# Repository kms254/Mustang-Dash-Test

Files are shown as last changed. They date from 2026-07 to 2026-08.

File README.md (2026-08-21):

# Mustang-Dash-Test

Firmware **and carrier hardware** for a **Riverdi EVE4 instrument cluster** —
a 7" centre panel with two 5" side panels, each on its **own dedicated SPI
peripheral**, driven by an **STM32H755**.

| Item | Value |
|---|---|
| Displays  | Centre: Riverdi **SM-RVT70HSBNWN00** — 7.0" **1024 × 600** IPS, **BT817** (EVE4), no touch. Sides: RVT50H. |
| MCU | **STM32H755ZIT6** on the in-repo carrier (**Board3**, ordered from JLCPCB 2026-08). Bench mules: NUCLEO-H755ZI-Q (same die) and NUCLEO-F767ZI (proven three-panel rig). |
| Library | [RudolphRiedel/FT800-FT813](https://github.com/RudolphRiedel/FT800-FT813) (EmbeddedVideoEngine) v5.0.10, branch `5.x`, vendored in [`libraries/`](libraries/) with multi-panel / per-panel-SPI-bus support |
| Profile | `EVE_RVT70H` (1024×600, BT817, `EVE_GEN 4`) |

## Repo layout

| Path | What it is |
|---|---|
| [`MustangDash/`](MustangDash/) | The firmware sketch plus pure, host-tested headers (sim, serial, odometer, button, telltales) |
| [`kicad/board3/`](kicad/board3/) | The carrier board — schematic, routed PCB, footprint libraries. DRC/ERC 0 at `--severity-all`; reviewed pre-order by seven independent lenses |
| [`fab/`](fab/) | The JLCPCB package: gerbers/BOM/CPL plus [`ORDER.md`](fab/ORDER.md), the order-form contract every figure of which re-derives from the tree |
| [`tools/`](tools/) | The KiCad pipeline: `kicad_lcsc.py` (sourcing), `kicad_fab.py` (fab package), `kicad_verify.py` (the DRC gate), silk/routing/verification tooling |
| [`docs/hardware/`](docs/hardware/) | [Bring-up card](docs/hardware/board3-bringup-card.md) (print before the boards arrive) and the [as-built H755 pin map](docs/hardware/board3-h755-pin-map.md) |
| [`docs/solutions/`](docs/solutions/) + [`CONCEPTS.md`](CONCEPTS.md) | Documented learnings (YAML frontmatter: `module`, `tags`, `problem_type`) and the shared domain vocabulary |

## Wiring

Shared ground, panel logic on **3.3 V**, backlight on an external **5.0 V**
supply (a dev board's USB rail cannot feed three backlights).

**Each panel has its own SPI peripheral** — on Board3: centre SPI1
(PA5/6/7, CS PD8, PD PD11), left SPI2 (PB13/14/15, CS PD9, PD PD12), right
SPI4 (PE2/5/6, CS PE3, PD PD13) — plus per-panel CS and PD/RST. Panel timings
live in [`MustangDash/dash_panels.h`](MustangDash/dash_panels.h); per-target
pins in the sketch's board blocks and the
[pin map](docs/hardware/board3-h755-pin-map.md). `INT` is not wired — the
firmware polls.

**SPI is mode 0, MSB-first, ≤ 11 MHz during every panel's `EVE_init()`**, then
each bus rises once to the run clock. **Board3 runs 25 MHz on all three
panels**, walked and soaked 2026-08-21; the F767 bench ran 13.5 (where 27 MHz
hard-wedges the firmware rather than degrading gracefully). Two numbers, two
clock trees, both correct — because clock numbers come from failure, not
derivation, and **do not transfer across copper**: re-walk on each new board,
per the bring-up card. And the constant is only a *request* — the peripheral
rounds it down to a reachable rung, so ask the firmware what it actually got
(`diag` on the serial console prints the attained rate per panel) rather than
trusting the source.

## What the firmware does

A 2000 ms animated boot splash (ASTC assets embedded in the MCU image and
staged to RAM_G with per-asset readback checks) crossfades into the dash, which
renders TRACK and STREET screens procedurally at ~60 fps with custom EVE bitmap
fonts.

Data flows simulator → `DashState` channels → renderers; CAN decoders will fill
the same channels later. The serial protocol (115200, USB-CDC on Board3;
`ok`/`err` acks) overrides any channel; the odometer persists across power
cycles. A short press on the gesture button (BTN1 on Board3, the USER button on
the mules) toggles TRACK/STREET; a ≥1 s hold resets the trip. Telltales drive
eight LEDs through two AW9523B expanders on I2C2; the boot banner self-checks
the panels, the expanders, and the QSPI NOR's JEDEC ID.

## Build

See [`BUILD.md`](BUILD.md) for the environments and the flash budget.

```bash
./scripts/compile.sh                    # PlatformIO, default env nucleo_f767
./scripts/compile.sh board3             # the carrier (25 MHz crystal clock tree)
./scripts/compile.sh board3_mule        # same firmware on the NUCLEO-H755ZI-Q
wsl -- bash -lc "./tests/run-tests.sh"  # host invariant tests, no board needed
```

**H755 targets, one-time first connect:** the factory chip boots both cores and
the CM4 has no image — run `STM32_Programmer_CLI -c port=SWD -ob BCM4=0` once.
The mule env is SMPS-aware (flashing plain `board3` onto the -Q Nucleo hangs at
the VOSRDY wait); details and the session matrix are on the
[bring-up card](docs/hardware/board3-bringup-card.md).

The host tests pin what must not silently change: the `EVE_RVT70H` profile, the
control pins, the backlight sweep, the splash timeline, the dash
math/sim/serial/odometer logic, the font format, the flash-pack layout, the
button gestures and the telltale calibration.

## Configuration (already applied in the vendored library)

- **Profile** — `EVE_config.h` defines `EVE_RVT70H` near the top of the file,
  so it applies without `-D` flags. Note it is **not** `EVE_RiTFT70`, which is
  the 800×480 BT81x panel — picking that one initialises fine and renders
  garbage. See [the profile-selection
  learning](docs/solutions/best-practices/riverdi-rvt70h-vs-ritft70-eve-display-profile-selection.md).
- **Multi-panel** — the STM32 target header carries `EVE_MULTI_PANEL` and a
  per-panel descriptor (`EVE_panel_t`) with an optional per-panel `SPIClass*`
  bus; the sketch selects the active panel at runtime.
- An Arduino `library.properties` was added so the `src/` layout is picked up
  (upstream ships only a PlatformIO `library.json`).

## Troubleshooting

| Symptom | Likely cause |
|---|---|
| Board looks completely dead | Hold **BOOT** + tap **RESET** → a DFU device on USB proves MCU, power and the USB path with zero tools. Then walk the [bring-up card](docs/hardware/board3-bringup-card.md); on this bench a "dead board" has historically been a cable or connector, not silicon. |
| `EVE_init() did NOT return E_OK` | EVE never came out of reset — check PD/RST, the 3.3 V logic supply, and CS. |
| Init OK but `REG_ID = 0x00`/`0xFF` (not `0x7C`) | SPI link — MISO/MOSI swapped, wrong CS, or the clock too fast. `0x00` and `0xFF` distinguish a floating line from a stuck one. |
| Init OK and `REG_ID = 0x7C` but the panel stays dark | Backlight power or `REG_PWM_DUTY`. The panel is alive but unlit — it renders fine with no 5 V on BLVDD, just invisibly. |
| Init OK, backlight lit, image garbled or wrong geometry | Wrong display profile in `EVE_config.h`. |

More hard-won detail — FFC orientation, identifying the backlight end by
continuity, why instruments that answer confidently deserve suspicion — is in
[`docs/solutions/`](docs/solutions/), organised by category with searchable
frontmatter.

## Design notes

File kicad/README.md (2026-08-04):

# kicad/

The project's board designs.

Today that is **Board3**. It arrived here as an import from EasyEDA Pro for the
tooling evaluation in
[docs/plans/2026-07-27-001-chore-kicad-evaluation-plan.md](../docs/plans/2026-07-27-001-chore-kicad-evaluation-plan.md),
but **that evaluation is settled**: as of 2026-07-31 Kevin has moved off EasyEDA
entirely, so this directory is the design, not a copy of one.

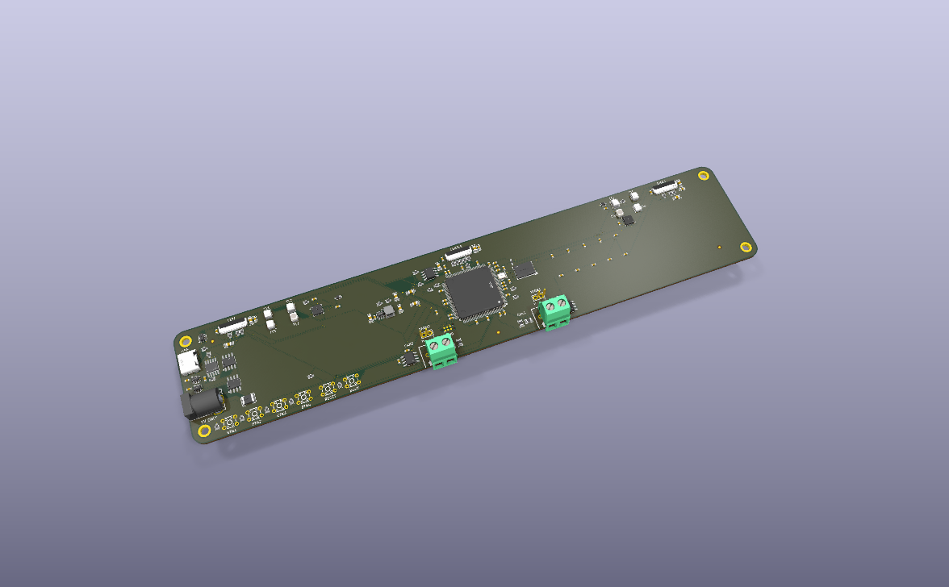
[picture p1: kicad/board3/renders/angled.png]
Board3, angled


| Top | Bottom |
| --- | --- |
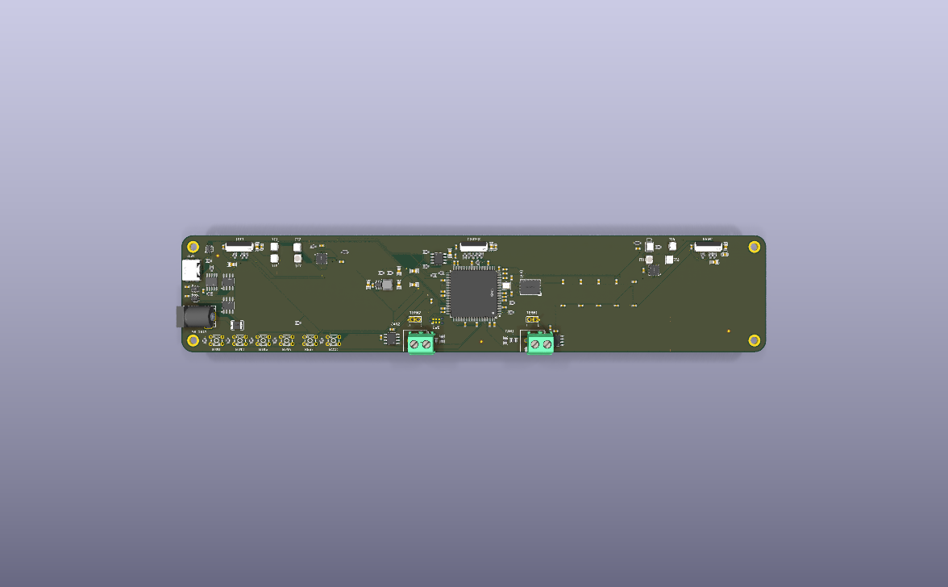
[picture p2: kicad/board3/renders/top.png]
Top
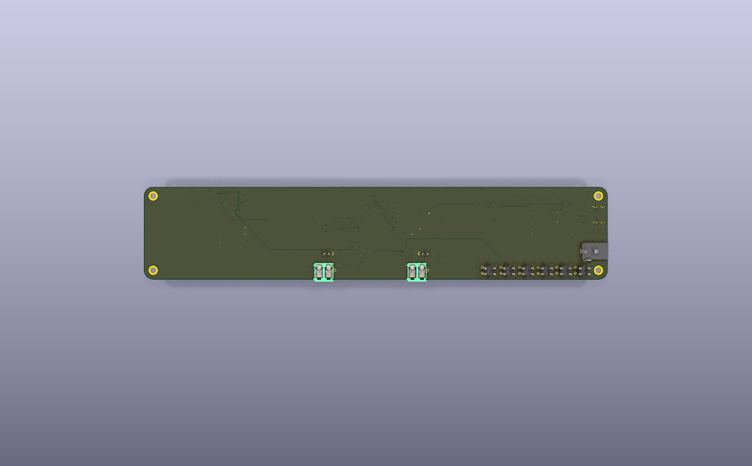
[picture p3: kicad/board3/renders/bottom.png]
Bottom
|  |  |

These are generated, not drawn — `.kicad_pcb` is the truth. See
[Renders](#renders) for how they stay current.

Three rules govern everything in this directory:

- **This is the source of truth.** ~~EasyEDA stays authoritative; conversion is
  one-way.~~ Superseded 2026-07-31 — EasyEDA is no longer maintained, so there is
  no upstream to defer to and nothing to reconcile against. Edit the schematic and
  board here directly. The `EasyEDA/` directory stays in the repo as history; do
  not mirror changes into it, and do not treat a KiCad-only change as partial.
  The one-way rule still describes the *import*: nothing here was ever converted
  back, and `docs/solutions/integration-issues/easyeda-pro-to-kicad-migration-silent-data-loss.md`
  records six silent losses that make a re-import a bad idea now that this copy
  carries all the routing.
- **The design files are tracked on purpose.** `.kicad_pcb` and `.kicad_sch` are
  S-expression text, and `git diff` is the evaluation's verification mechanism for
  agent-driven writes. Keeping the board out of the repo would forfeit that.
- **The first commit of a converted board is the baseline.** It must contain
  converter output and nothing else. Every later measurement diffs against it.

Toolchain resolution for anything operating on these files is
[tools/kicad_env.py](../tools/kicad_env.py) — do not hardcode `kicad-cli` paths.

**Never pick a board by globbing for the newest `.kicad_pcb`.** Routing and
cascade experiments leave variant boards (`…-c0.kicad_pcb`, `…-it.kicad_pcb`)
sitting beside the real one, and being scratch they are *always* newer — so
newest-wins reliably selects the wrong file. This bit twice on 2026-07-28:
`kicad_render.py` rendered a leftover temp board, and `kicad_live_view.py` spent
a session watching one that was then deleted underneath it. Filter to files git
tracks (`git ls-files -- '*.kicad_pcb'`) and take the newest of those; untracked
neighbours are working scratch, not the design.

## Renders

`board3/renders/*.png` are committed so the board is visible in a diff, a PR, or
a browser without installing KiCad. They are **build output, not source** — the
board is the truth and these are regenerated from it:

```sh
python tools/kicad_render.py            # refresh all three views
python tools/kicad_render.py --check    # exit 2 if older than the board
```

A tracked pre-commit hook keeps them honest. Install it once per clone:

```sh
git config core.hooksPath .githooks
```

The hook is convenience, not enforcement — it is opt-in per clone, so it is
silently absent on a fresh clone or under `--no-verify`. CI is what actually
holds the line: `.github/workflows/kicad-renders.yml` fails any PR that changes
the board without refreshing the renders, and `kicad-parts.yml` runs the part
audit on every PR.

The hook only fires when a `.kicad_pcb` is actually staged — each refresh is
~360 KB of binary that lands in history permanently, so regenerating on every
commit would bloat the repo to show a picture that did not change. If rendering
fails (no KiCad on this machine) it warns and lets the commit through: refusing
to commit firmware because a PCB picture could not be drawn is the wrong trade.

Renders are 1200×750 on purpose. Enough to read placement and routing at a
glance; open the board if you need detail.

## Watching the board change live

To see the board *while* an agent edits it, without pcbnew in the way:

```sh
python tools/kicad_live_view.py                     # newest board under kicad/
python tools/kicad_live_view.py path/to/x.kicad_pcb --port 8010
```

It serves a local page that renders the file with
[KiCanvas](https://kicanvas.org/) and reloads on every save, keeping your zoom.
Pan/zoom, layer toggles and net highlight all work.

**3D is on the second tab**, built by `kicad-cli` in the background — but only
while that tab is open, since a build costs real CPU and nobody would see it.
Two modes, because the cost difference is an order of magnitude:

| mode | what it is | board3 |
|---|---|---|
| **snapshot** (default) | `pcb render` PNG, six camera presets | **~3 s**, 0.1 MB |
| **model** | `export glb`, orbit in the browser | **~29 s**, 13.5 MB |
| **model + copper** | as above with tracks/zones/silk as geometry | **~47 s**, 31 MB |

So 3D follows an agent at roughly one frame per edit, not live — the header
always says how far behind it is (`3D showing rev 4, board at rev 7`) rather
than quietly showing you a stale board. Snapshot is the default because 3 s is
fast enough to actually watch work happen; switch to model when you want to
orbit something. There is no cheap middle: a components-free GLB builds in 1.2 s
but is a bare board, which is no use for checking a footprint.

Model mode opens **top-down on the top face** (model-viewer's own default is
nearly edge-on, which on a board this thin is a sliver). That framing is applied
once, so an orbit you set up afterwards survives every rebuild.

3D is built from the *same validated bytes* the 2D tab is showing, written to a
temp copy — so the two tabs can never disagree and a build can never catch a
half-written save. That relocation would normally drop every 3D model, since
footprints reference `${KIPRJMOD}/EASYEDA_MODELS/…` and KIPRJMOD follows the
file; the builder passes `-D KIPRJMOD=<board dir>` to put them back. Worth
knowing because the failure is silent — without it you get a bare green board
and no error.

**Why not just open pcbnew.** The editor takes a `.lck` on the board and holds
its own in-memory copy, so an agent's write and your session become two
authorities on one file — whoever saves last wins, silently. This viewer only
ever reads. That is also why it is a *viewer*: it is safe to leave open all day
precisely because it cannot write, so it does not replace the GUI for editing,
and KTD12 still holds (Update PCB from Schematic is Kevin, in the GUI, after a
restart).

Two things worth knowing:

- **A save is not atomic from the reader's side.** Every re-read is validated
  (starts with `(kicad_pcb`, parens balance outside strings) before it is
  published, so a file caught mid-write never reaches the screen — the viewer
  holds the last good revision and turns its status dot amber. Verified by
  truncating a board under a running viewer: revision held, bytes served
  unchanged.
- **KiCanvas predates KiCad 10 and skips tokens it does not know**, warning to
  the browser console. On board3 that is 344 warnings and zero errors, all of
  them non-geometry policy fields (`tenting`, `covering`, `plugging`, `capping`,
  `filling`, `duplicate_pad_numbers_are_jumpers`, dimension `units`). Copper,
  zones, footprints and silk all render. It is a preview, not an authority —
  DRC and the fab package remain the check that matters.

The bundle is cached to `tools/vendor/kicanvas.js` on first run (gitignored);
`--refresh-viewer` re-fetches it.

## Adding a part

**Every part placed on a board here must be an LCSC part, carrying supplier
metadata and a 3D model.** Not a convention — a build dependency. `kicad_fab.py`
builds the JLCPCB BOM by reading the schematic's supplier fields, so a part added
without them does not produce a warning, it produces a BOM that is quietly
missing a component.

Add parts with [tools/kicad_lcsc.py](../tools/kicad_lcsc.py), never by dragging a
generic symbol out of the stock KiCad libraries:

```sh
python tools/kicad_lcsc.py add C116592   # symbol + footprint + STEP/WRL + metadata
python tools/kicad_lcsc.py check         # audit; exits non-zero on any gap
python tools/kicad_lcsc.py models        # fetch any 3D model the board references but lacks
```

`add` drives the JLCImport plugin and then rewrites the imported symbol's fields
into Board3's vocabulary. That rewrite is the whole point: JLCImport writes the
LCSC code to a property named `LCSC`, and this project reads it from
`Supplier Part`. Import without remapping and the part looks sourced in the
schematic editor while being invisible to the BOM.

`LCSC Part Name` is **not** the part number despite its name — it holds
descriptive text. The C-number goes in `Supplier Part`.

Run `check` before generating fab output. It audits the **board**, not the
library — the board is what gets fabricated, and each placed footprint carries
its own copy of the model reference, so an instance placed before a library fix
can be wrong while the library looks perfect. It fails on any of:

- a placed part **not mapped to LCSC** (missing `Supplier Part`, or absent from
  the schematic entirely)
- a placed footprint with **no 3D model reference at all**
- a model reference whose **file is missing from disk**
- a schematic symbol with no LCSC code, placed or not

Footprints that legitimately have no body — fiducials, free pads, mounting
holes, test points — are exempt via the `BODILESS` table in the tool, and every
exemption is **printed on every run**. An exemption you cannot see is one you
cannot audit, and that table is the only path by which a real part could pass
unnoticed. Board3 currently exempts 8: three fiducials, four free pads (MP1-MP4) and H2, the Tag-Connect land pattern -- a cable presses pogo pins onto bare copper, so nothing is fitted and there is no part to source.

3D models live in `board3/EASYEDA_MODELS/` and **are tracked** (~53 MB, ~9.5 MB
in history). They are regenerable from the schematic's LCSC codes via
`kicad_lcsc.py models`, but they are committed anyway so a fresh clone renders
and exports 3D offline, and so the geometry stays pinned to this board revision
rather than to whatever EasyEDA serves later.

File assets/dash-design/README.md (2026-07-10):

# Handoff: EVE Triple Dash — Mustang Race/Street Digital Cluster

## Overview
A three-screen digital instrument cluster for a track-built 1999 Ford Mustang (Gen 4 Coyote Aluminator swap, T56 Magnum close-ratio, 3.73 rear, 26″ tires, WR Blue Mica).

Target hardware:
- **MCU**: Teensy (4.x assumed) driving **Riverdi EVE displays** (Bridgetek EVE graphics controllers — BT81x family)
- **Displays**: one 7″ center (800×480) + two 5″ side panels (800×480), mounted in a single CNC bezel with physical turn-signal LEDs at the outer bosses
- **Data**: Ford Gen 4 Coyote control pack CAN, 2× ECUMasters PMU16 (custom CAN), RaceCapture (GPS speed, lap timing, IMU)
- **Mode switching**: TRACK vs STREET view is selected by a **CAN input** into the Teensy (physical switch → PMU → CAN broadcast, or direct digital input — TBD)

### Build phases
1. **Phase 1**: Center 7″ display only (both TRACK and STREET modes, alarm takeover, telltale dots, odometer)
2. **Phase 2**: Add left 5″ (engine) and right 5″ (timing/road) displays

## About the Design Files
The files in this bundle are **design references created in HTML** — an interactive prototype showing the intended look and behavior. They are NOT production code. The task is to **recreate these designs as EVE display lists / widgets on the Teensy** (e.g. via the Bridgetek EVE library, GD2/GDX, or a custom display-list generator). The HTML file runs in any browser and includes a live simulator plus a Tweaks panel (mode, units, accent, alarm test, manual RPM/MPH override) — use it as the visual source of truth.

## Fidelity
**High-fidelity.** Colors, typography, spacing, gauge geometry, and thresholds are final and should be matched as closely as the EVE rendering pipeline allows. Fonts will need conversion to EVE bitmap/custom fonts (see Typography).

## Screen Resolutions & Canvas
Each panel renders at **800×480** (native EVE resolution). The HTML mock draws the 7″ at 620×400 CSS px and the 5″ at 420×320 — **scale all dimensions in this document by ×1.29 (7″) or ×1.90 (5″ width) to native**, or better, treat all layout as proportional percentages of the panel.

## Design Tokens

### Colors
| Token | Hex | Use |
|---|---|---|
| Screen background | radial `#0e141b → #05070a` (7″), linear `#0b0f14 → #06080b` (5″) | panel fill (a flat `#080b0f` is acceptable on EVE) |
| Hairline / divider | `#151b22`, `#11171e`, `#131a22` | grid lattices, separators |
| Label gray | `#5f6b76` | small caps labels |
| Faint label gray | `#454f59`, `#49545f` | footer labels, compressed tick labels |
| Secondary value | `#c3ccd4`, `#8b97a3` | last-lap, odometer |
| Primary value white | `#f4f7f9` / `#e8edf2` | all live numerals |
| **Accent (gold)** | `#e8a33c` | RPM bar/arc fill, gauge arcs, P3 position |
| Green (ok/throttle) | `#3ddf77` | throttle bar, PMU on, delta negative |
| Amber (warn) | `#f2b13e` | warning thresholds, low fuel |
| Red (alert) | `#ff3b3b` (fills) / `#ff5252` (text) | redline, alarms, brake bar |
| Best lap purple | `#b79aff` | BEST lap time |
| Tach red-zone track | `#5c1616` | static red-zone arc segment |

### Typography
- **Numerals**: *Saira Condensed* (weights 600–800), always tabular. Convert to EVE custom font at 3–4 sizes (small ~20px, mid ~34px, large ~64px, hero ~150px at native scale).
- **Labels**: *Chakra Petch* (500–600), small caps style with wide letter-spacing (0.16em–0.44em).
- Google Fonts sources; both are OFL-licensed and safe to convert/embed.

## Screens / Views

### CENTER 7″ — TRACK mode
- **Shift lights** (top, centered): 15 round LEDs, 18px dia (mock scale), 9px gap. Linear 0→8000 RPM (each LED = 533 RPM). Colors: LEDs 1–10 green `#3ddf77`, 11–13 amber `#f2b13e`, 14–15 red `#ff3b3b`. Above **7600 RPM all 15 flash red** at ~8 Hz. Off state: dark radial `#1a222b→#0d1218`. Hairline divider below.
- **GPS SPEED hero** (left ~2/3): label "GPS SPEED" (11px, letter-spacing .44em) → speed numeral (148px, weight 700) → "MPH" (14px, .34em).
- **RPM linear bar** under speed: label row "RPM" + live value (21px; white <7100, amber `#f2b13e` 7100–7600, red >7600). Bar: 8px tall pill, dark track `#0c1117`, fill = gold gradient (red >7600), **redline marker at 96%** (red 2px line, 50% opacity). Scale marks 0/2/4/6/8 beneath (9px; the "8" in muted red `#864b4b`).
- **Right column** (186px, hairline left border): LAP TIME (34px), DELTA value (24px, green negative / red positive) + **delta bar**: center-zero pill, fill extends left (ahead, green) or right (behind, red) up to ±50% for ±1.0s.
- Data: GPS speed & lap timing from RaceCapture; RPM from Coyote CAN.

### CENTER 7″ — STREET mode
- **Dual sweep gauges**, asymmetric: SPEED dial 340×305 (dominant), TACH dial 220×197. Both use the same gauge geometry (below).
- **Speedometer**: 0–200 MPH, **non-linear**: 0–140 occupies 82.35% of the 240° sweep (major ticks every 20 = 28.24° apart); 140–200 compressed (ticks every 20 = 14.12°). Tick labels 0–140 full size; 160/180/200 smaller + dimmer (`#49545f`). Gold arc fill from 0 to current speed; white needle (r=62 of 88 viewBox units); hub readout: speed (60px) + "MPH".
- **Tachometer**: 0–8000, linear, labels 0–8 (×1000); "8" in muted red. Static red-zone arc segment **7600→8000** (`#5c1616`). Arc fill gold, turns red >7600; hub: RPM value (38px, colored by state) + "RPM".
- **Warning telltale dots** (centered row under gauges, 26px gaps): FUEL (amber, <2.5 gal) · OIL (red, oil press <29 psi OR oil temp >248°F) · ECT (red, >217°F) · VOLTS (red, <12.0V). Dead-front: off = near-invisible dark dot `#161d25` + label `#39434d`; on = filled + glow + label colored. 9px dot + 9px label.
- **Odometer** (bottom center): "ODOMETER" (10px, .24em, `#454f59`) + value (20px, `#8b97a3`) + "MI".

### Gauge geometry (shared by all sweep gauges)
- SVG viewBox coordinates: center (120, 80), arc radius 88, stroke 9–10, round caps.
- Sweep: **240°**, from 210° (min, lower-left) clockwise to −30° (max, lower-right). Angle for fraction *f*: `a = 210° − f·240°`; point = `(120 + r·cos a, 80 − r·sin a)`.
- Ticks: r 80→88. Tick labels at r 66. Needle: from hub to r 62, white 3px, round cap, subtle glow. Hub: 7px radius disc `#0c1117` with `#39434d` ring.
- Value arc: same path as background arc, drawn with stroke-dash technique (arc length = 2π·88·(240/360) ≈ 368.6 units). On EVE, render as an arc/polyline sweep.
- Background arc track: `#141b23`.

### CENTER 7″ — ALARM TAKEOVER (both modes)
Full-screen overlay, **flashes** between bright red radial (`#d92020 → #700c0c`) and near-black red `#260606` at ~2.8 Hz. Content centered: "WARNING" (14px, .6em tracking, `#ffd9d9`) → alarm title (48px Chakra Petch 700) → live value (116px Saira 800) → limit line (15px, .28em, `#ffd9d9`).
| Alarm | Trigger | Limit text |
|---|---|---|
| OIL PRESSURE | < 29 psi (2.0 bar) | MINIMUM 29 PSI |
| OIL TEMP | > 248°F (120°C) | MAXIMUM 248°F |
| COOLANT TEMP | > 217°F (103°C) | MAXIMUM 217°F |
Priority: oil pressure > oil temp > coolant. Alarm should override BOTH modes and persist while condition holds.

### LEFT 5″ — ENGINE (Phase 2)
Header: "ENGINE" / "COYOTE CAN · 5″".
- **TRACK**: 4×2 hairline-divided grid (1px `#151b22` lattice on `#080b0f` cells). Top row (pit-now): OIL P (psi) · ECT (°F) · FUEL P (psi) · AFR L. Bottom row (trend): OIL T (°F) · IAT (°F) · VOLTS · AFR R. Cell: label (10px `#5f6b76`) top-left, value (31px Saira 600) + unit (10px) bottom. Warn/alert colors per thresholds below. Below grid: "PMU16 ×2 · OUTPUTS" strip — PUMP / FAN 1 / FAN 2 chips (green text+border when on with amps, gray "OFF", red FAULT state fills chip) + total amps at right.
- **STREET**: 2×2 mini sweep gauges (132×118): OIL P (0–100 psi) · ECT (100–260°F) · OIL T (100–300°F) · VOLTS (8–16V). Gold arc, red when out of range; hub value + label.

### RIGHT 5″ — TIMING / ROAD (Phase 2)
Header: "TIMING" (track) / "ROAD" (street), "RACECAPTURE · 5″".
- **TRACK**: LAP number (42px) + POS (gold "P3" 30px) row; LAST / BEST (purple) / PRED lap times row (20px, hairline-framed); THROTTLE (green) and BRAKE (red) percent bars (7px pills); bottom hairline grid: FUEL gal · LAPS remaining · AMB °F; odometer footer row.
- **STREET**: FUEL sweep gauge (190×170, 0–16 gal, "E"/"F" end labels, gold arc, amber <2.5 gal) with hub gal readout; bottom row: TRIP A · RANGE · AMB · TIME (17px values). No odometer here (it lives on center screen in street).

## Interactions & Behavior
- **Mode switch**: CAN input selects TRACK/STREET. All three screens switch together. Debounce and animate-free (instant swap is fine).
- **Shift-light flash**: >7600 RPM, all LEDs toggle red at ~8 Hz. RPM bar/arc/readout turn red at the same threshold; amber pre-warning at 7100.
- **Alarm takeover**: see above; flash ~2.8 Hz. Must preempt everything on the center screen.
- **Delta bar**: green fills left of center when ahead of best, red fills right when behind; ±1.0 s full scale.
- **Needles/arcs**: update at telemetry rate (aim ≥ 30 fps on EVE; the mock uses ~16 Hz ticks with light smoothing).
- **Odometer/trip**: integrate GPS or wheel speed; persist odometer in EEPROM/FRAM.

## Vehicle Constants (for scaling & derived values)
- Redline **8000 RPM**, shift light **7600 RPM**
- T56 Magnum close-ratio: 2.66 / 1.78 / 1.30 / 1.00 / 0.80 / 0.63; final drive **3.73**; tire dia **26″**
- MPH = (RPM × 26) / (ratio × 3.73 × 336) → gear tops @8000: 63 / 93 / 128 / 166 / 208 / 264
- Speedo scale 0–200 MPH (non-linear knee at 140)
- Fuel tank modeled at 16 gal usable (E/F gauge scale); range estimate = gal × 16 mi/gal (street), laps-remaining = usable ÷ per-lap burn (track)

## Warning thresholds (all panels)
| Channel | Amber | Red |
|---|---|---|
| Oil pressure | — | < 29 psi |
| ECT | > 210°F | > 217°F |
| Oil temp | > 235°F | > 248°F |
| Fuel pressure | — | < 43 psi |
| Volts | — | < 12.0 |
| IAT | > 131°F | — |
| AFR (per bank) | > 13.8 (lean under load) | — |
| Fuel level | < 2.5 gal | — |

## State Management (firmware sketch)
- `mode` (TRACK/STREET) ← CAN input
- Live channels: rpm, gpsSpeed, ect, oilT, oilP, fuelP, iat, batt, afrL, afrR, fuelLevel, throttle, brake, lap/lastLap/bestLap/predLap/position (RaceCapture), pmu output states+amps
- Derived: alarmActive(+which), shiftLightCount/flash, deltaSeconds, rangeMi, lapsRemaining, odometer/trip (persisted)
- Missing-data behavior: show `--` and never render a stale alarm.

## Assets
- No raster assets. All graphics are vector/procedural (arcs, pills, LEDs). Fonts: Saira Condensed + Chakra Petch (Google Fonts, OFL) — convert to EVE fonts.
- Physical bezel provides turn-signal LEDs (and future telltale LEDs: high beam, brake, CEL, charge, low fuel) — not rendered on screens.

## Files
- `Eve Race Dash.dc.html` — the interactive design reference (open in a browser; requires `support.js` alongside). Tweaks panel: mode, units, accent, alarm test, manual RPM/MPH.
- `support.js` — runtime for the HTML prototype (not part of the design).
- `renderings/01-track-mode.png`, `renderings/02-street-mode.png` — final renders, gold accent.

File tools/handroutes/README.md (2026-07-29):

# Hand-route log

Every copper edit applied to Board3 by `tools/kicad_handroute.py`, in the order
it went on. Each file carries a `$comment` explaining the intent and the
constraints that shaped it.

This is a **log, not a replay script**. Some steps were superseded by later ones,
and one whole unit was walked back — re-applying these in order against the
imported board will not reproduce the current board. Read them for the reasoning;
trust `git log` and the board itself for the state.

| Order | File | Unit | Status |
|---|---|---|---|
| 1 | `u6-flagged-nets.json` | U6 | Applied. The CAN and USB steps still stand; the crystal and QSPI steps were later reverted by step 6. |
| 2 | `u7-can1-term.json` | U6 follow-up | Applied. CAN1_TERM's +5V plane slot 9.70 → 1.51 mm. |
| 3 | `u7-thermal-fiducials.json` | U7 | Applied. U4's 5 thermal vias and the 3 fiducials still stand; U2's 9 were re-placed by step 7. |
| 4 | `u7-depad-r28.json` | U7 follow-up | Applied. R28.2's via moved out of its pad. |
| 5 | `u7-btn1-annular.json` | U7 follow-up | Applied. U1.93's via to 0.5/0.2 for a 0.15 mm ring. |
| 6 | `u7-walkback-crystal-qspi.json` | U7 follow-up | Applied. Reverts U6's crystal move and QSPI reroute to the imported geometry — see the plan's U6 amendment for why. |
| 7 | `u7-thermal-u2-replaced.json` | U7 follow-up | Applied. U2's 9 thermal vias re-placed against the restored routing. |

A step that was tried and reverted is not kept here — `u7-depad-qspi.json`
(moving the QSPI escape vias out of U2's pads by hand) produced 8 shorts and 1
clearance violation and was rolled back in favour of step 6. Its failure is
recorded in the plan, which is the right place for it.

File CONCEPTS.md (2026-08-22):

# Concepts

Shared domain vocabulary for this project — entities, named processes, and status concepts with project-specific meaning. Seeded with core domain vocabulary, then accretes as ce-compound and ce-compound-refresh process learnings; direct edits are fine. Glossary only, not a spec or catch-all.

## Display

### EVE
The Bridgetek "Embedded Video Engine" family of graphics controllers that drives the dash panel over SPI. Generations are numbered (EVE2 through EVE4) and differ in registers and features; the driver library gates its code on the selected generation, so the generation is part of the display's identity, not an implementation detail.

EVE renders each frame from a Display List rather than exposing a framebuffer — the microcontroller never pushes pixels, it describes the scene. Commands reach the chip through a bounded command FIFO, so oversized transfers are a correctness concern, not just a performance one.

### RiBUS
Riverdi's standard host connector for its intelligent displays: one small ZIF ribbon carrying the module's logic power, the SPI/QSPI link, the control signals, and the backlight supply. The module-power pair sits at one end and the backlight pair at the other, with the backlight ground internally tied to logic ground — which makes seating, orientation, and end-identification faults *power* faults, not just signal faults. The internal ground tie doubles as a safe continuity test for identifying the backlight end before applying backlight voltage.

### Display Profile
The compile-time selection that binds the driver library to one specific panel: resolution, sync timings, pixel clock, backlight behavior, and EVE generation all come from the chosen profile, and exactly one profile is enabled per build. Choosing a profile is a claim about the physical panel attached — a wrong profile still initializes and passes chip-identity checks but renders garbage, which is why profiles are verified against the panel's model number and controller rather than by name.

### Display List
The bounded sequence of drawing commands EVE executes to render a frame. The microcontroller builds a new list, then swaps it in atomically; the previous list keeps rendering until the swap, so partial updates are never visible. A list is size-limited, so complex scenes are composed by appending previously built fragments rather than growing a single list without bound.

### Bitmap Handle
One of the EVE chip's small set of per-frame bitmap state slots — each holds one bitmap's source, layout, size, and format, and drawing reads whatever the currently selected handle carries. Fonts claim handles for the whole frame once registered, so anything that configures "the current handle" must first select a scratch handle no font uses and restore the default afterwards — otherwise it silently retargets a font, and that font's glyphs render as garbage while every health signal stays clean.

### Font Instance
One typeface rendered at one pixel size into a fixed-cell glyph sheet, claiming its own Bitmap Handle and uploaded to RAM_G at boot. Each instance carries its own character set, and that set is stored as a contiguous run of character codes rather than a sparse map — so an instance's memory cost is set by the span between its lowest and highest character, not by how many characters it actually uses.

Every cell within an instance is sized to fit its largest glyph, so introducing one wide character enlarges every other cell as well, including ones already present. Both properties make "add one character" a change worth costing before making rather than after.

### RAM_G
EVE's fixed-size on-chip graphics memory — the home of any bitmap the chip decodes or the firmware uploads at runtime, and the fastest asset storage the renderer has. Its capacity is a hard budget that shapes asset decisions: storage formats, downscaling with render-time upscaling, and which assets are resident at once. Rendering straight from the panel's own flash once served as an escape valve for small assets, but its per-frame ceiling (see Flash Render Streaming) meant large assets needed RAM_G staging anyway, and the flash path has been retired.

How much of the budget is spent swings widely with encoding choices, because a decision made for image quality is paid for in graphics memory directly — the same layer can differ by two orders of magnitude between a block-compressed and an uncompressed form. Headroom is therefore a property of the current configuration and not of the design. Take the figure from the code that allocates it, never from a document; this entry itself once asserted the budget sat within a few tens of kilobytes of the ceiling, which was true of one configuration and badly wrong of the next. A stale budget figure reads as headroom that does not exist, which is the one error this concept exists to prevent.

*Historical caveat, no longer binding here:* the chip's on-chip PNG decoder borrows the top of RAM_G as scratch during image loads, so anything packed near the top had to leave it headroom. That shaped this project's original big-first packing order. Nothing in the firmware decodes a PNG any more, so the constraint is a property of the chip rather than a live rule.

### Asset Pack
The versioned bundle of static assets embedded in the firmware image and staged directly into RAM_G at boot. Its members are not one format: block-compressed where the asset carries detail and is drawn at native size, and uncompressed where it is smooth and magnified, because a block codec quantises a gradient per block and every boundary becomes a visible step once the asset is scaled up. The pack is verified per asset against the embedded source before the renderer may use it — a failed check skips that asset for the session. The pack formerly lived provisioned in the display module's onboard flash; that round trip was retired because the pack ships in firmware either way, staging rides the same proven command path as font loading, and boot no longer depends on the module's flash at all. Staging time is a function of the SPI Operating Point.

### Flash Render Streaming
Rendering a bitmap by having the display's graphics engine fetch it from the module's onboard flash every frame, rather than from RAM_G. It was the mechanism that let flash-resident assets cost no graphics memory, and it has a per-frame throughput ceiling: past a size threshold an asset arrives too slowly to complete the frame, and renders with correct content broken by dropped scanlines. The ceiling is why the firmware retired flash-resident rendering in favor of staging everything into RAM_G.

The ceiling is a property of the path, not a fault in a given display module, and reaching the flash controller's full-speed mode does not lift it. The distinguishing symptom is that content is *correct but torn* — genuinely corrupt data instead points at addressing, alignment, or block-ordering faults in the pack. Assets above the threshold must be staged into RAM_G at boot; below it, streaming is free.

### Splash Theme
A complete visual variant of the boot splash — background treatment, accent hardware, and year mark as a matched set. The concept is still worth naming even though only one variant ships: it is what makes "the splash" a set of coordinated assets rather than a picture, and it is the unit a runtime selector would choose between.

Selection is build-time, because the cluster has no input hardware to switch with. That is a constraint on the mechanism, not on the count: retiring the extra variants was a RAM_G and flash decision, and any future runtime selection costs no extra graphics memory — only one variant is ever resident — but requires every selectable variant to be present in program storage, which is precisely the space retiring them reclaimed.

### Dash Mode
The dash's active view: TRACK (shift lights, speed hero, lap timing) or STREET (sweep gauges, indicator dots, odometer). All screens switch together and instantly, with no state loss. The selection is an external input to the firmware — a serial command during bench development, a CAN message in the car — never something the dash decides for itself.

### Alarm Takeover
A full-screen flashing overlay that preempts the active Dash Mode on the center screen while any critical engine condition holds, showing only the highest-priority active alarm with its live value and limit. The side panels are deliberately not preempted — the Engine Screen keeps showing live vitals during the event. It clears itself when the condition clears; a missing data channel never triggers or sustains one.

### Telltale
One of the eight physical indicator lamps in the cluster's two bezel-mounted blocks, addressed by its silk position (TT1…TT8) rather than by what it means. Position is the identity: the colour fitted there and the meaning assigned to it are properties of the board and the legend, not of the firmware condition that may light it.

Most telltales carry body or powertrain signals the dash cannot compute — turn signals, headlights, high beam, parking brake, the malfunction lamp — and stay dark until a CAN producer supplies them. Only a minority are lit by the dash's own Warning Conditions. A telltale may also be forced on for inspection; a force can never suppress a live signal, because the layers compose by union rather than replacement. Distinct from the indicator dots the STREET screen draws, which are rendered graphics and share only the word.

### Warning Condition
A fault or threshold state the firmware computes from Data Channels — low oil pressure, overheat, lean mixture, shift point — independent of whether anything displays it. A Warning Condition is not a Telltale and does not imply one: most conditions render only on screen, and the correspondence between the two is an explicit table rather than a shared ordering. Several conditions deliberately have no lamp, because an Alarm Takeover already announces them more loudly than a lamp could.

### Engine Screen
The left 5" side panel: engine vitals sourced from engine-side CAN (oil pressure/temp, coolant, fuel pressure, AFR, IAT, volts). Renders a dense data grid in TRACK and mini sweep gauges in STREET, and stays live during an Alarm Takeover.

### Timing Screen
The right 5" side panel: TIMING in TRACK mode (lap number, position, last/best/predicted times, throttle and brake bars) and ROAD in STREET mode (fuel gauge, trip, range, ambient, clock). Sourced from RaceCapture-side data once CAN lands.

### CAN Dialect
One CAN source's complete frame vocabulary — its IDs, byte layouts, scaling, and rates — together with the decoder that translates it into dash channels. The car's bus carries three: the Ford control pack's (Ford-defined, not ours to change), the PMU16s' (ECUMaster-configured), and the RaceCapture's (ours to configure). Dialects are peers at the dash's producer seam: each decoder writes channels and validity bits, none knows the others exist, and the simulator is architecturally just another producer beside them. The Ford dialect is authored as a DBC file in the repo; its decoder is the first built.

A dialect claims channels exclusively — no channel is decoded by two dialects — and the claim is freshness-scoped. When a claimed message goes stale, bench builds release the channel back to the simulator; car builds instead latch the claim and Dead-Front the channel, so a dying bus in the car reads as absent data rather than plausible fiction. An operator's override outranks any dialect, and a dialect outranks the simulator.

### Golden Frames
Checked-in CAN test vectors generated from a dialect's DBC by the PC toolchain: known channel values encoded into the exact bytes the wire would carry. The host test decodes them with the real firmware decoder and asserts the values round home. Their job is transcription fidelity — the spec's tables are deliberately hand-copied into several independent transcriptions (the machine-readable spec file the toolchain encodes from, the golden generator's own restatement of the scaling constants, and the firmware decoder; a separate round-trip test carries its own frame packer as one more), so a slip must reproduce identically in every one before it can hide. The vectors' expected values are derived from the spec, never from the decoder under test, and consolidating the transcriptions into one shared source would destroy the property, not clean it up.

### Bench Impostor
A PC-side program that plays a real device's CAN Dialect onto the bench bus at the device's own broadcast rates, fed by the same simulation the dash runs internally — so the firmware under test receives spec-shaped traffic indistinguishable from the car while the car isn't connected. Its output is byte-matched against the dialect's Golden Frames in a dry-run mode before an operator runs it live — a workflow discipline rather than a code-enforced gate — which keeps the impostor and the firmware decoder two independent consumers of one spec rather than a self-consistent loop.

### Dead-Front
Showing a value as absent rather than substituting anything when its source is lost. A gauge reading `--` is trustworthy; a gauge holding a last-known or simulated value is a confident lie — so car builds dead-front channels whose CAN source has gone stale, while bench builds hand them back to the simulator, because on the bench the fiction is the point.

### DLC
The length field of a CAN frame, and a code rather than a byte count: classic frames legally carry codes above eight — all meaning eight data bytes on the wire — while CAN FD reuses those same codes for payloads up to sixty-four bytes. Drivers translate the code format-blind, so receiving software must size its buffers for what the driver actually writes, and only then apply the classic meaning; treating the protocol's logical maximum as the buffer contract is how a legal-but-nonconforming frame becomes stack corruption.

### Laps Left
How many more laps the remaining fuel will actually complete — a range estimate, not a count of laps driven. Deliberately excludes an unusable reserve at the bottom of the tank, because sustained cornering starves the pickup well before the tank is dry, so laps promised out of that last fuel are laps the car will not finish.

It therefore reaches zero while the fuel gauge still shows fuel, and that divergence is the concept working rather than a defect. It is also the one figure permitted to disagree with the simulator's own tank, which runs to empty because it models fuel quantity and not pickup behavior; the per-lap burn *rate* behind the estimate must still match what the car actually consumes. Being one word away from a live lap number on the same screen, it is easy to misread as a lap counter — its label has to carry the distinction.

### SPI Operating Point
The bus clock the dash runs at after every panel has initialized — distinct from the slower init clock the display controller's datasheet mandates during bring-up, which is why chip identity can read healthy while the operating point is still unproven. The raise happens once per bus — a system giving each panel its own independent bus raises each of them separately — and the value is owned by bench evidence from the actual wiring, not the chip's rated ceiling. When the physical link changes — bench loom to Carrier Board — the prior operating point becomes historical evidence, and a Clock Walk re-owns the value on the new wiring.

It is always the rate the hardware **attained**, never the rate the firmware
requested — two quantities wearing the same digits in the same units, separated
by the quantization a Clock Walk has to navigate and by a source clock the
application may never have configured, which can differ between instances of one
peripheral family. A request and an achievement therefore diverge silently and
indefinitely, and a configured constant never qualifies on its own. What owns
the value is the constant *and* the clock tree together: the same firmware on
different silicon attains a different rate with no line changed, so moving die
retires a prior operating point exactly as changing the wiring does.

An operating point is accepted only by a read-integrity soak — repeated register reads with zero anomalies — never by frame rate alone: bus corruption can garble rendering and sag the frame rate while every automatic fault counter stays at zero, because the fault detectors check what the chip reports, not whether the read itself was clean.

### Clock Walk
The stepwise process of raising the SPI Operating Point: one clock step at a time, each step accepted or rejected solely by the read-integrity soak before the next is attempted. The walk's diagnosis rules depend on the link: reads failing while writes stay clean points at round-trip latency — answered by delaying when the return data is sampled — whereas writes failing too means genuine signal degradation and a retreat. A step can also fail past degradation into a total wedge: reads corrupt enough that the command-wait loop never exits, the firmware freezes, and the failure presents as sudden silence rather than glitches — recovery is a debug-probe reflash, not a power cycle. Frame rate is never an acceptance signal at any step, and every accepted step also requires eyes on the panel.

Two properties of the walk are easy to get wrong. The reachable rates are **not
continuous** — dividers are typically powers of two, so the steps are octave
jumps rather than a dial, and a walk can end because the next rung would exceed
the peripheral's rated ceiling rather than because a step failed; enumerate the
attainable set before planning the walk, or the plan will contain rungs that do
not exist. And the readback must be **baselined before the clock moves**:
installed at the existing setting, alone, as its own change. That is what
establishes the rate actually in force, and a walk that introduces the
instrument and the new rate in one step has nothing to compare its first reading
against.

### Frame Drain
The per-frame wait for the display controller to finish executing a display list before its command buffer is reused — the renderer polls the chip's command-FIFO registers over SPI until the coprocessor signals completion. Because that poll is a read, it is the frame loop's most exposed point to a marginal link: a bounded drain that never sees completion times out rather than hanging forever, and a timed-out drain retires the panel (see Retired Panel). A drain timeout therefore indicts the read path — clock, wiring, or the shared ground reference — not the rendering itself.

### Retired Panel
A panel the firmware has marked dead at runtime and now skips, after its Frame Drain timed out — distinct from a panel that merely failed to initialize at boot. A retired panel shows no image and reports its liveness field as absent while the healthy panels keep rendering, so one panel's read-path failure never blocks the others. Retirement is a runtime verdict on the link, not the silicon: the same panel typically returns clean once the read path (grounding, wiring, clock) is sound.

### Carrier Board
The purpose-built PCB that replaces the bench wiring loom as the dash's physical platform: it hosts the microcontroller, gives each panel its own buffered, terminated point-to-point SPI leg with a dedicated RiBUS connector, gates each panel's read-return line by that panel's own chip select, and carries the power regulation for both logic rails. Its existence splits the project's electrical history in two — measurements and operating points established on the loom describe the loom, not the system.

### Mule
A stock development board carrying the same die as a custom board that does not yet exist (or has not yet been risked), used to prove the firmware on real silicon before first hardware contact with the Carrier Board.
*Avoid:* devkit stand-in, bench board (when the die-match is the point)

A mule proves die-level behavior — peripherals, protocols, supply-configuration quirks, option-byte procedures — on known-good hardware, so that first contact with the custom board tests only what the mule cannot reach: the board's own clock source, its copper, and its unique wiring. Findings transfer only where the die is the mechanism; anything owned by the board (an operating point, a supply topology, a connector) must be re-proven on the real hardware, and a mule result cited for a board-owned property is a category error.

### Data Channel
One live value the dash consumes (RPM, oil pressure, lap delta…), carried in a single shared structure with a per-channel validity flag. Producers fill channels — the built-in simulator, and a CAN Dialect's decoder for each channel it claims — and renderers only read them; the source is invisible to rendering. When producers contend, precedence is fixed: an operator's override beats CAN, and CAN beats the simulator. An invalid channel displays `--` and can never assert an alarm, which is what makes "no stale alarms" a structural guarantee rather than a convention.

## Board Design

### Airwire
One unrouted pad-to-pad connection on a PCB — the thin line a layout tool draws between two pads the netlist says belong together and that no copper yet joins. A single net produces as many airwires as it has connections still to make, so airwires and nets count entirely different things and are not interchangeable.

The distinction is load-bearing here because this project has already confused them once: a routing task recorded as "~274 unrouted nets" was in fact ~274 airwires across roughly a hundred nets, 93 of which already carried copper. Scoped against nets the work looked like most of the board; scoped correctly it was a nearly-complete board. Any statement about how much routing remains is ambiguous unless it names which unit it counts.

An airwire count also answers a narrower question than it appears to. It reports whether pads are *joined*, not whether any particular copper is what joins them — so on a net carrying a Copper Pour it cannot evaluate a change to that copper at all: the pour takes over and the count stays at zero. This cuts both ways and the second direction is easy to miss. Remove a dedicated connection and the pour absorbs it, so the count cannot say whether the removed copper was redundant or load-bearing. *Add* something — a via, a track — close enough to crowd a pad, and the pour reaches it through fewer spokes, which is a real change in resistance and current capacity that the count reports as nothing at all. Zero airwires is evidence about connectivity, never about whether copper was doing work.

### Copper Pour
A filled region of copper assigned to a net, poured around existing geometry rather than drawn as a path — the form the ground and supply nets take across most of a board's area. Distinct from a track, which joins two specific points, in that a pour joins everything it touches and reshapes itself on every refill.

Two consequences run through this project. A pour is *derived* geometry, so it is only true after a refill under the real Design Rules, and any measurement spanning an edit must refill first or it describes the previous board. And a pour silently substitutes: because it already touches every pad on its net, removing a dedicated connection to one of those pads does not disconnect it, it demotes it to a thermal-relief attachment — a real change in resistance and current capacity that connectivity checks report as no change at all.

A pour's inverse is a **rule area** (keepout): a region with the same outline semantics that bans something rather than filling it. Barring the pour from a region while still permitting tracks and vias is how a plane is held clear of a drilled hole without closing the area to routing.

Note that "keepout" is used in two senses here and only one of them is drawn. A rule area is a copper keepout the design tool enforces. A *mechanical* keepout — the space a cable, connector shell, or tool needs in order to mate — is a constraint on the physical product that no copper rule expresses, so nothing checks it unless someone draws a rule area specifically to stand in for it. The unqualified word usually means the copper one.

### Trunk Walk
The act of proving which copper actually carries a net's load current — establishing the series path from electrical source to sink so that narrow-but-parallel branches and sense spurs are excluded before any width rule is applied to them. A net's narrowest segment is an upper bound on ignorance, not a risk figure; the walk is what converts it into one.

Done by eye on a single visible run, or computed as a max-flow over the net's copper when it spans layers and branches — in which case the computation counts as an Instrument Finding source and earns the same treatment: calibrate it against a net whose answer is already known, both before believing its first reading and again after any edit it measured.

### Courtyard
The keep-clear region a footprint declares around itself, sized so that neighbouring parts can be placed and soldered without interference. It is an authored polygon belonging to the footprint, distinct from the pads (which are copper) and from the body outline (which is only the part's physical extent).

Two properties bite in practice. It is **frequently not rectangular**, so testing a point against its bounding box both over- and under-reports — anything asking "is this inside the keep-clear region" must test the polygon. And it is **authored, therefore omissible**: a footprint with no courtyard at all passes every courtyard check by having nothing to check, which is indistinguishable from passing on merit. A courtyard violation is also not automatically a defect; parts are sometimes deliberately placed tight, and the honest resolution is a scoped exception recording why rather than a suppressed check.

### Staged Rules
The practice of copying a board into scratch space beside a purpose-built set of sidecar files, and judging *that* copy, so the check runs against the project's real manufacturing constraints rather than whatever the design file happens to carry.

It exists because an imported board arrives with the importing tool's factory defaults rather than the fab's limits, and measuring against those produces hundreds of findings that are all false. The staging is therefore load-bearing rather than a convenience, and it has three failure modes worth knowing. **Stage too little** and the checker cannot resolve what it needs — a missing library table yields mass "not found" findings that also mask the real ones underneath, which is why a partial staging can only be trusted at the severity it was designed for. Because staging *overwrites* the copy's values for every rule it names, **the staged set outranks the design file**: a constraint tightened in the design and not mirrored into the staged set is silently relaxed for the duration of every check. And **a staged rules file that fails to parse loads as no rules at all**, with no error on any observable channel — the checker keeps reporting normally under different law, and the only announcement is the reappearance of findings the file's waivers existed to suppress. A rules file with no waivers gives no announcement, which is why any rules-file edit is proven both ways: one rule shown firing, and the previous verdict on a known case shown unchanged.

### Design Rules
The manufacturing constraints a board is drawn to — minimum clearance, track width, via diameter and drill, hole spacing — held as project metadata alongside the board rather than inside its geometry. Because they live outside the design objects, they travel separately: a tool can carry every footprint, net, and trace faithfully and still lose the rules entirely.

That separation is why rules are verified rather than assumed after any import or handoff. Measured against the wrong rules a correct board reports hundreds of violations, and a router reading those rules will produce copper the fab never agreed to — with nothing in either output indicating the constraints themselves are fiction. The tell is a violation set clustered just under a round number: real sloppiness scatters, a mismatched rule produces a band.

### Embedded Footprint Copy
Every placed footprint on a board is a full copy of its library definition, embedded in the board file at placement time — so the board and the library hold independent data for the same part, and only a field-level comparison keeps them honest.

Editing one copy never touches the other: a library-only fix changes nothing that gets fabricated, and an instance-only fix is silently reverted the next time the part is updated from the library, which is why footprint fixes here land in both. The copies are compared field-by-field in integer nanometres with pad-local overrides counted as data, so equal-looking values written at different decimal precision are genuinely different. When the copies disagree, the board copy is what gets fabricated, and reconciliation runs toward it.

### Coincident Connection
A connection made by two objects sharing an exact coordinate rather than by anything drawn between them — a net label placed directly on a pin, or a wire end landing on it. Most pins on this project's schematic are reached by a drawn wire, but a minority connect this way, and they cluster: whole sub-circuits exist in which no pin carries a wire at all.

It is genuinely connected and genuinely fragile, and the two facts are the same fact. Nothing records the *intent* to connect, so the relationship survives only while the coordinates stay equal: moving a symbol without moving everything that shares its pin coordinates silently disconnects it, and the schematic still looks right because the label is still there. Two consequences follow for any edit. Anything that relocates a part must carry its labels and wire ends by the same delta, as one operation. And placement off the connection grid, while not itself an error, removes the last thing that would make a later drag land back on the same point — so an off-grid coincident connection is a latent break rather than a cosmetic complaint.

### Embedded Symbol Copy
Every symbol placed on a schematic is a full copy of its library definition, embedded in the schematic file at placement time — the symbol-side counterpart of an Embedded Footprint Copy, and the reason a schematic keeps working long after its symbol library has stopped.

The consequence differs from the footprint case, and is worse. A footprint's two copies disagree; a symbol's embedded copy makes the library *unnecessary*. Drawing the sheet, exporting the netlist, building the BOM and checking the board all read the embedded copy, so the library on disk is consulted only while authoring — placing a new part, changing a symbol, updating fields from the library. Verification never touches it. A symbol library can therefore become entirely unloadable, taking every symbol in it down at once, while every downstream artefact stays correct and every check stays green; the failure surfaces only when someone next tries to author. Detecting it requires loading the libraries on purpose, because nothing that inspects the design will do it incidentally. The drift rule of the footprint copy still applies on top: an update-from-library rewrites instance fields from the library, so a divergence between the two is a silent revert waiting for its trigger.

### Warning Inbox
The project's treatment of design-check warnings as an inbox owed a decision: every warning is either fixed or given a scoped exemption carrying its recorded reason, and the inbox is held at zero so any standing warning is a signal rather than scenery.

The discipline exists because a warning that never clears gets waved through, and a per-item warning hides new defects behind an unchanging count — "pre-existing" is not a diagnosis. Exemption is reserved for geometry that is correct by intent; divergence between copies of the same data is drift and gets reconciled, not exempted.

Size defeats an inbox as surely as staleness does, and by a different route. Past some volume the report stops being read at all, and its total becomes a property attributed to the design — inherited noise, nothing to be done — rather than a queue anyone owns. A specific, correct, months-old finding survives indefinitely inside such a total, because nothing about it is hard except being seen. This is why the target is zero **wherever zero is reachable**: a count that only has to stop growing can never be read, while a report at zero makes the next single finding unmissable. Where a genuine inherited floor makes zero unreachable, a Ratcheted Gate is the honest instrument — but that floor is a claim about the artifact, and claims expire, so it is worth re-testing before it is renewed.

### Ratcheted Gate
A check that fails only on an *increase* measured against a recorded baseline, rather than on the presence of any finding at all — the form a gate takes when what it measures carries inherited noise that no correct change can clear. Its opposite is an absolute gate, which admits no baseline because a clean state is definable.

Choosing the wrong form fails in both directions, and neither failure is visible from the gate's own output. An absolute gate pointed at noisy output is unreachable, so it is either disabled or routinely overridden — the Warning Inbox problem arriving through the build instead of the tool. A ratcheted gate pointed at a condition with no legitimate baseline is worse, because it encodes the existing defect as the accepted floor and reports success while the defect stands. The question that settles the form is whether "zero" is a state this project could actually occupy; where it is, the gate is absolute. Where both forms are in use they stay separate steps rather than merging into one threshold, so each carries its own justification.

A ratchet is therefore a claim about the artifact, not a property of the check — and claims expire. An inherited floor is the usual justification, and floors get cleared; when that happens the ratchet keeps passing while asserting nothing, which is the failure this whole concept exists to name. Re-measure the floor before renewing a ratchet, and treat "we still need a baseline here" as a question with an answer rather than a settled fact.

Choosing the form is only half of it, because a gate of either form sees only what its severity filter admits. A check that runs, passes, and is structurally incapable of reporting the class it was meant to catch is more dangerous than an absent one, since a green result is read as evidence. So the filter belongs with the baseline as something the gate is audited on, rather than configuration that gets assumed once and inherited.

A third hazard applies only to the ratcheted form: its baseline is a number a checker produced, and a checker's count can be a Saturated Count. A ratchet whose floor sits at a reporting limit cannot detect any regression beneath that limit, and will report no new findings indefinitely.

### Instrument Finding
A defect reported by a measuring tool, before anyone has established whether the defect is in the artifact or in the tool. Naming the distinction is the point: the two are indistinguishable in the report, and the second kind is routinely acted on.

A finding is worth more scrutiny, not less, when the tool that produced it is well built — a tool that refuses to guess and reports disagreement rather than silently choosing carries authority its own correctness has to earn. Three signals put the finding itself in doubt before the artifact is touched: a grouping whose size matches an obvious confounder exactly, an intermediate value outside the range the quantity could physically take, and a comparison of derived measurements demanding exact equality. Where a finding is about to become a blocker, it is worth attacking the instrument first — validating a coordinate transform against an artifact that already holds the answer costs one comparison, and reverting a campaign costs a campaign.

The same doubt extends to what a tool *does*, not only what it reports. A tool that both detects a violation and corrects it will, if one threshold answers both questions, act on objects that were never in violation — and the excess is invisible in its own success metric, because most such metrics improve monotonically as the measured thing is destroyed. Judge a corrective tool by the population it changed measured against the requirement, never against its own threshold.

Direction matters more than it appears. A finding that is falsely *absent* is eventually surfaced by something downstream — a later gate, a fabricator, a test. A finding that is falsely *present* is instead confirmed by its own fix: the artifact is changed, the tool falls silent, and the loop closes with the artifact worse and the instrument still wrong. Nothing downstream objects, because the defect never existed. So "the tool found something, therefore something was there" is not sound, and an implausible magnitude — a finding larger than the object it is about — is worth more suspicion than a plausible one.

A third resolution exists besides "the artifact is wrong" and "the tool is wrong": an instrument whose model of the object is itself wrong — a stand-in 3D body, a proxy shape — is *uninformative* rather than mistaken, able neither to confirm nor to deny, and the finding then resolves at ground truth outside both (the part's datasheet against the footprint file), with a procedural close-out where no instrument can adjudicate. The verdict attaches to the finding, not the tool: one viewer produced a true finding on one part and an uninformative one on another in a single session, so neither trust nor distrust of the instrument transfers between findings. The converse also exists: a third party's instrument can hold answers no project-owned check has — a fabricator's CAM job is its engineer's answer sheet, so a delta between it and the design's own export is a finding in itself, resolved in either direction (their correction to adopt, or their change to challenge) rather than assumed to be error.

Beneath every case above sits one more, and it is the hardest to see: the
**absent** instrument — a number that was never measured at all, only intended,
and has been read as a measurement ever since. It produces no report, so the
scrutiny above has nothing to attach to; and unlike a falsely-absent finding,
nothing downstream ever surfaces it, because a soak, a bench log and a document
will all quote an intended value as faithfully as a measured one. The
countermeasure is not skepticism but construction: build the instrument that is
capable of disagreeing, and run it *before* changing the thing it measures.

One more sits alongside the uninformative instrument and is easy to file with
it wrongly. An instrument whose model of the object is a stand-in is
*uninformative* — it can neither confirm nor deny. An instrument that applies a
**lossy transform** to the real object is worse: it returns confident verdicts
the object itself reverses, because the transform removes exactly the
properties the judgement turns on. Viewing a rendered surface at reduced scale
is the clearest case — downsampling is a low-pass filter, so it destroys the
high-frequency structure that decides the answer and reports the remainder with
no signal that anything was dropped. Such a view is not weaker evidence about
the object; it is evidence about a different object. It also inverts the direction above: a lossy channel returns an APPROVAL rather than a silence, so nothing downstream is prompted to look, and the falsely-absent finding stops being the self-correcting one. The countermeasure is
to judge at native scale on the target rather than to look at the reduced view
more carefully.

### Saturated Count
A finding count that has reached the checker's own per-category reporting limit, so it states the limit rather than the quantity — a lower bound wearing the appearance of a measurement. Its sibling is the number that was never counted at all (see Instrument Finding): together they bracket the family of plausible figures nobody re-derived, and the test below does not catch the sibling — a value that is merely intended still moves obediently when its input moves.

It is indistinguishable from a real count from the outside: it has units, it sits in the field the tool calls a total, and it arrives most convincingly at the moment some genuine repair first made the check report anything at all. The limit applies per category rather than per report, so one category exceeding it establishes nothing about another sitting beside it in the same output — the inference that a tool "can report more than this, therefore this is real" is invalid. The test is to make the check materially stricter and re-run: a real count rises, a saturated one does not. Zero is the single reading a reporting limit cannot forge, which is why an absolute gate is immune to this and a Ratcheted Gate resting on such a floor asserts nothing. Where a count is load-bearing — sizing work, proving a before/after — derive it from the artifact rather than from the report, and name the unit, because a quantity measured off the data cannot be silently compared against one the report was willing to stop counting. A stationary count is not automatically saturated, either: a real count frozen across two different fixes indicts the fix's datum rather than the checker's ceiling — the classic shape being a clearance fix measured to a shape's bounding box while the checker measures to the manufactured outline, half a line-width inside it, so every attempt lands just outside the datum that matters and the count never moves. Both causes are told apart the same way: change what the checker measures and watch for movement.

## Track Simulation

### Circuit
The driving model TRACK mode runs behind the screen: the real racetrack lap, or a range-sweep bench fixture whose only job is walking every gauge through its full display range. Distinct from Dash Mode, which chooses *which* screen is shown — Circuit chooses what the simulator is doing behind it. Selecting a circuit abandons the lap in progress rather than resuming it, because a half-driven lap would commit a fabricated time to the lap book.

### Segment
One entry in the distance-keyed table that defines a lap: a length, a speed limit, whether that limit is a real corner constraint or merely a descriptive annotation, and how far the car's heading swings through it. Lap position is a distance along this table rather than a fraction of elapsed time, which is what makes lap time an output of the simulation instead of an input to it. A limit binds at its segment's entry boundary and across the Corner Arc beyond it; past the arc the car accelerates freely until it must brake for the next limit.

### Corner Arc
The stretch of a Segment over which the car is lateral-grip-limited: it holds roughly its corner speed to the apex, then releases progressively as the driver unwinds the wheel. Derived from the segment's *authored* limit and the car's lateral grip — never from the speed the driver actually carries.

That distinction is load-bearing rather than stylistic. A corner is a fixed length of road, so deriving its geometry from live speed makes a slower driver drive a physically shorter corner, which gives back most of the time the lower speed cost and silently cancels Driver Skill's effect on lap time.

An arc **ends by release, not by expiry**, and the difference is visible on the glass. Past the apex, lateral demand tapers toward zero: the speed the corner permits rises as the effective radius opens, and the grip freed up becomes available for acceleration, so by the arc's end the corner has become a straight and crossing that boundary is a non-event. An arc that simply stopped would hand the car its whole lateral budget between two simulation steps — which reads as a throttle slamming open, and in the real car is a spin. Where the apex falls within the arc is calibrated against lap time, because releasing earlier hands the car a share of every corner on the lap.

### Driver Skill
A single scalar standing in for how close to the car's limit the driver operates, scaling corner limits and widening lap-to-lap variation. Segments whose limit is an annotation rather than a real constraint are exempt from it, and it must never reach Corner Arc geometry.

It is calibrated last and held to a defensible range, because it is the only constant tuned directly against lap time and will otherwise absorb error from every upstream constant — at which point it stops meaning "driver" and starts meaning "whatever makes the number come out." A fit that lands outside the defensible range is evidence that an upstream constant is wrong, not a value to accept.

### Roll-on
The bounded rate at which the modelled driver opens the throttle, and the reason a Corner Arc exit is a squeeze rather than a stab: the pedal is a state that may only rise so fast, and it closes fully whenever the car is braking, so every exit builds from nothing.

The pedal is the *input* to the acceleration model, not a smoothing of its output — thrust is computed from the pedal, so the bar on the screen and the car's behavior cannot disagree. Modelling it the other way, as a filter on the displayed value, would show a gentle bar while the car still took its full acceleration instantly. It also costs real lap time, which is the honest consequence of a driver who squeezes: a model without it laps quicker than the car can.

A Corner Arc's release and the Roll-on are separate limits and both are needed. Making the release progressive removes the discontinuity but bounds nothing, because the freed grip can still arrive faster than any driver could use it.

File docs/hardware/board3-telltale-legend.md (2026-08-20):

# Board3 telltale legend

What each of the eight cluster lamps means, what colour it physically is,
and where its signal comes from. Decided 2026-08-19/20 at the bench, with
every colour **verified by eye** on the assembled board — each position
forced one at a time over the serial `tt` command, the night Board3 first
lit its LEDs. The design colours and the stuffed parts agree in all eight
positions.

This file is the authority. `MustangDash/dash_telltales.h` encodes the
firmware half of it in `DASH_LAMP_TT[]`, and
`tests/test_dash_telltales.c` pins that table.

## The cluster

The eight lamps sit as two 2×2 blocks, west (left) and east (right).
Colours fell into rows without anyone planning it, and the legend follows
that grain: **the top row is body signals, the bottom row is warnings.**

| | left cluster | | right cluster | |
|---|---|---|---|---|
| **top — body** | **TT1** green<br>Left blinker | **TT2** white<br>Headlights on | **TT3** blue<br>High beam | **TT4** green<br>Right blinker |
| **bottom — warn**  | **TT5** orange<br>Low fuel | **TT7** red<br>Parking brake / brake fault | **TT6** red<br>Oil pressure | **TT8** yellow<br>CEL / MIL |

The greens land at the outer edges of each cluster — the correct place
for blinkers — which is what first suggested reading the layout as rows
rather than as silk order.

## Full table

| Net | LED | LCSC | Colour | Cluster / position | Expander | DIM reg | Meaning | Source |
|-----|-----|---|---|---|---|---|---|---|
| TT1 | LED1 | C516142 | green | left, top-left | west U11 @ 0x5B | 0x2C | Left blinker | CAN |
| TT2 | LED3 | C516299 | white 6000–7000 K | left, top-right | west U11 @ 0x5B | 0x2D | Headlights on | CAN |
| TT3 | LED4 | C516143 | blue | right, top-left | east U12 @ 0x5A | 0x2D | High beam | CAN |
| TT4 | LED2 | C516142 | green | right, top-right | east U12 @ 0x5A | 0x2C | Right blinker | CAN |
| TT5 | LED5 | C5246349 | orange | left, bottom-left | west U11 @ 0x5B | 0x2E | **Low fuel** | firmware |
| TT6 | LED6 | C516141 | red | right, bottom-left | east U12 @ 0x5A | 0x2E | **Oil pressure** | firmware |
| TT7 | LED7 | C516141 | red | left, bottom-right | west U11 @ 0x5B | 0x2F | Parking brake / brake fault | CAN |
| TT8 | LED8 | C516140 | yellow | right, bottom-right | east U12 @ 0x5A | 0x2F | CEL / MIL | CAN |

Silk numbering is 1-based (TT1…TT8); firmware position bits are 0-based
(TT1 = bit 0). The serial `tt` command speaks silk numbers.

## Why these assignments

Colour follows the ISO 2575 / FMVSS grammar, which is not decoration —
it is what makes a cluster readable at a glance by anyone who has driven
another car:

- **Red = stop now, damage or danger.** Both reds are spent on genuine
  stop-driving faults: oil pressure (TT6) and the brake system (TT7).
  The brake warning is red by regulation (FMVSS 105) and in production
  serves double duty — parking brake engaged *and* brake fluid low /
  hydraulic failure. Those are both switch-to-ground signals and wire-OR
  onto one lamp.
- **Amber = caution, service soon.** Low fuel (TT5, orange) and CEL/MIL
  (TT8, yellow). The MIL is *required* to be amber or yellow by EPA/CARB,
  which is why it moved off a red position during this decision.
- **Green = a system is active and normal** — the blinkers.
- **Blue = high beam**, effectively universal.
- **White** has no standard meaning, which makes it the right home for
  headlights-on: an indicator, not a warning.

### Coolant temperature has no lamp, deliberately

An overheat raises the dash's **full-screen alarm takeover**, which
preempts both TRACK and STREET and is far louder than a 3.5 mm LED. The
lamp would have been redundant with a stronger mechanism. A parking
brake, by contrast, has no other way to reach the driver — so the red
went to the signal that had nowhere else to go, not the one that was
already covered.

The same reasoning demotes oil temperature, volts, fuel pressure, lean
AFR, and the shift indicator: all render on the screens today, and none
is an instant stop-driving event that the screens cannot convey.

### Everything but two lamps waits on CAN

Six of eight positions carry signals the firmware does not compute:

- **Five body signals** — both blinkers, headlights, high beam, parking
  brake — have no PCM source. They come from **RaceCapture** inputs
  (switch-to-ground → Lua → CAN frame). Doing the parking brake this way
  rather than as a discrete input is what keeps the dash a pure CAN
  consumer with **zero GPIO wiring**, and preserves the next revision's
  single spare connector pin.
  **Open item:** confirm the real RaceCapture unit has five spare inputs
  before committing the harness — this has not been checked against
  hardware.
- **CEL/MIL** comes from the Ford control pack PCM over the existing
  0x270-set bus, and belongs to a future dialect round.

So on the bench today only **TT5** and **TT6** can light from the
simulator. That is the legend working as intended, not a gap.

**The seam is built and waiting.** `DashState.tt_signals` is an 8-bit
mask of *physical positions* that `dash_telltale_mask()` joins directly —
no translation, since body signals are positions rather than warning
conditions, and the legend gives the two sets disjoint lamps. A dialect
decoder writes it and owns its own staleness, exactly as `can_owned`
channels work; the telltale layer never ages a bit out. No producer
exists yet, so an unwired bench simply shows those positions dark.

The simulator deliberately does **not** drive it. Faking body signals
would make the CAN path look proven when it is not — the same reason the
simulator writes `DashState` rather than emitting fake CAN frames. For
bench inspection, force the lamps with `tt <n> on` instead, which is
unmistakably an override.

## What this replaced

Until 2026-08-20 the firmware drove condition bit *l* onto TT(*l*+1), a
one-to-one placeholder written before the LEDs had hardware and therefore
never checkable. It was wrong in every row, and the bench proved it twice
in one evening: a forced oil-pressure alarm lit **TT1, the green left
blinker**, and a real low-fuel condition after a long simulator run lit
**TT6, a red**. Both now land where this table says.

## Bench tools

- `tt <1-8|all> on|off` — force any position; a force-ON overlay that is
  OR'd over the live mask, so it can never suppress a real warning, and
  `off` releases the force rather than blanking the lamp.
- `tt sweep` — replay the boot sweep (a column chase across the board's
  four physical LED columns, then a full-row hold that doubles as the
  bulb check).

Forcing one lamp at a time is how this legend was built; it is also the
fastest way to re-verify a board after assembly.

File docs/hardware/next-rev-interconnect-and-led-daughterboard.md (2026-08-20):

# Next-Rev Interconnect — Single External Connector + LED Daughterboard

Captured 2026-08-12 from a design discussion. Status: **direction set, nothing
committed to a schematic yet.** These are decisions-in-principle for the
revision after Board3 (the in-car packaging era), recorded so the reasoning
doesn't have to be re-derived. Part numbers below were verified in stock at
Mouser on 2026-08-12.

---

## 1. External interface: one AMPSEAL 16 8-way connector

The dash gets a **single automotive-grade external connection**: power in, two
CAN networks, nothing else. Chosen family: **TE AMPSEAL 16** (sealed, latched,
vibration-rated, PCB-mount header — the same family Haltech/Link/AEM ship on
real ECUs).

### Pin budget (8 positions)

| Pin | Signal | Notes |
|---|---|---|
| 1 | VIN (12 V) | ~1–2 A worst case (backlights via onboard buck); contacts rated 13 A |
| 2 | GND | |
| 3 | CAN1 H | keep each CAN pair on adjacent pins so the twisted pair lands naturally |
| 4 | CAN1 L | |
| 5 | CAN2 H | |
| 6 | CAN2 L | |
| 7 | IGN sense | switched-12V input so "key on" is a wire, not inferred from CAN traffic |
| 8 | spare | sealing plug until used |

(Pin assignment is illustrative — final numbering to be set against the header
drawing when the schematic is drawn. The load-bearing choices are: 8 positions,
CAN pairs adjacent, IGN sense wired, one true spare.)

### Parts (verified in stock 2026-08-12)

| Role | PN | Description | Price / stock |
|---|---|---|---|
| Board-side header | **TE 776280-1** | 8-pos right-angle PCB header **with panel gasket** | $9.71, 358 in stock (Mouser 571-776280-1) |
| Harness plug | **TE 776494-1** | 8-pos plug, 14–18 AWG, red / A-key | $4.84, 817 in stock |
| Socket contacts | **TE 776299-2** | HDSF size-16 socket, Ni, 16–18 AWG | $1.05 ea — buy ~20 (8 live + practice/re-pins) |

- 776279-1 is the same header **without** the gasket — do not substitute; the
  gasket is the enclosure seal (see §2).
- **OPEN ITEM — key match:** 776494-1 is A-key (red). The header's key letter is
  not in Mouser's description; confirm A-key from the customer drawing
  (ENG_CD_776279/776280) before ordering. Same-family-different-key is the
  classic AMPSEAL footgun.
- Harness: **18 AWG throughout** (inside both the contact range and the standard
  cavity-seal range; power is comfortable at 1–2 A). Twist the CAN pairs.
  Sealing plugs in unused cavities preserve the IP rating.
- Crimp tool: HDSF stamped-and-formed contacts; Waytek and WireCare stock
  economical AMPSEAL 16 crimpers — no need for TE's certified tool.

### Alternatives considered

- **Deutsch Autosport (AS)** — the named inspiration. Real motorsport quality,
  but ~$100–300 per side, its own crimp tooling, and it's panel-mount by
  nature: it mounts to the *enclosure* and needs an internal pigtail to the
  board (one more connection, though it fully decouples enclosure tolerance
  from the board). Still viable if the AS look becomes a goal in itself;
  architecture would be jam-nut AS on the wall + short internal pigtail.
- **Deutsch DTM** — equally legitimate; AMPSEAL 16 chosen for its PCB header
  with integrated panel gasket (one-piece solution, no pigtail).
- **3D-printing the board-side shell** — rejected. The $10 header is precision
  where it counts: molded seal surface (layer lines are leak paths and abrade
  the plug seal), latch ramp at specified retention force, and eight plated
  pins molded in at position with sealed pass-throughs. A printed shell still
  needs those pins placed to ±0.1 mm and retained — in practice glue joints,
  i.e. future intermittents, the exact failure class this bench keeps paying
  for. Also cabin temps clear PETG's glass transition. Buy the mated pair,
  print everything around it.

### Project-rule collision (flag now, not at fab time)

The TE parts are **not on LCSC**, so the header will be a hand-soldered part
outside the JLC assembly flow. Two consequences:

1. `kicad_fab.py` **silently drops** unsourced parts from the BOM — the header
   must be explicitly documented as manually-sourced, not discovered missing.
2. The board rule "every part carries a 3D model" still applies — TE publishes
   the STEP (download from te.com in a browser; the site 403s scripted
   fetches). Attach it to the footprint; it's also what drives the enclosure
   workflow below.

---

## 2. How the header mounts (it doesn't bolt to the enclosure)

The header is fixed to the **PCB** (soldered pins; flange seats on the board).
The enclosure wall closes over the shroud nose, and the flange gasket is
compressed between the flange face and the **inside surface of the wall**.
Compression comes entirely from the board mounting geometry.

```
        outside │ enclosure wall │ inside
                │                │
   plug mates  ┌┴────────┐       │
   here ──────▶│  shroud  ├──────┤ ◀── gasket squeezed between
               └┬────────┘flange │     flange and inner wall face
                │     pins ──┐   │
                └────────────┼───┘
      ═══════════════════════╧═══════ PCB
                  ▲
        standoff height sets gasket squeeze
```

Design chain (Onshape):

1. **Cutout**: rectangular opening per the drawing's recommended panel opening.
   It only clears the nose — loose is fine; the gasket seals the perimeter,
   not the cutout edge. Position accuracy comes from the board bosses.
2. **Standoff height is the load-bearing dimension**: board-mounting plane to
   inner wall face = flange seating height − gasket squeeze (~20–30% of free
   gasket thickness, from the drawing). Too tall → no seal; too short → wall
   pre-loads the solder joints.
3. **Board screws near the connector.** Mating push goes flange-into-wall
   (free); unmating pull is resisted only by solder + board screws. Keep a
   boss within ~15–20 mm of the header.
4. **Assembly order before closing the rectangle**: a closed cutout in a solid
   wall forces nose-first board insertion. Keep the cutout fully in the base
   half of a clamshell (or split it across the seam) so the board drops in and
   the lid never touches the connector.
5. **OPEN ITEM**: check the drawing for flange screw holes into the PCB. If the
   header is solder-only, point 3 matters more, and a printed internal brace
   cradling the header body is a legitimate zero-cost reinforcement.

Modeling workflow: TE STEP → KiCad footprint → `kicad-cli pcb export step` →
import board STEP into Onshape as one component → derive the cutout from the
connector geometry **in place** (never from datasheet numbers alone), so a
board revision that moves the connector moves the cutout with it. Model the
mating plug + boot + harness bend radius too — the classic enclosure mistake is
a connector that's perfect until you try to plug it in inside the dash cavity.

---

## 3. LED telltale daughterboard: AWs stay home, board goes passive

Context: telltale LEDs may move to a daughterboard so they sit exactly behind
the bezel windows. Within the gauge cluster (inches of cable).

**Decision: both AW9523Bs stay on the main board; the daughterboard is purely
passive** — LEDs and copper, nothing else.

The reasoning, because the obvious version of it is backwards: the instinct is
"keep signal wires short," but the LED lines are the *robust* ones — the
AW9523B in LED mode is a constant-current sink, so those lines are DC and
current-regulated; length, resistance, and cable capacitance are irrelevant.
The fragile bus is the **I2C**, which on this design shares its trunk with the
FRAM (U7, the odometer). Keeping the AWs on the main board keeps I2C off the
harness entirely. A glitched telltale write self-heals on the next refresh; a
glitched odometer transaction does not.

What this buys:

- Zero schematic churn on the AW section — POR-safe port mapping, RSTN
  network, address straps, and the host-tested `dash_calibration.h` ISEL table
  all carry over unchanged.
- No resistors on the daughterboard (the AW's current control replaces them).
- Trivially diagnosable failures: an LED that doesn't light is a continuity
  check, not an I2C forensics session.

### Daughterboard connector

- ~10–12 pins: **GND, +5V, TT1–TT8 in lamp-bit order** (so nobody consults a
  table with a meter in hand), plus a second GND (covers a marginal contact)
  and 1–2 spare sinks routed to unpopulated LED footprints (a ninth telltale
  later = solder one LED + firmware, not a new board). Each AW has 8 unused
  ports.
- **Gold contacts, not tin** — mA-level sinks are dry-circuit territory; tin +
  vibration = fretting corrosion = the telltale that flickers years later.
- Keyed/shrouded or obvious-orientation — a reversed connector puts +5V on a
  sink line (AW pins are 6 V-rated, so it likely survives, but don't find out).
- **Cable type**: board-to-board header + standoffs if the geometry allows
  (nothing to fatigue) > FFC (fine for one-time installation with name-brand
  cable; the bench FFC failures were insertion-cycle wear + cheap tin cable,
  not the medium) > discrete-wire latched crimp (JST GH/PA) if the cable
  crosses a gap that flexes during assembly or service. If FFC: back-flip ZIF,
  gold, contact-side orientation arrow on the silk.
- Anchor any cable near both ends so vibration flexes mid-span, not at the
  terminations.

### Optics (the daughterboard's real job)

- LED placement from the **bezel drawing**, not a tidy grid.
- Light-bleed walls or a gasket between adjacent telltale windows — the
  classic cluster defect, and it's mechanical, not electrical.
- Matte black soldermask.

### Escalation path (only if the board ever leaves the cluster)

Tens of cm through the car, or growing LED count → move the expanders to the
daughterboard and bridge I2C properly: PCA9517A buffer at the cable boundary
minimum, PCA9615 (differential I2C) if genuinely remote — the non-negotiable
part is isolating the FRAM's bus segment from cable capacitance and EMI.
Truly remote indicator panel → its own CAN node (RaceCapture already
establishes CAN as the vehicle bus). Both are overkill inside the cluster.

---

## 4. Programming: Tag-Connect only — USB is dropped (decided 2026-08-19)

**Decision, made the night Board3 hit first light: the next rev carries no USB
at all.** Programming, debug, and recovery are SWD via the TC2030 pads, full
stop. This was mooted 2026-08-12 and confirmed after a full bench session on
the real Tag-Connect flow (BCM4 option-byte write, two full flashes, live SWD
PC-sampling that diagnosed both boot hangs) proved it comfortable — Kevin has a
retaining clip, so even long sessions are hands-free.

What this deletes from the board (the whole USB input path): USBC1, the
USB-side ideal diode (LM74700 + AO4406A), the USBLC6 ESD part, the CH224 PD
sink and its dividers, and the VBUS sense chain. Note §1 already moves the
power input to 12 V VIN through the AMPSEAL, so the *barrel* 5 V input dies on
this rev too — the dual-5V-input ORing architecture collapses to one path:
VIN → buck. Two ideal-diode controllers and change, gone.

**Accepted losses, recorded once, eyes open:**

- **USB DFU field reflash.** On Board3, BOOT+RESET → DFU was the zero-tools
  "is the MCU/power/USB path alive" diagnostic AND the no-debugger reflash
  path. On this rev, both jobs need the ST-LINK + Tag-Connect. Consequence
  for placement: **the TC2030 pads must be reachable with the dash installed**
  (or pulling the cluster to reflash is the accepted cost — decide when the
  enclosure exists, but decide on purpose).
- **USB CDC serial console.** The `ok`/`err` protocol, `/dash` skill,
  `status`, `odo set`, forced alarms — tonight's whole bench session rode CDC.
  This needs a new home before the schematic freezes. Candidates, roughly in
  order of appeal: **RTT over the same SWD link** (bidirectional, zero extra
  pins, works through the Tag-Connect already attached; OpenOCD supports it),
  a 3-pin UART header (bench-only, near-zero cost), or a CAN console (car-
  native, but makes the bench depend on a CAN adapter). The BOOT/RESET
  buttons' *reflash* role goes away with DFU, but RESET stays useful.

  **GATE (decided 2026-08-19): the RTT console shim must be implemented and
  bench-proven — on Board3, where CDC still exists as the fallback — before
  any v2 schematic deletes USB.** Board3 is the risk-free proving ground:
  same die, same debugger, and if RTT disappoints, USB is still there. The
  in-car operating model this enables: car 12 V powers the board always;
  the tag (pads reachable with the dash installed) carries programming AND
  the console; the programmer never powers the board; a flash interrupted
  by power loss is a reflash, not a brick.
- The boot-banner-races-CDC-enumeration problem (500 ms wait, bit us at first
  light) becomes moot or changes shape with the console choice — RTT and UART
  don't enumerate.

Firmware consequence: the next-rev env drops `USBCON`/`USBD_USE_CDC`, and
`Serial` maps to whatever the console decision lands on.

---

## 5. Bench FFC restock (already ordered 2026-08-12)

For the RiBus panel connections (20-pin, 0.5 mm):

- **Molex Premo-Flex 15020-0219** — 0.5 mm, 20 ckt, gold (AU), 203 mm,
  Type A (same-side contacts — verified against the working cable), qty 5.
- The retired cables were **tin** — three strikes: dry-circuit oxide at SPI
  signal currents (the left panel's 0x68 failure signature), soft plating worn
  out by bench insertion cycles, and tin-on-gold mixed-metal mating into the
  panels' gold-flash ZIFs (accelerated fretting). **Toss them, don't bin
  them** — a backup that reintroduces the failure mode isn't a backup.
- Cables are consumables: a suspect one gets swapped and binned, not debugged.
  Mark the known-good set.

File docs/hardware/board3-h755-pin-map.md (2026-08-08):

# Board3 STM32H755ZIT6 Pin Map (U1 — definitive reference)

Part: STM32H755ZIT6, LQFP-144 (JLC C730212). Pin numbers verified against DS12923 Rev 3 Table 8/9 (STM32H745xI/G — identical pinout per the datasheet's compatibility statement), extracted 2026-07-25. The schematic (U2–U7) and the firmware's Board3 pin table both follow this document; any change lands here first.

**Status: AS-BUILT (2026-08-07).** Layout is frozen, the board is ordered, and every row below was re-verified against a fresh `kicad-cli sch export netlist` extract on 2026-08-07. The firmware's `board3` / `board3_mule` envs run these pins verbatim. The DRAFT clause is retired; changes now mean a board respin.

## Panel SPI buses (point-to-point, 33 Ω series at MCU, 10 kΩ CS pull-up + 100 kΩ MISO pull-down per bus)

| Net | Port | LQFP-144 pin | AF |
|---|---|---|---|
| Center SCLK (SPI1_SCK) | PA5 | 44 | AF5 |
| Center MISO (SPI1_MISO) | PA6 | 45 | AF5 |
| Center MOSI (SPI1_MOSI) | PA7 | 46 | AF5 |
| Center CS | PD8 | 76 | GPIO |
| Center PD-reset | PD11 | 81 | GPIO |
| Left SCLK (SPI2_SCK) | PB13 | 73 | AF5 |
| Left MISO (SPI2_MISO) | PB14 | 74 | AF5 |
| Left MOSI (SPI2_MOSI) | PB15 | 75 | AF5 |
| Left CS | PD9 | 77 | GPIO |
| Left PD-reset | PD12 | 82 | GPIO |
| Right SCLK (SPI4_SCK) | PE2 | 1 | AF5 |
| Right MISO (SPI4_MISO) | PE5 | 4 | AF5 |
| Right MOSI (SPI4_MOSI) | PE6 | 5 | AF5 |
| Right CS | PE3 | 2 | GPIO — **moved from PD10 at layout (U18, 2026-07-28)**: PD10 exits the west edge and crossed the entire package to reach FPC3; PE3 is free, full-speed, and sits inside the right-panel SPI escape group on the east edge. PD10 is now unassigned. |
| Right PD-reset | PD13 | 83 | GPIO |

Rules: no `_C` dual-pad pins on any SPI net (PC2_C pin 30 exists but is analog-only — unused); no pull-down on PB15 (a low PB15 blocks all non-USB ROM-bootloader interfaces, AN2606 §52).

## QUADSPI NOR (W25Q256JVEIQ, C97522 — as ordered; an earlier draft said W25Q512/C7389628)

| Net | Port | LQFP-144 pin | AF |
|---|---|---|---|
| CLK | PB2 | 51 | QUADSPI_CLK |
| NCS | PG6 | 86 | AF10 BK1_NCS |
| IO0 | PF8 | 22 | BK1_IO0 |
| IO1 | PF9 | 23 | BK1_IO1 |
| IO2 | PF7 | 21 | BK1_IO2 |
| IO3 | PF6 | 20 | AF9 BK1_IO3 |

IO3 on PF6 (verified bonded with the AF) keeps PD13 as the right panel's reset. The generic-carrier pin table ran verbatim until U18 (2026-07-28) moved Right CS to PE3 — one pin-constant edit, sanctioned by the DRAFT clause above and recorded in the firmware-edits list below. PF6–PF9 form a contiguous cluster (pins 20–23) for tight layout. ES0445 note for firmware: memory-mapped read of the region's last byte returns 0x00 and can stall AXI — pad `FSIZE`.

## Peripherals

| Net | Port | LQFP-144 pin | AF |
|---|---|---|---|
| FDCAN1 RX / TX (CAN A) | PB8 / PB9 | 136 / 137 | AF9 |
| FDCAN2 RX / TX (CAN B) | PB5 / PB6 | 132 / 133 | AF9 |
| I2C2 SCL / SDA (FRAM 0x50, AW9523B west 0x5B, AW9523B east 0x5A) | PB10 / PB11 | 66 / 67 | AF4 — trunk taps forward from the FRAM (U7) per the I2C revision plan (2026-07-28-001); ~200 mm with four device loads, well inside 400 pF at 400 kHz |
| USB OTG_FS DM / DP | PA11 / PA12 | 100 / 101 | AF10 |
| USB VBUS sense | PA9 | 98 | additional fn OTG_FS_VBUS — wired to VBUS via removable link (Nucleo SB21 analog) |
| SWDIO / SWCLK | PA13 / PA14 | 102 / 107 | AF0 |
| SWO (test point only; header stays 5-pin) | PB3 | 130 | AF0 |
| ~~Lamps (ULN2803 inputs)~~ **superseded 2026-07-29** | ~~PD0–PD7~~ **unassigned** | 112–117, 120, 121 | The telltales left the MCU in the I2C revision (plan 2026-07-28-001): two AW9523B expanders on I2C2 drive them. West IC **U11** at 0x5B (AD1=AD0=+5V — every port POR-safe), east IC **U12** at 0x5A (AD1=+5V, AD0=GND — LEDs on its POR-safe P1_4–P1_7). Both ICs run **VCC=+5V** (power-on "high" equals the anode rail, LEDs hard off; all pins rated 6 V abs max, I2C VIH fixed 1.4 V so the 3.3 V trunk is legal). RSTN strapped to +5V (internal 100 kΩ pull-DOWN). INT unused — `dash_button.h` polls; the AW9523B's anti-jitter stacks harmlessly. Firmware: ISEL ×2/4 range (~18.5 mA full-scale), DIM registers 0x2C–0x2F both ICs, 5 ms post-POR wait, ID reg 0x10 reads 0x23. PD0–PD7 are free for future use. **Re-verified 2026-08-08 against Awinic DS V2.4 (Mar 2024):** VIH fixed 1.4 V max (explicitly "accept 1.8V logic input"), address = 1011 0 AD1 AD0 → 0x5B/0x5A, Table 1 POR rows match both straps (west all-high/Hi-Z; east P1_4–P1_7 high — the LED bank), RSTN 100 kΩ pull-down + 10 µs filter, ID 10H = 23H. The datasheet's own Figure-2 note states the anode-rail rationale this design uses. |
| Buttons BTN1–BTN4 (active-LOW, internal pull-up, 1 kΩ series, pressed→GND) | PC6 / PC7 / PC8 / PC9 | 93 / 94 / 95 / 96 | GPIO — **BTN1 (PC6) is the mode/trip gesture button** in firmware; BTN2–4 wired, unassigned. An earlier draft said PC13; **PC13 is unconnected on Board3** and the firmware remap landed 2026-08-07 (`DASH_BOARD_BOARD3`). |
| HSE crystal 25 MHz (X1, C9006 = YXC X322525MOB4SI, **CL 12 pF**, ±10 ppm; C41/C42 18 pF discretes -> CL_eff = 9 pF + ~3 pF stray = 12 pF, correct — closes the 2026-08-07 EE review footnote) | PH0 / PH1 | 25 / 26 | OSC_IN / OSC_OUT — firmware clocks 25/M5×N160/P2 = **400 MHz** at VOS1, LDO supply; USB runs on HSI48+CRS so enumeration is crystal-independent |
| NRST (button + 100 nF) | NRST | 27 | — |
| BOOT0 (10 kΩ pull-down + button to 3V3) | BOOT0 | 135 | — |
| VCAP — 3 pins, 2.2 µF each, not tied together | VCAP | 68, 103, 140 | verify count visually in the PDF (text extraction shows three rows; expected for the dual-core part's domains) |

Power strapping (DS12923 §3.5.1): VDDSMPS ties to VDD (hard sequencing rule); VSSSMPS → GND; VLXSMPS/VFBSMPS floating (community-confirmed for H745/755 — re-verify at U2 against the current datasheet rev).

## Enumerated firmware edits (complete list)

1. ~~FRAM I2C: the sketch's `Wire.begin()` uses the variant default (collides with FDCAN1 on PB8/PB9) — add the Wire pin selection to PB11/PB10 (SDA/SCL) in the Board3 build glue.~~ **Closed 2026-07-29 (U21):** `dash_lamps_init()` sets `Wire.setSDA(PB11); Wire.setSCL(PB10)` before any `Wire.begin()`; the FRAM inherits the corrected pins.
2. Right CS is **PE3**, not PD10 (`DASH_CS_PINS[right]` in the sketch — applied 2026-07-28 with U18; see the panel-SPI table note).
3. **Applied 2026-07-29 (U21):** the carrier branch drives lamps through the two AW9523Bs (addresses/registers per the Lamps row above); `DASH_LAMP_PINS` no longer exists on the carrier. Teensy and F767 branches unchanged.
4. **Applied 2026-08-07:** gesture button PC13 → **PC6** (BTN1) under `DASH_BOARD_BOARD3` — PC13 is unconnected on Board3. `[env:board3]` created (nucleo_h743zi variant + 25 MHz `SystemClock_Config` override, LDO supply, USB CDC); `[env:board3_mule]` runs the same firmware on the bench NUCLEO-H755ZI-Q (SMPS clock block via `DASH_MULE_H755Q`). U2 JEDEC-ID probe (`0x9F` → expect `EF 40 19` for the W25Q256) prints in every boot banner. One-time first-connect on any H755: `BCM4=0` option byte. See `docs/hardware/board3-bringup-card.md`.

Plus whatever pin reassignments U8's layout earns (recorded here at freeze). The generic-carrier branch's tables apply verbatim *as drafted*; the final firmware pin table is written from this doc after layout. Board-glue items (clock/PWR LDO flag, build env, CM4 park, `DASH_SPI_RUN_HZ` walk values) are tracked in the plan's Dependencies.

## U1 part selections

| Role | Part | LCSC | Notes |
|---|---|---|---|
| 5 V → 3.3 V buck | TPS563201DDCR (TI, 3 A sync, SOT-23-6) | C116592 | 103k stock @ $0.07 (2026-07-25); replaces the K7803 THT module |
| HSE crystal | 25 MHz ±20 ppm, 3225 SMD, load caps per part CL | pick at U2 | DFU is crystal-free (AN2606 §52) — value serves the app PLL only (25→480 MHz: /5 ×192 /2) |
| CAN connectors | 5.08 mm 2-pin screw terminal per bus | pick at U6 | exact LCSC chosen from stock at capture time |

## H743 single-core fallback (stock hedge) — status: NOT yet cleared

The H743ZIT6 shares the LQFP-144 land pattern, but pins 14–17 differ (SMPS pins on the H755 vs other functions on the H743), so the strap nets (VDDSMPS→VDD etc.) may conflict with what the H743 puts on those physical pins. A pin-by-pin diff of positions 14–17 (and any other divergent rows) is required before the fallback can be relied on. Do this before the U10 order decision if JLC stock looks thin.

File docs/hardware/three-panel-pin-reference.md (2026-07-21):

# Claude Code Handoff — Mustang Dash, Three-Panel Pin Reference

Project: github.com/kms254/Mustang-Dash-Test
Purpose: complete, verified hardware truth for the three-panel bring-up so firmware
can be reviewed/extended against real pin assignments, not assumptions.

---

## Hardware summary

- Host: Teensy 4.1, bare (not the Copperhill triple-CAN board), bench-prototyped
  on breadboards, headers soldered to MTCELL FPC-20P 0.5mm breakouts.
- Displays: 3x Riverdi EVE4, BT817Q controller, RiBus 20-pin 0.5mm ZIF, no-touch:
  - Center: SM-RVT70HSBNWN00, 1024x600, 1000 nit
  - Left: SM-RVT50HQBNWN00, 800x480, 1000 nit
  - Right: SM-RVT50HQBNWN00, 800x480, 1000 nit
- SPI bus is SHARED (single SCK/MOSI/MISO) across all three panels. Each panel has
  its own dedicated CS and PD (power-down/reset) pin. This is the critical
  constraint: only one panel's CS may be asserted (low) at a time, or bus
  contention results. Verify the firmware's EVE instance-management explicitly
  guards against overlapping CS assertion across the three display contexts.
- Bench power: Teensy runs off USB (5V/3.3V via its own regulator) for logic;
  panel backlights run off a bench buck independently calibrated to 5.00V.
  Common ground ties Teensy, buck, and all three panel breakouts together.
- Library target: RudolphRiedel/FT800-FT813 (or current fork/successor), same
  family as the Skygauge/FT8XX Teensy-4.1-tuned fork referenced during bring-up.
- Panel 1 (center 7") is bench-verified working: HELLO MUSTANG rendered, SPI
  confirmed alive, REG_PWM_DUTY software backlight dimming confirmed via a
  pulsing loop. Panels 2 and 3 are being wired now using the same method.

---
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

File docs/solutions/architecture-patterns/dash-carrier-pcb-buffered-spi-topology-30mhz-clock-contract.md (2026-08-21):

---
title: "Buffered shared-SPI topology and 30 MHz clock-walk contract for the dash carrier PCB"
date: 2026-07-19
problem_type: architecture_pattern
category: architecture-patterns
module: spi-bus
component: tooling
severity: high
applies_when:
  - "raising DASH_SPI_RUN_HZ (the SPI Operating Point) on the dash carrier PCB via the U9 read-integrity soak"
  - "reads fail before writes at a higher SPI clock — try the Teensy LPSPI delayed sample point before blaming signal integrity"
  - "revising the carrier PCB SPI signal path: source termination, LVC buffer/combiner, per-panel series resistors, FFC runs"
  - "probing the bus during a soak — TP1=SCLK_C, TP2=MOSI_C, TP3=MISO_NODE, TP4=CS_C, TP5=GND"
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

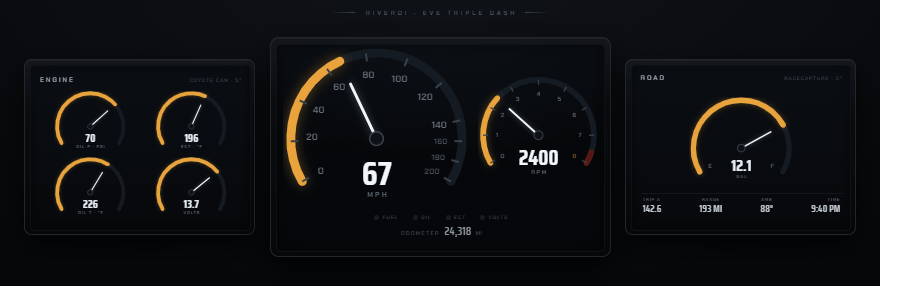
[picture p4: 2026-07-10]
assets/dash-design/renderings/02-street-mode.png

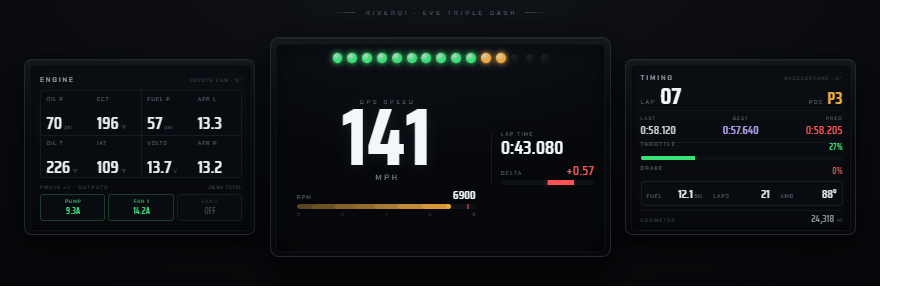
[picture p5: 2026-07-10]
assets/dash-design/renderings/01-track-mode.png

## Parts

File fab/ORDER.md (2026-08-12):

# Board3 — order form answers

The JLCPCB quote form asks for things the gerbers do not state. Getting them
wrong causes a hold, a re-quote, or a board that arrives with parts missing.
This file sits beside the upload files because that is where you will be
standing when the form asks.

**Every value below was measured from the board on 2026-08-03, not copied from a
plan.** Where a fact is not in the board file at all, that is called out — those
are the ones nothing will catch for you.

## Fabrication

| Field | Answer | Why it is not obvious |
|---|---|---|
| **INPUT VOLTAGE** | **5 V ONLY at the barrel jack** | There is NO regulator between DC1 and the 5 V rail: DC1 -> F1 (PTC) -> Q2 (reverse-polarity FET) -> `/+5V`. U3 is the 5 V->3.3 V buck, downstream. A 12 V supply puts 12 V straight onto U8/U9, U11/U12 (6 V abs max), all eight LEDs and pins 17/18 of all three panel connectors. The board is silked `5V ONLY`. |
| Board size | **250 × 50 mm** | The routed outline is exactly 250.000 × 50.000; 250.254 × 50.254 is the bounding box **including the 0.254 mm Edge.Cuts line width** — harmless at quote, wrong if anyone computes panel utilisation from it. Not 230 × 50 — that figure circulated in session notes and review prompts and is wrong (U39). |
| Layers | **4** | |
| Thickness | **1.6 mm** | |
| Copper weight | **1 oz (35 µm) OUTER, 0.5 oz (17.5 µm) INNER** | Read this off the board, do not assume it is uniform. The stackup block gives F.Cu and B.Cu `(thickness 0.035)` and **In1.Cu and In2.Cu `(thickness 0.0175)`** — confirmed independently in the generated `.gbrjob`. This row said "1 oz, outer and inner" until 2026-08-04, which is wrong for half the stack: answering 1 oz inner moves JLC onto a different build with different dielectric thicknesses, which costs more **and** invalidates the 90 Ω USB pair geometry two rows down (computed against 0.2104 mm F.Cu→In1 prepreg). The design rules here (0.1016 mm min track/clearance) are JLC's standard limits; 2 oz would relax nothing and cost more. |
| Surface finish | **ENIG** | `(copper_finish "ENIG")` is in the board's stackup block. A real cost adder over HASL, so it will not be chosen for you. |
| Solder mask colour | **GREEN — required, not a preference** | The narrowest pad-to-pad mask dam is **0.180 mm** (U1.129 ↔ C6.2), with **42–47 dams under 0.20 mm** and **320+ under 0.25 mm** (two independent measurements agree on the narrowest and differ on the count by method; the earlier "51" here matched neither). The decisive case is intra-footprint, which none of those counts include: **U1's LQFP-144 adjacent-pin dam is 0.220 mm**, ×143 on that one part, plus U11/U12 at 0.212 mm and USBC1 at 0.200 mm. Green holds a 0.1 mm dam, so those pass with ~80 µm to spare. **JLC's other colours need 0.25 mm**, which every one of those — all 320+ — would violate — the mask would simply not print between those pads, next to a 0.5 mm-pitch QFP. Picking a colour for looks is a real defect here. |
| Minimum hole size | **0.20 mm** | Every via but one drills 0.25; the single BTN1 via at U1.93 is 0.5/0.2 and forces the lower tier. Declaring 0.25 is wrong. Stated as a rule rather than a count — the count moves with every routing change (U50 took it 222 → 234), and a stale number here is worse than none. |
| Via covering | **Tented** | The board sets `m_TentViasFront` and `m_TentViasBack` true. JLC's *plugged*-via service caps at 0.5 mm and ours are 0.6 mm, so tenting is the only option that matches. **Three vias are deliberately NOT tented** — the TP1 `/+5V` (126.251, 107.730), TP2 `/+3V3` (**121.314, 99.332** — moved by U59) and TP3 `/GND` (130.442, 110.508) probe points (U53), so you can confirm the rails on a board that looks dead. They carry an explicit not-tented override, so they survive the board-level "tented" answer; do not let anyone "fix" them back. **TP2 was at (135.508, 110.254) until 2026-08-04 and had to move**: it sat 0.0295 mm from C34's pad, below the 0.100 mm minimum mask width, so the two apertures merged into one opening in the exported gerber — a solder-theft path into an MCU rail decoupler. Both are `/+3V3`, and `solder_mask_bridge` only fires between *different* nets, so DRC could not see it. Check the mask dam, not just the DRC result, before untenting anything. |
| Impedance control | **Not ordered** | `(dielectric_constraints no)`. The USB pair is built to a 90 Ω target against the stackup below, but JLC will not verify it and is not being asked to. |
| Stackup | **JLC04161H-7628** | **This string appears nowhere in the `.kicad_pcb`** — only the numeric values match the template. Nothing binds the order to it, so it has to be selected by hand. |

## Assembly

**Plain SMT assembly is not sufficient. The service must include through-hole /
hand-soldering**, or the board arrives with no power input, no CAN terminals and
no buttons.

**12 components have plated through-holes:**

    DC1                     power jack
    P1, P2                  CAN terminals
    H1, H3                  CAN termination jumpers
    SW1, SW2, SW3, SW4      buttons
    SW6, SW7                reset, boot
    USBC1                   mid-mount USB-C (through-hole legs)

Two exclusions worth stating, because both look like they belong on that list
and do not:

- **H2 is not on it.** The Tag-Connect TC2030-IDC-NL is a *cable*, not a fitted
  part — its three holes are NPTH alignment holes and its six pads are bare
  copper for pogo pins. Nothing is soldered. It is also `in_bom no` and
  `in_pos_files no`, so it appears in neither the BOM nor the CPL.
- **MP1–MP4 are not on it.** They are the four EasyEDA corner mounting pads —
  plated holes, but board features rather than components, and excluded from BOM
  and CPL by attribute.

## Known risk at order time

**U1 (STM32H755ZIT6, `C730212`) stock — RE-CHECKED 2026-08-03: 25 units.**
It was 37 on 2026-08-02. Down a third in a day, and this is the part that gates
the order: ~64% of per-board component cost ($27.26 of ~$42.31), Extended
(feeder fee), and its only variant `C1343604` is at 0.

**There is no drop-in substitute.** Checked 2026-08-03 against the same package
and subcategory: the single close match is `C730144` STM32H723ZET6 (3259 in
stock, $12.43) and it is **not a substitution** — single-core Cortex-M7 against
the H755's dual-core M7+M4, 512 KB flash against 2 MB, different I/O count.
Adopting it is a redesign, not a swap.

This is the pattern that hit U2, which went 2,163 → 4 units in seven days.
**Check stock immediately before ordering.** If it has gone, the order is blocked
regardless of everything above, and the decision becomes buy-elsewhere-and-consign
or wait.

**Panelisation.** No component-free rail is provided on any board edge and none
is designed in. Measured courtyard-to-edge clearance: **left −0.29 mm** (USBC1
deliberately overhangs, as an edge connector must), **bottom 0.28 mm** (P2),
**top and right 2.33 mm**. Assembly lines generally want ≥5 mm on two opposite
edges for the conveyor, so at 250 × 50 mm — long, narrow, and populated to three
of four edges — expect JLC to add rails themselves. Worth confirming at quote
rather than discovering it as a hold. Nothing in the board files declares an
intent either way.

**Drill files.** The package ships **separate PTH and NPTH Excellon files**, not
one merged file. That is deliberate: H2's three 0.9906 mm holes are non-plated,
and in a merged file the only thing marking them so is a comment. H2 is a
Tag-Connect land pattern whose pogo pins press on **bare copper** — plating those
holes is not a cosmetic error. Do not "helpfully" merge them when uploading.

**The NPTH file carries FIVE holes as of 2026-08-11, not three.** USBC1's two
Ø0.65 mm locating pegs were originally modeled as filled Edge.Cuts polygons —
artwork that reaches neither Excellon file — and JLC's CAM engineer silently
added the two ~0.744 mm holes for order Y4-13066334A. The footprint
(`USB-C_SMD-TYPE-C-31-M-12_1`, library and placed instance both) now declares
them as real NPTH pads at the same coordinates, so every future export drills
them without relying on a fab engineer's alertness. Any zip built before
2026-08-11 ships a 3-hole NPTH file; order Y4-13066334A is unaffected (JLC
already built the 5-hole version from their own fix).

## Board state

**ORDERED 2026-08-10**, from the `board3-v1.0.1` release assets: PCB prototype
**Y4-13066334A** (qty 5, green/ENIG/TG155, JLC04161H-7628, 0.2 mm via class
with auto-selected 4-wire Kelvin, Confirm Production File YES) + Economic PCBA
**SMT026081160502-13…** (qty 2, top side, THT hand-solder tier, Confirm Parts
Placement YES). $288.70 all-in, estimated ship 2026-08-17. An **assembly
remark is attached to the PCBA item**: JLC's 3D model for U2 (C97522, WSON-8
8x6) is undersized/mis-oriented, so their viewer cannot verify it — pin 1
(/CS, PIN 1 INDENT) must land on the **south-east pad**, per Winbond datasheet
Figure 1a (link in the remark). Checkpoint status: **production-file
confirmation DONE 2026-08-11** — executed by downloading their production file
and diffing the CAM job against our export, not by eyeballing the render.
Outcome: H2's three NPTH holes confirmed unplated (dedicated npth layer AND
non_plated-flagged in the unified drill program), TP1–TP3 untent openings
confirmed to 1.6 µm, all 7 slots present and plated, and **four holes JLC
added**: two 0.744 mm NPTH at USBC1's locating pegs (their engineer fixed a
real footprint defect — see the drill-files caveat below) and two corner
tooling NPTH (1.05 / 0.80 mm, the order form's "Tooling holes: Added by
JLCPCB"). Method write-up:
`docs/solutions/developer-experience/diff-the-fabs-production-file-before-confirming-the-order.md`.
**Parts-placement confirmation DONE 2026-08-11** — executed via browser
automation on the share page (an SPA: a plain fetch returns the empty shell and
"No data" is not an answer). "Show Revised Items" = the engineer's diff, 33 of
142 parts flagged; adjudicated per finding: U2 = our assembly remark executed
(pin 1 now renders at the design's SE corner), six already-correct LEDs
re-flagged by library normalization, all polarity families verified via one
representative each (8 clicks: U2, LED1, LED7, U7, U5, U11, D10, X1 — every
one matched design truth). Checkpoint confirmed; boards released to the line.
Method write-up:
`docs/solutions/developer-experience/audit-the-fabs-revision-set-before-confirming-placement.md`.
Still pending: only the possible small X1 crystal-handling fee.

As of 2026-08-07, after the seven-lens pre-order review (all seven verdicts
ORDER) and the one copper change it produced:

- **`/VBUS` input trunk reinforced.** The full USB input current crossed a
  single 0.400 mm × 3.6 mm Top segment — measured by max-flow over the copper
  graph, closing triage item 50 — and the LM74700 ORing pair means a slightly
  higher USB source carries the whole load even with the barrel plugged in.
  A 1.0 mm parallel same-net conductor now overlaps it (merged, ~1.4 mm
  combined); max-flow went **0.400 → 0.650 mm-equivalent**, worst-case rise at
  the documented 1.65 A from **~+19 °C → ~+9 °C**, at parity with the barrel
  side's accepted 0.900 mm / +5 °C point. The min-cut now sits on the 0.650 mm
  vertical run to Q1 — so the layout guide's literal "≥60 mil input trunk" row
  is still not met on the USB path, **deliberately**: meeting it would re-lay
  that run plus both upstream branches, and +9 °C at worst case does not buy
  that risk. Recorded here so the rule row and the board stop disagreeing
  silently.
- **U2 (W25Q256 QSPI NOR) stays fitted, conditionally.** No firmware consumes
  it yet; the decision to keep it (vs DNP, ~$23/run) was made 2026-08-07 **on
  the condition that the JEDEC-ID smoke test on the bring-up card runs on the
  first board** — until it passes, a dead U2 is invisible.
- **Bench prerequisite:** the order has H1/H3 headers but **no 2.54 mm
  shunts**, and CAN bring-up needs H1 closed on day one. Shunts in the parts
  order or confirmed in the drawer before boards arrive.
- Bring-up procedure, TP map and debt list: `docs/hardware/board3-bringup-card.md`.

As of 2026-08-05, after the silkscreen campaign:

- DRC **0 errors, 0 warnings, 0 unconnected, 0 schematic parity** (run in place,
  `--severity-all --schematic-parity`) — and now **with a silkscreen rule that
  actually runs**. `min_silk_clearance` in the `.kicad_pro` plus three armed
  `silk_*` severities were enforcing nothing; the check exists only once a
  `silk_clearance` rule is in the `.kicad_dru`. Silk-to-pad went **233
  violations → 6**, all six scoped exceptions carrying their measured worst
  (D10/D11's cathode bands, R9 against U1.52)
- BOM 41 lines / CPL 142 rows, symmetric — the tool is the authority on these
  numbers, not this file; it read 42 here from 2026-08-03 while the committed
  BOM was already 41
- Every via-in-pad remaining is deliberate (U4's exposed-pad thermal vias, Q2's
  plane stitches, U1.93's documented exception)
- Narrowest solder-mask dam **0.180 mm**, narrowest different-net copper
  clearance **0.101672 mm** (pre-existing, `/+5V_BARREL` ↔ `/GATE_BARREL`), and
  no untented via closer than **0.565 mm** to a pad aperture. DRC alone does not
  cover the first or third of those — see the Via covering row.

**Re-upload the gerbers AND the CPL if you are ordering after 2026-08-10.**
P1/P2 (the CAN screw terminals) were rotated 180° so the wire mouths face the
bottom board edge — caught in JLCPCB's 3D placement viewer during the first
order, where both JLC's model and KiCad's showed the mouths facing into the
board. The change is **electrically null** (the pins sit on the rotation axis,
so each hole keeps its net — `/CANx_H` stays on the west hole; copper is
untouched, airwires 0, netlist diff is exactly the four pin-membership swaps)
but it changes two shipped artifacts: the **CPL** (P1/P2 rotation 0 → 180, which
is what tells the hand-solder crew which way the body faces) and
**`F_Silkscreen.gbr`** (the body outline flipped with the part and is clipped
0.15 mm short of the board edge). A pre-2026-08-10 CPL orders boards whose CAN
wires point at the LQFP. Do not "fix" this by rotating in JLC's own editor —
their placement UI has no rotate control (verified 2026-08-10).

**Re-upload the gerbers if you are ordering after 2026-08-07.** The `/VBUS`
reinforcement is a **copper change** (one new F.Cu conductor plus the refilled
Top GND pour around it), so any zip built before 2026-08-07 describes a board
with the old 0.400 mm neck. BOM/CPL are untouched by it. The earlier
re-upload rules below still apply to older zips.

**Re-upload the gerbers if you are ordering after 2026-08-05.** The silkscreen
campaign rewrote `F_Silkscreen.gbr` across 160 shapes — 50 narrowed, 88 trimmed,
22 removed — so any zip built before 2026-08-05 prints markings this board no
longer draws. **Copper, drills, mask, paste and the BOM/CPL are untouched by
it** (150 footprints, 229 nets, 2780 tracks, 238 vias, 660 pads, identical), so
this one is a silkscreen-only re-upload. Everything below still applies to any
zip older than 2026-08-04.

U50 moved the
four panel-SPI series resistors (R33/R34/R36/R37) to their MCU pins and re-cut
their nets, so any zip built before that describes different copper. The CPL
changed too — those four parts moved and their rotations went 90° → 180°/0°.
U57 then took the four CAN termination resistors (R10/R14/R15/R24) from 0603 to
0805 — **a different LCSC part, C3959530, so the BOM changed as well as the
copper** — moved R15 0.70 mm, and put two vias and a short Bottom-layer run
into `/CAN2_TX`. U58 added **two more parts** (C72/C73, TJA1051 VIO bypass):
no new BOM line — they are the 100 nF Basic part already fitted 41× — but the
**CPL grew from 140 to 142 rows**, so an assembly order placed against an older
CPL will leave both unfitted.
`gerbers-jlcpcb.zip` is a build artefact and is not tracked; regenerate with
`"C:/Program Files/KiCad/10.0/bin/python.exe" tools/kicad_fab.py kicad/board3`.

**No open electrical items.** U42 closed 2026-08-03: the CAN termination
mid-point capacitors (C57/C58) are deleted, so each bus is now a plain
120.8 Ω end termination selected by its jumper. With H1/H3 **open** the
resistors float — there is no longer a permanent RC load on `CAN_L`. Fit the
jumpers only if this board is at an end of the CAN bus.

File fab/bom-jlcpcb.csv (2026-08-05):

Comment | Designator | Footprint | LCSC Part #
2.2uF | C3,C4,C5 | C0603 | C23630
100nF | C6,C7,C8,C9,C10,C11,C15,C17,C18,C19,C20,C21,C22,C23,C24,C25,C26,C27,C28,C32,C33,C34,C35,C36,C37,C43,C44,C45,C46,C52,C53,C54,C55,C56,C59,C60,C61,C62,C63,C64,C65,C72,C73 | C0603 | C14663
22uF | C29,C30,C31,C48,C49,C66,C67,C68 | C0805 | C45783
4.7uF | C38,C39 | C0805 | C1779
1uF | C40,C47,C50,C70,C71 | C0603 | C15849
18pF | C41,C42 | C0603 | C1647
10uF | C51 | C0805 | C15850
USBLC6-2SC6 | D9 | SOT-23-6_L2.9-W1.6-P0.95-LS2.8-BL | C7519
1N5819WS | D10,D11 | 1N5819WS | C191023
DC-005-A250 | DC1 | DC-IN-TH_DC-005-2 | C720558
1812L300_30GR | F1 | 1812L300_30GR | C48985875
5034802000 | FPC1,FPC2,FPC3 | FPC-SMD_5034802000 | C234192
PZ254V-11-02P | H1,H3 | HDR-TH_2P-P2.54-V-M | C492401
BLM18PG121SN1D | L1 | L0603 | C14709
2.2uH | L2 | IND-SMD_L4.0-W4.0_FNR40XXS | C167869
HL-A-3528U51GC-S1-13HL | LED1,LED2 | HL-A-3528U51GC-S1-13HL | C516142
HL-A-3528H343W-S1-13HL-HR3(SDCM 6)(6000K-7000K) | LED3 | HL-A-3528H343W-S1-13HL-HR3_SDCM_amp_lt_6_6000K-7000K | C516299
HL-A-3528H203BC-S1-13HL | LED4 | HL-A-3528H203BC-S1-13HL | C516143
HVO-3528CPXA | LED5 | HVO-3528CPXA | C5246349
HL-A-3528S35FC-S1-13HL | LED6,LED7 | HL-A-3528S35FC-S1-13HL | C516141
HL-A-3528S31YC-S1-13HL | LED8 | HL-A-3528S31YC-S1-13HL | C516140
WJ500V-5.08-2P | P1,P2 | CONN-TH_2P-P5.00_WJ500V-5.08-2P | C8465
AO4406A | Q1,Q2 | SOP-8_L5.0-W3.8-P1.27-LS6.0-BL | C2944312
10k | R1,R2,R4,R7,R11,R12,R13,R45,R46,R47,R49,R60,R61 | R0603 | C25804
33k | R3 | R0603 | C4216
4.7k | R5,R8 | R0603 | C23162
1k | R6,R28,R29,R30,R31 | R0603 | C21190
33 | R9,R32,R33,R34,R35,R36,R37 | R0603 | C23140
60.4 | R10,R14,R15,R24 | ERJP06F60R4V | C3959530
100k | R41,R42,R43 | R0603 | C25803
HX TS4538CJ 250gf 009 | SW1,SW2,SW3,SW4,SW6,SW7 | SW-TH_4P-L4.5-W4.5-P3.00-LS5.0 | C5340169
STM32H755ZIT6 | U1 | LQFP-144_L20.0-W20.0-P0.50-LS22.0-BL | C730212
W25Q256JVEIQ | U2 | WSON-8_L8.0-W6.0-P1.27-TL-EP | C97522
TPS563201DDCR | U3 | SOT-23-6_L2.9-W1.6-P0.95-LS2.8-BR | C116592
CH224K | U4 | ESSOP-10_L4.9-W3.9-P1.0-LS6.0-TL-EP | C970725
LM74700QDBVRQ1 | U5,U6 | SOT-23-6_L2.9-W1.6-P0.95-LS2.8-BL | C2941042
FM24CL64B-GTR | U7 | SOIC-8_L4.9-W3.9-P1.27-LS6.0-BL | C9829
TJA1051T/3/1J | U8,U9 | SOIC-8_L4.9-W3.9-P1.27-LS6.0-BL | C38695
AW9523BTQR | U11,U12 | AW9523BTQR | C148077
TYPE-C-31-M-12 | USBC1 | USB-C_SMD-TYPE-C-31-M-12_1 | C165948
25MHz | X1 | CRYSTAL-SMD_4P-L3.2-W2.5-BL | C9006

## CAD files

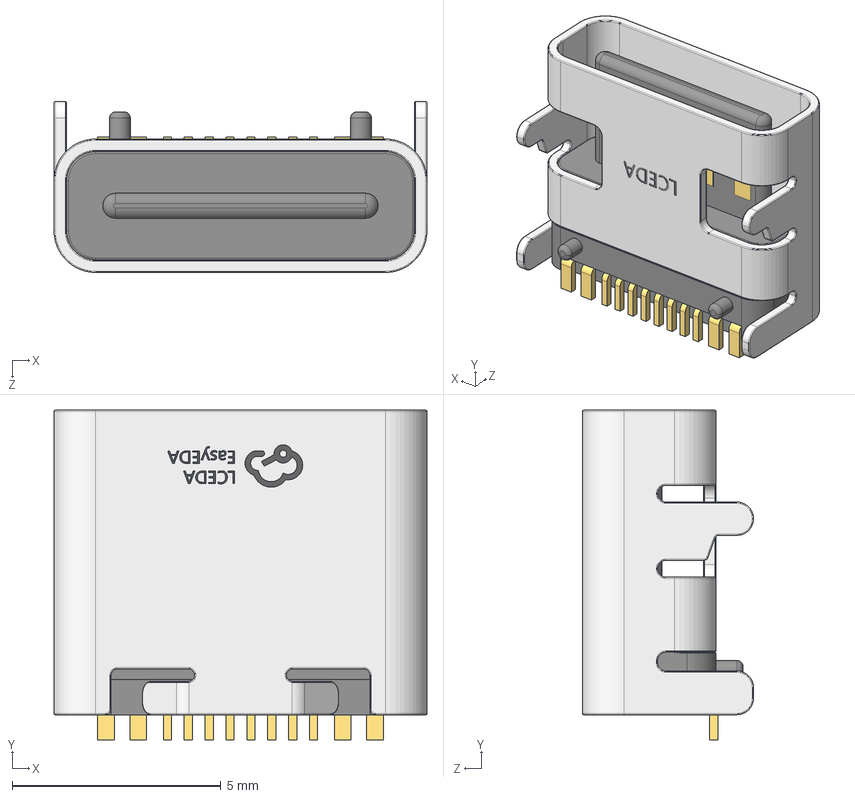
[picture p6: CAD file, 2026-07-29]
kicad/board3/EASYEDA_MODELS/USB-C_SMD-TYPE-C-31-M-12_1.step
8.94 x 7.90 x 4.10 mm

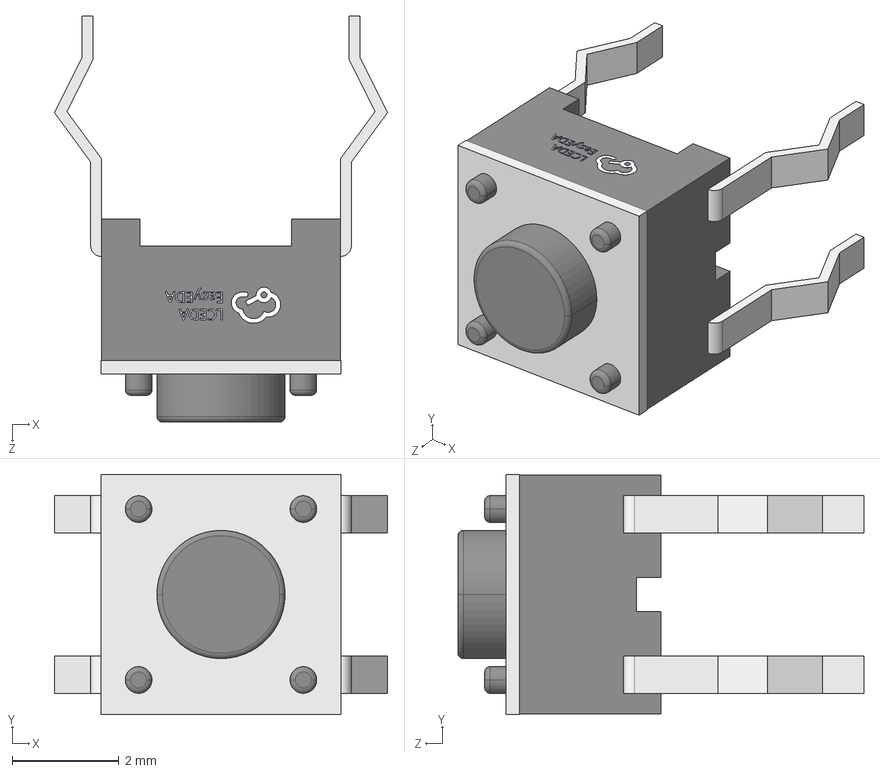
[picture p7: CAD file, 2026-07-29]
kicad/board3/EASYEDA_MODELS/SW-TH_4P-L4.5-W4.5-P3.00-LS5.4.step
6.23 x 4.50 x 7.60 mm

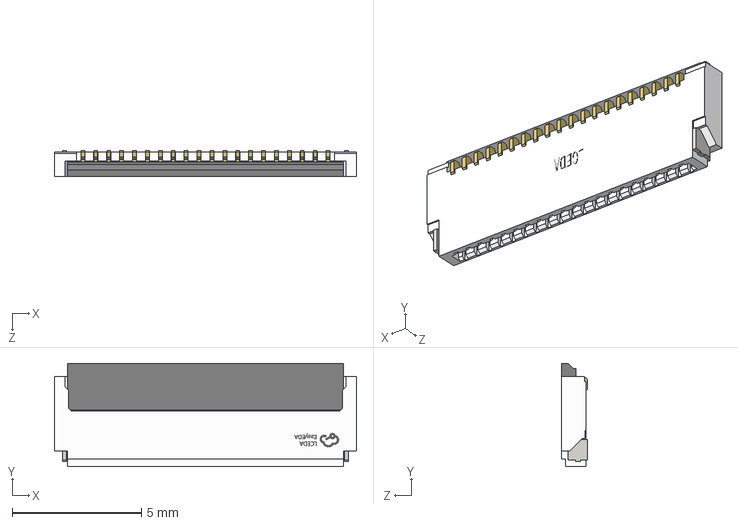
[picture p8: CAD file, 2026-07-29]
kicad/board3/EASYEDA_MODELS/FPC-SMD_5034802000.step
11.7 x 4.00 x 1.01 mm

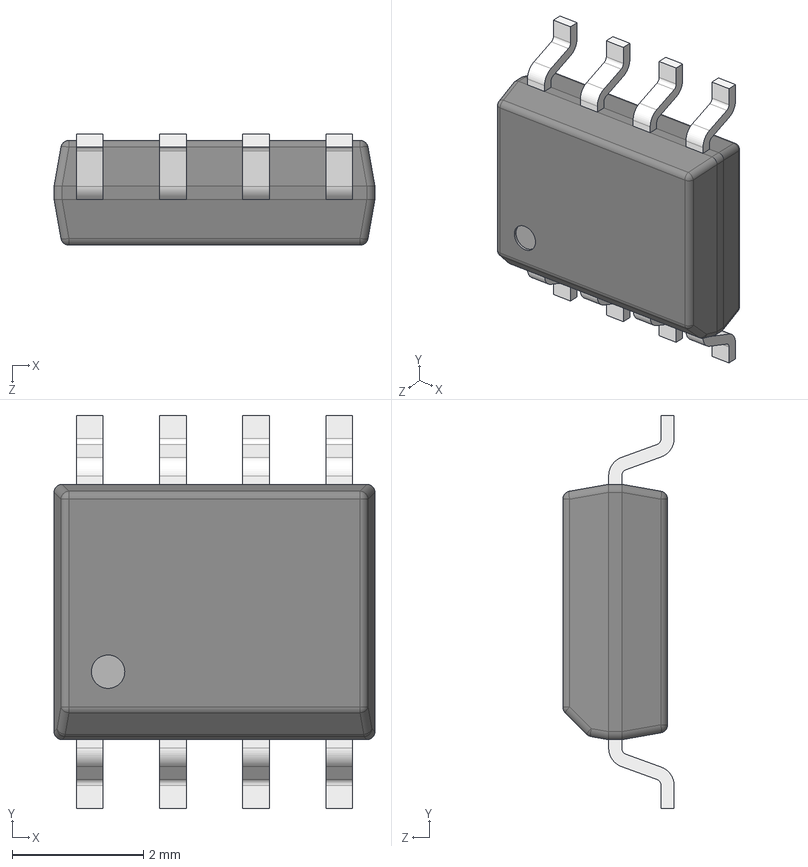
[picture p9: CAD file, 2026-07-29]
kicad/board3/EASYEDA_MODELS/SOIC-8_L4.9-W3.9-H1.7-LS6.0-P1.27.step
4.90 x 6.00 x 1.70 mm

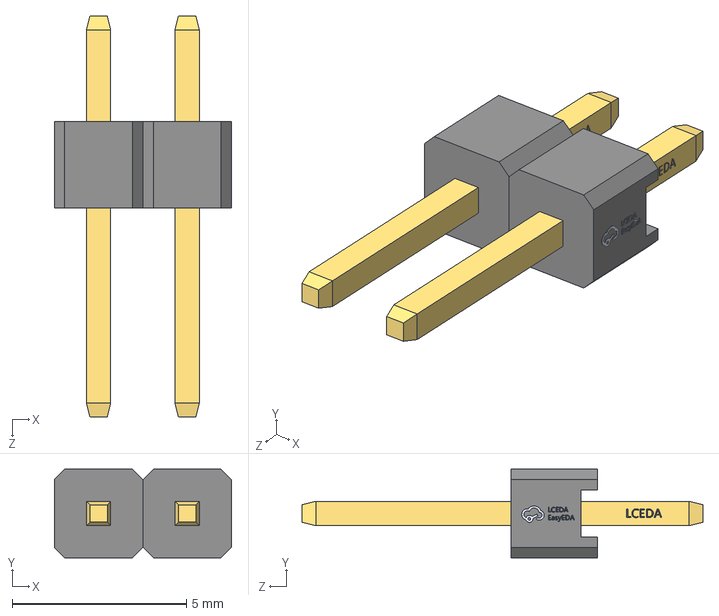
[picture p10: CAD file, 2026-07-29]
kicad/board3/EASYEDA_MODELS/HDR2.54-M-LI-1X2P.step
5.09 x 2.54 x 11.5 mm

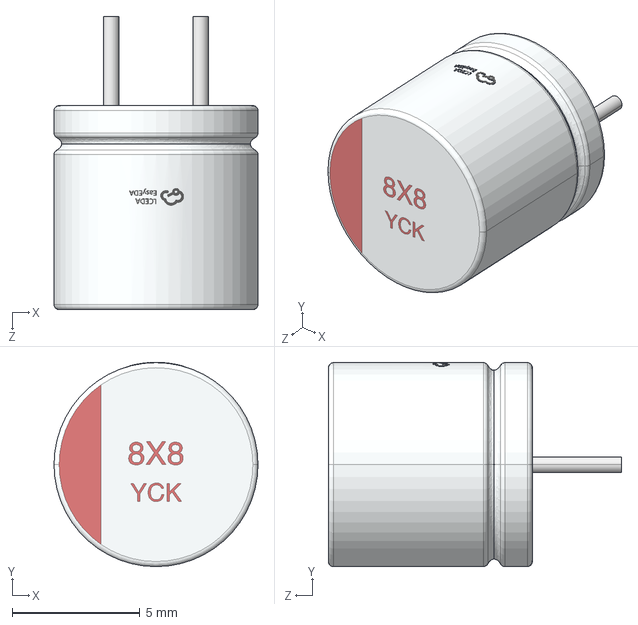
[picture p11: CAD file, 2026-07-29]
kicad/board3/EASYEDA_MODELS/CAP-TH_D8.0-H8.0-P3.50.step
8.00 x 8.01 x 11.5 mm

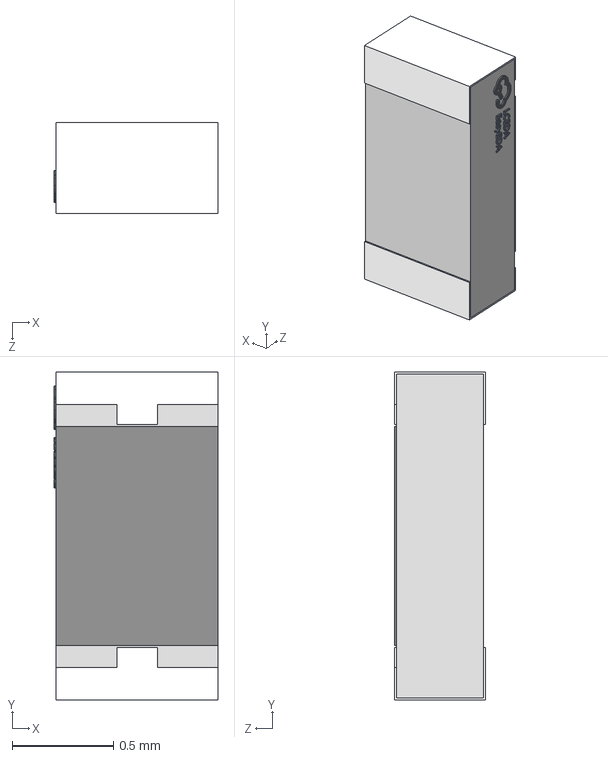
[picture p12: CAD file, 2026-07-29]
kicad/board3/EASYEDA_MODELS/R0603.step
0.81 x 1.62 x 0.45 mm

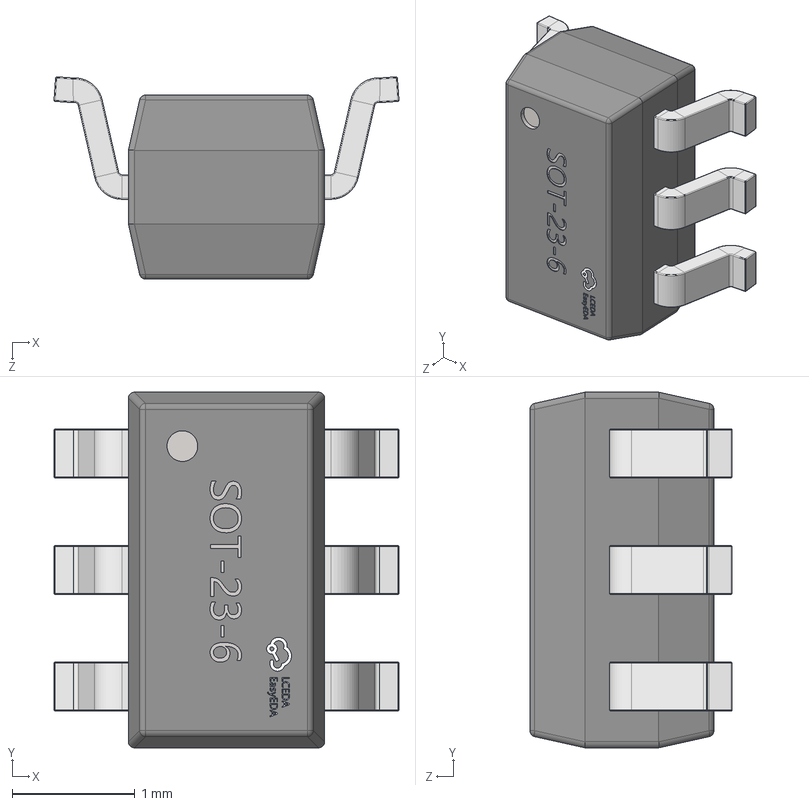
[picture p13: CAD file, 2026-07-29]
kicad/board3/EASYEDA_MODELS/SOT-23-6_L2.9-W1.6-H1.5-LS2.8-P0.95.step
2.81 x 2.90 x 1.65 mm

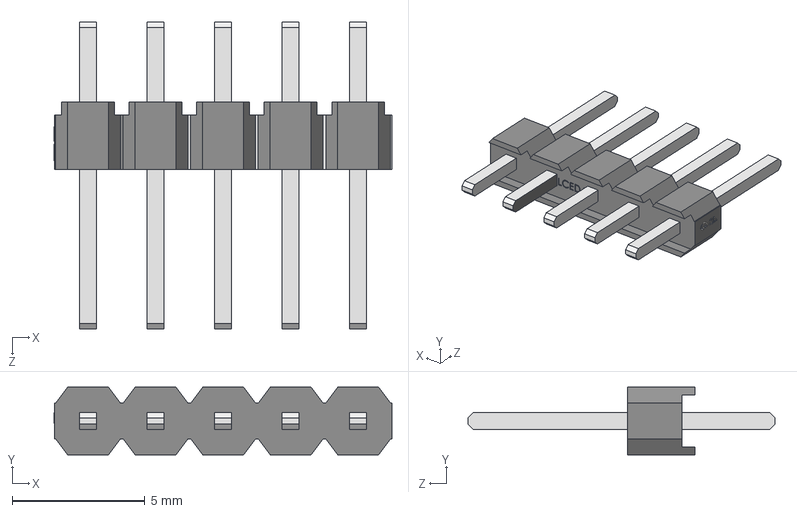
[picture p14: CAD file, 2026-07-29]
kicad/board3/EASYEDA_MODELS/HDR-TH_5P-P2.54-M-LI-1X5P.step
12.7 x 2.54 x 11.5 mm

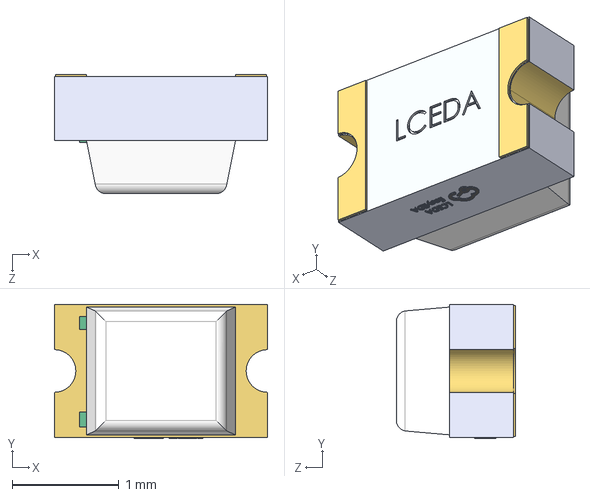
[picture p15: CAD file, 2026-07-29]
kicad/board3/EASYEDA_MODELS/LED0805-RD_ORANGE.step
2.00 x 1.26 x 1.12 mm

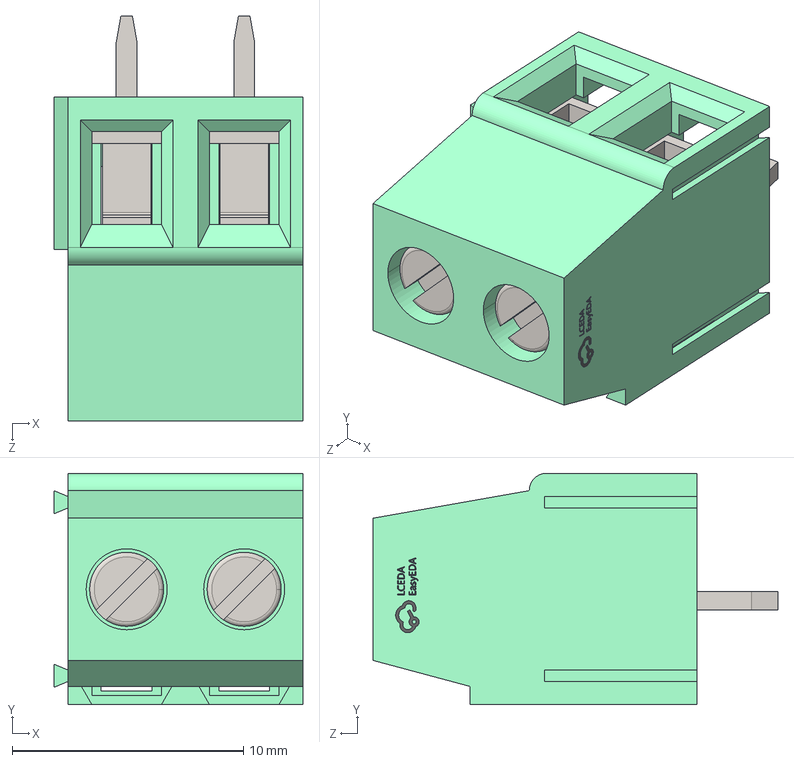
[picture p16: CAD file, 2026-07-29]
kicad/board3/EASYEDA_MODELS/CONN-TH_2P-P5.00_WJ500V-5.08-2P.step
10.8 x 10.0 x 17.5 mm

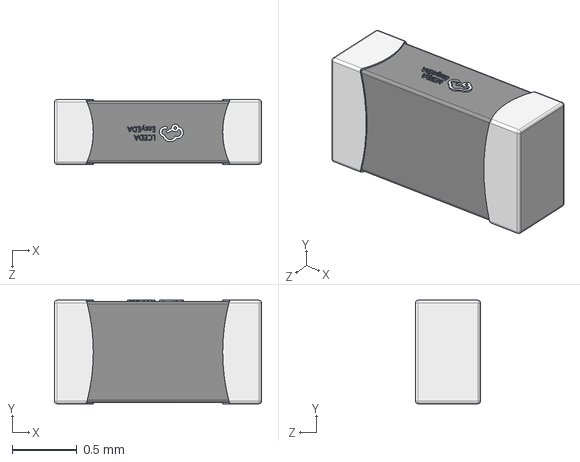
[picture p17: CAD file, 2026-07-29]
kicad/board3/EASYEDA_MODELS/L0603_L1.6-W0.8-H0.5_BEAD.step
1.60 x 0.8 x 0.5 mm

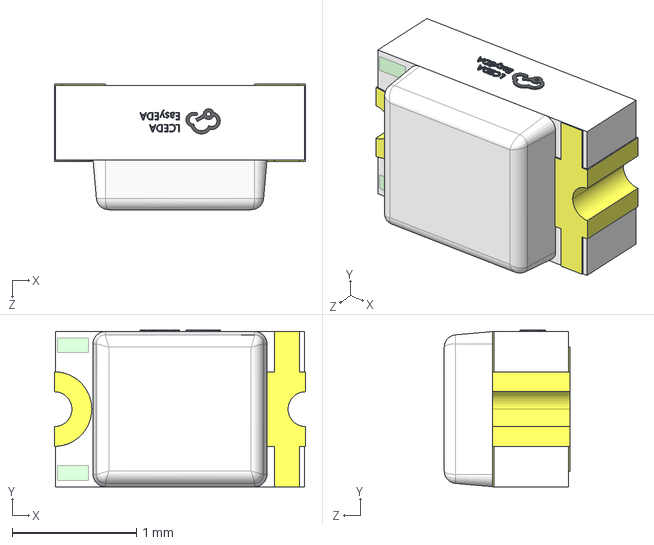
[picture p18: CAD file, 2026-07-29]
kicad/board3/EASYEDA_MODELS/LED0805-RD.step
2.02 x 1.26 x 1.01 mm

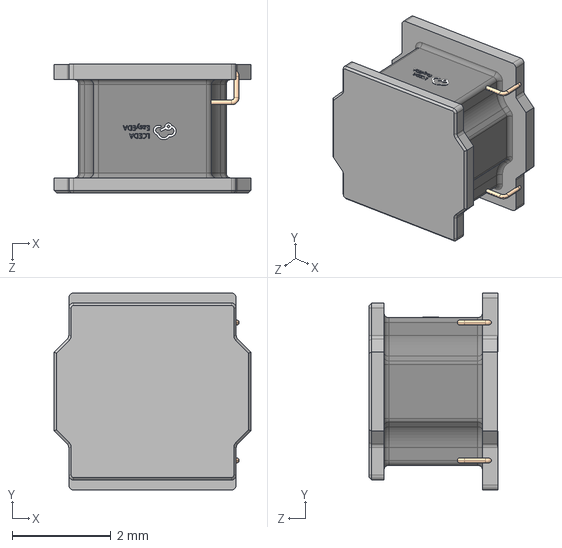
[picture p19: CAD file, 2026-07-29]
kicad/board3/EASYEDA_MODELS/IND-SMD_L4.0-W4.0-H2.6_FNR40XXS.step
4.00 x 4.00 x 2.61 mm

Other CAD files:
kicad/board3/EASYEDA_MODELS/DC-IN-TH_DC-005-2.step
kicad/board3/EASYEDA_MODELS/LQFP-144_L20.0-W20.0-P0.50-LS22.0-BL.step
kicad/board3/EASYEDA_MODELS/SOIC-18_L11.6-W7.5-H2.7-LS10.3-P1.27.step
kicad/board3/EASYEDA_MODELS/CRYSTAL-SMD_4P-L3.2-W2.5-BL.step
kicad/board3/EASYEDA_MODELS/ESSOP-10_L4.9-W3.9-P1.0-LS6.0-TL-EP.step
kicad/board3/EASYEDA_MODELS/SOP-8_L5.0-W3.8-P1.27-LS6.0-BL.step
kicad/board3/EASYEDA_MODELS/WSON-8_L8.0-W6.0-P1.27-TL-EP.step

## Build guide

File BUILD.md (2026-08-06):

# How the firmware is built

The firmware targets **STM32** and builds with **PlatformIO**. There is one
build path, and both the CLI and the VS Code buttons drive it.

```bash
./scripts/compile.sh                 # default env: nucleo_f767
./scripts/compile.sh h743            # the H755 carrier target
./scripts/compile.sh nucleo_f767 -v  # extra args pass through to pio
```

`scripts/compile.sh` is a thin wrapper around `pio run -e <env>`; it locates
PlatformIO in its own venv (`~/.platformio/penv`) and falls back to whatever
`pio` is on PATH. Override with `PIO=/path/to/pio` if yours lives elsewhere.

## Environments

| env | Board | Why it exists |
|---|---|---|
| `nucleo_f767` | NUCLEO-F767ZI | The three-panel mule. Cortex-M7 like the carrier, 2 MB flash, six SPI peripherals, onboard ST-LINK. Serial rides the ST-LINK VCP. **Default.** |
| `h743` | WeAct MiniSTM32H743VITX | Same silicon family as the custom carrier, so the devkit doubles as a firmware mule until the PCB exists. Serial on the USB-C VCP. |
| `riverdi_f469` | Riverdi F469 eval | Panel-integrated eval board, used for validating a panel independently of our wiring. |

PlatformIO resolves the toolchain and the STM32 Arduino core itself — nothing to
install by hand, no sketchbook to sync. `src_dir = MustangDash` keeps the `.ino`
layout; `lib_extra_dirs = libraries` uses the **vendored** EVE library rather
than the registry copy, because `src/EVE_config.h` selects the `EVE_RVT70H`
profile and `src/EVE_target/` carries our pins.

## Running the tests on Windows

`tests/run-tests.sh` compiles the host-side invariant tests with `gcc`, which
Git Bash does not provide. On Windows, run them through WSL:

```bash
wsl -- bash -lc "./tests/run-tests.sh"      # from the repo root
```

`wsl` inherits the Windows working directory as `/mnt/c/...`, so no `cd` is
needed. VS Code task **"Tests: invariant suite"** does exactly this, and runs
the script directly on macOS/Linux.

The trap worth knowing:

- **CRLF.** Git's `core.autocrlf=true` (Windows default) checks `.sh` files out
  with CRLF. Git Bash tolerates the trailing `\r` in a shebang; WSL's bash does
  not, and fails with ``/usr/bin/env: 'bash\r': No such file or directory``.
  `.gitattributes` pins `*.sh` to `eol=lf` to prevent this. Don't remove it —
  and note that writing a `.sh` file with a Windows text editor or a Python
  script that doesn't force `newline="\n"` reintroduces it.

## Flash budget

The splash asset pack dominates the image. As of 2026-08-05 the `nucleo_f767`
build sits at **1,819,568 B of 2,097,152** (86.8%), RAM 8,088 B of 524,288
(1.5%). The pack ships all three themes; gating it on `SPLASH_THEME` at build
time would reclaim a large fraction if flash gets tight.

## Notes

- The `.ino` declares every function before use. PlatformIO does its own
  prototype generation, so this is belt-and-braces — but it keeps the file
  readable top-to-bottom and costs nothing.
- Host tests never touch a board, a toolchain, or the network. They pin the
  display profile, the control pins, the backlight wave, the splash timeline,
  the dash math/sim/serial/odometer logic, the font format, the flash-pack
  layout, the button gestures and the telltale calibration. Run them after
  touching `EVE_config.h`, the STM32 target header, or any `MustangDash/*.h`
  pure header.

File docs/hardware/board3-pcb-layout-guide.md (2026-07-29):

# Board3 PCB Layout Guide (U8)

Companion to `board3-h755-pin-map.md` and the U8 unit in
`docs/plans/2026-07-24-001-feat-board3-h755-carrier-plan.md`.
Written 2026-07-26, before the layout pass.

## 0. Stackup — use 4 layers

A 144-pin LQFP with QUADSPI, USB, and two CAN buses is not a 2-layer board.
JLC 4-layer is cheap and buys the single most valuable thing here: an
uninterrupted ground plane directly under every fast signal.

| Layer | Use |
|---|---|
| L1 (top) | components + short signal escapes, all three SPI buses |
| L2 | **solid GND pour — never split, never route through it** |
| L3 | power pours: +5V region and +3V3 region |
| L4 (bottom) | secondary routing, remaining GND pour, stitched to L2 |

KTD6 says one continuous ground bonded with stitching vias. On 4 layers that
means L2 is the reference for everything, and L4's pour is stitched to it
every ~10 mm and around the board edge.

## 1. Placement order

Place in this order. Each step locks constraints for the next, so resist
jumping ahead.

**Step 1 — mechanical, edge-driven (these barely move afterward):**
1. Board outline + mounting holes
2. **FPC1 / FPC2 / FPC3** along the panel-facing edge, in physical
   left–center–right order matching the real cluster
3. Barrel jack DC1 and USB-C (USBC1) on the opposite/user edge
4. CAN terminals P1, P2 on an accessible edge
5. LED1–LED8 along a visible edge, evenly spaced, in telltale order
6. Buttons SW1–SW4 and NRST/BOOT0 (SW6/SW7) reachable
7. SWD header H2 + TC2030 land pattern where a probe can sit

**Step 2 — the MCU; orientation is the whole game:**
8. **U1** in the center. Rotate it so each SPI cluster faces its own panel:
   - PA5/PA6/PA7 (SPI1, center) toward FPC2
   - PB13/PB14/PB15 (SPI2, left) toward FPC1
   - PE2/PE5/PE6 (SPI4, right) toward FPC3

   Getting this right removes most of the routing difficulty. If a rotation
   makes two buses cross, try another before accepting it — and remember
   KTD1 lets you swap which SPI peripheral serves which panel if that routes
   cleaner. Firmware follows the board.

**Step 3 — anything that must hug a specific pin:**
9. **C3/C4/C5 (VCAP)** — one per VCAP pin (68/103/140), ≤5 mm, each with its
   own ground via. These are not generic decoupling; they stabilize the
   internal regulator.
10. **100 nF decoupling** — one per VDD pin, same side as the MCU, shortest
    possible loop pin→cap→via→L2. Place these before any routing.
11. **X1 + C41/C42** — as close to PH0/PH1 as physically possible, ground the
    two case pads locally, keep a ground guard around it, and route nothing
    under the crystal on any layer.
12. **L1 + C40 + C37** (VDDA filter) — bead first in the feed, caps at the pin.
13. **C46** at NRST, **R1** at BOOT0.
14. **C51/C52** at the buck (see §2), **C50** at the CH224K.

**Step 4 — blocks that follow their anchor:**
15. Buck U3 + L2 + C48/C49 + R3/R2 (§2)
16. Ideal-diode ORing: U5/Q1 and U6/Q2 between the two inputs and the +5V rail
17. NOR U2 near the PF6–PF9 / PB2 / PG6 cluster; FRAM U7 near PB10/PB11
18. CAN transceivers U8/U9 between the MCU's FDCAN pins and their terminals;
    termination network + jumper right at each transceiver
19. ULN2803 U10 between the MCU lamp pins (PD0–PD7) and the LED row
20. Bulk electrolytics near where current enters/leaves; test points last

## 2. The three circuits that punish sloppy layout

**Buck (TPS563201) — the hot loop.** The loop that matters is:
input cap → VIN pin → internal FET → SW pin → inductor → output cap → GND →
back to input cap. Keep that loop physically tiny.

- C51 (10 µF in) directly across VIN/GND pins, closer than anything else
- SW node copper **as small as possible** — it is the switching-noise
  radiator; wide enough for current, no larger
- C52 (VBST) tight between VBST and SW
- FB divider (R3/R2) away from the SW node; take the top of the divider from
  the **output cap terminal**, not the inductor pad, and route FB as a quiet
  trace hugging ground
- L2 inductor close to SW, output caps C48/C49 immediately after

**USB (D+/D−).** Route as a 90 Ω differential pair: short, tightly coupled,
matched, no stubs, no vias if avoidable, solid L2 ground the whole way.
D9 (USBLC6) goes **right at the connector**, before the pair runs anywhere —
ESD protection placed after the trace defeats the point. Compute the pair
geometry against JLC's actual stackup rather than guessing.

**CAN (H/L).** Differential pair from transceiver to terminal, kept together.
Split termination (60.4 Ω + 60.4 Ω + 4.7 nF) sits **at the transceiver**, with
the jumper in the leg. Keep the stub from the pair to the connector short.

## 3. Power distribution — sized, not guessed

The +5V rail feeds three backlights plus the telltales, and it is a
pass-through rail (no regulation between the jack and the panels).

| Path | Current | Copper |
|---|---|---|
| Input (jack/USB) → ideal diodes → +5V | ~1.5–2 A | pour or ≥60 mil |
| +5V → each FPC backlight pin | ~0.15–0.25 A | ≥20 mil |
| +3V3 → MCU/panels | ~0.8 A | pour or ≥30 mil |
| Signals | — | 6–8 mil |

KTD6 is explicit that the backlight return must ride the ground pour, not a
thin trace. Each FPC's ground pins get **multiple vias straight down to L2 at
the connector** — this is the exact failure that cost a bench night (the
shared-ground IR-drop learning in `docs/solutions/`); do not economize here.

The ideal-diode FETs (Q1/Q2) carry the full rail: wide copper on both source
and drain. The LM74700 senses the FET's own drop, so land the controller's
ANODE/CATHODE connections on the FET pads, not upstream.

## 4. Signal routing rules

- **SPI**: short, roughly length-matched per bus, over unbroken L2. The 33 Ω
  series resistors (R32–R37) go **at the MCU pin**, not near the connector —
  they damp the driver, so they must sit within a few mm of the output.
- **QUADSPI**: keep the six nets as a group, similar lengths, short. R9 (33 Ω)
  at the MCU clock pin.
- **Crystal**: shortest possible, guarded, nothing routed underneath.
- **No signal may cross a plane split.** With a solid L2 this is automatic —
  which is the reason for 4 layers.
- Keep the buck's SW node and inductor away from the crystal, the USB pair,
  and the QUADSPI group.

## 5. Verification before ordering (U9)

1. `tools/kicad_verify.py <board> --baseline <import>` reports NEW = 0 against
   JLC's rule set — the imported board carries 41 violations no layout work
   removes, so the bar is no new violations, not zero
2. Every FPC ground pin has ≥2 vias to L2
3. Visually trace the buck loop and confirm it is small
4. Confirm no trace crosses a plane gap
5. Silkscreen: every R/C/IC carries its value or model number on its own
   footprint body (standing project rule), plus polarity marks, pin-1 marks,
   connector labels, and the CAN termination jumper legend
6. Update `board3-h755-pin-map.md` to the **as-routed** table — after layout
   freeze the firmware pin constants are written from that document (KTD1)

## Related

- [Board3 pin map](board3-h755-pin-map.md)
- [Board3 carrier plan](../plans/2026-07-24-001-feat-board3-h755-carrier-plan.md)

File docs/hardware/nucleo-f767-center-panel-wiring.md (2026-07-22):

# NUCLEO-F767ZI — Center 7" Panel Setup & Wiring Guide

Bench guide for first light on the NUCLEO-F767ZI driving the center RVT70H
(7" 1024x600, BT817) over SPI1. Executes U3 of
`docs/plans/2026-07-21-002-feat-f767-first-light-plan.md`; the sides come
later (appendix). Board authority for anything not covered here:
`docs/hardware/datasheets/um1974-nucleo-144-mb1137.pdf` (UM1974 — many board
variants; read only NUCLEO-F767ZI rows/columns).

## 1. Jumper check (before anything else)

Factory defaults — verify, don't move (UM1974 §3 out-of-box config):

| Jumper | Position | Meaning |
|---|---|---|
| JP3 | pins 3-4 (U5V) | powered from ST-LINK USB |
| JP1 | OFF | 300 mA declared at USB enumeration |
| JP5 (IDD) | ON | MCU power measurement bridge closed |
| CN4 (x2) | both ON | ST-LINK programs the on-board MCU |

Nothing moves tonight unless power Plan C fires (below). CN4 comes off only
when using the CN6 SWD connector to program an external target — not tonight.

## 2. Workstation + board setup (U2 gates, no panel attached)

1. Install the ST-LINK USB driver: **STM32CubeProgrammer** preferred (bundles
   driver + JRE + firmware updater), or bare STSW-LINK009. No separate VCP
   driver needed on Windows 11.
2. Plug the Nucleo into a **root USB port** (no hub).
3. Run the ST-LINK firmware update once (CubeProgrammer → Firmware upgrade).
   **Skippable** if the updater won't launch — proceed to upload and come
   back only if OpenOCD misbehaves.
4. `pio run -e nucleo_f767 -t upload` (default `upload_protocol = stlink`).
5. Open the VCP COM port at 115200. Expect the boot banner; `status` must ack
   `ok` with **no panel attached** (missing panels retire; dash runs headless).

Gate: do not wire the panel until step 5 passes.

## 3. Wiring table (power off, USB unplugged)

Breakout pad N = RiBus pin N (MTCELL FPC-20P, verified by continuity on the
center breakout — re-verify pad-frame vs pad 20 on any breakout not
previously bench-tested). FFC contacts face **down** at the panel end.

| Signal | MCU pin | Zio label | Connector pin | Breakout pad | Wire |
|---|---|---|---|---|---|
| SCLK | PA5 | D13 | CN7 pin 10 | 3 | |
| MISO | PA6 | D12 | CN7 pin 12 | 4 | |
| MOSI | PB5 | D22 | CN7 pin 13 | 5 | |
| CS | PF13 | D7 | CN10 pin 2 | 6 | |
| PD/RST | PF14 | D4 | CN10 pin 8 | 8 | |
| Panel VDD 3.3 V | — | +3V3 | CN8 pin 7 | 1 | |
| Panel GND | — | GND | CN7 pin 8 (or CN8 pin 11) | 2 | |
| INT | — | — | not connected (we poll) | 7 | — |
| BL+ (backlight 5 V) | — | per power plan below | — | 17 **and** 18 | doubled |
| BL− (backlight return) | — | per power plan below | — | 19 **and** 20 | doubled |

**Zio diagram reading trap (cost us a double-take at the bench):** ST's Zio
pinout diagram prints TWO label columns per side — ST name + Arduino name
both describing the SAME pin. Power pins repeat the name ("+5V +5V"),
which reads as if the adjacent even pin were also +5V. It is not: CN8 has
exactly one +5V (pin 9); pins 10/12 are GPIOs **PC12/PD2 — and PD2 is
telltale lamp 5 in this build**, so landing backlight return there would
fight a driven output. Doubling: BL+ x2 joined into CN8-9; BL− split
across CN8-11 and CN8-13 (both GND).

Pin facts verified 2026-07-21 against UM1974 + STM32duino
`variant_NUCLEO_F767ZI`. All five signal pins are free of on-board functions
(Ethernet RMII, LEDs, USB, VCP all elsewhere). PB5 at D22 is a direct
connection — no solder-bridge work (SB121/SB122 only affect D11, unused).

**Before any power:**

- Beep pads **19-20 (BL−) to pad 2 (GND)** — continuity proves which FFC end
  is the backlight end (the RiBus ties BLGND to logic GND internally).
- If this breakout is untested: beep panel frame to pad 20 (should beep) and
  pad 1 (should stay silent).
- Visually check the FFC ends for damage (a damaged end shorting pins 1-2 =
  VDD-GND short; symptom: board won't enumerate on USB).

## 4. Backlight power — tiered plan (fastest first)

**Plan A — single cable, try first:** BL+ (pads 17-18) → Nucleo **+5V, CN8
pin 9**; BL− (pads 19-20) → **GND, CN8 pin 11**. Everything runs off the one
ST-LINK USB cable.

- The USB/5V budget is 500 mA total (regulator U6 limit; red **LD5** = over
  500 mA). Boot pushes the backlight to **full duty at the crossfade** — that
  exact moment is where Plan A fails if it's going to.
- Failure signatures: LD5 lights, or the board browns out — possibly as a
  **repeating boot loop** (reset → splash → crossfade → reset) with the VCP
  COM port dropping and re-enumerating each cycle. Non-destructive.

**Plan B — on any Plan A failure:** move **only** BL+/BL− to the bench buck
at 5.00 V; tie buck GND to a Nucleo GND (common ground). Logic stays USB-fed.
This is the Teensy rig's proven arrangement, and it removes the backlight
from the board's budget entirely.

**Plan C — only if USB power is flaky for the board itself** (resets with the
backlight already on Plan B): 7-12 V into **VIN, CN8 pin 15**, move **JP3 to
pins 5-6**, JP1 stays OFF. **Mandatory order: external supply ON first, USB
plugged after** (UM1974 §6.4.3). USB stays connected for ST-LINK + VCP.
(E5V exists but its pin is on the unpopulated morpho CN11 — soldering
required; not tonight's path.)

## 5. Power-up and first-light gates (U4)

In order; stop at the first failing gate:

1. Power up. VCP enumerates, boot banner prints.
2. `REG_ID` reads `0x7C` (in the boot diagnostics).
3. Splash plays **from RAM_G** — staging summary line clean, no miscompare
   lines — then crossfades into the dash; gauges animate from the simulator;
   `status` acks. **Eyes on the panel:** the picture must match the known
   dash look (serial health cannot see render corruption).
4. Clock walk (optional tonight): note that the F767's SPI1 can only produce
   **6.75 / 13.5 / 27 / 54 MHz** (216 MHz core, APB2 108 MHz, power-of-two
   prescalers) — the firmware's "8 MHz" request actually runs at **6.75 MHz**
   (safe: EVE_init needs < 11 MHz). The only raises are 13.5 then 27 MHz;
   accept a step only on clean staging spot-checks + `REG_ID` + font-verify
   reads **and** an eyes-on-panel check — never frame rate. Record the
   attained (not requested) frequency.

## 6. Panel-flash wipe (after first light only — U5)

When first light has passed and the `flashwipe` command is flashed: run it
with its confirmation argument. **Expect minutes of total silence** (64 MB
chip erase: typically 2-3+ min; the dash freezes and serial says nothing).
**Do not power-cycle during the wipe** — `ok` is the completion signal. A
power cycle afterward must boot identically (boot never touches panel flash).

## Appendix — side panels (three-panel night, not tonight)

From the committed pin plan in `MustangDash/MustangDash.ino` (Zio positions
for these pins not yet verified against UM1974 — verify before wiring):

| Panel | SPI | MOSI | MISO | SCLK | CS | PD |
|---|---|---|---|---|---|---|
| Left 5" | SPI2 | PB15 | PC2 | PB10 | PE9 | PE13 |
| Right 5" | SPI4 | PE6 | PE5 | PE2 | PE11 | PF15 |

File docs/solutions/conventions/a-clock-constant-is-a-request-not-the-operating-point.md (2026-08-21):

---
title: A clock constant is a request, not the operating point
date: 2026-08-21
category: conventions
module: spi-bus
problem_type: convention
component: development_workflow
severity: high
root_cause: missing_tooling
resolution_type: tooling_addition
applies_when:
  - walking a clock, baud or timer rate to a new operating point and about to record the result
  - a peripheral derives its rate by dividing a kernel clock the firmware never explicitly configures
  - two instances of one peripheral family sit on different kernel-clock sources (STM32H7 SPI1/2/3 on PLL1Q, SPI4/5 on APB2)
  - a soak is about to accept a hardware setting by the number that was requested rather than one read back
  - adding a diagnostic to settle a question -- baseline it at the unchanged setting first
symptoms:
  - A constant, the working notes and a bench acceptance record all cite a rate no instrument ever measured
  - The requested value is not a reachable point on the divider ladder, so it reads as a plausible neighbour of a number that is
  - An earlier note on different silicon already recorded an actual clock below the requested one, and nobody generalised it
related_components:
  - dash-panels
  - board3-carrier
  - stm32h7-hal
  - dash-serial
tags:
  - spi
  - clock-walk
  - stm32h7
  - prescaler
  - readback
  - measurement
  - bt817
  - board3
---

# A clock constant is a request, not the operating point

## Context

Board3 drives three BT817 panels from three independent SPI peripherals on one
STM32H755: center on SPI1, left on SPI2, right on SPI4
(`MustangDash/MustangDash.ino:164-169`). Every panel inits at a conservative
8 MHz *request* — which is itself **6.25 MHz attained** on all three, the bottom
rung of the very ladder this document is about, and a rate nothing has ever read
back either. Once all three inits are done the sketch raises each bus exactly once to a single constant,
`DASH_SPI_RUN_HZ` (`MustangDash/MustangDash.ino:943-944`).

That constant read `13500000UL` from 2026-07-21 (the commit accepting the F767
bench walk, `feat(f767): accept 13.5 MHz operating point from bench clock walk`)
until 2026-08-21. For that whole month the number 13.5 MHz was written down
three times as a *proven* operating point: in the constant's own comment, in
`CLAUDE.md`'s Hardware-truths SPI bullet ("now **13.5 MHz** … proven 2026-07-23
on TWO panels at fps 59, faults 0"), and in `docs/hardware/board3-bringup-card.md`
as the "13.5 MHz SPI clock re-walk" bring-up debt item.

On Board3 the panels were attaining **12.500 MHz**. Nothing in the tree had ever
read the rate back out of the peripheral, so nothing could say so.

The mechanism has two halves, and both are ordinary — which is the point.

**Half one: the driver rounds the request DOWN.** `SPISettings(hz, …)` reaches
`spi_init()` in the STM32 Arduino core, which walks a fixed prescaler ladder and
takes the first rung whose resulting rate is at or below the requested speed
(`~/.platformio/packages/framework-arduinoststm32/libraries/SPI/src/utility/spi_com.c:265-287`;
the `SPI_SPEED_CLOCK_DIV*_MHZ` macros are divisors, not megahertz —
`spi_com.h:46-53`). Prescalers are powers of two, 2 through 256, stored as the
exponent in the `CFG1.MBR` field, so attained = kernel >> (MBR + 1).

**Half two: the divider's source is not one clock.** `spi_com.c` picks the
kernel clock per instance: SPI1/2/3 resolve through `RCC_PERIPHCLK_SPI123`,
SPI4/5 through `RCC_PERIPHCLK_SPI45` (`spi_com.c:46-108`). This sketch's
`SystemClock_Config` configures exactly one peripheral mux — USB
(`MustangDash/MustangDash.ino:323-325`) — and never touches the SPI muxes, so
the H7 reset defaults stand, and the defaults are **asymmetric**: selector value
0 means `RCC_SPI123CLKSOURCE_PLL` (pll1_q) for SPI1/2/3 and
`RCC_SPI45CLKSOURCE_D2PCLK2` (APB2) for SPI4/5
(`stm32h7xx_hal_rcc_ex.h:1058,1117`). On Board3 that resolves to **PLL1Q at
200 MHz** (`PLLQ = 4` off an 800 MHz VCO, `MustangDash.ino:302`) for center and
left, and **APB2 at 100 MHz** (AHB 200 / `RCC_APB2_DIV2`,
`MustangDash.ino:315,317`) for right.

Run the arithmetic the driver runs:

| request | center SPI1 (200 MHz) | left SPI2 (200 MHz) | right SPI4 (100 MHz) | attained |
|---|---|---|---|---|
| 13.5 MHz | /16 | /16 | /8 | **12.500 MHz** |
| 25.0 MHz | /8 | /8 | /4 | **25.000 MHz** |

13.5 MHz was never a point on Board3's ladder. The reachable set is
6.25 / 12.5 / 25 with **nothing between**, and 50 above — which is invisible
while you reason in terms of the requested number, because 13.5 and 12.5 look
like neighbours rather than like a wish and a fact.

The sharpest part is that the 13.5 was not sloppy when it was written. On the
F767 mule it was walked, soaked and genuinely attained: APB2 there is 108 MHz and
108/8 = 13.5 exactly, on the quantised F767 ladder 6.75 / 13.5 / 27 / 54. And the
F767 was **already a two-kernel board** — SPI1 off APB2 at 108 MHz, SPI2 off APB1
at 54 MHz, where 54/4 = 13.5 as well. A 2:1 power-of-two ratio hid the asymmetry
there for precisely the reason it hides it on Board3, so the precedent for this
whole finding sat in the tree a month early, in a one-line comment, correct and
unread. The number was a measured operating point on the
silicon it was measured on, and it silently became a **wrong label** the moment
the same firmware moved to a die with a different clock tree. An operating point
is a property of *constant × clock tree*, not of the constant.

## Guidance

**1. Treat any configured rate that hardware quantises as a request, and read
the achieved value back from the peripheral before you write it down.** This
applies to SPI prescalers, PWM dividers, UART baud (fractional or otherwise),
ADC sample clocks, I2C timing, and anything else where a driver accepts a
frequency in hertz and then picks a divider. The number you passed in is a wish.
The register field is the fact. Documentation, acceptance soaks, PR titles and
`CLAUDE.md` bullets must cite the fact.

**2. When the divider's source clock is not explicitly configured, "the bus
speed" may not be a single number at all.** Reset-default peripheral clock muxes
can differ per instance. Report the attained rate **per instance**, never once
for "the bus", and print the kernel clock alongside it so the reader can see
which tree each instance is hanging off.

**3. Baseline the instrument before you move the thing it measures.** This is
the step that actually produced the finding. The readback function and the
`diag` command were flashed **alone**, with `DASH_SPI_RUN_HZ` unchanged, before
any clock step. That run is what printed 12.5 against a tree that said 13.5. Had
the instrument and the clock change shipped in one flash, the first reading
would have had nothing to be compared against, the 12.5 would have been read as
"25 didn't take" or simply as the new normal, and a month-old documentation
error would have been overwritten rather than discovered. A measurement's first
job is to reproduce the state you believe you are already in.

**4. Make the diagnostic reachable at runtime, not only at boot.** Board3's boot
banner races CDC enumeration — the sketch waits 500 ms for `Serial` and then
prints regardless — so a boot-only line is a diagnostic you can only see by
winning a race. `dash_report_spi_clocks()` therefore prints in both places: at
the raise (`MustangDash.ino:952`) and on the `diag` serial command
(`MustangDash.ino:1807`).

**5. Gate the operating point on read integrity, not on frame rate.** fps and
the fault counter have already fooled this project once: at 24 MHz on the Teensy
loom, writes mostly survived while reads corrupted, and the symptom was a
degraded fps with `faults=0`. `diag` therefore takes 16 `REG_ID` reads per panel
and reports how many returned 0x7C (`MustangDash.ino:1820-1829`).

## Why This Matters

- **An acceptance soak inherits the label you gave it.** The 2026-07-23
  two-panel soak was real evidence; it was evidence for 12.5 MHz on that
  hardware, filed under 13.5. Everything downstream — the CLAUDE.md bullet, the
  bring-up card's debt item, any future "we know 13.5 works, try 27 next"
  reasoning — inherited the wrong number. The data was never wrong; only the
  name on it was, and a name is what the next session actually reads.
- **The coarse ladder was unreadable from the request side.** Believing the bus
  ran at 13.5 made 27 MHz look like "one doubling away" — which is exactly the
  step that hard-wedged the F767. Knowing it runs 12.5 makes the real question
  visible: the only rungs are 25 and 50, and 50 is 167% of the BT817 slave's
  30 MHz rating.
- **The harmlessness of the asymmetric defaults is conditional, and nothing in
  the code enforces the condition.** Center/left at 200 MHz and right at 100 MHz
  agree on the attained rate for every request in **[781.25 kHz, 100 MHz)**
  *because 200:100 is itself a power of two*: the low ladder is the high one
  shifted a rung, so they share every rung except the high ladder's top
  (100 MHz) and the low ladder's bottom (0.390625 MHz) — and those two
  exceptions are exactly the two regions where they diverge. The bound matters
  here only as discipline: this is a document about stated absolutes getting
  inherited, so its own absolute has to carry its limits.
  Break that ratio and one constant yields two different bus speeds: point
  SPI123 at a 150 MHz PLL2P while SPI45 stays on APB2 100 MHz, and a 25 MHz
  request attains 18.75 MHz on center/left and 25.0 MHz on right. That is a
  three-panels-two-clocks bug with no compile error, no runtime error, and no
  symptom except one panel being slower than its siblings. The readback is what
  makes it a visible line of output rather than a mystery.
- **This repo had already written the rule, and prose did not hold it.**
  [`f767-spi-prescaler-quantization-27mhz-hard-wedge.md`](../integration-issues/f767-spi-prescaler-quantization-27mhz-hard-wedge.md)
  was written on 2026-07-21 — the same day the 13.5 constant landed — and its
  prevention section already says, in as many words, *record the attained
  value, never the requested one*. It was correct, it was findable, it was in
  the right category, and it was violated for the next month by the people who
  wrote it. Nothing executed it. That is the generalisation worth carrying out
  of this round: a prevention rule expressed only as prose is itself a request.
  Rules that survive are the ones something runs — a printed line, a test, a
  gate — and the work of compounding a learning is not finished when the rule is
  written, only when it is mechanized. This document is separate from that one
  for the same reason: a rule and the proof of its insufficiency should not be
  the same file.
- **It is a recurrence, not a first sighting.** The F767 first-light record
  already carried "actual SPI clock is 6.75 MHz (8 MHz request rounds down)"
  (auto memory [claude], `f767-first-light-2026-07-21`). The class of error had
  been observed, correctly, once — and then not generalised into a rule or an
  instrument, so it was available to happen again on the next board. Observing a
  trap and building the instrument that catches it are different acts, and only
  the second one compounds.

## When to Apply

- Before writing any clock, baud or sample rate into documentation, a commit
  message, a bring-up card or a design note as an accepted operating point.
- At the start of any clock walk — flash the readback first, unchanged, and
  confirm it reproduces the rate you believe you are already running.
- When the same firmware moves to different silicon, a different variant, or a
  different `SystemClock_Config`: every quantised rate in the tree must be
  re-measured, because the constant did not change and its meaning did.
- When one peripheral family is spread across multiple instances (three SPIs
  here) and the kernel-clock muxes are left at reset defaults.
- When a bench result and a later result disagree by an amount that looks like a
  small percentage — 13.5 versus 12.5 is 7.4%, comfortably inside the range
  where a discrepancy gets rationalised as measurement noise instead of
  investigated as a different rung.

## Examples

**The readback, on Board3** (`MustangDash/MustangDash.ino:775-809`). It asks the
`SPIClass` which peripheral it actually got, resolves the kernel clock through
the same HAL oracle the driver used to pick the prescaler, then reads the
prescaler exponent straight out of the peripheral:

```c
SPI_TypeDef *inst = DASH_SPI_BUSES[b]->getHandle()->Instance;
if (inst == SPI1 || inst == SPI2 || inst == SPI3)
    ker = HAL_RCCEx_GetPeriphCLKFreq(RCC_PERIPHCLK_SPI123);
else if (inst == SPI4 || inst == SPI5)
    ker = HAL_RCCEx_GetPeriphCLKFreq(RCC_PERIPHCLK_SPI45);
else
    ker = HAL_RCCEx_GetPeriphCLKFreq(RCC_PERIPHCLK_SPI6);

const uint32_t mbr = (inst->CFG1 & SPI_CFG1_MBR_Msk) >> SPI_CFG1_MBR_Pos;
const uint32_t div = 1UL << (mbr + 1UL);
```

Output, per panel, at boot and on `diag`:

```
SPI raised to 25.00 MHz requested (prescaler rounds down; read-integrity soak gates the attained operating point)
  SPI center kernel 200000000 Hz / 8 = 25.000 MHz attained
  SPI left   kernel 200000000 Hz / 8 = 25.000 MHz attained
  SPI right  kernel 100000000 Hz / 4 = 25.000 MHz attained
```

Note the deliberate wording of the request line: it says *requested*, and it
says the prescaler rounds down. A line that prints a request must say so, or it
becomes the next wrong label.

**Known gap in the instrument.** The readback is compiled only where
`EVE_PANEL_HAS_BUS && SPI_CFG1_MBR_Pos` are both defined
(`MustangDash.ino:777`); otherwise it prints `SPI attained rate: not reported on
this target` (`MustangDash.ino:807`). `SPI_CFG1_MBR_Pos` is an SPI-v2 (H7) field
and is absent from the F767 headers, so the F767 mule build takes the fallback
branch — the board where this class of error was first seen is currently the one
board that cannot report it. On F7 the equivalent field is `CR1.BR` — but F7 **also**
lacks `RCC_PERIPHCLK_SPI123`, so the function's inner fallback reports every
instance's kernel as PCLK2 (108 MHz), including SPI2, which actually runs from
PCLK1 at 54 MHz. A `CR1.BR`-only extension would print the left panel at 27 MHz
while it runs 13.5 — the same error class, rebuilt inside the instrument meant to
prevent it. The extension is two changes, not one: the field, *and* per-instance
PCLK1/PCLK2 selection.

**What the 25 MHz step then bought, measured on real copper 2026-08-21.**
Baseline first at the unchanged setting: three panels, fps 60, `faults=0,0,0`,
REG_ID 16/16 on all three, attained 12.5 MHz. Then the constant moved to 25 MHz
and two 20-minute soaks ran, STREET and TRACK, with `diag` and `status` sampled
once a minute, 20 samples each. 16 reads × 3 panels × 20 samples × 2 legs =
**1,920 REG_ID reads, zero misses**. `faults=0,0,0` and `retired=0,0,0`
throughout, `eve=ok,ok,ok`, no drift in either leg. fps was 60 in TRACK and 57 in
STREET; the cluster's STREET display lists total about 33% more than TRACK
(`dl` 647/689/359 versus 434/434/408 — larger on center and left, slightly
*smaller* on right, so the honest figure is the total and not the leading two)
and the reading was steady rather than decaying, so it reads as render
cost rather than link trouble — explicitly **not proven**, because no 12.5 MHz
STREET sample exists to difference it against, and that gap is recorded rather
than papered over.

The walk stops at 25: the BT817 QSPI slave is rated 30 MHz, putting 25 at 83% of
spec, and the next prescaler-reachable rung is 50 at 167%. Reaching 30 would
require moving an SPI kernel source off the reset defaults — which is also the change that
can break the power-of-two ratio currently masking the asymmetry — a *matched*
move scaling both sources by the same power of two would preserve it — so it has
to be done for all three instances together and re-measured per panel.

**Counter-example worth keeping.** Board3 runs clean at 25 MHz where the older
Teensy loom failed read integrity at 24, and where 27 MHz hard-wedged the F767 on
jumpers. That is a separate lesson — bench operating points do not transfer
across topology — already carried in `CLAUDE.md`. It is mentioned here only
because it is the reason the *acceptance* evidence had to be re-gathered on
Board3 rather than inherited, which is what forced the readback question in the
first place.

## See also

**The direct predecessor.**
- [F767 SPI prescaler quantization / 27 MHz hard wedge](../integration-issues/f767-spi-prescaler-quantization-27mhz-hard-wedge.md)
  — states the rule this document is the failure of. Its F767 numbers
  (6.75 / 13.5 / 27 / 54 off APB2 108 MHz) are **correct and must not be
  "corrected" to 12.5** — that ladder is real on that die. What did not survive
  is the sufficiency of a prose-only prevention rule, and its "derive the ladder
  from the bus clock" advice, which assumes there is one bus clock.

**Numbers this measurement makes stale.**
- [24 MHz overclock corrupts EVE coprocessor reads](../integration-issues/spi-run-clock-24mhz-overclock-corrupts-eve-coprocessor-reads.md)
  — carries a 2026-08-05 *self-correction* block asserting "the constant is
  13.5 MHz". That block was itself added to fix a stale number and is now stale
  twice over. It is the cleanest available exhibit for why a retraction has to
  be grepped for, not just written where the error was noticed.
- [Dash carrier buffered-SPI topology / 30 MHz clock contract](../architecture-patterns/dash-carrier-pcb-buffered-spi-topology-30mhz-clock-contract.md)
  — its clock figure is explicitly a projection; Board3's two-soak acceptance
  discharges it at 25 MHz.

**Same family — a number that is not the measurement you think it is.**
- [A count at the report limit is not a measurement](../developer-experience/a-count-at-the-report-limit-is-not-a-measurement.md)
  — the sibling failure, and worth reading against this one: that doc's own
  detection test ("make the check stricter and watch the number move") would
  have **passed** this bug. Moving the constant 13.5 → 25 moved the reported
  rate 12.5 → 25.0, obediently, while it was wrong the whole time. A number that
  responds correctly to your inputs can still never have been measured.
- [Verifying every part of a claim does not verify the claim](../design-patterns/verifying-every-part-of-a-claim-does-not-verify-the-claim.md)
  — "soak-accepted at 13.5 MHz" was true in every part and false as a sentence.
- [An unguarded header define silently stomps a build flag](../build-errors/an-unguarded-header-define-silently-stomps-a-build-flag.md)
  — the build-time twin of configured-versus-effective, on this same clock tree.

**Method.**
- [Query the running device before theorising](../developer-experience/query-the-running-device-before-theorising.md)
  — `diag` extends the status surface that convention is about.
- [Own the first supply write when compiling for a sibling die](../architecture-patterns/own-the-first-supply-write-when-compiling-for-a-sibling-die.md)
  — register-level truth over framework abstraction, same board, same campaign.
- [Re-derive the constant, not the threshold](re-derive-the-constant-not-the-threshold.md)
  — the standing convention on not inheriting pinned numbers.

**Prior art.** [The three-panel F767 bring-up plan](../../plans/2026-07-22-002-feat-three-panel-f767-bringup-plan.md)
argued a month before the evidence existed that clock trees differ per bus and
numbers do not transfer between them. The thesis was already in the repo; what
was missing was the instrument.

**What the correction pass itself cost.** Bringing every stale rate in the tree
forward introduced or nearly introduced four fresh defects, including deleting
the repo's strongest corroborating fact for this very finding. Written up in
[a correction is an unreviewed change](a-correction-is-an-unreviewed-change.md).

**Bench record.** [Board3 bring-up card](../../hardware/board3-bringup-card.md)
carries the walk as a discharged debt item with the acceptance evidence.

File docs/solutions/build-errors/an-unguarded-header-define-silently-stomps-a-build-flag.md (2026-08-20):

---
title: "An unguarded header #define silently stomps a -D build flag and compiles out the clock override"
date: 2026-08-19
category: build-errors
module: firmware-build
problem_type: build_error
component: tooling
severity: critical
symptoms:
  - "Board hangs at first power-on inside HAL_RCC_OscConfig waiting for HSERDY -- no USB enumeration, board looks dead"
  - "Sketch's Board3 SystemClock_Config override silently compiled out: its #if gate on HSE_VALUE == 25000000UL evaluated false"
  - "RCC_CR readback over SWD 0x5C025: HSEON=1, HSERDY=0, HSEBYP=1 -- bypass asserted against a real 25 MHz crystal, so the oscillator amp is disabled"
  - "Compiler printed warning: \"HSE_VALUE\" redefined in every build log since the env was created -- nobody read it"
  - "Even a surviving boot would run SystemCoreClock skewed 3.125x (8 MHz assumed vs 25 MHz real)"
root_cause: config_error
resolution_type: code_fix
tags:
  - platformio
  - build-flags
  - preprocessor
  - hse
  - stm32
  - silent-failure
  - compiler-warnings
  - variant-header
---

# An unguarded header #define silently stomps a -D build flag and compiles out the clock override

## Problem

Board3's first power-on looked dead — flashed clean, then nothing: no USB enumeration, no serial, no sign of life. The cause was a preprocessor stomp: the Arduino-STM32 variant header redefined the build's `-D HSE_VALUE=25000000UL` back to `8000000` in every translation unit, which silently compiled out the sketch's Board3 clock override and left the stock 8 MHz HSE-BYPASS clock config to hang forever against a real 25 MHz crystal.

## Symptoms

- **No USB CDC enumeration after flash.** Upload succeeds, the board enumerates nothing. A brand-new board presenting exactly like dead hardware.
- **PC pinned pre-`setup()`.** SWD sampling with PlatformIO's own OpenOCD (halt, `reg pc` twice — same address both times) plus `arm-none-eabi-addr2line` against `firmware.elf` resolved the spin to `SystemClock_Config` → `HAL_RCC_OscConfig`. This is the same PC-sample + addr2line + register-readback recipe that had diagnosed a *different* pre-main hang (the H755 supply-config latch) minutes earlier the same night — it is the repo's proven boot-hang triage.
- **RCC_CR readback: `0x5C025`** — HSEON=1 (bit 16), HSERDY=0 (bit 17), **HSEBYP=1** (bit 18). Bypass mode named the failure precisely: HSEBYP turns the oscillator amplifier off and expects an external clock on OSC_IN. Board3 has a crystal there, not a clock, so the crystal can never start, HSERDY never sets, and `HAL_RCC_OscConfig` blocks on it forever.
- **The warning was in every build log the env ever produced:** `variant_NUCLEO_H743ZI.h:368: warning: "HSE_VALUE" redefined` (line 368 in the pre-fix header, where the bare `#define` sat). It printed on every successful-looking build since `[env:board3]` was created. Nobody read it.

## What Didn't Work

- **Replug, power-cycle, reflash.** The hang is deterministic and pre-`main()`-adjacent (first thing the Arduino core runs before `setup()`); no power-state ritual touches it. Worth ruling out fast here only because the *other* hang that night (the write-once supply latch) genuinely did care about POR vs. warm reset — this one does not.
- **Assuming the `-D` flag was authoritative.** `platformio.ini:57` plainly sets `-D HSE_VALUE=25000000UL` in `[env:board3]` (`platformio.ini:39`), and the sketch's gate plainly tests it — so the flag "obviously" reached the code. It did not. The variant header's bare `#define` won in every TU that includes it, which via `Arduino.h` → `pins_arduino.h` is effectively all of them.
- **Trusting a warning-bearing build because it linked.** This is the honest beat: the `"HSE_VALUE" redefined` warning was visible for weeks, in green builds, and was scrolled past every time. The repo has already paid for this failure mode once — the ERC-1009 lesson (`docs/solutions/developer-experience/a-large-erc-count-is-a-broken-instrument.md`): output nobody reads is an instrument that has stopped instrumenting. A build log with tolerated warnings is the same broken instrument at smaller scale — the one line that mattered had no way to stand out because *no* line was being read.

## Solution

Guard the variant's default so a command-line definition wins. The fix lives in the repo-owned variant copy — `boards/variants/H755ZI_Q_MULE/variant_NUCLEO_H743ZI.h` — which both `board3` and `board3_mule` already ride via `board_build.variants_dir`/`board_build.variant` (`platformio.ini:53-54`, `115-116`).

Before (stock STM32duino header, pre-fix line 368 — unguarded against the command line):

```c
// HSE default value is 25MHz in HAL
// HSE_BYPASS is 8MHz
#ifndef HSE_BYPASS_NOT_USED
  #define HSE_VALUE             8000000
#endif
```

After (`boards/variants/H755ZI_Q_MULE/variant_NUCLEO_H743ZI.h:376-378`):

```c
#if !defined(HSE_VALUE) && !defined(HSE_BYPASS_NOT_USED)
  #define HSE_VALUE             8000000
#endif
```

The guard composes with upstream's existing `HSE_BYPASS_NOT_USED` knob rather than replacing it — three cases, all correct:

1. **Env defines `HSE_VALUE`** (Board3's `-D HSE_VALUE=25000000UL`): the header defines nothing; the env's value survives into every TU. The sketch's gate at `MustangDash/MustangDash.ino:238` — `#if defined(DASH_BOARD_BOARD3) && defined(HSE_VALUE) && (HSE_VALUE == 25000000UL)` — goes true, and the 25 MHz clock override compiles in.
2. **Env defines `HSE_BYPASS_NOT_USED`** (upstream's opt-out for a Nucleo with a real crystal fitted): unchanged from stock — the header defines nothing and the HAL's own 25 MHz default applies.
3. **Env defines neither** (the H755 mule on a real NUCLEO-H755ZI-Q, 8 MHz ST-LINK MCO): the stock 8000000 default lands exactly as before. The mule env is behaviorally untouched.

Verified on the bench post-fix (PR kms254/Mustang-Dash-Test#47, unmerged as of this writing): Board3 boots at 400 MHz SYSCLK from the 25 MHz crystal (25 /M5 × N160 /P2, per the override at `MustangDash/MustangDash.ino:249-250`), USB CDC enumerates, full dash firmware live.

## Why This Works

The mechanism is pure preprocessor ordering. `-D` definitions are processed before any line of any file, so when the compiler reaches the variant header, `HSE_VALUE` is already `25000000UL`. A later bare `#define HSE_VALUE 8000000` with a different body is a *redefinition*: GCC warns (`"HSE_VALUE" redefined` — the warning that was printing all along) and the **new value wins** from that line onward. Because the variant header is pulled in near the top of every TU (through `Arduino.h` → `pins_arduino.h`), every downstream consumer saw 8000000, never 25000000:

- **Consequence (a), the hang:** the sketch's equality gate evaluated `8000000 == 25000000UL` → false, so the entire Board3 `SystemClock_Config` override compiled out — *silently*, because a false `#if` is not an error, it is a feature. STM32duino declares `SystemClock_Config` weak (noted at `MustangDash/MustangDash.ino:246-248`), so with no strong override in the link, the variant's weak default linked instead: 8 MHz HSE **bypass**, written for the Nucleo's ST-LINK MCO. On Board3's real crystal that is unstartable by construction — HSEBYP disables the amp — hence HSERDY never, `HAL_RCC_OscConfig` forever, RCC_CR `0x5C025`.
- **Consequence (b), the sleeper:** the HAL computes `SystemCoreClock` from `HSE_VALUE` when the PLL runs from HSE, so even a boot that somehow succeeded would have carried clock arithmetic off by 25/8 = **3.125x** — every HAL timeout, every baud-rate derivation, wrong by the same factor.

The `#if !defined(HSE_VALUE)` guard inverts the precedence from *last definition wins* to *first definition wins*, which is the correct polarity for a default: a default that can overwrite an explicit setting is not a default, it is a trap with a warning attached.

## Prevention

1. **Grep every build log for `redefined` — mechanically, not by eyeball.** One line does it:

   ```
   pio run 2>&1 | grep -i redefined
   ```

   Empty output is the pass condition. Any hit on a load-bearing `-D` flag is this bug wearing a different macro name. This is cheap enough to belong in CI or in `scripts/compile.sh` itself.

2. **A `-D` consumed by an `#if` equality gate deserves a compile-time proof.** The gate at `MustangDash.ino:238` is *designed* to compile the override out on non-Board3 envs — so its silence is ambiguous: "mule build, working as intended" and "Board3 build, clock config stomped" look identical. Make the intended-impossible combination an error:

   ```c
   #if defined(DASH_BOARD_BOARD3) && defined(HSE_VALUE) && (HSE_VALUE == 25000000UL)
   extern "C" void SystemClock_Config(void) { /* ... 25 MHz crystal tree ... */ }
   #define DASH_BOARD3_CLOCK_OVERRIDE_COMPILED 1
   #endif

   #if defined(DASH_BOARD_BOARD3) && !defined(DASH_BOARD3_CLOCK_OVERRIDE_COMPILED)
   #error "DASH_BOARD_BOARD3 is set but the 25 MHz clock override compiled out -- HSE_VALUE was stomped (grep the build log for 'redefined')"
   #endif
   ```

   With that in place, this bug is a red build with a message naming its own diagnosis, instead of a dead board and an SWD session.

3. **Repo-owned variant copies are the sanctioned place to fix vendor headers.** The precedent already exists in this exact file: the H755 supply guard (`variant_NUCLEO_H743ZI.h:417-421`, banked after the 2026-08-12 mule hang) lives in the same repo copy, wired in by `board_build.variants_dir = boards/variants` (`platformio.ini:53-54`). The PlatformIO-managed framework package is not editable in place (it is regenerated on clean installs), and an upstreamed fix helps a future toolchain, not this board. When a vendor header is wrong, copy it under `boards/variants/`, fix it there with a dated comment explaining the delta from stock, and point the env at it — that is now the pattern's second use, which is what makes it a pattern.

## Related Issues

- `docs/solutions/architecture-patterns/own-the-first-supply-write-when-compiling-for-a-sibling-die.md` — the OTHER pre-main hang from the same first-light night (and the same PR), diagnosed with the same SWD recipe; also the canonical write-up of the H755 supply guard this doc's Prevention #3 cites.
- `docs/solutions/developer-experience/a-large-erc-count-is-a-broken-instrument.md` — same unread-warning failure mode: the decisive signal was emitted in every run and read by nobody because it lived inside routine output.
- `docs/solutions/integration-issues/kicad-dru-one-bad-constraint-silently-voids-every-custom-rule.md` — silent-void family: one bad input silently disables an entire configured behavior while the run looks clean.
- `docs/solutions/developer-experience/a-count-at-the-report-limit-is-not-a-measurement.md` — instrument-misreading family: a tool output taken at face value is not the quantity you think it is until verified.
- `docs/solutions/conventions/a-gate-that-cannot-pass-gets-waved-through.md` — a check whose output is never read stops being a check; the redefinition warning was a permanently-yellow gate.
- `docs/solutions/integration-issues/f767-spi-prescaler-quantization-27mhz-hard-wedge.md` — same "the value you requested is not the value you got" shape on STM32 clocks.
- Fix PR: kms254/Mustang-Dash-Test#47.

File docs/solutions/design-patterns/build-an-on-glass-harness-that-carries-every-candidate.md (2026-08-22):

---
title: A scaled-down preview is different evidence, not weaker evidence
date: 2026-08-22
category: design-patterns
module: splash-render
problem_type: design_pattern
component: development_workflow
severity: high
root_cause: missing_tooling
resolution_type: tooling_addition
applies_when:
  - an artifact will be judged by eye on target hardware - a rendered surface, a gradient, an animation, an LED colour - and previews or mock-ups are the only feedback so far
  - several candidates are in play and choosing between them currently costs one build-and-flash cycle each
  - the thing to be judged is transient on the device (a 2 s boot animation, a fault flash) and cannot be held still long enough to look at
  - a computed constant governs a perceptual effect - a falloff, a brightness, a spread - and has only been checked on paper
  - deciding whether bench-only scaffolding earns its place in firmware, or whether a locked design means it now comes out
symptoms:
  - A candidate that read as convincing in a scaled preview reads as something else entirely at 1:1 - engine-turned jeweling rendered as bubbles
  - Rejections arrive one per flash cycle, and each round produces another candidate rather than a decision
  - Each fix reveals an artefact the previous one was masking - block stepping, then colour banding, then dither blobs
  - A constant expressed against the wrong denominator looks correct on paper and is visibly wrong on the panels
  - The preview channel itself fails to render for the reviewer, so nothing has actually been looked at on the target
related_components:
  - MustangDash/splash_render.h
  - MustangDash/splash_config.h
  - MustangDash/dash_serial.h
  - MustangDash/MustangDash.ino
  - tools/make_material.py
tags:
  - splash
  - on-target-evaluation
  - bench-harness
  - perceptual-design
  - ram-g
  - astc
  - eve
  - scaffolding
---

# A scaled-down preview is different evidence, not weaker evidence

## Context

The splash background for the three-panel cluster took five surface candidates, three bitmap encodings, and one measured framebuffer property before it settled — and every one of those decisions was made wrong at least once from a preview image, then made right on glass. The work is on `feat/splash-metal-cluster-background`, PR #52, **merged 2026-08-22**, seven commits.

The thing being designed is a lit metallic field spanning three 1024×600 BT817 panels behind a 2000 ms boot animation. Nothing about it is verifiable by inspection: it is a *perceptual* artifact whose failure modes are contour banding, tiling repetition, block-boundary steps, dither mottling, and — in the worst case here — reading as an entirely different physical object than the one intended.

The five candidates were built and rejected on the real cluster: engine-turned jeweling at two scales, brushed, a full-panel non-repeating anodised field, and the original carbon re-derived (the commit "fix(splash): the background has no texture, and the gradient took three encodings", PR #52). Every one of them had looked acceptable, or at least arguable, as a PNG on a monitor.

Two mechanisms made the on-glass loop cheap enough to actually run, both temporary bench serial commands:

- **`mat on|off`** held the splash background on every panel indefinitely, with no dash drawn on top, so a candidate could be looked at for as long as it took. Its own comment said why it existed: *"The background is a judgement call that a scaled-down preview gets wrong -- one candidate read as plausible texture in a mock-up and as bubbles on glass -- and the splash is only 2 s long."* (`git show <the cleanup commit>^:MustangDash/dash_serial.h`, the `DASH_CMD_MAT` enum entry.)
- **`splash`** replays the whole boot animation on demand — same reasoning one level up, since the animation crossfades away after 2 s and a power cycle per look is worse.

`mat` was introduced alongside the textureless background and **deliberately deleted** by the commit *"refactor(splash): remove the background-comparison scaffolding"* (PR #52 — 22 files changed, 40 insertions, 238 deletions) once the design locked. It does not exist at HEAD, which is the point: find it with `git log --oneline -S 'DASH_CMD_MAT' -- MustangDash/`, which returns both the commit that added it and the one that removed it, then read the pre-cleanup revision of `MustangDash/dash_serial.h` and `MustangDash/MustangDash.ino`. (`--diff-filter=D` does *not* work here: it selects commits where the FILE was deleted, and both files still exist, so it returns empty with exit 0 — a recipe that fails silently is worse than no recipe.) `splash` stayed and is live in `MustangDash/dash_serial.h`.

## Guidance

### 1. Treat a downscaled preview as a different measurement, not a smaller one

Downsampling is a low-pass filter. The failure modes that decide whether a rendered surface is acceptable at 1:1 are *precisely the high-frequency structure a downscale destroys*: block boundaries, dither cells, tiling seams, quantisation contours, and the fine texture that distinguishes "machined" from "noise". A preview does not under-report those; it removes them and reports the remainder confidently.

The sharpest instance here inverted the meaning of the image entirely. Engine-turned jeweling read as plausible machined aluminium as a PNG and as **bubbles** on the panel. The cause was found only afterwards and only because someone was looking at it full-size: each disc carried a radial brightness falloff *and* an angular sheen gradient — which is exactly how you shade a sphere. Flattening the brightness, crisping the edges and letting the scratches dominate produced a legible machined motif, which was then rejected for a different reason: a 128 px tile repeats **40 times** across a 1024×600 panel (8 across × 5 down), and no amount of tile tuning fixes repetition.

### 2. Build the re-run harness before you build the third candidate

The economics are what make this a rule rather than a preference. Without a harness, each look costs a rebuild, a flash, a boot, and a 2000 ms window before the animation crossfades away. That is a per-look cost high enough to silently discourage looking — which is how a bad choice survives an inspection that technically happened.

The harness does not remove the rebuild — a new candidate still means regenerating the pack and reflashing. What it removes is the **2000 ms window**, and that is the cost that actually stops people looking: an artifact you can study for a minute gets judged, one that vanishes after two seconds gets guessed at. RAM_G headroom is what made even that affordable; the centre panel sat at 469,312 B of 1,048,576 before the L8 glow landed and 608,064 B after, so the background layer was never the constraint.

**A caution about this very claim, which is the sharpest thing in this document.** A live variant of the harness *did* stage several candidates at once and switch between them over serial, and it is what made comparing five surfaces practical. It was never committed — it lived in the working tree and was collapsed away before the first commit — so **no revision in the repository contains it** (`git log --all -S 'SPLASH_MATERIAL_COUNT' -- MustangDash/` returns nothing). The commit message in PR #52 nevertheless asserts that staging every candidate turned five flash cycles into one, and the first draft of this document repeated it, because both were written from memory of the session rather than from the artifact. Scaffolding you delete without committing cannot be cited afterwards; if the harness taught you something, the commit is the only place that survives. **The harness is nearly free whenever the target has headroom, and the cost of not building it is paid every single time you look.**

The same argument scales up a level: `splash` exists because a 2 s animation that plays once at power-up cannot be judged, and a power cycle per look is worse than a rebuild per look was. the commit "feat(splash): the glow reaches across the whole cluster" (PR #52) states the general form directly: *"if a thing can only be judged on hardware, it needs to be re-runnable on hardware."*

### 3. Measure the output stage before blaming the asset

Three encodings were tried for one smooth gradient, and each one exposed a cause the previous one had masked. The reasoning is preserved verbatim in `encode_l8()` in `tools/make_splash_flash.py`:

```
      ASTC   -- a BLOCK codec. A gradient is exactly what it handles worst,
                and this asset is magnified on screen, so every block
                boundary became a visible step.
      RGB565 -- no blocks, but only 32 blue levels, which bands a dark blue
                ramp on its own. Dithering the SOURCE does not fix that,
                because the source is magnified: the dither cells become
                blobs and read as diagonal mottling. Dither only works at
                output resolution.
      L8     -- 8 bits of ALPHA (256 levels) with the colour supplied by
                COLOR_RGB. The ramp is 8x finer than RGB565's blue, there is
                nothing to block-quantise, EVE interpolates the alpha in
                hardware when magnifying, and it is half the size. No dither
                needed anywhere.
```

Even a perfect asset still banded, because the **last quantiser is the framebuffer** and nobody had checked it. `REG_OUTBITS` reads 0 (8 bits) and `REG_DITHER` reads 1 on all three panels — and critically, those were *measured*, read back live through the `diag` command rather than assumed:

```c
Serial.printf("  panel %-6s REG_OUTBITS 0x%03X REG_DITHER %u\r\n",
              kNames[p],
              (unsigned)EVE_memRead16(REG_OUTBITS),
              (unsigned)EVE_memRead8(REG_DITHER));
```
(the `diag` handler in `MustangDash/MustangDash.ino`. The comment above it records why: the vendored library configures those registers only for an unrelated board, *"so they sit at reset defaults nobody had ever checked."*)

An 8-bit ramp across 600 px still contours regardless of source precision. The fix is a 64×64 noise tile drawn **1:1 with `EVE_REPEAT` and `EVE_NEAREST`** at an amplitude of ~3 output levels (`SPLASH_DITHER_A 3U`, `SPLASH_DITHER_A` in `MustangDash/splash_render.h`, applied at line 321). **Dither belongs at output resolution.** Dithering the magnified source is the failure this replaced — the same 1:1-versus-magnified distinction as the metal tile, arrived at independently.

### 4. Express a perceptual constant in the units of the thing being perceived

A constant can compute correctly and still be wrong on glass, and the framing of the constant is often why. The glow hotspot's horizontal sigma was ~7% of cluster width — a defensible number that put the entire falloff inside the centre panel and left the sides lit only by the vertical term, reading as two dim screens flanking a bright one.

It is now `GLOW_SPREAD_X = 0.34` (`GLOW_SPREAD_X` in `tools/make_material.py`), and the more durable half of that change is the *denominator*. The old value was buried as `0.115 * 1.9` **against panel width**; the design object is one light source seen across three screens, so panel width was the wrong unit to think in. The comment now says so explicitly, and records the boundary of the design space too: past roughly 0.6 the cluster stops reading as lit-from-centre and becomes uniformly blue — a legitimate but different design, worth choosing rather than drifting into.

### 5. Budget the scaffolding's removal as part of the work, and verify the removal on the same instrument

`mat` was removed the moment the design locked, along with `tools/make_splash_assets.py` (deleted by this work), `assets/splash/reference/` (deleted by this work), 8.1 MB of retired art, and the dead engine-turned generator code. That is correct: the tool held five candidates and there is now one background, and `splash` covers looking at the result.

The removal introduced its own defect, and it is instructive that **the compiler could not see it**. A regex that removed the `mat` parser ran from a comment to the next blank line, and the `splash` parser had been inserted directly after that comment — so it went too. The `DASH_CMD_SPLASH` enum entry survived, so the build was clean, and the failure appeared only at runtime on the board as `err unknown command`. It was fixed by re-verifying against the **live command surface** rather than the build log. (A fresh instance of `docs/solutions/conventions/a-correction-is-an-unreviewed-change.md` — the pattern is documented there.)

### 6. A cheap loop is not a substitute for looking up what already works

This is the limit that keeps the rest honest. The harness made iteration nearly
free, and five candidates were iterated. What actually settled the question was
neither the sixth candidate nor a better preview: it was fifteen minutes of
reading what shipping premium clusters do, which returned a one-sided answer —
they are plain dark backgrounds, and a patterned cluster background is the
aftermarket tell. The commit says it plainly: *"one search would have saved five
rounds"* (the commit "fix(splash): the background has no texture, and the gradient took three encodings", PR #52).

So the ordering is: **establish what the answer probably is, then build the
harness to choose among the survivors.** A cheap loop makes a wide search
affordable, which is exactly what makes it tempting to substitute for a narrow
one. The harness answers *which of these*, never *should it be any of these*.

The repo also already held prior art nobody found. `docs/solutions/ui-bugs/boot-splash-radial-gradient-banding-double-quantization.md`
(2026-07-10) documented banding on this same splash gradient — and its
prevention bullet prescribes *"pair ordered dither with a bilinear (or better)
upscale … the filter averages the dither back toward the true value."* That is
precisely what was tried here, and on glass it produced visible diagonal
mottling. The ancestor validated the technique at a **2x** upscale with an 8x8
Bayer cell — the same geometry the shipping glow uses — so the prescription is
not wrong as measured. What broke it was ratio: the glow was authored at 1/16
scale at the time, and at 16x one dither cell spans well over a hundred screen
pixels, which bilinear cannot demodulate because it averages source texels, not
screen ones. The advice holds at the ratio it was measured at and inverts well
above it, which is why that doc is flagged for refresh rather than cited as
support.

## Why This Matters

The general shape is a mismatch between where a judgement is *made* and where the artifact is *consumed*. Any intermediate representation — a downscale, a mock-up, a screenshot, a host-side render — is a lossy channel, and for perceptual work the loss is concentrated exactly in the band that carries the decision. That is why "the preview looked fine" and "it is wrong on the panel" are not in tension: both are accurate reports about different signals.

On this branch the preview channel eventually failed *completely* — the candidate images did not render for the reviewer at all — which is what forced the decision onto the panel. In hindsight that should have been the first move rather than the fallback, and it would have saved most of five rounds.

There is a second, quieter cost. When looking is expensive, looking gets skipped, and every skipped look is a decision made on the cheap channel by default. A harness does not just make verification possible; it changes which verification is the path of least resistance. `mat` and `splash` cost a few dozen lines each and one afternoon's RAM_G headroom, against five reflash cycles per comparison round.

Finally, the framebuffer measurement is the reason the whole chain terminated. Three asset-side fixes each improved the gradient and none of them could have finished the job, because the last quantiser was downstream of every asset. **A pipeline is only as precise as its output stage, and the output stage is the one nobody wrote.**

## When to Apply

- **Before building the harness at all.** Spend fifteen minutes on what shipping products already do. The harness answers *which of these*; it never answers *should it be any of these*, and a cheap loop is exactly what makes substituting the first question for the second tempting.
- **Any artifact judged perceptually on target hardware** — display surfaces, animation timing, LED colour and brightness, backlight curves, audio. If the acceptance criterion is "does it look/sound right", the target is the only valid instrument.
- **When the target has spare storage for more than one candidate.** Stage them all; the switching cost drops to a command and the comparison becomes side-by-side rather than serial-with-memory.
- **When an artifact is magnified, tiled, or requantised between authoring and display.** Every one of those transforms has a characteristic artifact that a preview at a different scale cannot show.
- **When a computed constant governs something perceived.** Check its denominator against the object actually being perceived, and check the ends of its useful range so the chosen value is a choice.
- **When removing scaffolding.** Verify against the running system's live surface, not the build. Deletions that leave a declaration behind compile clean.

Do **not** reach for this when the acceptance criterion is numeric and host-checkable — geometry, checksums, timing budgets, byte layouts. Those belong in the host test suite, which is faster and does not need a board. The splash pack's structural invariants (L8 stride, uncompressed size, power-of-two dither tile, no asset full-panel) are host-tested for exactly that reason; only the *appearance* required glass.

## Examples

**The bench hold that made the loop affordable** (removed by the scaffolding-cleanup commit in PR #52; recover it with `git log -p -S 'g_bg_hold' -- MustangDash/MustangDash.ino`):

```c
if (g_bg_hold)
{
    /* bench hold (`mat`): the splash background on every panel, with
     * no dash on top, so a candidate material can be judged for
     * longer than the 2 s splash allows */
    const ThemeDesc *theme = &THEMES[g_theme];
    if (dash_select_panel(DASH_PANEL_CENTER))
    {
        eve_frame_begin(0x000000UL);
        EVE_color_rgb(0xFFFFFFUL);
        draw_splash_background(theme, DASH_PANEL_CENTER, 255U);
        eve_frame_end();
    }
    dash_sides_frame(0U, theme, 255U, 0x000000UL);
}
```

Note what it does *not* do: it does not render a candidate to a file, and it does not shorten the splash. It removes the time limit entirely, on every panel at once, at the real resolution.

**Output-resolution dither, drawn 1:1** (the dither block in `draw_splash_background()`, `MustangDash/splash_render.h`) — the `EVE_NEAREST, EVE_REPEAT, EVE_REPEAT` triple is the whole point; nothing about this tile may be magnified:

```c
EVE_cmd_dl(COLOR_A((uint8_t)(((uint16_t)alpha * SPLASH_DITHER_A) / 255U)));
EVE_cmd_dl(BLEND_FUNC(EVE_SRC_ALPHA, EVE_ONE));
EVE_cmd_setbitmap(dith_src, (uint16_t)dith->fmt, dith->w, dith->h);
EVE_cmd_dl(BITMAP_SIZE(EVE_NEAREST, EVE_REPEAT, EVE_REPEAT, ...));
```

The generator states the causal chain (`tools/make_material.py`, `dither_tile()`): *"REG_OUTBITS is 8 bits, so the FRAMEBUFFER quantises after every asset: a ~106-level ramp across 600 px steps every ~6 px and shows contour rings. No amount of source precision fixes that, because the quantisation happens downstream of the asset."*

**The constant re-expressed in cluster units** (the `GLOW_SPREAD_X` block in `tools/make_material.py`):

```python
# Horizontal spread of the hotspot, as a fraction of the WHOLE CLUSTER width --
# not of one panel, because the point is a single light source seen across
# three screens.
GLOW_SPREAD_X = 0.34
```

**The negative result is also a result.** After five candidates, what settled it was prior art rather than a sixth generation: shipping premium clusters use plain dark backgrounds, and a patterned cluster background is the aftermarket tell. That reasoning is now load-bearing enough to live in the renderer itself (the layer comment above `draw_splash_background()`), so the next person does not re-derive five textures to reach the same place. Real carbon went on the bezel, which is where the car has it.

---

## Related

**The nearest neighbour — read the split, do not fold them.**
- [Query the running device before theorising](../developer-experience/query-the-running-device-before-theorising.md)
  — the *diagnosis* half of the same instinct: read the status surface the
  device already exposes instead of reasoning about it. This is the *judgement*
  half, where no field answers the question because the question is perceptual,
  so the surface has to be built. That doc's own When-to-Apply excludes the
  case where the surface itself is under test, which is exactly this one.

**The prior instance — this is a pattern, not a one-off.**
- [An identity mapping is the absence of a mapping](an-identity-mapping-is-the-absence-of-a-mapping.md)
  — two days earlier, a lamp mapping no test could verify was closed by a bench
  command that forced each physical position so it could be judged by eye. Same
  countermeasure, different subsystem, and the reason this is written as a
  repeatable shape rather than a splash anecdote.

**Contradicted or narrowed by this round.**
- [Boot-splash radial gradient banding: double quantization](../ui-bugs/boot-splash-radial-gradient-banding-double-quantization.md)
  — the ancestor. Its two-quantizer model is missing the one downstream of every
  asset: the framebuffer's own output depth, which no asset-side choice can
  reach. Its source-dither prescription also holds only at modest magnification
  — it was validated at 2x and inverts well above that. Flagged for refresh.
- [EVE RAM_G budgeting for multi-theme splash assets](eve-ram-g-budgeting-multi-theme-splash-assets.md)
  — defined "perceptually forgiving" on the wrong axis: magnification forgives
  resolution loss and *amplifies* encoding artefacts. Its multi-theme premise is
  also gone.
- [BT817 flash-resident ASTC assets](../architecture-patterns/bt817-flash-resident-astc-assets.md)
  — its codec recommendation needs the qualifier that ASTC is a block codec and
  therefore wrong storage for a magnified smooth ramp.

**Same reflex, other subjects.**
- [A clock constant is a request, not the operating point](../conventions/a-clock-constant-is-a-request-not-the-operating-point.md)
  — measure-don't-assume applied to a bus clock; here it was applied to the
  framebuffer's own output depth.
- [A correction is an unreviewed change](../conventions/a-correction-is-an-unreviewed-change.md)
  — the deleted-parser incident is a fresh instance, and the reason the removal
  was closed against the live command surface rather than the build log.
- [Verifying every part of a claim does not verify the claim](verifying-every-part-of-a-claim-does-not-verify-the-claim.md)
  — every preview render was correct; *"the preview looks good, therefore the
  panel looks good"* was the defect.
- [Continuity and slew are two separate fixes](continuity-and-slew-are-two-separate-fixes.md)
  — the structural match for a chain of fixes each of which measured as done and
  unmasked the next cause.

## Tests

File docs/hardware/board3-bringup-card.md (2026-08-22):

# Board3 bring-up card

One page for the bench. Everything here was measured off the board/gerbers in
the 2026-08-07 pre-order review (`pcbnew` + gerber parse); coordinates are
board-frame mm. Print this before the boards arrive.

## Flashing — first connect

1. **ONE-TIME, before anything else** (H755 boots BOTH cores from the factory
   and the CM4 has no image):
   `STM32_Programmer_CLI -c port=SWD -ob BCM4=0`
   via ST-LINK on H2 (Tag-Connect TC2030, hand-held). Skipping this leaves the
   CM4 hard-faulting in the background — usually survivable, never desirable.
2. **Build + flash:** `./scripts/compile.sh board3`, then
   `pio run -e board3 -t upload` (ST-LINK on H2), **or** DFU with no debugger:
   hold BOOT + tap RESET, then `dfu-util` / STM32CubeProgrammer over USB.
3. The env targets the CM7 through the `nucleo_h743zi` variant (H743ZIT6 is
   the same LQFP-144 pin map; Board3's 25 MHz crystal is handled by the
   sketch's `SystemClock_Config` override — 400 MHz, USB on HSI48+CRS).
   Serial is **USB CDC** (enumerates as "MustangDash", 115200, `ok`/`err`
   protocol as on the bench).
4. **Boot banner self-checks:** panel init lines per panel, telltale expander
   ack (`west`/`east`), and `U2 QSPI JEDEC: EF 40 19 -- ok` — the U2
   keep-fitted condition, checked automatically every boot. `MISMATCH` or
   `FAILED` = U2/QSPI problem; the dash still runs.

## Test points — three identical bare 0.6 mm ENIG dots, NO silk labels

| TP | Net | Location | Identify by continuity |
|---|---|---|---|
| TP1 | `/+5V`  | (126.251, 107.730) | beeps to FPC pin 17/18 (backlight +5V) |
| TP2 | `/+3V3` | (121.314, 99.332)  | beeps to FPC pin 1 (panel 3.3 V) |
| TP3 | `/GND`  | (130.442, 110.508) | beeps to MP1–MP4 corner pads |

## The zero-tools MCU test (do this before suspecting anything else)

Hold **BOOT** (SW7) + tap **RESET** (SW6) → STM32 AN2606 system bootloader →
**DFU device enumerates on USB**. No firmware, no debugger. Enumerates = MCU,
power, and the whole USB path are good; the problem is firmware or downstream.

## Dead-board walk (DMM + scope, no desoldering at any step)

1. Power from **barrel, 5 V ONLY** (silk says so; 12 V kills U8/U9/U11/U12 and
   the LEDs). Ground reference: TP3 or any MP corner pad.
2. **TP1 = 0 V?** Walk the input: DC1.1 (`/DC1_IN`, THT pin) → F1.2
   (`/+5V_BARREL`, 1812 pad) → Q2 pins 1–3 vs 5–8 (SOP-8). Unpowered
   diode-mode across Q2: body diode ~0.3 V = FET fine, controller (U6) suspect;
   no diode reading = wrong/reversed FET.
3. **TP1 ok, TP2 = 0?** Ohms TP2↔TP3 unpowered. ~0 Ω = shorted 3V3 rail —
   **unplug panels one at a time** (splits board-short from panel/FFC-short;
   the test the original FFC incident never had). Open → scope `/BUCK_SW` at
   L2's pad; check R2/R3 feedback divider.
4. **Rails ok, no serial?** BOOT+RESET → DFU enumerate? Yes → firmware problem.
   No → **swap the USB cable first** (the flaky-cable incident), then SWD via
   H2. Core alive → USB path (D9's SOT-23-6 pads); core dead → `/NRST`
   (probe at SW6, R49, C46, or H2.3).
5. **MCU up, glass dark?** Center panel's whole SPI is one 0603 row at
   y≈92.99 beside FPC2: R32.2=`/SCLK_C` · R35.2=`/MOSI_C` · R41.1=`/MISO_C` ·
   R45.1=`/CS_C` · R11.1=`/PD_C`, ground at R41.2. **No panel attached**:
   CS/PD read 3.3 V (pull-ups), MISO reads low (100 k pull-down) — so "MCU
   never ran" vs "ran and hung" is a DMM question. Verify +5V/+3V3 continuity
   from TP1/TP2 to each FPC tail *before* risking a panel. Backlight end of an
   FFC: pins 19/20 beep to GND.
6. **Telltales dark?** I2C tap at R5/R8 (4.7 k pull-up pads); scan expects
   **0x5B (U11 west)** and **0x5A (U12 east)**. A hung expander recovers by
   holding its RSTN low at the C70/C71 pads — no bodge needed.

## Left/right panel caveat (do not trust a launch-end waveform)

Only **MISO/CS/PD** have connector-end probe resistors on left/right (left
R42/R46/R12, GND at R42.2; right R43/R47/R13, GND at R43.2). **SCLK/MOSI series
resistors sit at the MCU end** (U50 moved them — correctly), so the *receiver*
end of those 80–90 mm lines is only the 0.5 mm FPC solder tails. For the
clock walk on this copper (done 2026-08-21, see below), probing left/right
SCLK means probing at the FPC tail, not at R33/R36. The same applies to any
future re-walk.

## Bring-up debt — run these on the first good board

- **U2 QSPI JEDEC-ID read — DONE, runs at every boot.** `board3_qspi_jedec_probe()`
  in the sketch prints the ID in the boot banner (see Flashing §4). The
  keep-fitted condition is satisfied the moment the first banner shows `ok`.
- **Panels — DONE 2026-08-20. All three live on Board3**: `eve=ok,ok,ok`,
  fps=60 with all three rendering, faults=0,0,0, three distinct display
  lists. **All three backlights at full duty ran off the laptop USB-C port**
  (U4 CH224K PD sink; ~1.65 A system load vs 3 A at 5 V) — no barrel needed.
  **Before seating any FFC: ohm TP1/TP2 to TP3 with the cable in and the
  panel attached.** The connectors open toward the board interior, so every
  cable needs a 180° fold, the fold inverts the cable's contact face, and
  these are dual-contact parts — a wrong-face cable connects REVERSED
  (pad 1 `/+3V3` onto panel ground) and collapses the rail. Near 0 Ω = flip
  it. Cheap tin FFCs work for a smoke test but are the prime suspect for any
  intermittent; use the gold Premo-Flex for anything you intend to believe.
- **SPI clock walk — DONE 2026-08-21. Board3 runs 25 MHz on all three
  panels.** The request had been 13.5 for weeks; the panels were attaining
  **12.5** — `dash_report_spi_clocks()` now reads the rate back from
  CFG1.MBR + the kernel clock and prints it at boot and on `diag`, so the
  request is never mistaken for the operating point again. The ladder is
  coarse (6.25 / 12.5 / 25, nothing between) because the SPI kernel clocks
  are left at the H7 defaults, which are asymmetric — SPI1/2 off PLL1Q
  200 MHz, SPI4 off APB2 100 MHz — and the power-of-two prescalers happen
  to land both on the same attained rate. Acceptance: two 20-minute soaks
  at 25 MHz, STREET and TRACK, sampled once a minute — **1,920 REG_ID
  reads, zero misses**, faults=0,0,0, retired=0,0,0, eve=ok,ok,ok, no drift
  in either leg. fps 60 TRACK / 57 STREET (the cluster's STREET display
  lists total ~33% more than TRACK: dl 647/689/359 vs 434/434/408 —
  bigger on center and left, slightly smaller on right). **The walk stops at 25**: the BT817 QSPI
  slave is rated 30 MHz, so 25 is 83% of spec and the next reachable rung
  is 50. Note Board3 runs clean at 25 where the Teensy loom failed read
  integrity at 24 — the old numbers described the wiring, not the clock.
- **Splash across all three panels — DONE 2026-08-22, verified on glass.**
  All three light together on the first splash frame; the accent line and the
  year are back (they had been silently dropped since 22 July). Background is
  textureless — a lit field plus a 1:1 dither — after five textured candidates
  were compared on the real cluster with a temporary `mat` bench command and
  all rejected; that scaffolding is gone now the design is locked. **`splash`
  replays the boot animation on demand** -- 2 s at power-up then a crossfade
  is no time to judge an animation, and a power cycle per look is worse.
  Tuning constants, both settled on glass and both in `tools/make_material.py`:
  `GLOW_SPREAD_X` (0.34, as a fraction of the WHOLE cluster) and
  `SPLASH_DITHER_A` (3, in `splash_render.h`) if contour banding ever shows in
  the falloff.
- **Odometer POR — DONE 2026-08-22, on Board3's own FRAM (not the mule
  breakout).** Controlled before/after: 3218.8 recorded, power physically
  disconnected ~1 min with the USB CDC confirmed gone from the bus, 3221.1 on
  the cold boot. Up, not zero. The RAM-shadow fallback would have returned
  zero, so one test covers commit, cold reload, and that the backend is FRAM —
  which the boot banner could never confirm, since it loses its race with CDC
  enumeration. Hold the board off for **at least a minute**: a short blip can
  leave SRAM alive on bulk-capacitor charge and prove nothing.
- **U2 QSPI JEDEC — DONE 2026-08-22**: `EF 40 19`, matching expectation, read
  via `diag`. It was never a hardware question; the ID was printed only in the
  boot banner, which is unreadable in practice.
- **CAN1 first bring-up needs H1 closed** — the order contains the headers but
  **no 2.54 mm shunts** (JLC doesn't supply them). Put shunts in the parts
  order or confirm drawer stock *before* the boards arrive.
- **RTT console shim — implement and prove on Board3 (decided 2026-08-19).**
  Route the existing `ok`/`err` serial protocol over RTT (same two SWD wires
  the Tag-Connect already carries; OpenOCD speaks it) while CDC still exists
  as the fallback. This is the **gate for the next rev's USB deletion**
  (docs/hardware/next-rev-interconnect-and-led-daughterboard.md §4): v2
  carries no USB, so programming AND console ride the tag, powered by the
  car. Proving it here is risk-free — same die, same debugger, USB safety
  net. Done = `status`/`odo set`/alarm commands working over RTT on glass.

## Prove the firmware BEFORE the boards ship — `[env:board3_mule]`

Target: the bench **NUCLEO-H755ZI-Q** — the **same STM32H755 die as U1**, with
every Board3 signal on the Zio headers. Same firmware as `board3` except the
clock/supply block: the -Q board is **SMPS-powered**, so the env's
`DASH_MULE_H755Q` selects a direct-SMPS clock config. Being the real die, the
mule also **rehearses the one-time `BCM4=0` option-byte step** before Board3
needs it, and proves USB-on-HSI48+CRS on the exact silicon.

**The LDO hang is nastier than a wrong clock block (hit for real 2026-08-12).**
The stock variant header hard-defines `USE_PWR_LDO_SUPPLY`, which is consumed
by `ExitRun0Mode()` — called from the startup file **before `main()`**, so a
sketch-side `SystemClock_Config` override never runs. And the H7 supply config
is **write-once until the next power-on reset**: the first post-POR boot
latches LDO and spins forever at the ACTVOSRDY wait (2-instruction loop, empty
stack, looks bricked). Warm resets and reflashing do **NOT** recover it — an
earlier revision of this card said "recover by flashing under reset", which is
wrong for this hang. Recovery = fixed firmware + a **full power cycle**. The
trap stayed invisible through all of first-day bring-up because warm resets
inherit whatever the last POR latched (the factory demo's correct SMPS
config); the first true power cycle exposed it. Fix lives in the repo-local
variant `boards/variants/H755ZI_Q_MULE/` (selects `USE_PWR_DIRECT_SMPS_SUPPLY`
under `DASH_MULE_H755Q`, making `ExitRun0Mode()` a no-op so the sketch's
SystemClock_Config makes the first — correct — supply write). `board3` (real
board, LDO-wired VCORE) stays on the stock upstream variant deliberately.

**`BCM4=0` without STM32CubeProgrammer** (how it was actually done, 2026-08-12
— CubeProgrammer isn't installed and winget doesn't carry ST tools): PIO's own
OpenOCD writes the option byte. BCM4 is FLASH_OPTSR bit 22 (verified in ST's
own `stm32h755xx.h`); read OPTSR first, clear bit 22, write masked:
`openocd -f interface/stlink.cfg -f target/stm32h7x.cfg -c init `
`-c "stm32h7x option_write 0 0x20 0x1b86aaf0 0x00400000" `
`-c "read_memory 0x5200201C 32 1" -c shutdown` — the readback must show the
new value in OPTSR_CUR (0x1b86aaf0 from the factory 0x1bc6aaf0). Install
CubeProgrammer before Board3 arrives to rehearse the documented command; a
re-run with BCM4 already 0 still exercises the full tool flow.

## CAN live-bus session (parts-gated: transceivers on reorder)

The Ford dialect (plan 2026-08-15-001) is fully host-proven — 15/15 suite
including the sim round-trip, emitter dry-run byte-matched to golden vectors.
The live session tests only the electrical path and the bit-timing assumption:

1. SN65HVD230-class transceiver on FDCAN1 (mule: TXD→CN7-4/PB9, RXD→CN7-2/PB8,
   3.3 V CN8-7, GND CN7-8); CANable clipped on the same CANH/CANL.
2. Feed + emitter: `wsl -- /tmp/can_sim_feed | <penv python> tools/can_emit.py`
   (build the feed per its docstring). Glass shows CAN-real engine vitals;
   TRACK lap timing stays sim (mixed-source glass, by design).
3. `status` → `can=<accepted>,<lost>,<ms>,bench` counting up, lost=0
   steady-state. `accepted` counts only decoder-consumed frames (the four
   dialect IDs), and the 4th field is the ACTIVE staleness semantics — check
   it says what you built (`bench` on the bench; a car flash must say `car`,
   or a loose connector will hand the glass to the simulator's fiction).
   `cantest` still passes on bus 2 (it skips other traffic within its window,
   so it coexists with the emitter stream). Lap timing under CAN speed:
   LAST/BEST/DELTA populate normally — only the operator's serial
   `set speed` taints a lap. On the bench the emitter replays the sim's own
   speed so laps read true; in the car this is real speed over the fictional
   HPR track model, so treat BEST as demo-only until RaceCapture brings
   measured lap timing.
4. CANable capture at 500 kbps decodes the frames cleanly → referees the
   FDCAN 80 MHz kernel-clock bit-timing assumption (dash_can.h header).
5. Kill the feed: within ~500 ms the emitter stops TXing and the sim reclaims
   the glass (bench semantics) — the dead-feed safety observed live.
6. Negative probe: inject one 29-bit-ID frame from the CANable
   (`python -c` one-liner or cansend) → `accepted` must NOT advance (the
   drain's standard-ID guard, unreachable from the host suite, proven live).

**Car-side notes (M50D GWM):** the pack's instruction sheet is vendored at
`docs/hardware/datasheets/M6017M50D-IS-1850-0625.pdf` (39 pp.; connector
legend p.10 — GWM is C9, the dash's bus tap is harness item W, "Blunt cut
HS CAN"; it prints NO CAN message table, which is what keeps the 0x270-set
official-sibling). The pack's four harness-mounted CAN termination
resistors are required; CAN stubs stay within 20 in of C9/C175B/blunt leads.
First car contact: sniff the GWM leads at 500 kbps — confirm the 0x270-set,
then signal plausibility (AFR ≈ 14.7 warm idle, ECT/EOT plausible °C,
VBAT ≈ 14 V running) so scaling is verified, not just presence.
Two provenance probes while in there (DBC CM_ comments carry the full
story): **EOP vs rpm at warm idle** — a real sender sweeps a smooth
viscosity/rpm curve, a switch-backed model plateaus at a canned value,
and the PCM-regulated Gen 3+ pump steps between setpoints; the shape
decides whether the OILP alarm can be trusted or needs a dedicated
sender on a later dialect. And **EOT lag/smoothness** — community
reports it PCM-inferred on some applications. ECT is CHT-derived by
design (no wet sensor on a Coyote): expect it above radiator-water
readings under load and threshold the coolant alarm accordingly. Tracked
non-blocking: draft + submit the Ford Techline question on the M50D GWM
message set — Techline 1-800-367-3788, printed on every page of the sheet
(the sniff stays the final referee).

**Bench trap:** the Nucleo's ST-LINK VCP is USART3 on **PD8/PD9** — the center
and left CS pins. Open the two VCP solder bridges (Nucleo-144 user manual)
before the panel session, or the ST-LINK's TX fights left CS.

**Exact bridge list (UM2408 Rev 4 + verified live on Kevin's board 2026-08-12
by SWD pull-wiggle float test — pin follows internal pulls = floating):**
- **SB52** (PA7 ↔ PHY RMII CRS_DV): **measured CONNECTED and driven low** on
  this board — must be wicked open before panels. Near the PHY (U15) / RJ45.
- **JP6** (PB13 ↔ PHY RMII TXD1): a jumper cap, not solder — pull the cap.
  PB13 measured floating (an unpowered-input stub is invisible to the test,
  so check the cap visually). Near the Ethernet area.
- **SB16 + SB17** (ST-LINK ↔ PD8/PD9, VCP): ship ON per UM2408 §6.10. PD9
  measured floating with COM7 closed — the ST-LINK only drives it while a
  host app has the VCP open, so it *looks* safe until something opens COM7
  mid-session. Open both. In the ST-LINK section near CN1.
- JP7 (PA2/RMII MDIO) touches nothing of ours — leave it.
- UM2408 warning worth keeping: never connect CN13 before the board is
  powered (current-injection risk); ST-LINK cable first, always.

Panels on the existing FFC breakouts at the *real* Board3 pins:

| Session | Wires | Proves |
|---|---|---|
| Panels + dash | FFC breakouts → PA5/6/7+PD8/PD11, PB13/14/15+PD9/PD12, PE2/5/6+PE3/PD13; BL on external 5 V | the whole render path on H7 silicon at Board3's pins |
| USB CDC | USB device connector | serial protocol + `/dash` skill over CDC (never bench-run on H7) |
| Telltales | AW9523B breakout ×2 on PB10/11 (strap 0x5B/0x5A) | the I2C lamp glue, which has **never had hardware** |
| Odometer | I2C FRAM breakout at 0x50 on PB10/PB11 (3.3 V) | **PROVEN 2026-08-14**: breakout on CN10-32/34 + CN8-7, banner flips to `FRAM (FM24CL64B)`, `odo set 8675.3` survived a full power cycle (read back 8676.2 — the sim keeps earning miles). Reconciled 2026-08-12: this row used to promise "EEPROM emulation in H7 flash" — no such backend exists; the ladder is FRAM (FM24CL64B protocol, 0x50, 16-bit addressing — MB85RC256V is protocol-identical) → RAM shadow (bare board, banner says so, not persistent) |
| Button | jumper wire CN7-1 (PC6) → CN7-8 (GND) | **PROVEN 2026-08-14**: tap = mode toggle (trip untouched), hold = trip reset (mode untouched), hand-wire bounce absorbed by the 30 ms debounce — no phantom toggles |
| QSPI | (optional) W25Q256 breakout PB2/PF6-9/PG6 | the JEDEC probe's ok path; unwired it proves the failure path boots on |

After a clean mule soak, first contact with Board3 tests only three things:
the 25 MHz clock block, the CM4 option byte, and real copper at speed.
(All three are now done — see the bring-up debt list above.)

## Known-tight spots (do not "discover" these)

- P1/P2 screw terminals sit 0.65 mm from the CAN transceivers (U8/U9) — care
  with the iron during the THT pass.
- U1×X1: crystal pad 0.243 mm from `/QSPI_IO1` — inspect after reflow.
- Zero reference designators print anywhere on the board (deliberate).
  Identification is the CPL + the functional silk labels (TT1–8, BTN1–4,
  RESET/BOOT, CAN1/2 + H/L, TERM1/2, USB, SWD, LEFT/CENTER/RIGHT, 5V ONLY).

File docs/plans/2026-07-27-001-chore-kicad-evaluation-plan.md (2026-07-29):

---
title: KiCad Evaluation Against EasyEDA - Plan
type: chore
date: 2026-07-27
topic: kicad-evaluation
artifact_contract: ce-unified-plan/v1
artifact_readiness: implementation-ready
product_contract_source: ce-brainstorm
execution: code
superseded_by: docs/plans/2026-07-27-002-fix-board3-fab-ready-in-kicad-plan.md
---

# KiCad Evaluation Against EasyEDA - Plan

## Goal Capsule

- **Objective:** Decide whether Board3-class PCB work moves from EasyEDA Pro to KiCad, by importing Board3 as a parallel copy and measuring whether an agent can drive routing, creation, and design review without a human at a GUI.
- **Product authority:** Kevin owns the verdict. This document owns the scope and the bars. Where the two disagree, Kevin wins and the document is corrected.
- **Open blockers:** None blocking a start. One unit-scoped blocker: the 107→94 net drop across save must be explained before U5 or U7 treats this board as the routing baseline.
- **Execution profile:** Investigative. Units produce measurements and a verdict, not shippable firmware. Tooling written along the way is disposable if the verdict goes against KiCad.
- **Stop conditions:** Stop and report if conversion fails on both Windows and WSL2 (U2 is a kill gate); if any step would modify the EasyEDA Board3 project; or if a router writes a board that fails connectivity against the netlist.
- **Tail ownership:** Kevin runs anything that touches EasyEDA or requires the KiCad GUI. Everything else is agent-run.

---

## Outcome

**This plan is closed. Its question was answered, and the work moved to
[2026-07-27-002-fix-board3-fab-ready-in-kicad-plan.md](2026-07-27-002-fix-board3-fab-ready-in-kicad-plan.md).**

The evaluation was cut short by its own result: once conversion, review and
routing all worked, the question stopped being *whether* to move and became
*what it takes to finish the board in KiCad*. The head-to-head against EasyEDA's
autorouter (R17, R18, U7) was never run and is not planned — it would settle a
comparison nobody needs settled.

What each bar produced:

| Bar | Result |
|---|---|
| R1 conversion fidelity | **Pass** — 144 footprints, 107 nets, zero pad loss |
| R2 schematic | **Pass** — 1.15 MB `.kicad_sch` |
| R12/R13/R14 review | **Pass** — 128 findings, calibrated, repeatable |
| R5 headless routing | **Pass** — no GUI at any point |
| R7 connectivity | **78%** — 208 of 266 airwires closed, no nets dropped |
| R6 DRC-clean | **Fail as written** — 37 new violations. The bar was unachievable: the source board carries 41 pre-existing violations, so no routed board can be absolutely clean. A delta bar belongs in the successor plan |
| R10/R11 creation | Not reached |
| R15/R16 JLC pipeline | Not reached — carried into the successor plan as a deliverable rather than a bar |
| R17/R18 head-to-head | **Not pursued** |

Two corrections a reader should not have to reconstruct. **The conversion route
below is wrong**: U2, U12 and KTD9 describe PADS ASCII, which was retired after
it silently dropped every through-hole pad. The working route is
`File → Save as → epro (V2 format)` into KiCad's EasyEDA Pro project importer.
And **the 107→94 net-drop question is void** — it described the retired PADS
baseline, which had 94 nets where the current one has 107.

The durable findings are in `docs/solutions/`:
[migration data loss](../solutions/integration-issues/easyeda-pro-to-kicad-migration-silent-data-loss.md),
[zone refill](../solutions/developer-experience/refill-zones-before-measuring-a-headlessly-routed-board.md),
[reviewer calibration](../solutions/design-patterns/calibrate-an-automated-reviewer-on-a-confirmed-defect.md).
Unit bodies below describe the work as planned, not as executed; git is the
record of what ran.

---

## Product Contract

### Summary

Import Board3 into KiCad as a non-destructive parallel copy, route it with headless file-based tooling driven by an agent, and run automated design review over the result. The outcome decides whether the next board spin moves; EasyEDA Board3 stays authoritative throughout.

### Problem Frame

The EasyEDA MCP bridge can edit what already exists but cannot create. Every failure that has cost real time is a write that brings a new primitive into existence: `schematic_place_component` times out at 15 s, `pcb_place_component` cannot complete `PCB_PrimitiveComponent.create()`, `modify_primitive` silently ignores `deviceUuid` and writes only BOM metadata, `pcb_autoroute` has no API implementation on Pro v3, and copper pour creation is unreachable through any argument shape. Placement and device swaps are permanently manual.

Two further costs compound it. Several wrapped tools report success without acting — `delete_primitive` returns `success: true` on components that survive, and `SCH_PrimitiveComponent.modify` with a partial state corrupts `otherProperty` while looking like it worked. And every schematic-side call depends on which browser tab has focus, with no programmatic way to detect or change it; a blank canvas capture and an empty region are indistinguishable.

Board3 carries roughly 274 unrouted airwires across ~100 nets. The inability to route programmatically is what forced the question.

### Key Decisions

**Judge headless drivability, not routing quality.** KiCad's own IPC API is PCB-editor only in versions 9 and 10, cannot export or plot, and requires a running GUI instance — on an API-to-API comparison it is weaker than EasyEDA's bridge. The evaluation therefore tests the file layer: designs stored as S-expression text, edited by scripts, verified by git. The relevant difference is architectural, not a question of who wrote better tool wrappers.

```mermaid
flowchart TB
  subgraph EasyEDA_path[EasyEDA today]
    A1[Agent] -->|MCP bridge| B1[Browser extension]
    B1 -->|requires focused tab| C1[EasyEDA Pro session]
    C1 --> D1[(Cloud project)]
    H1[Kevin] -->|places parts, routes, pours| C1
  end
  subgraph KiCad_path[KiCad under test]
    A2[Agent] -->|read and write| F2[.kicad_sch / .kicad_pcb]
    F2 --> R2[Headless router CLI]
    R2 --> F2
    F2 --> V2[git diff + DRC + automated review]
  end
```

The human sits on the critical path by construction in the first path and nowhere in the second. That is the claim under test.

**Parallel copy; EasyEDA stays authoritative.** Conversion is one-way and non-destructive. Round-trip conversion accumulates error, so nothing returns to EasyEDA.

**Route first, parts later.** The JLC/LCSC part-preparation cost is a chore to absorb, not a gate that can fail the evaluation. Measuring it comes after the routing and creation bars resolve.

**Automated design review is in scope.** Read-only analysis of the design files expands the test from "can KiCad be driven" to "can the design loop be driven," and produces a PR-time surface this repo can use.

**A converter failure is not a KiCad verdict.** The two weakest links in the chain are the EasyEDA-to-KiCad conversion path, not KiCad itself. Results are attributed accordingly.

**The routing bar is a head-to-head, not an absolute number.** EasyEDA's in-app autorouter sets the completion baseline on the same board, and KiCad must match or beat it. An absolute coverage target would be arbitrary; the incumbent's own result is not. The baseline runs on a duplicate so the original project stays untouched.

### Requirements

**Import and baseline**

- R1. Board3's PCB converts to KiCad with footprints, tracks, vias, zones, nets, board outline, and silkscreen intact.
- R2. Board3's schematic reaches KiCad; a one-time manual GUI import is acceptable.
- R3. The converted design is committed to git before any edit, establishing a diffable baseline.
- R4. The EasyEDA Board3 project is not modified for the duration of the evaluation.

**Agent-driven routing**

- R5. An agent routes nets by invoking a router on the board file and reading the result back, with no GUI interaction at any step.
- R6. Routed output passes KiCad DRC.
- R7. Post-routing connectivity matches the netlist, with no dropped or shorted nets.
- R8. The routing bar is reachable through more than one router; no single tool's failure ends the evaluation.
- R9. Signal-integrity-sensitive nets are excluded from autorouting and reserved for deliberate routing.

**Agent-driven creation**

- R10. An agent adds a component to the schematic and places its footprint on the board by writing files directly.
- R11. Every write is confirmed by reading the file back or by git diff, never by canvas screenshot.

**Automated design review**

- R12. Automated review runs against the converted design and produces findings without KiCad installed.
- R13. The reviewer is calibrated against Board3's known USB VBUS inrush violation before its findings on unknown issues are trusted.
- R14. Review runs as a repeatable command, with PR-time automation as the target shape.

**Manufacturing pipeline**

- R15. LCSC part numbers survive to a JLCPCB-format BOM and CPL.
- R16. Per-part preparation cost is measured and recorded, whether or not it proves acceptable.

**Baseline comparison**

- R17. EasyEDA's in-app autorouter establishes a completion baseline on a duplicate of Board3, leaving the original project unmodified.
- R18. The routing bar is met when KiCad's agent-driven completion matches or exceeds that baseline over the same net set.

**Verdict**

- R19. The evaluation ends in a written verdict citing evidence for each bar.
- R20. Every bar records a result, including "not reached."

### Key Flows

- F1. Import and baseline
  - **Trigger:** KiCad 10 installed; Board3 exported from EasyEDA Pro.
  - **Steps:** Convert the PCB headlessly; import the schematic through the GUI; commit both to git untouched.
  - **Outcome:** A KiCad copy of Board3 with a clean baseline commit.
  - **Covered by:** R1, R2, R3, R4

- F2. Agent routing loop
  - **Trigger:** Baseline commit exists.
  - **Steps:** Agent builds the net list excluding SI-sensitive nets; invokes a headless router on the board file; runs DRC and a connectivity check; iterates or falls back to a second router.
  - **Outcome:** A routed board with a DRC result and a record of which router produced it.
  - **Covered by:** R5, R6, R7, R8, R9

- F3. EasyEDA baseline
  - **Trigger:** Board3 duplicated inside EasyEDA Pro.
  - **Steps:** Run the in-app autorouter on the duplicate over the same net set the KiCad side was offered; record completion count and DRC result.
  - **Outcome:** A completion figure the KiCad result is judged against.
  - **Covered by:** R17, R18

- F4. Review calibration
  - **Trigger:** Converted design exists; routing may or may not have run.
  - **Steps:** Run automated review against the unfixed design; check whether the known inrush violation appears in its findings; only then read its other findings.
  - **Outcome:** A review capability marked calibrated or uncalibrated.
  - **Covered by:** R12, R13, R14

### Acceptance Examples

- AE1. **Covers R8.** Given the first router produces a board that fails DRC, when the agent falls back to a second router through a different file interchange, then the routing bar is still reachable and the result records which router produced the output.
- AE2. **Covers R13.** Given automated review runs on the converted design before any fix lands, when it does not independently report the USB VBUS inrush violation, then its other findings are recorded as uncalibrated and the review bar is marked not met.
- AE3. **Covers R1, R2.** Given the headless converter fails on Windows, when the conversion is retried under WSL2 and still fails, then the outcome is recorded as a converter limitation and the evaluation continues from a manually imported board rather than terminating.
- AE4. **Covers R9.** Given the router is offered the full net list, when that list is constructed, then USB D+/D− and QSPI nets are excluded by name before the router runs.
- AE5. **Covers R11.** Given an agent reports a successful schematic write, when the claim is checked, then it is checked by git diff or file read — a canvas capture is not accepted as evidence.

### Scope Boundaries

- The USB VBUS inrush fix stays un-landed in both tools until the verdict. Neither board diverges during the evaluation.
- The 4-layer stackup is already applied in the design; what remains un-landed is the write-up of why 6-layer was rejected. That document is not this plan's work.
- Board1 and Board2 stay locked in EasyEDA. Nothing migrates but the Board3 copy.
- The EasyEDA baseline run is a measurement, not design work. Its routed output is discarded; no copper from it lands on a real board.
- No round-trip back to EasyEDA at any point.
- Not repairing or extending the EasyEDA bridge.
- Not authoring a new KiCad MCP server. The evaluation measures what already exists.
- Paid and cloud routers are fallbacks recorded for later, not part of the first pass.

### Dependencies and Assumptions

- KiCad 10.0.5 is installed at `C:\Program Files\KiCad\10.0\`, with a bundled Python 3.11.5. `kicad-cli` is not on PATH, so scripts invoke it by absolute path or PATH is amended once.
- `epro2kicad` is unused. It requires a `.epro` export EasyEDA Pro v3 does not produce; the route is PADS instead, per KTD9. WSL2 Ubuntu remains available as a fallback host but was not needed.
- Board3 as converted: 140 footprints, 3147 track segments, 122 vias, 6 zones, 4 copper layers, 250.25 × 50.25 mm outline, 93 of 94 nets carrying copper. These are measured, not estimated, and supersede the earlier net figures.
- The 4-layer stackup is already applied in the design — confirmed independently by the PADS export's `MAXIMUMLAYER 4` and ODB++'s four copper layers.
- KiCad's schematic importer accepts Altium, CADSTAR, EAGLE, EasyEDA, LTspice, and OrCAD — not PADS-LOGIC, which is the format `Schematic3.txt` uses. R2 has no confirmed path.
- The IPC API is PCB-only in KiCad 9 and 10, with export and headless operation arriving in KiCad 11. The evaluation does not depend on it.
- Automated review requires Python 3.10+; the workstation has Python 3.13.
- Freerouting requires a JRE or its Docker image; WSL2 makes the container the lower-friction path.
- Board3's pin count exceeds the 650-pin free tier of at least one candidate router.

### Outstanding Questions

**Resolve before U5 or U7 runs**

- Net count drops 107 on import to 94 after save. Most likely KiCad pruning empty nets, but that is a hypothesis. Silent net loss is what R7 exists to catch, so it must be confirmed before this board is trusted as the routing baseline.

**Deferred to planning**

- R2's schematic path. No KiCad importer reads PADS-LOGIC, and EasyEDA's Altium schematic export is Protel ASCII, which the Altium schematic importer will reject the same way its PCB counterpart did. The EasyEDA export menu was truncated below `T/DISA 4001` — check the remainder with a schematic tab active before concluding no path exists.
- How the EasyEDA duplicate is produced, and whether its autorouter run needs the same layer stackup the KiCad copy uses for the comparison to be fair.

- Which router runs first — the `.kicad_pcb`-native tooling or Freerouting through DSN/SES.
- Whether automated review runs first as a CLI, as a Claude Code plugin, or as a GitHub Action.
- Whether the creation bar (R10) is tested with a real LCSC part or a generic one.

### Sources and Research

| Tool | Role in the evaluation | Agent-drivable | Cost |
|---|---|---|---|
| [Freerouting](https://github.com/freerouting/freerouting) | Router candidate; DSN/SES, [headless CLI](https://github.com/freerouting/freerouting/blob/master/docs/command_line_arguments.md), REST API, Python SDK, Docker | Yes | Free |
| [KiCadRoutingTools](https://github.com/drandyhaas/KiCadRoutingTools) | Router candidate; `.kicad_pcb` in/out, planes and via placement, ships a Claude skill | Yes | Free |
| [kicad-happy](https://github.com/aklofas/kicad-happy) | Automated design review; parses S-expressions without KiCad installed | Yes | Free |
| [epro2kicad](https://github.com/enkhbold470/epro2kicad) | Rejected — needs a `.epro` export EasyEDA Pro v3 does not produce | n/a | Free |
| [DeepPCB](https://deeppcb.ai/deeppcb-api-your-pcb-design-ai-agent/) | Fallback router; place and route via API, 8 layers / 1200 airwires | Yes | ~30 credits/hr |
| [Quilter](https://www.quilter.ai/blog/the-true-cost-of-pcb-tools-in-2026-altium-vs-kicad-vs-quilter) | Fallback; physics-driven place and route, cloud | Unconfirmed | Pay on download |
| [Electra](https://konekt.com/products/) | Fallback; DSN in, batch mode and TCL-scriptable strategy files | Partly | Commercial |
| [KiCad AI Assistant](https://github.com/paul356/KiCad-AI-Assistant) | Creation candidate; schematic editing tools, standalone MCP server | Yes | Free |

Independent testing of DeepPCB by EEVblog was unflattering; Quilter's published comparisons against KiCad are authored by Quilter. Treat both as unverified until measured here.

Existing EasyEDA constraints this evaluation is measured against are recorded in [docs/solutions/developer-experience/easyeda-bridge-schematic-authoring-workflow.md](docs/solutions/developer-experience/easyeda-bridge-schematic-authoring-workflow.md).

---

## Planning Contract

Product Contract unchanged. Requirements R1–R20, flows F1–F4, and acceptance examples AE1–AE5 carry over from the brainstorm verbatim. Execution corrected two factual premises the Product Contract rested on — the routing volume is ~274 airwires rather than nets, and the 4-layer stackup is already applied — but neither changes a requirement.

### Key Technical Decisions

KTD1. **Headless invocation is the rule; the GUI is a recorded exception.** Every step runs from a script or CLI except the one-time EasyEDA Pro schematic import (KiCad's importer has no headless path) and the EasyEDA baseline autoroute. Both exceptions are units of their own so the GUI dependency stays visible rather than diffusing through the plan.

KTD2. **Conversion is attempted on Windows first, WSL2 second, and the fallback is a result — not a silent retry.** `epro2kicad` reports Windows as untested. Which host succeeds is a finding the verdict depends on, so U2 records the Windows attempt's outcome even when it fails and WSL2 carries the run.

KTD3. **Net classification lives in a checked-in data file, not inline logic.** R9's exclusion of USB D+/D− and QSPI from autorouting is a design claim someone will want to audit. A `tools/kicad_netclass.json` listing excluded nets by name is reviewable in a diff; a regex buried in a script is not.

KTD4. **Board files are committed under `kicad/`.** R11 makes git diff the verification mechanism, which only works if the design is in the repo. Cost is a few MB of board files in a firmware repo; the alternative — a sibling repo — forfeits the verification story the evaluation is testing.

KTD5. **Two routers, tried in order, with the winner recorded.** `KiCadRoutingTools` operates on `.kicad_pcb` directly and is the first attempt; Freerouting via DSN/SES is the fallback. R8 requires the bar be reachable through more than one, so a first-router failure advances the plan rather than ending it.

KTD6. **Review calibration gates trust, not execution.** Automated review runs regardless, but its findings on unknown issues are not acted on until it independently reproduces the known USB VBUS inrush violation. An uncalibrated reviewer's output is recorded, not believed.

KTD7. **New tooling is Python in `tools/`,** matching the existing `make_dash_fonts.py` / `make_splash_flash.py` convention. The C host-test suite in `tests/` pins firmware invariants and is not extended by this work.

KTD8. **Both routers start from the same stripped board, and the strip is partial.** Board3 is already partly routed, some of it by hand. Leaving that copper in place would measure whether a router can finish someone else's layout — and `KiCadRoutingTools` has no push-and-shove, so every existing trace is a hard constraint that biases the result pessimistically. Stripping everything is equally wrong: it would hand the R9-excluded nets to an autorouter that must not touch them. The strip therefore removes exactly the nets offered to the router, driven by the same `kicad_netclass.json`, and U7's EasyEDA baseline starts from that identical state. Different starting copper voids the comparison entirely.

KTD9. **The conversion route is PADS ASCII, and importers must be validated before they are called.** EasyEDA Pro v3 offers no `.epro` export, so `epro2kicad` and KiCad's `EASYEDAPRO` importer are both unusable. EasyEDA exports PADS PowerPCB ASCII; KiCad reads it natively through `PCB_IO_MGR` plugin 17. Two rejected routes explain the constraints this places on the tooling: `EASYEDA` (9) on a `.eprj2` and `ALTIUM_DESIGNER` (6) on EasyEDA's Altium export — which is Protel ASCII where KiCad expects binary OLE/CFB — both terminate the process with a stack buffer overrun rather than raising, and the crash takes stdout's buffer with it, so the symptom is a silent hang. `EASYEDAPRO` (10) fails worse: it accepts a `.eprj2` without complaint and returns an empty board. Any caller of `PCB_IO_MGR.Load` therefore pins one plugin id, never iterates to find one that works, checks the container's magic bytes first, and treats an empty result as a failed conversion.
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

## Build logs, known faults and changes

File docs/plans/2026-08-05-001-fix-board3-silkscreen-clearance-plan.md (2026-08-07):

---
artifact_contract: ce-unified-plan/v1
artifact_readiness: implementation-ready
execution: code
title: Bring Board3's silkscreen to JLC's 0.15 mm pad clearance, and gate it
date: 2026-08-05
branch: fix/board3-silkscreen-clearance
---

# Bring Board3's silkscreen to JLC's 0.15 mm clearance, and gate it

## Goal Capsule

JLCPCB's DFM check returns **81 red errors** on Board3 — 50 *silkscreen to pad*
and 31 *silkscreen to hole* — and they are the only red in the report. Every
other category passes or warns.

KiCad's DRC reports **zero**, on the same board, at `--severity-all`, with
`min_silk_clearance: 0.15` and `silk_over_copper: warning` both present in the
project file.

Both statements are true. **KiCad runs no silkscreen test at all unless a
`silk_clearance` rule exists in the `.kicad_dru`** — the project-file settings
are inert on their own.

**The "199 + 199" this plan was originally scoped against is a report limit, not
a count** (see U0 and CLAUDE.md). `kicad-cli pcb drc` applies a per-error-code
limit of 199: at 0.10 mm clearance `silk_over_copper` reads 62, and from 0.15 mm
up both types read exactly 199 and stay there at 1.00 mm — where nearly all 586
of the board's silk shapes must be violating. The limit is not uniform (a probe
run reported `clearance` 514 beside three other types pinned at 199), so a count
near 199 is a lower bound until a stricter rule shows it moving. The real figure,
measured directly off the geometry, was **233 shape×pad pairs over 169 shapes**.
Every count in the original plan text below inherits that limit and should be
read as "at least".

**Done means:** silk clears every mask aperture by 0.15 mm, the rule is in the
`.kicad_dru` so the absolute CI gate enforces it, the fix lives in the footprint
libraries as well as the board's embedded copies, and JLC's DFM returns no red.

**Status 2026-08-05: silk-to-pad 233 pairs → 6**, all six documented exceptions
in the `.kicad_dru`. Board verifies 0 violations / 0 unconnected with the rule
armed; nothing electrical moved. U1–U5 are done; U6 is answered (there is no
separate silk-crossing-silk problem — see below); the JLC DFM re-submission is
the remaining confirmation.

## Why this plan exists

The work was scoped as a one-liner — add the rule with the fix — and the
measurement showed it is not. This plan exists because three things turned out
to be true that were not known when the work was requested:

1. **169 shapes / 233 shape×pad pairs, not a handful** (originally recorded as
   "199 objects", which was the report limit), spread across the whole board
   (x 28–258 mm), owned by **19 footprint types** plus 18 board-level graphics.
2. **None is an overlap.** The range is 0.031–0.1495 mm against a 0.15 mm
   requirement; the median shortfall is **36 µm**. Nothing prints on a pad
   today. The 0.0000 mm entries that appear in the DRC report are
   silk-to-*courtyard*, not silk-to-pad — a layer that is never plotted.
3. **The fab already clips it.** `tools/kicad_fab.py` passes
   `--subtract-soldermask` (verified: the silk gerber is 303,034 chars with it
   and 74,252 without). So the board is buildable and nothing shorts. What is
   wrong is that the *design* claims markings the board will not receive, and
   the clipped remainder still sits at 0 mm from the mask edge where JLC wants
   0.15 mm.

So this is a marking-quality and design-honesty problem, not a manufacturability
blocker. It is worth doing properly and it is not worth rushing.

## Key Decisions

**Trim, do not move.** Cutting the outline where it passes a pad leaves the
surviving pieces in place. Moving the outline outward keeps it continuous at the
cost of drawing a body larger than the part — which is what the assembler reads
— and Board3 is dense enough that courtyards already touch by design (U1's
decoupling ring, U12/LED6). Trimming also makes the design match what
`--subtract-soldermask` already produces, rather than diverging from it.

**Fix the library and the board.** A placed footprint is a full copy of its
library definition (CONCEPTS.md, *Embedded Footprint Copy*). A library-only fix
changes nothing that gets fabricated; a board-only fix is reverted by the next
*Update Footprints from Library*. Confirmed empirically: trimming the board
copies alone raised `lib_footprint_mismatch` from 0 to 33.

**Deletion is a per-class decision, not a global threshold.** A trial run with a
20 µm safety margin removes **28% of all silk line length**, and takes `R0603`
(31 placements) and `ERJP06F60R4V` to **zero silk**. For chip passives that is
plausibly correct — many vendor libraries carry no silk on an 0603 at all — but
it must be decided per footprint class and recorded, not fallen into by tuning a
constant.

> **Resolved, and the premise was wrong.** That trial was deleting compliant
> geometry: R0603's silk measures 0.1522 mm from its own pads, which *passes*
> 0.15 and was only being cut because the tool tested against clearance +
> margin. With that fixed and narrowing tried first, R0603 and C0805 are not
> touched at all, no footprint class loses all its silk, and total removals fall
> from 157 shapes to 22 — all on chip passives where silk between the pads
> genuinely has nowhere to go (`ERJP06F60R4V` 8, `L0603` 4, `1N5819WS` 4, LED
> types 6). The general lesson is that a threshold sweeping up compliant objects
> looks exactly like a hard design trade-off until you check which side of the
> requirement they were on.

**Polarity and pin-1 markers are never trimmed.** The 8 remaining `Polygon`
violations are on `1N5819WS` and the LED footprints. Cutting a cathode band or a
pin-1 dot destroys the meaning the marker exists to carry; those move, shrink,
or take a recorded exemption.

## What already exists

`tools/kicad_silk_trim.py` narrows, then trims, silk **lines, circles and arcs**
back from mask apertures. Exact point-to-polygon distance, 5 µm walk, boundaries
refined by bisection to 0.1 µm. It deliberately does not use
`GetEffectiveShape().Collide()`, which CLAUDE.md records as under-covering
segment midpoints — precisely this query.

Measured in place: silk-to-pad **233 pairs → 6**.

**Two design corrections it now encodes, both of which were destroying good
markings.** *Narrow before trimming* — clearance is edge-to-edge on a stored
centreline, so reducing a line's width buys clearance with no geometry change;
that alone fixes 50 shapes, including all 24 board-level outlines around
C63/C64/C65 that the earlier version deleted outright. It is available whenever
the centreline sits ≥ 0.225 mm out (0.15 clearance + half of JLC's 0.15 mm
minimum printable width). And *only touch what actually violates* — testing
against clearance + margin rather than clearance deleted **137 compliant
shapes**, every R0603 outline among them at a measured 0.1522 mm: above the
requirement, below requirement + margin.

Two traps are already paid for and encoded in its source:

- `GetEffectivePolygon()` takes a layer argument in KiCad 10. An earlier
  revision swallowed the `TypeError`, so every pad returned no rings and the
  tool reported **"0 lines need trimming"** on a board with 233 violating pairs.
- That polygon is *inscribed* in a round pad, so distances measured against it
  run a few microns optimistic. Trimming to exactly 0.15 mm left residual
  violations of ~3.8 µm — correct arithmetic against a slightly wrong shape.
  Hence `MARGIN_MM`.

## Implementation Units

### U1. DONE — angular clipping for circles and arcs

68 violations remain and 42 of them are `Circle` (24) or `Arc` (18). Extend the
trimmer to clip in angle rather than in `t`: for each pad keepout, compute the
angular interval(s) of the circle/arc that fall inside it, and emit the
complement as one or more arcs.

The `SW-TH_4P` footprint (6 placements) is the main consumer — its 14 circles
are the switch body, and each crosses all four PTH pads.

**Verify:** circle/arc violations reach 0 on a copy; no line count changes.

### U2. DONE — deletion policy per footprint class

Decide, and record in the spec, what "trimmed" means for each of the 19 types.
Three classes to settle:

- **Chip passives** (`R0603`, `L0603`, `C0805`, `ERJP06F60R4V`) — silk between
  the pads has nowhere to go. Decide: no silk, or silk only on the outer edges.
- **Multi-pin ICs** (`SOIC-8`, `LQFP-144`, `WSON-8`, `SOP-8`) — trim the body
  sides between pins, keep the ends and the pin-1 feature. This is the normal
  IPC-7351 form and should look unremarkable.
- **Connectors and switches** (`SW-TH_4P`, `FPC-SMD`, `DC-IN-TH`, `USB-C`) —
  keep the body outline recognisable; these are the parts an assembler orients
  by.

**Verify:** a rendered before/after of every affected footprint, reviewed by
eye. Silk exists to be read; a DRC number cannot tell you it is still legible.

### U0. RETIRED 2026-08-05: the blocker was the detector, not the board

**Everything below this heading is superseded. It is kept because the reasoning
was sound given what it was told, and the failure was upstream of it.**

`kicad_silk_mirror.silk_signature()` had three bugs, each independently able to
manufacture the divergence U0 records:

1. It subtracted the footprint's **position but never its rotation**, so the
   four rotations of one library part fingerprinted as four geometries. That is
   literally the "C0805, 11 instances, 4 distinct" figure below — C0805 has
   **one** geometry, placed at 0/90/180/270.
2. It compared **exact integers**. The trimmer computes cut points in absolute
   board coordinates and rounds to nanometres, so one cut on two placements can
   land 1 nm apart. Measured on SOIC-8: 26 shapes each, worst delta **1 nm**.
3. For **polygons** it fingerprinted `GetStart()`/`GetEnd()`, which are not a
   polygon's outline and returned raw board coordinates — "local" deltas of
   50–312 mm on parts a few mm across. Every type reported divergent after the
   first two were fixed was one carrying a polarity band or pin-1 marker.

With all three fixed, **all 30 types mirror cleanly** and the board holds DRC
0/0. Own-pad scope (`--scope own`, now the default) introduces **zero** new
divergence: the trimmed board and the pristine board produce the same result.

The sign in fix 1 is validated rather than assumed — un-rotating by *+angle*
reproduces the `.kicad_mod`'s own coordinates 31/31 on R0603 and 11/11 on C0805
at all four rotations, while *−angle* matches only the 0°/180° instances. The
library file is the footprint-local form, so it is the ground truth.

**The lesson worth keeping is not about silkscreen.** A tool reported a property
of the board; the property was a property of the tool; and the campaign was
reverted on it. The report even looked plausible — "instances of one type
genuinely have different neighbours" is a true sentence, which is what made the
false reading survive review. What would have caught it in one step: C0805's
four "distinct geometries" were exactly its four rotations, and R0603's were
too. A grouping that lines up perfectly with an obvious confounder is a bug
until proven otherwise.

<details>
<summary>Superseded original text of U0</summary>

### U0. BLOCKER, found 2026-08-05: per-instance trimming defeats U3

Attempted in this order — U1 (angular clipping) landed, the trim ran on the
board, then the mirror was written. It got as far as **8 violations** (reported
against a saturated "199" before, so the ratio was meaningless)
before U3 exposed a contradiction the plan did not anticipate.

**Trimming each placement against its neighbours makes instances of one
footprint type diverge.** After the trim, `C0805` had **11 instances with 4
distinct silk geometries**; eight more types diverged the same way. That is
*correct per-board geometry* — each placement really does have different
neighbours — and it is structurally incompatible with a single library
definition. Route 1's premise ("fix the library and every instance inherits")
only holds if the trim depends solely on the footprint's **own** pads.

So the two goals cannot both be met by the current trimmer:

| | Clearance correct everywhere | Library-mirrorable |
|---|---|---|
| Trim vs. all nearby pads | yes | **no** — instances diverge |
| Trim vs. own pads only | partially | yes |

**The redesign this implies.** Trim against the footprint's own pads only —
that is a property of the type, identical for every placement, and mirrors
cleanly. Then handle the residue (silk close to a *neighbouring* part's pad)
separately: as board-level per-instance edits, or by moving the parts, or by
accepting it with a recorded reason. Measure the residue first; it may be small
enough that the type-level fix does nearly all the work.

`tools/kicad_silk_mirror.py` already reports divergence rather than silently
picking a winner, so it will confirm when the redesign has fixed this: the
divergent list must be empty before any mirror is written.

The board was reverted; the gate is back to 0 violations / 0 unconnected. The
trimmer and the mirror are landed and unapplied.

</details>

### U3. DONE — mirror into the footprint libraries

Apply the same geometry to `kicad/board3/*.pretty/*.kicad_mod` so future
placements inherit it. Library coordinates are footprint-relative and the placed
instances are rotated, so this is a transform, not a copy.

**Verify:** `--schematic-parity` clean and `lib_footprint_mismatch` back to 0 —
that count is the instrument for this unit, and it is already known to respond
(0 → 33 when the board was trimmed alone).

### U4. DONE — board-level graphics

18 violations belong to no footprint. Handle directly on the board; there is no
library half.

### U5. DONE — add the rule and close the gate

```
(rule jlc_silk_to_pad
  (constraint silk_clearance (min 0.15mm)))
```

Add to `kicad/board3/*.kicad_dru`. This is what makes the check exist at all,
and the CI DRC gate is absolute, so it must go in **with** a clean board rather
than before one.

**Verify:** `silk_over_copper` 0; `tools/kicad_verify.py` 0 violations, 0
unconnected; fab package regenerated and re-submitted to JLC's DFM with no red.

### U6. ANSWERED: `silk_overlap` is not silk crossing silk

The premise was wrong. Resolving every finding's item **uuid** through `pcbnew`
rather than reading its description shows `silk_overlap` pairs silk with
`F.Courtyard` rectangles and Component Marking Layer fields — and, before the
fix, with pads. It is not a silk-to-silk problem, and there is nothing separate
to settle.

What it did expose is that the constraint is over-broad by default: neither a
courtyard nor the Component Marking Layer is plotted (`kicad_fab.py` exports 11
layers and Courtyard is not among them), so those findings can never change the
board JLCPCB builds. Scoping the rule with `(condition "B.Type == 'Pad'")` takes
it from 18 + 199 to 9 + 0 and leaves exactly the class JLC checks. Both 199s
there are the report limit, not counts.

Two mechanics worth reusing, both already paid for elsewhere in this repo:
DRC's item **descriptions are inconsistent** — "Pad 2 [/GND] of U9 on Top Layer"
for some findings and "Rectangle of U1 on F.Courtyard" for others — so parsing
them mis-attributed the findings twice. The **uuid maps exactly to the object in
the file** and settled it in one pass. And the reported `pos` for a rectangle is
its first corner, not its centre: reading it as a centre made a genuine 0.0000 mm
overlap look like an impossible 13 mm-away collision.

## Scope Boundaries

**In:** silkscreen geometry, the `.kicad_dru` rule, the footprint libraries, the
trimmer.

**Out:** ~~the `Silkscreen line width` warnings in JLC's report (25 items inherit
the board default of 0.1 mm against JLC's 0.15 minimum)~~ — measured and
answered above; the premise was false and the `.kicad_pro` defaults are fixed.
Also out: `Solder mask opening exposing trace` (52) and `Negative
soldermask expansion` (80) from the same DFM report, which are the U53 mask
family and want their own measurement.

## Success Criteria

1. ✅ `silk_over_copper` **0** with the rule active, measured in place —
   `kicad_verify.py` reports 0 violations / 0 unconnected at `--severity-all`
   with `jlc_silk_to_pad` armed. Six residual cases are scoped exceptions in the
   `.kicad_dru`, held to their measured worst (0.09 mm) rather than muted.
2. ✅ `lib_footprint_mismatch` **0** — library and board agree; 17 `.kicad_mod`
   files rewritten, 13 left alone because they already matched.
3. ⬜ **JLC DFM returns no red on silkscreen** — the remaining confirmation, and
   the only criterion this repo cannot self-assess. Re-submit the fab package.
4. ⬜ Every affected footprint reviewed by eye; no part left unidentifiable.
   Silk exists to be read and a DRC count cannot tell you it still is.
5. ✅ No regression: 150 footprints, 229 nets, 2780 tracks, 238 vias, 7 zones,
   660 pads — identical before and after, as silk edits must be.

### Silkscreen to hole: 30 red, and the recommendation is to leave them

JLC's DFM on the 2026-08-05 package: **81 red → 35** (silkscreen-to-pad 50 → 5,
silkscreen-to-hole 31 → 30). Silkscreen is still the board's only red; every
other category is 0.

Silk-to-hole barely moved **by construction**. The rule added in U5 is scoped
`B.Type == 'Pad'`, and a via is not a pad, so 238 vias were never measured.
Measured now: **32 collisions, every one against a via**, several negative
(silk running up to 0.198 mm into the hole).

**They are all over TENTED vias, so there is no open barrel for ink to reach.**
Three independent measurements agree:

- `F_Mask.gbr` carries **642 regions against 639 pads on F.Mask** — the
  difference is exactly U53's 3 explicitly untented test-point vias, and **none
  of the 3 is involved in a silk collision**.
- The 24 colliding vias are 22 `FROM_RULES` + 2 explicitly `TENTED`; none is
  `NOT_TENTED`.
- Every via on the board drills **0.250 mm** (237) or 0.200 mm (1), and all 24
  colliding ones are 0.250 mm. JLCPCB's own via-covering page puts reliable full
  coverage at "**0.4 mm or less and no larger than 0.5 mm**", warning that above
  that "larger vias are not guaranteed to be fully covered; no complaints are
  accepted regarding this type of defect". Board3 has **zero** colliding vias
  above 0.4 mm — the entire population sits at 62% of the ideal threshold.

JLC flags them because its DFM compares the silk layer against the drill file
and cannot see tenting.

**Recommendation: do not chase them, and record why.** Fixing means trimming
each placement against board-level vias, which is inherently per-instance —
reintroducing exactly the library divergence U0's fix resolved, so the mirror
would refuse those types and `lib_footprint_mismatch` would fire permanently.
That is a real, permanent cost against a defect that does not physically exist.
Revisit only if the via drill ever grows past 0.4 mm, which is the condition
that would make it real.

### Silkscreen line width: the premise was wrong, and the cause is unconfirmed

This plan recorded JLC's 25 *silkscreen line width* warnings as "25 items
inherit the board default of 0.1 mm". **Nothing on Board3 is below 0.15 mm** —
measured on both the pristine and the current board:

```
shape widths : 0.0 (x25)  0.15  0.152  0.1524  0.1525  0.2  0.203  0.254  0.3  0.4
text strokes : 0.0 (x4)   0.15  0.152  0.1525
shapes < 0.15 mm : 0        text < 0.15 mm : 0
```

The 0.1 mm is real but it is a **`.kicad_pro` default for newly-created items**
(`silk_line_width`, `silk_text_thickness`), not a property of anything drawn.
Reading a setting as a population is the same mistake as reading
`min_silk_clearance` as an active check — twice in one file, in opposite
directions.

**Fixed anyway, because it is a live trap rather than a present defect:** both
defaults are raised 0.1 → 0.15, so silk drawn in the GUI tomorrow cannot arrive
below the fab minimum. No existing geometry changes; DRC stays 0/0.

**What JLC actually flagged is not established.** The strongest candidate is the
board's **25 zero-width silk polygons** (all on F.SilkS — the polarity bands and
pin-1 markers), which export `%ADD22C,0.000000*` into the front silk gerber. The
count matches exactly, but the evidence does not close:

- the aperture is selected **14 times, not 25**, and every selection is
  immediately followed by `G36*` (region begin), where the Gerber spec says the
  aperture is unused — so nothing is actually stroked at zero width;
- the polygons are correct as geometry: filled regions are what a cathode band
  should be;
- and giving them a real width is **not free** — a stroke straddles the outline,
  so it would grow D10/D11's bands outward from their already-tightest 0.1000 mm.

So this may well be a false positive in JLC's parser reacting to a 0.000 mm
aperture *definition*. **Settle it with JLC's DFM item list before changing any
polygon**, rather than inferring from counts — the last two confident readings
of JLC's published figures in this repo both had to be retracted.

## Outstanding Questions

- Do chip passives keep any silk at all on this board? (U2)
- Is `silk_overlap` in scope for the gate? (U6)
- `ERJP06F60R4V` arrived from JLCImport without a courtyard, authored during
  U57. Is its silk worth fixing at the source rather than trimming?

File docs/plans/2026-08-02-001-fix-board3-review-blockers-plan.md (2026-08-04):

---
artifact_contract: ce-unified-plan/v1
artifact_readiness: implementation-ready
execution: code
title: Close the 2026-08-02 six-lens review blockers and consolidate the BOM
date: 2026-08-02
branch: fix/board3-review-blockers
---

# Close the 2026-08-02 review blockers, then consolidate the BOM

## Goal Capsule

Board3 was one click from fabrication when a six-lens review returned **NO-GO**
on three blockers. The headline one is that the fix for the previous review's
CRITICAL finding is installed backwards and does nothing.

This plan closes **every finding that can be closed before the board is made** —
not just the blockers. There is no spin 1 yet, so "defer to spin 2" would mean
deliberately fabricating known defects to save edits we are already making. Only
**two** findings are genuinely deferred, each blocked on an input that does not
exist: the board shrink (needs carrier CAD and measured FFC tail reach) and CAN
TVS (a production-board decision already recorded in KTD3).

**Done means:** the board is orderable with every closable finding closed,
verified by netlist and measurement rather than by inference, the BOM down from
48 lines to 44, and the fab package regenerated under KiCad's own interpreter.

## Why this plan exists

The 2026-07-31 pre-fab review returned NO-GO with 1 CRITICAL + 5 HIGH. Those were
fixed in PR #17 and the board reached DRC 0/0 with the fab package accepted by
JLCPCB's uploader. A confirmatory six-lens review then found that one of those
fixes was inverted, and that two problems had never been reviewed at all.

Five of six lenses independently found the diode defect, each from a different
angle. That convergence is why this plan is not optional.

## Verification Contract

Every unit states how it is proved. Three rules bind all of them, each paid for
in this repo:

1. **Read board facts through `pcbnew`, never regex on the `.kicad_pcb`.** Text
   parsing has produced at least four confidently wrong conclusions here.
2. **Verify by pin FUNCTION, not pin number.** This is the direct lesson of U31 —
   see KTD27.
3. **Run `tools/kicad_fab.py` under `C:/Program Files/KiCad/10.0/bin/python.exe`.**
   A bare `python` silently degrades the package and still reports success.

DRC is run in place, or with the FULL sidecar set (`.kicad_pro`, `.kicad_dru`,
`fp-lib-table`, both `.pretty` dirs). The `.kicad_dru` is load-bearing: without
it the board reports 36 violations, all inside its three declared scopes.

## Definition of Done

- `/U11_RSTN` and `/U12_RSTN` each carry a diode **anode**; `/+5V` carries both **cathodes**
- DRC 0 violations / 0 unconnected at `--severity-all`, airwires 0
- Power input path copper meets `docs/hardware/board3-pcb-layout-guide.md` §3
- `tools/kicad_lcsc.py check` PASS
- BOM/CPL symmetric; `kicad_fab.py` exits 0 with gerbers named `F_Cu.gbr` et al.
- BOM at 44 lines, with zero same-Comment/different-part-number pairs
- `kicad-cli pcb export step` emits all 143 bodies (carrier CAD depends on it)
- No via centre inside any pad; no track-to-via edge gap below 0.12 mm
- Every finding from the 2026-08-02 review is closed, deferred with a stated
  blocking input, or declined with a stated reason — none silently dropped

---

## Sequencing

**U41 runs first and gates everything else.** The remaining units start from a
clean, merged `main` on a fresh branch — not from the current working tree.

    U41  ship what's already done  ──►  merged to main
                                          │
                                          ▼
                                   new branch: fix/board3-review-blockers
                                          │
      ┌───────────────────────────────────┼───────────────────────────────────┐
      ▼                                   ▼                                   ▼
  no GUI needed                  ONE GUI sync covers all              routing work
  U35  part-number merges        U31  diode reversal  ★               U33  power copper ★
  U38  netclass via_drill        U32  F1 resize       ★               U42  CAN termination
  U39  doc corrections           U34  C70/C71 → 1 µF                  U47  copper fixes
  U40  delete stale zip          U36  C67 → 0805
  U43  raise DRC guard rails     U46  footprint + metadata
                                 U48  R4 divider, VBUS OCP
      │                                   │                                   │
      └───────────────────────────────────┴───────────────────────────────────┘
                                          ▼
                            U45  silk: function labels, no refdes
                                 U49  SWO out to the debug header
                                 (last — U33/U42 move copper near connectors)
                                          ▼
                            U37  courtyards + un-ignore the check
                                          ▼
                    regenerate fab package → U44 order-form checklist → order

★ = the three fabrication blockers.

**The GUI sync is the expensive step, so batch it.** U31, U32, U34, U36, U46 and
U48 all need one `Update PCB from Schematic` pass — run it once, not six times.
That step is also the one nothing can verify automatically (KTD12) and the one
that silently set 16 DNP flags last time, so **re-run `bom_cpl_symmetry()` and a
DNP census immediately after it**.

U45 goes last on purpose: silk placed before U33 and U42 move copper near the
connectors would need redoing.

---

## Implementation Units

### U41. Ship what is already done, then start clean  **RUNS FIRST**

**Goal:** get the current working tree onto `main` so this plan's work starts
from a known state rather than layering onto uncommitted edits.

**Why first.** Two things are sitting uncommitted right now, and one of them is a
correction to a claim already made in a merged PR. Carrying them into the blocker
work would mix a documentation fix with a schematic fix in the same branch, and
the blocker work needs a clean diff — U31 in particular must show *only* the
diode change so the netlist proof is unambiguous.

**Current uncommitted state:**

| File | What it is | Action |
|---|---|---|
| `CLAUDE.md` | AW9523B RSTN datasheet facts pulled 2026-08-02 (V_IH 1.4 V fixed, 100 kΩ internal pull-down, ≤10 µs glitch filter, the 10k/100n network's 335 µs / 4.55 V figures) | **commit** |
| `docs/plans/2026-08-02-001-...-plan.md` | this plan | **commit** |
| `EasyEDA/New Project_...eprj2` | Kevin's, binary, predates the session | **leave unstaged** |

Note: the CLAUDE.md edit was previously described as riding with PR #19. It did
not — #19 merged without it. This unit is where it actually lands.

**Approach:**

1. Branch off updated `origin/main` (PR #19 is merged, so `main` already carries
   the DNP fix, the BOM/CPL symmetry gate, and the ASCII/footprint hardening).
2. Commit the two files. Do **not** stage the `.eprj2`.
3. Open the PR via `/ce-commit-push-pr`. The description should state plainly
   that the plan documents a **NO-GO** verdict with three fabrication blockers —
   this PR ships the diagnosis, not the fix.
4. **Wait for merge.** Do not begin U31 on this branch.
5. After merge, `git fetch origin main` and create `fix/board3-review-blockers`
   from it. All remaining units land there.

**Verification:**
- `git status` shows only the `.eprj2` modified
- The PR contains exactly two files
- `fix/board3-review-blockers` branches from a `main` that includes this plan
- `tools/kicad_lcsc.py check` still PASS and DRC still 0/0 on the fresh branch —
  a sanity check that nothing was disturbed by the branch dance

**Execution note:** this unit ships documentation only. No board file, no
schematic, no tooling changes. If the diff contains anything else, stop.

---

### U31. Reverse D10/D11 — the RSTN networks are currently inert  **BLOCKER**

**Goal:** make the Schottky discharge diodes do what their commit message says.

**The defect.** Both diodes sit anode-on-`/+5V`, cathode-on-RSTN — the opposite
of intent. Confirmed five ways: symbol pin names (`K`=1, `A`=2 in
`JLCImport.kicad_sym`), symbol geometry, the exported schematic netlist
(`pinfunction "K_1"` inside `/U11_RSTN`), the `pcbnew` pad-net map, and the
footprint silk band sitting at the pad-1 end.

**Consequence, quantified.** The diode is forward-biased during the rail ramp, so
C70/C71 charge through it rather than through R60/R61. RSTN crosses its fixed
1.4 V V_IH at VCC ≈ 1.5–1.6 V — *below* V_POR (1.8 V typ). **Reset assertion
duration is exactly zero at every ramp rate.** The brownout half fails in the
same direction: reverse-biased on collapse, so the cap holds RSTN high and
discharges only through R60 (τ ≈ 909 µs). This is worse than fitting no diode,
which would at least deliver ~335 µs of power-up hold.

**Files:** `kicad/board3/*.kicad_sch`, `kicad/board3/*.kicad_pcb`

**Approach — zero copper movement.** Both footprints are pad-symmetric about
their origin, measured exact to **0 nm** on both axes with identical pad sizes
(pads at rel ±1.172 mm, 1.000 × 0.700 mm). So:

1. In the schematic, swap the connections: pin 1 (K) → `/+5V`, pin 2 (A) → the
   RSTN net, on both D10 and D11.
2. In the board, rotate D10 and D11 **180°**.
3. Pad 1 (now `/+5V`) lands exactly where the `/+5V` copper already terminates;
   pad 2 (now RSTN) lands where the RSTN copper is. No track is edited.

Doing only step 1 leaves the CPL orienting the old way. Doing only step 2 shorts
`/U11_RSTN` to `/+5V` — pad numbers carry the nets, so rotation alone moves the
wrong net onto the wrong copper. **Both steps, or neither.**

**Verification:**
- Export the netlist and assert `A_*` on `/U11_RSTN` and `/U12_RSTN`, `K_*` on `/+5V`
- `pcbnew`: `D10.1 == /+5V`, `D10.2 == /U11_RSTN` (same for D11)
- DRC unchanged at 0/0, airwires still 0
- Regenerate the fab package and read the rotation audit for D10/D11

**Execution note:** verify by pin **function**. Asserting pin-number membership
is exactly the check that let this through.

---

### U32. Resize F1 — the plan's own stop condition has already fired  **BLOCKER**

**Goal:** an overcurrent element that does not nuisance-trip in normal operation.

**The defect.** F1 is C960026, 2 A hold / 4 A trip, derating to **~1.4 A hold at
60 °C** by the previous plan's own note. `docs/hardware/board3-pcb-layout-guide.md`
§3 states the input path carries **1.5–2 A**. Two independent load tallies during
review returned 1.74 A and 1.90 A typical. The previous plan's stop condition —
*"if steady-state exceeds ~1.3 A, the part moves up a size before order"* — is
satisfied by numbers already in the repo, with no bench measurement needed.

The 400 mA "logic side" figure that sized the original part omits the MCU, both
CAN transceivers, and the telltales.

**Consequence:** a PPTC at 1.36–1.64× hold latches off in seconds to minutes. The
dash goes dark mid-session and stays dark until DC1 is unplugged and the part
cools. Before tripping, self-heating raises its resistance and compounds U33.

**Files:** `kicad/board3/*.kicad_sch`

**Approach:** swap to **C48985875** (LUTE 1812L300/30GR) — 3 A hold / 5 A trip,
30 V, **same 1812 land pattern**, 10 mΩ initial vs 20 mΩ (halving the series drop
U33 addresses), 47.5 k stock, $0.168. Add with
`python tools/kicad_lcsc.py add C48985875`, then `kicad_lcsc.py models`.

**Verification:** `/DC1_IN` still has exactly two pads (`DC1.1`, `F1.1`) — the
part must stay in series, not bridged. `kicad_lcsc.py check` PASS. Board
footprint `Value` reads the new part so the Component Marking Layer stays honest.

---

### U33. Widen the power input path — 10 mil against a documented 60 mil  **BLOCKER**

**Goal:** input copper that meets the project's own layout guide.

**The defect.** `docs/hardware/board3-pcb-layout-guide.md:104` specifies:

    | Input (jack/USB) → ideal diodes → +5V | ~1.5–2 A | pour or ≥60 mil |

Measured through `pcbnew`:

| Net | Length | Width | Zone |
|---|---|---|---|
| `/DC1_IN` | 9.7 mm | **100% at 0.254 mm** | none |
| `/+5V_BARREL` | 34.3 mm | **100% at 0.254 mm** | none |
| `/VBUS` | 62.9 mm | **100% at 0.254 mm** | none |

0.254 mm is 10 mil — **six times narrower than the stated minimum**, on the net
where all board current sums. `/DC1_IN` is copper laid during the previous
campaign at the net-class default, which extended the undersized path rather than
fixing it.

Additionally: Q2's drain has **zero `/+5V` vias within 4 mm**; the nearest is
16.15 mm away, so current crosses 16 mm of 10 mil top-layer copper before
reaching the Inner2 plane.

**Consequence:** IPC-2221 gives 0.254 mm 1 oz external ≈ 1.0–1.2 A at 20 °C rise.
At 1.9–2.29 A that is a **56–86 °C rise** — 116–146 °C in a 60 °C cabin, at or
above JLC standard FR-4 Tg. Series resistance ~145–175 mΩ costs 0.28–0.40 V
before the rail reaches the plane. U3 (TPS563201) has V_IN(min) = 4.5 V; a 5 V
−5% adapter at peak load lands at **~4.35 V, below UVLO** — the 3.3 V rail
collapses. Backlight boost converters are constant-power loads, so they draw more
as the rail sags: positive feedback.

**Files:** `kicad/board3/*.kicad_pcb`

**Approach:** widen `/DC1_IN` and `/+5V_BARREL` to ≥1.5 mm or pour them; add a
via field (≥6 vias at 0.6/0.25) at Q2's drain into the Inner2 `/+5V` plane. Give
`/VBUS` the same treatment where routable. This is the only unit needing genuine
routing work.

**Verification:** re-run the width census; no segment on those three nets below
1.5 mm unless poured. DRC 0/0 after `ZONE_FILLER.Fill()` **then**
`board.BuildConnectivity()` — in that order. `GetConnectivity()` alone reads
pre-fill state and lies in both directions.

---

### U34. C70/C71 100 nF → 1 µF — sized for a slow rail ramp

**Goal:** reset hold that survives the actual ramp rate, which has never been
measured.

Even correctly oriented (U31), 100 nF meets the ~100 µs hold requirement only for
rail ramps faster than ~4 ms:

| +5V ramp | 100 nF | 1 µF |
|---|---|---|
| 1 ms | 405 µs | 3383 µs |
| 5 ms | **73 µs** | 3649 µs |
| 10 ms | **0 µs** | 4047 µs |
| 50 ms | **0 µs** | 730 µs |

The ramp here is set by the adapter, the LM74700 gate slew, and ~76 µF of bulk.
1 µF fits the same 0603 land and covers ramps to 50 ms. All values sit far above
the part's 10 µs RSTN glitch filter, so the filter is never the binding constraint.

**Files:** `kicad/board3/*.kicad_sch`. Same land pattern — no re-route.

**Verification:** schematic and board `Value` agree; `kicad_lcsc.py check` PASS.

---

### U35. BOM consolidation, zero-copper tier — 48 → 46 lines

**Goal:** collapse duplicate part numbers that exist only because parts arrived
in different EasyEDA import batches.

Two pairs are electrically identical and same-package, differing only in
manufacturer — and in each case one side is already **Basic** while the other is
**Extended**:

| Used by | Currently | Replace with | Why |
|---|---|---|---|
| C17–C28 (12) | **C1591** Samsung, 100 nF 50 V X7R 0603, *Extended* | **C14663** YAGEO, identical spec, **Basic** | already fitted on 31 other positions |
| R11–R13, R45–R47 (6) | **C98220** YAGEO, 10 k ±1% 100 mW 0603, *Extended* | **C25804** UNI-ROYAL, identical spec, **Basic** | already on R1/R2/R7/R49/R60/R61; 4× cheaper |

**Saves:** 2 BOM lines, 2 extended-part feeder fees (~$6), 2 feeder positions.
Also removes the last same-Comment/different-part-number pair on the 100 nF line —
the exact family that broke the JLCPCB uploader (KTD28).

**Files:** `kicad/board3/*.kicad_sch` — property edits only (`Supplier Part`,
`Manufacturer Part`, `Manufacturer`, `JLCPCB Part Class`, `Description`) on 18
symbols. `Value` strings are already identical, so board footprint Values are
already correct: **no GUI sync, no footprint change, no net change.** This is the
U10/U24 precedent.

**Verification:** gerbers and CPL byte-identical before/after; only
`bom-jlcpcb.csv` moves. `kicad_lcsc.py check` PASS.

---

### U36. BOM consolidation, package tier — C67 0603 → 0805, 46 → 45 lines

**Goal:** make the panel bulk caps one part, and kill the uploader collision at
its root rather than working around it.

There is one bulk cap per panel connector: **C66** 22 µF/0805 at FPC1, **C67**
10 µF/0603 at FPC2, **C68** 22 µF/0805 at FPC3. C67 is the odd one out, and its
0603 land is **inherited from the EasyEDA import, not chosen**. It is also the
board's only 10 V-rated capacitor — the most heavily DC-bias-derated part here,
delivering roughly half its label at 3.3 V, so its effective capacitance is nearer
5 µF against its siblings' ~17 µF.

Changing it to **C45783** (22 µF 0805) makes FPC2 match FPC1/FPC3, removes a BOM
line, and permanently deletes the `10uF` Comment collision that
`disambiguate_comments()` currently works around.

**Files:** `kicad/board3/*.kicad_sch`, `kicad/board3/*.kicad_pcb`

**Approach:** footprint change 0603 → 0805 plus a local re-route at FPC2. Needs
the KTD12 GUI sync — which U31/U32/U34 already require, so it rides along.

**Do NOT** take the tempting zero-copper shortcut of DNP-ing C67: that deletes the
**center** panel's local bulk, and the center panel is the primary one.

**Verification:** `/+3V3` bulk unchanged or improved at FPC2; DRC 0/0; BOM shows
no `10uF` line; `bom_cpl_symmetry()` clean.

#### Package consolidation beyond this point is NOT recommended

The full census, by placement count:

    54  C0603      35  R0603      10  C0805      (everything else is 1-4)

The remaining 0805 population is 7× 22 µF bulk (C29, C30, C31, C48, C49, C66,
C68) and 2× 4.7 µF (C38, C39). Moving bulk to 0603 costs voltage rating and
DC-bias headroom for **no BOM-line saving** — they are already one line each.
Moving the 4.7 µF pair saves no line either.

The optimization target is **distinct (value, package, part) tuples**, not a
uniform package size. Before: four values carry duplicates (`100nF` ×2 parts,
`10kΩ` ×2 parts, `10uF` ×2 packages, the tact switch ×2 footprints). After U35 +
U36: only the tact switch remains, and it is one part number on two land
patterns — a tidiness item, not a cost item (see spin-2 list).

---

### U37. Courtyards on D10, D11, F1 — and stop ignoring the check

**Goal:** close the blind spot that hid the AW9523B overlap until 2026-07-31.

`missing_courtyard` is set to `ignore` in the `.kicad_pro`. Setting it to `error`
on a staged copy yields exactly 7 violations: **D10, D11, F1** plus the 4 unnamed
EasyEDA corner pads. Three of the seven new parts walked through the same hole the
last fix left open — all three came from `JLCImport.pretty`, none of which carries
an `F.CrtYd` item.

**No collision today** — measured by hand with exact polygon math: D11→C71
1.285 mm, D10→C70 3.045 mm, F1→SW2 2.205 mm (pad-to-courtyard). This is a
false-pass risk, not a present defect.

**Files:** `kicad/board3/JLCImport.pretty/1N5819WS.kicad_mod`,
`.../BSMD1812-200-30V.kicad_mod`, `kicad/board3/*.kicad_pro`, plus the placed
instances (KTD26: library-only fixes change nothing fabricated).

**Verification:** `missing_courtyard` at `error` yields only the 4 corner pads.

---

### U38. Netclass `via_drill` 0.3 → 0.25

Every via on the board is 0.25 mm drill (0.175 mm ring), but the Default netclass
still carries `via_drill: 0.30`. The next via drawn in the GUI arrives at 0.6/0.3
= **0.150 mm ring**, silently landing at JLC's absolute minimum and undoing
`f621c3b` at that location. Directly relevant because U31, U33 and U36 all involve
GUI work.

**Files:** `kicad/board3/*.kicad_pro`. **Verification:** place a test via, confirm
0.25 mm, delete it.

---

### U39. Correct four wrong numbers that are in merged documentation

Each was stated as fact and is not:

| Claim | Truth | Where it is wrong |
|---|---|---|
| Board is 230 × 50 mm | **250 × 50 mm** (Edge.Cuts measured) | session notes, review prompts |
| 198 vias | **205** (204 @ 0.6/0.25 + 1 @ 0.5/0.2) | PR #17, `kicad_rules.json` comment |
| "150-violation baseline" | **Not reproducible.** True delta is 0 → 0. Trajectory: `5e047a7` 0/0 → `3c9f8c1` 12/14 → `d08f29c` 0/9 → `262dc65` 0/0. The nearest real figure is the 146-*warning* inbox at `25193d2`, which predates the 7-part work. | PR #17 (merged), PR #19 |
| 0.25 mm drills incur a surcharge | **No surcharge applies.** JLC's rule is conditioned on via *diameter* < 0.45 mm; ours are 0.60 and 0.50. | `tools/kicad_rules.json` `cost_floors_mm`, PR #17 |

The last one matters most: `kicad_rules.json` models a flat drill floor, which is
more pessimistic than JLC's actual pricing, and **that wrong model drove a real
design decision** (the 0.7/0.35 → 0.6/0.25 change).

**Files:** `tools/kicad_rules.json`, `CLAUDE.md`, PR descriptions.

**CLOSED 2026-08-03.** `kicad_rules.json` corrected on both counts, and a
correction block appended to PR #17 rather than editing its claims in place, so
the original record stands beside the correction.

Two amendments to this unit's own table, found while closing it:

- **The via count should not be corrected, it should be removed.** "205" was
  already stale by the time this plan was written — U47, U48 and U49 each added
  vias, and the board measured **222** on 2026-08-03. Replacing one hardcoded
  count with another just resets the clock, so `kicad_rules.json` now says to
  count them and how.
- **The "150-violation baseline" is not in PR #19.** It appears once, in PR #17.
  PR #19's only "baseline" mentions are about the frozen BOM used for the
  2026-08-02 order, which is a different and accurate claim.

Board size confirmed by measurement: **250.254 × 50.254 mm** over Edge.Cuts.

---

### U40. Delete the stale gerber decoy

`fab/board3-gerbers.zip` (Jul 27, gitignored) is the output of a `kicad_fab.py`
run under a bare `python`: no gerber renaming, so the board outline ships as
**`Multi-Layer`** — which in Altium/EasyEDA vocabulary means copper on every
layer, i.e. a fab reading that filename learns the opposite of the truth. It is
also seven parts stale, it sits next to the correct `fab/gerbers-jlcpcb.zip`, and
it has the more authoritative-sounding name. One `rm`.

---

### U42. Simplify CAN termination to one resistor per bus, jumper-selectable

**Goal:** replace the four-part split network with a two-part one, and make
termination an independent yes/no choice **per CAN bus**.

**What is there now**, verified through `pcbnew` — both buses identical:

    CAN1_H ──[ H1 ]── /CAN1_TERM ──[ R10 60.4Ω ]──┬── /CAN1_CT
                                                   │
                                              [ C57 4.7nF ]
                                                   │
                                                  GND
                                                   │
    CAN1_L ─────────────────[ R14 60.4Ω ]──────────┘

Split termination is the right *topology* — two halves with a mid-point cap damp
common-mode without loading differential. The defect is **which leg the jumper
interrupts**. H1 sits only in the `CAN1_H` branch, so with the jumper open:

- `CAN1_H` → open at H1, carries nothing
- `CAN1_L` → **still** 60.4 Ω + 4.7 nF to ground, permanently

That is an unbalanced AC load on one leg of a differential pair — τ = 284 ns
against a 1 µs bit time at 1 Mbps. Exactly what split termination exists to
avoid. `tools/kicad_rules.json` records the intended default as *un-terminated*
("the bus is terminated at its ends by the vehicle harness"), so the un-jumpered
state is the one that is wrong.

**Approach — series resistor behind the jumper:**

    CAN_H ──[ H1 pin1 ][ H1 pin2 ]──[ R 120Ω ]── CAN_L

Jumper **fitted** → a single 120 Ω across the pair, the standard CAN end
termination. Jumper **open** → the resistor is left dangling from one line with
its far end floating: a ~1 pF stub with no path to anywhere, instead of today's
permanent RC to ground. Each bus keeps its own header, so **CAN1 and CAN2 are
selected independently** — fit one, both, or neither.

**Parts, per bus:** `H1` + `R10` + `R14` + `C57` (4) → `H1` + one 120 Ω (2).

| | before | after |
|---|---|---|
| placements | 8 (both buses) | 4 |
| `C2933247` 60.4 Ω ×4, **Extended** | 1 line | removed |
| `C53987` 4.7 nF ×2, Basic (used *only* by C57/C58) | 1 line | removed |
| `C22787` 120 Ω 0603, **Basic + preferred** (no feeder fee), 3.08 M stock, $0.008 | — | 1 line |

Net **−1 BOM line and −1 extended-part fee**, on top of U35/U36. Running total:
48 → 46 (U35) → 45 (U36) → **44** (U42).

Power check: at 2 V differential, 120 Ω dissipates 33 mW against the 0603 part's
100 mW rating — 3× margin, and 0603 matches the board's dominant package.

**Files:** `kicad/board3/*.kicad_sch`, `kicad/board3/*.kicad_pcb`

**Approach note:** this needs a re-route of both CAN connector areas, so it is
the second-largest routing job in the plan after U33. Add the part with
`python tools/kicad_lcsc.py add C22787`, then `kicad_lcsc.py models`.

**Verification:** `/CAN1_H` and `/CAN1_L` each carry exactly the transceiver pin,
the connector pin, and one termination element; no net reaches `/GND` through a
termination part; DRC 0/0. Repeat for CAN2.

**Interim measure until this ships:** on the current board, **fit the H1/H3
jumpers**. That makes the existing network the symmetric split termination it was
drawn as, at the cost of 120 Ω of extra termination on a short bench bus — benign
at 1 Mbps. Put it on the bring-up card.

---

### U43. Raise four DRC guard rails that sit below the fab's actual limits

**Goal:** stop the rule set from being able to certify an unbuildable board.

Each of these is currently *satisfied by the geometry* — so this is not a defect
list, it is a list of checks that would not catch one. Measured against JLC's
live capability table:

| Rule | Configured | JLC actual | Board's real value |
|---|---|---|---|
| `m_SolderMaskMinWidth` | **0.0 mm** (disabled) | 0.10 mm green / 0.13 black-white | 0.1795 mm ✓ |
| `min_text_height` | 0.8 mm | **1.0 mm** | 1.0 / 1.27 mm ✓ |
| `min_text_thickness` | 0.08 mm | **0.15 mm** | 0.15 mm ✓ (exactly at limit) |
| `min_hole_clearance` | 0.1016 mm | 0.20 via→track, 0.28 PTH→track, 0.30 inner PTH→cu | 0.2730 / 0.4330 / 0.3021 ✓ |

Plus the `.kicad_dru` scopes edge clearance **below** the fab limit:

    (rule usbc_slot_edge
      (condition "A.intersectsArea('usbc_slots')")
      (constraint edge_clearance (min 0.1mm)))

0.1 mm is half of JLC's 0.20 mm copper-to-routed-slot minimum. The board sits at
0.2417 mm so it passes anyway — but that rule would certify a board that cannot
be built. Raise it to 0.20 mm and it still passes, while meaning something.

Because `solder_mask_bridge` is severity *error* while its width parameter is
0.0, it only ever catches actual aperture overlaps, never a sub-minimum dam.

**Files:** `kicad/board3/*.kicad_pro`, `kicad/board3/*.kicad_dru`

**Verification:** after raising all five, DRC still 0/0. If anything now fails,
that is a real finding the old rules were hiding — treat it as such, do not lower
the rule back.

**Related, and deliberately NOT changed here:** three features pass with
essentially no margin and should be watched rather than adjusted, since fixing
them costs re-routing:

- BTN1 via annular ring **0.1500 mm** — JLC's absolute minimum, recommended 0.20
- USBC1.1/2/3 hole → Inner2 `/+5V` zone **0.3021 mm** vs a 0.30 mm limit (2.1 µm)
- USBC1 pads → routed retention slot **0.2417 mm** vs 0.20 mm

---

### U44. Order-form facts that are not in any file

**Goal:** the quote form asks for things the gerbers do not state, and getting
them wrong causes a hold, a re-quote, or unfitted parts.

| Field | Answer | Why it is not obvious |
|---|---|---|
| Board size | **250 × 50 mm** | not 230 × 50 (U39) |
| Minimum hole size | **0.20 mm** | 204 vias are 0.25, but the single BTN1 via at 0.20 forces the lower tier. Declaring 0.25 is wrong. |
| Via covering | **Tented** | the board sets `m_TentViasFront/Back = True`; JLC's plugged-via service caps at 0.5 mm and ours are 0.6 mm, so tenting is what must be selected |
| Surface finish | **ENIG** | the stackup block specifies it and it is a real cost adder over HASL |
| Stackup | **JLC04161H-7628** | the literal string appears **nowhere** in the `.kicad_pcb` — only the numeric values match, so nothing binds the order to that template |
| Impedance control | **not ordered** | `dielectric_constraints no`. The USB pair is built to a 90 Ω target against the written stackup, but JLC will not verify it |
| Assembly service | **must include through-hole / hand-solder** | **12 of 143 designators are THT**: DC1, H1, H2, H3, P1, P2, SW1–SW4, SW6, SW7. Plain SMT assembly leaves the board with no power jack, no CAN terminals and no buttons. |

**U1 stock — risk reviewed and ACCEPTED (Kevin, 2026-08-02).** **U1
(STM32H755ZIT6, `C730212`) is at 37 units** and is ~64% of the per-board
component cost ($27.26 of ~$42.31); its only variant `C1343604` is at 0. This is
the pattern that hit U2, which went 2,163 → 4 units in seven days, and there is
no substitution available.

**Do not let this rush the plan.** The decision is that shipping a board with
three known blockers to beat a stock clock is the worse trade — a scrapped panel
costs more than a wait. If JLC's stock reaches zero before the work is done, the
fallback is to buy U1 elsewhere (DigiKey/Mouser carry it) and supply it as a
consigned part, or accept the lead time. Re-check stock at order time for
information, not as a gate.

**Unverified, flagged rather than guessed:** JLC publishes no maximum hole aspect
ratio. This board is 6.4:1 (1.6 mm / 0.25 mm) and 8.0:1 at BTN1. Their published
0.15 mm multilayer minimum with 1.6 mm listed as standard *implies* ~10.7:1 is
supported, but that is an inference. Confirm at order if certainty is wanted.

---

### U45. Silk carries function, not designators

**Goal:** stop printing reference designators, and label the things a person
actually has to identify with their hands.

**Current state**, measured through `pcbnew`: **8 of 146** designators print —
D10, D11, F1, U11, U12 and the three fiducials. The other 138 are hidden,
including all 64 capacitors, all 35 resistors, nine ICs, the eight telltales and
all six switches.

**Decision: hide the remaining five and keep silk for inputs and buttons only.**
The board file is authoritative and `kicad/board3/renders/` carries current
top/bottom/angled images regenerated on every board commit, so a designator is
always seconds away. Printing 138 of them would have been a real layout job on a
dense 250 × 50 mm board with silk clearance only just armed at 0.15 mm (U28) —
whereas this direction makes silk *sparser*.

**Hide (5):** D10, D11, F1, U11, U12.
**Fiducials:** FID1–3 keep their marks; the designator text can go too.

**Label (16) — and label them by FUNCTION, not designator.** For precisely the
parts worth marking, the refdes is the least informative string available:

| Part | Print this, not this |
|---|---|
| FPC1 / FPC2 / FPC3 | **LEFT** / **CENTER** / **RIGHT** — CORRECTED 2026-08-03; this table originally said CENTER/LEFT/RIGHT and was WRONG. FPC1 carries `/SCLK_L`, FPC2 carries `/SCLK_C`. The labels were placed from this table without checking the nets and had to be swapped after review. Verify by NET, not by this row (KTD27). |
| P1 / P2 | **CAN1** / **CAN2** |
| H1 / H3 | **TERM1** / **TERM2** |
| H2 | **SWD** |
| DC1 | **12V** (or the confirmed supply rating) |
| USBC1 | **USB** |
| SW1–SW4 | **BTN1**–**BTN4** |
| SW6 / SW7 | **RESET** / **BOOT** |

Plugging the centre panel into the wrong FPC is a real bench mistake, and
`FPC2` does not protect against it. `RESET` vs `BOOT` matters more than `SW6` vs
`SW7` when a board is in a half-assembled state and someone is holding it.

**Files:** `kicad/board3/*.kicad_pcb` — reference-text visibility is a board-side
property of the placed footprint, so this needs **no schematic sync** (the U10
`Value` precedent). Functional labels are new `gr_text` items on `F.SilkS`.

**Verification:** DRC 0/0 with `silk_over_copper` and `silk_edge_clearance`
armed — this is the check that matters, since 16 new text items near connectors
is exactly where silk-over-pad appears. Text ≥1.0 mm height and ≥0.15 mm
thickness (JLC's minimums, see U43). Re-render and eyeball
`kicad/board3/renders/top.png`.

**Execution note:** do this **after** U33 and U42, both of which move copper near
connectors. Silk placed first would need redoing.

---

## Key Technical Decisions

**KTD27. Verify by pin FUNCTION, never pin number.** U31's defect survived a
verification gate that asserted `/U11_RSTN` carries `IC.23 + R.2 + C.1 + D.1`.
Pin 1 *is* the cathode, so the assertion passed while the circuit was inverted —
and the plan's own test scenario had named that exact failure ("a reversed diode
turns the fix into a permanent RSTN clamp"). A membership check over pin numbers
cannot see orientation. Any polarised two-terminal part must be verified through
`pinfunction` from the exported netlist, or through the symbol's pin *names*.

**KTD28. The BOM's optimization target is distinct (value, package, part) tuples.**
Not a uniform package size. Duplicate tuples cost a BOM line and a feeder fee, and
same-Comment/different-part pairs are the family that broke the JLCPCB uploader on
2026-08-02. Consolidating package sizes for their own sake trades voltage rating
and DC-bias headroom for nothing.

**KTD29. A vendor upload verdict is a single-attempt observation.** During the
2026-08-02 order attempt, a byte-identical file pair failed and then passed on
immediate retry. Every earlier "fail" in that bisect had been recorded once and
treated as deterministic. Bisects against remote services need retries in the
protocol, or the bisect lies. This is why the `10uF` Comment collision remains
*plausible but unproven* rather than confirmed.

**KTD30. `.kicad_dru` is load-bearing and must be staged for any DRC.** Without it
the board reports 36 violations, all inside its three declared scopes (26
`courtyards_overlap`, 10 `copper_edge_clearance` at the USBC1 slots). No
over-broad suppression — verified by removing the `telltale_expander_cluster` rule
and getting exactly 1 violation back.

---

### U46. Cheap fixes that need no copper — do them while the files are open

Every item here is a metadata or footprint edit. None touches a net. They were
initially filed as "spin 2", which was wrong: there is no spin 1 yet, so
deferring them means **deliberately fabricating a board with known defects** to
save edits we are already making.

- **U4's exposed pad is still 100% paste.** The fourth EP part; U23 windowed the
  other three. Same edit, already understood. EP-to-pin gap is 1.200 mm so
  bridging is not credible, but there is no reason to ship the inconsistency.
- **LED3 has no printed polarity mark**, and **LED5's two silk cues contradict
  each other** — its centre arrow points at pad 1 (cathode) while its corner
  triangle sits at the pad 2 corner. The U23 fix covered LED4/6/7 and stopped.
  A reversed telltale just stays dark, but this is a rework/inspection trap.
- **LED3's value carries HTML-escape damage**:
  `HL-A-3528H343W-S1-13HL-HR3_SDCM_amp_lt_6_6000K-7000K`, where `_amp_lt_` is a
  surviving `&lt;`. Real MPN is `HL-A-3528H343W-S1-13HL-HR3(SDCM 6)(6000K-7000K)`.
  That 62-character string is what the Component Marking Layer carries.
- **`fab/bom.csv`'s `Part Class` column is stale** — 8 lines blank (including
  every part this campaign touched) and 1 wrong (`C98220` claims Basic, JLC says
  Extended). It is the column a human quotes from.
- **13 3D-model references point at `.wrl` where a `.step` sibling exists on
  disk** (F1, D10, D11, U11, U12, LED1, LED3–LED8). `kicad_lcsc.py check` passes
  because the file exists, but `kicad-cli pcb export step` ignores VRML, so an
  enclosure-fit export silently omits 13 bodies — and the carrier CAD is what
  gates the board-shrink decision.
- **Set footprint-type attributes.** 134 of 150 footprints carry none and
  `footprint_type_mismatch` is `ignore`, so exporting with `--smd-only` (the
  commonly-cited JLCPCB recipe) yields a **13-part CPL that still looks
  well-formed**. Set the attributes and un-ignore the check.
- **SW1–SW4 and SW6/SW7 use two land patterns for one part number**
  (`LS5.4` vs `LS5.0`). At most one is dimensionally right.

**Verification:** DRC 0/0; `kicad_lcsc.py check` PASS; `kicad-cli pcb export step`
produces a model with all 143 bodies.

---

### U47. Copper fixes to make while U33 and U42 already have the router open

These need routing, which is exactly why they belong in this spin rather than the
next one — the alternative is opening the router twice.

- **Home-run the east `/+5V` feed.** R61 and D11 currently draw `/+5V`
  *through* the LED4 telltale daisy chain. Verified by real in-memory segment
  deletion: cutting either feed segment orphans `D11.2, LED4.2, R61.1`. One cold
  joint at LED4 pad 2 removes U12's reset pull-up, the internal 100 kΩ pull-down
  holds RSTN low, and **U12 sits in permanent reset — all four east telltales
  dark and the expander unresponsive on I2C.** The **west side already home-runs
  to the plane and does not have this**; make the east side match.
- **Relieve `/U12_RSTN`'s clearance.** It runs at **1.4 µm** of margin against
  two telltale vias (0.1030 mm edge gap vs a 0.1016 mm rule) — the tightest
  copper on the board, on a net added by the last campaign. An etch or
  registration excursion shorts reset to a telltale cathode, and U12 would then
  reset itself every time TT4 or TT8 illuminates.
- **Move the escape vias out of LED2/6/7/8's cathode pads.** Via centres sit
  *inside* pad 1 on four telltales. Tenting is irrelevant when the via is inside
  the pad's own mask aperture: solder wicks down the 0.25 mm barrel during
  reflow — up to ~22% of one pad's deposit — giving an asymmetric fillet and LED
  tilt on a part sitting behind a lens.
- **Give BTN1's via an annular ring with margin.** At 0.5/0.2 it has exactly
  **0.150 mm**, JLC's absolute minimum with zero headroom, and it is also the one
  via forcing the whole order into the 0.20 mm hole tier (U44). If neighbouring
  pads can be nudged to allow 0.6/0.25, both problems close together.

**Verification:** DRC 0/0 after `ZONE_FILLER.Fill()` then `BuildConnectivity()`;
re-run the segment-deletion test and confirm no LED cut orphans R61 or D11;
minimum track-to-via edge gap above 0.12 mm; no via centre inside any pad.

---

### U48. Two electrical fixes the review found outside the blocker set

- **R4 = 0 Ω puts unlimited 5 V injection into U1 pin 98 (PA9) on every
  power-up.** `/VBUS_SENSE` has exactly two pads: `R4.2` and `U1.98`. PA9 is 5 V
  tolerant, but ST's tolerance is conditional on VDD being present — and 3.3 V is
  *derived* from 5 V through U3, so during the buck's soft-start VBUS sits on PA9
  through 0 Ω while VDD is still rising. Current into the ESD clamp is limited
  only by the clamp itself (~10–50 Ω), i.e. **tens of mA against a ±5 mA limit,
  every single power-up**. Secondary: with no lower leg, PA9 floats when USB is
  unplugged and barrel-powered, so VBUS sensing reads indeterminate. Fix: make R4
  the top of a divider (100 k / 100 k). One added part.
- **`/VBUS` has no overcurrent protection.** The 2026-07-31 HIGH named *both*
  inputs; only the barrel got F1. Combined with U33's finding that `/VBUS` is
  10 mil copper, a board-side short downstream of the connector is cleared by the
  trace rather than by a protection device. Fit a PTC in the USB path as F1's
  counterpart.

**Verification:** `/VBUS_SENSE` carries R4.2, the new divider leg, and U1.98;
divider midpoint computes to ≤3.3 V at VBUS = 5.25 V. `/VBUS` has a series
protection element with exactly two pads on its input side.

---

### U49. Bring `/SWO` out to the debug header

**Goal:** give this board a diagnostic channel that does not collide with the
serial protocol.

**The gap.** `/SWO` is a **dangling net** — exactly one pad, `U1.130`, going
nowhere. H2 is a 5-pin header carrying `+3V3, SWDIO, SWCLK, NRST, GND`, so the
MCU's trace output has no destination and ITM is unavailable.

**Why this board needs it more than most.** The USB serial is not a debug
channel here, it is a *protocol* channel: `ok`/`err` acks are the only output
after boot, and both the `/dash` skill and the host tests depend on that
contract. So today there is **nowhere to print** — any `printf` added to diagnose
something breaks the contract the tooling relies on.

SWO is a separate one-way path out of the core carrying ITM (`printf` at
megabits), exception entry/exit trace, and PC sampling for profiling. ST-LINK
V2/V3 and J-Link all support it. On a board whose hard bring-up problems have
been timing and signal integrity — the 27 MHz wedge that dead-locked the
firmware in an unbounded busy-poll, the unresolved two-panel crosstalk, marginal
FFC contacts — exception trace and PC sampling are the right instruments, and
none of them cost a byte on the protocol port.

**Files:** `kicad/board3/*.kicad_sch`, `kicad/board3/*.kicad_pcb`

**Approach:** H2 `PZ254V-11-05P` → the 6-pin variant of the same family (H1/H3
already use `PZ254V-11-02P`, so this is a family the board and the BOM already
carry). Route `U1.130` to the new pin. Suggested order — keep the existing five
in place and append SWO — so any cable already made stays valid.

**Space check, measured:** H2 sits at (130.44, 115.59) rotated 90°, bbox
3.17 × 13.33 mm, so growth is ±1.27 mm along y. Nearest neighbours are lateral,
not in the growth path — C4 and C35 are ~6.5 mm away in x, H3 is clear in x
entirely. Re-verify during execution rather than trusting this.

**Two honest caveats:**

1. A 6-pin 0.1″ header is **not a plug-in standard** — the conventional choices
   are the 10-pin Cortex Debug connector or a 20-pin. It works fine with flying
   leads, which is how this bench already connects, but it is not a socket
   anything ships with. If a standard connector is wanted, decide that now
   rather than after copper exists.
2. **No firmware enables ITM today.** This buys capability that still has to be
   built on. It is cheap to add now and impossible to add after fabrication,
   which is the whole argument.

Add the part with `python tools/kicad_lcsc.py add C<n>` once the 6-pin variant's
LCSC code is confirmed, then `kicad_lcsc.py models`.

**Verification:** `/SWO` carries exactly two pads — `U1.130` and the new H2 pin.
DRC 0/0. `kicad_lcsc.py check` PASS. Header pin order documented on the bring-up
card, since the silk (U45) will label it `SWD` rather than enumerate pins.

---

## U47 outcome — one closed, three assessed and left

**Closed: the east `/+5V` home-run.** R61.1 and D11.1 each now have their own via
into the Inner2 plane. Proven with the same segment-deletion test that found the
defect: both cuts that previously orphaned `D11.2, LED4.2, R61.1` now yield zero
airwires, while a control cut on LED8's feed still yields one.

**BTN1's annular ring — NOT IMPROVABLE, measured.** The DFM lens suggested
"bump the pad to 0.6 and keep 0.175", which assumed room that does not exist.
The nearest other-net edge is U1.92's pad at 0.360 mm, capping via diameter at
**0.517 mm**:

| option | ring | verdict |
|---|---|---|
| current 0.5 / 0.2 | 0.1500 | at JLC's minimum, forces the 0.20 mm drill tier |
| 0.517 / 0.25 | **0.1335** | **below the 0.15 mm minimum — not allowed** |
| 0.517 / 0.2 | 0.1585 | +0.0085 mm, spends clearance margin for nothing |

So the existing 0.5/0.2 is already correct and `kicad_rules.json` documents it as
a deliberate exception. **U44's "declare 0.20 mm minimum hole" stands** — the
tier cannot be dropped without moving U1's escape.

**`/U12_RSTN` clearance — left as-is.** Tightest point is a 0.36 mm In2 segment
at x=233.28 against the `/TT8_LED_K` via: gap 0.1030 mm against a 0.1016 rule,
**margin +0.0014 mm**. It passes. Nudging it requires moving the adjacent
segments that share its endpoints — a re-route of working copper for 1.4 µm.

**Telltale cathode escape vias — CLOSED 2026-08-03.** LED2.1, LED6.1, LED7.1 and
LED8.1 each had a via centre *inside* the pad, so solder wicks down the barrel
during reflow (up to ~22% of one pad's deposit, asymmetric fillet, LED tilt
behind a lens). This was deferred as "a coordinated two-layer re-route, four
times, in the densest part of the board." Three of the four were not that: each
is a via at the pad centre with a stub into the pad and a longer track running
away, so the fix is to slide the via out **along the direction its own track
already runs** and lengthen the stub — no net changes layer, no chain is
re-established. LED6 south (0.345 clear), LED7 south on Inner1, LED8 west.

LED2 was genuinely hard, and the reason is the useful part: `/U12_RSTN`
*staircases around* that via — arriving west at y=87.960, zigzagging through
(235.24..235.28, 88.24..88.76), leaving west at y=89.040. That detour exists
*because* of the via, and it then blocks every escape from it (north 0.083,
south negative, east clears 0.793 but the Bottom track reaching it crosses the
staircase at -0.034). West works at 0.113 mm — tight, recorded as tight, and
accepted because a legal clearance beats a guaranteed assembly defect. Re-routing
`/U12_RSTN` so its staircase is unnecessary would open real margin and remains
the better long-term fix.

Specs: `tools/handroutes/u47b-telltale-escape-vias.json`, `u47c-led2-escape-via.json`.
A fifth, C66.1, was found by the same census and closed in `u47d-c66-escape-via.json`.
Every via-in-pad now left on the board is deliberate: U4's five exposed-pad
thermal vias, Q2's two plane stitches from U33, and U1.93's documented exception.

## Findings surfaced during execution — all closed 2026-08-03

**U3 and U4 pin-1 marker circles are clipped by solder mask.** Surfaced by U43:
arming `solder_mask_min_width` (which had been *absent*, therefore zero) took
DRC 0 → 2, both `silk_over_copper`.

    U3 (TPS563201) circle overlaps its /GND pad 1  by 0.1030 mm  (40% of stroke width)
    U4 (CH224K)    circle overlaps its /GND EP     by 0.0174 mm

The fab clips silk where it crosses a mask opening, so both pin-1 dots print
partially. **Warning severity — does not block fabrication.**

**A fix was attempted and reverted.** Recorded because the failure is more
useful than the attempt:

- The solve measured the circle against **the footprint's own pads**. That is the
  wrong model. Silk clipping is a *board-level* question, and arming
  `solder_mask_min_width` makes KiCad merge nearby mask openings into larger
  apertures and check the silk against those. Both circles were moved to a
  verified 0.15 mm clearance from every pad edge and **both warnings persisted
  unchanged**.
- Moving the library circle 0.004 mm and the instance 0.254 mm made them
  diverge, producing a `lib_footprint_mismatch` on U3 — the exact class
  documented in `docs/solutions/integration-issues/kicad-lib-footprint-mismatch-integer-nanometre-comparison.md`.
  A footprint edit must land in library *and* instance with identical numbers
  (KTD26), and "identical" means the same computed value, not the same intent.

**CLOSED 2026-08-03, and the prediction above was wrong.** No model of merged
mask apertures was needed: this board sets `SolderMaskExpansion = 0.0`, so the
apertures *are* the pad outlines and it is ordinary distance arithmetic. What
the earlier attempt actually got wrong was **scope** — it measured each circle
against its own footprint's pads.

U4 is the case it looked like: the binding constraint is pad 11, the full
exposed pad, not the four paste quadrants. Overlap 0.0175 mm, matching the
0.0174 recorded above; moving 0.20 mm along the corner normal gives +0.1828.

U3 was not about U3 at all. Its circle sat 0.1470 from its own pad 1 — three
microns short, so a small nudge looked right, and was wrong. The real clipper is
**L2.1, the buck inductor beside it**, which the circle already overlapped by
0.045 and which a nudge east made worse. The U3.1↔L2.1 corridor is 0.610 mm and
a 0.254-radius dot with 0.15 clearance either side needs 0.808, so no position in
that gap works. The dot moved diagonally out to (110.700,103.800) — clear of
U3.1 by 0.2442, of L2.1 by 0.2738, still north-east of pin 1, which is where pin
1 is.

Both circles moved in the library **and** the placed instance (KTD26), with the
footprint transform calibrated empirically from a pad rather than assumed: U3
sits at rot 90, where a board-space move of +x is a local move of +y, and
guessing the sign would have driven the dot further into the inductor. No
`lib_footprint_mismatch` appeared, which is the proof both sides moved together.

The rule stays armed. **DRC is now 0 errors and 0 warnings — the warning inbox
is empty.**

## Genuinely deferred — and why

Unlike the list above, these cannot be closed in this spin. The distinction
matters: **"spin 2" is only a real bucket when something blocks the work now.**

- **Board shrink.** Gated on carrier CAD and measured FFC tail reach — inputs
  that do not exist yet. Worth ~$15–30 per 5-board run; not worth guessing at.
  U46's `.step` fix is a prerequisite, since the carrier CAD needs a complete
  3D export.
- **CAN bus TVS.** `/CAN1_H`, `/CAN1_L`, `/CAN2_H`, `/CAN2_L` reach the harness
  with no transient protection. Defensible and **already a recorded decision**:
  the TJA1051T/3 carries ±8 kV IEC 61000-4-2 and ±58 V bus-fault ratings, and
  KTD3 makes the car's 12 V front-end the production board's problem. This board
  is a bench article.
*(`/SWO` was listed here and has been promoted to U49 — the fix is a 5-pin →
6-pin header in a family the board already uses, plus one route, which is not a
blocking input at all.)*

## Declined, with reasons

Reviewed and rejected — recorded so they are not re-opened:

- **Removing the CH224K (U4).** Two 5.1 kΩ CC pull-downs would do the same job
  (−2 placements, −1 extended line, −1 exposed-pad reflow risk), and its 100 W
  capability is genuinely unusable here — no rail could accept 9 V. But it is
  *correctly and safely strapped* (CFG1 high forces 5 V regardless of CFG2/CFG3),
  and removing it means re-laying the entire power-entry corner, which is where
  U33's copper work already carries risk. Not worth compounding.
- **Removing the ten orphan capacitors** (C20–C28, C56) — a 7.62 mm grid in open
  board with no active device within 9.8 mm, residue of the deleted ULN2803
  block. Every pad has two track endpoints, so removal is a re-route of a working
  area to save ~$0.20 of parts. The `/+5V` daisy-chain hazard is exactly what
  makes this dangerous rather than easy.
- **Printing all 138 designators** — see U45. The board file plus
  `kicad/board3/renders/` make every designator recoverable in seconds; function
  labels on connectors and buttons are worth more than refdes on 64 capacitors.

## Order-time instructions, not board changes

- **Ask for an AOI check on U12 P0_6.** The U12↔LED6 pad gap is 0.200 mm with
  zero mask expansion, and LED6's pad carries ~15× the paste volume of the QFN
  pin beside it. A bridge there lands `/+5V` on P0_6 — which is **unconnected**,
  so the board works perfectly with the defect present, no functional test finds
  it, and 5 V is inside the part's 6 V pin rating so it will not fail fast.
- **Fit the H1/H3 jumpers** if U42 has not shipped, so the existing split
  termination is at least symmetric.

## Post-fab bench debt — Kevin initiates all bench operations

Brownout soak on the corrected RSTN network, backlight current measurement (the
number that would have sized F1 properly), SPI clock walk, I2C rise-time
confirmation against the computed 220–240 ns, and beeping DC1 pad 1 to the plug
tip before assuming the center-pin mapping.

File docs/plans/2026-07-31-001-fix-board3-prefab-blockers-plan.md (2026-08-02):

---
title: Board3 Pre-Fab Blocker Close-Out - Plan
type: fix
date: 2026-07-31
topic: board3-prefab-blockers
artifact_contract: ce-unified-plan/v1
artifact_readiness: implementation-ready
product_contract_source: ce-plan-bootstrap
execution: code
origin: docs/reviews/2026-07-31-board3-prefab-review.html
---

# Board3 Pre-Fab Blocker Close-Out — Plan

## Goal Capsule

- **Objective:** Close the 1 CRITICAL + 5 HIGH confirmed findings from the 2026-07-31 six-lens pre-fab review, plus the recommended MEDIUM sweep, so Board3 can be released to JLCPCB. The copper is already clean (0 DRC violations, all nets connected); this campaign is footprint-library, schematic, sourcing, and rules work — not a re-route.
- **Branch:** `fix/board3-prefab-blockers`, cut from `main`.
- **Continuity:** Units continue the shared ID space at **U23**; requirements at **R45**; decisions at **KTD21**. Check plans `2026-07-24-001`, `2026-07-27-002`, `2026-07-27-003`, and `2026-07-28-001` before claiming any ID.
- **Product authority:** Kevin owns the design decisions. Five scope forks were presented at plan time and are recorded as KTD21–KTD25 under stated defaults — each is cheap to flip before execution starts, expensive after.
- **Stop conditions:** Stop if the Riverdi backlight-current measurement lands outside the range the PTC was sized for (re-size, do not proceed); if the AW9523B RSTN input threshold turns out incompatible with an RC from `/+5V`; if the U2 replacement's pinout is not pin-for-pin against the incumbent; or if the via-diameter bump introduces any new DRC violation that cannot be cleared without moving copper.

---

## Product Contract

### Summary

Board3's pre-fab review returned NO-GO on four conditions. Two are electrical and need new parts on the schematic (AW9523B reset sequencing; no overcurrent protection anywhere). One is a footprint-library defect class that makes three separate assembly checks silently vacuous (no courtyard on the AW9523B, no printed polarity mark on three telltale LEDs, unwindowed paste over all three exposed pads). One is sourcing (the QSPI flash has four units of stock). The recommended MEDIUM sweep — capacitor value reconciliation, via annular-ring margin, via-in-pad, edge clearance, an explicit stackup, and the CAN impedance target — is cheap now and expensive once gerbers ship.

The campaign's load-bearing structure is that **schematic changes require a manual Kevin-in-the-GUI sync (KTD12) and footprint-library changes do not.** Every schematic edit is therefore batched behind a single sync gate, and every non-schematic fix is sequenced to land either side of it without needing a second one.

### Problem Frame

The review verdict is NO-GO with six findings that each survived two independent refutation attempts (12 attempts, 0 refutations). Nothing in it questions the copper: DRC is clean at all severities via two independent tool paths, every multi-pad net is connected including the historically fragile `/+5V` telltale daisy-chain, and all measured geometry sits inside JLCPCB's capability envelope. The defects are in categories the routing work never touched.

Two of them exist *because* of a decision this project made deliberately. KTD17 removed the eight telltale series resistors and the DMOS driver in favour of the AW9523B's POR-default-safe GPIO state — and plan `2026-07-28-001` recorded the exposure at the time ("Removing all series resistors leaves no passive current limit in unconfigured states; POR defaults unchecked", P2, adversarial, confidence 75). The pre-fab review closed that loop with a vendor citation: the datasheet requires RSTN held low ~100 µs after VCC, and RSTN is hard-tied to `/+5V` on both ICs. The safety argument and the sequencing violation are the same mechanism seen from two ends.

The footprint findings are a different failure shape and the more instructive one: a check that cannot fail is not a passing check. `check_courtyard_overlaps` reported U11/U12 clean because the AW9523B footprint contains zero courtyard geometry. This is the same class already banked in `docs/solutions/conventions/a-gate-that-cannot-pass-gets-waved-through.md`, and it is why the plan verifies each footprint fix by asserting the check now *has something to test*, not merely that it passes.

### Requirements

- **R45.** Both AW9523B expanders (U11, U12) hold RSTN low for ≥100 µs after `/+5V` establishes, per the datasheet's Figure 6 power-on sequence, and recover correctly across a brownout-and-restore cycle rather than only a cold start.
- **R46.** The `/+5V_BARREL` input carries a resettable overcurrent element between DC1 and the Q2/U6 ideal-diode path, sized from a stated load figure with its temperature derating shown.
- **R47.** The AW9523BTQR footprint carries courtyard geometry in both the library and both placed board instances, so courtyard tooling tests real geometry on U11 and U12.
- **R48.** Every telltale LED position carries a cathode indicator on printed silkscreen (`F.SilkS`), not only on `F.Fab`. LED4, LED6, and LED7 are the three that do not today.
- **R49.** All three exposed-pad parts (U11, U12 QFN-24 EP 2.8 × 2.8 mm; U2 WSON-8 EP 5.2 × 4.65 mm) print windowed paste apertures in the 50–70 % coverage band, in both library and placed instances.
- **R50.** U2 is sourced to a part whose JLCPCB stock carries real order margin, on the identical land pattern, with its pinout verified pin-for-pin against the incumbent. U1's stock is re-verified in the same pass.
- **R51.** Every schematic artifact, its sourced LCSC part, and the board footprint's `Value` agree on component value — C67 is the known disagreement (schematic "22 µF" / sourced C19702 10 µF / board footprint "10 µF").
- **R52.** The board-wide default via carries annular-ring margin above JLCPCB's 0.15 mm absolute floor, and the one via-in-pad at U1.93 is either plugged by an explicit fab option or re-fanned.
- **R53.** P1, P2, and DC1 sit ≥0.5 mm from the board edge; USBC1's courtyard overhang is either nudged clear or recorded as a deliberate edge-launch exception.
- **R54.** The `.kicad_pcb` carries an explicit `(stackup)` block matching the ordered JLCPCB template, so no impedance number rests on an unenforced assumption.
- **R55.** CAN2's differential geometry and the 120 Ω target in `tools/kicad_rules.json` agree — either the routing is opened to the target gap, or the target is retired with the reasoning recorded.
- **R56.** Schematic annotations describe the as-built architecture. The `U10`/TBD62083 telltale-chain text, the `R25`–`R48` series-resistor table, the `CN4`/`CN5` SN65HVD230 breakout text, and the "5V/15A" supply note are all superseded.
- **R57.** The `+3V3` bulk capacitance sits inside the TPS563201's D-CAP2 stability window (20–68 µF), independent of the backlight-current gate blocking plan 003's U13/U14.
- ~~**R58.** ERC and power-tree analysis are re-run against the authoritative EasyEDA project before sign-off.~~ **RETIRED 2026-07-31 (KTD21): EasyEDA is no longer maintained, so there is no second source to reconcile against.** Replaced by: ERC is run against the KiCad schematic before sign-off, and the power tree is re-checked there after the RSTN and PTC parts land.

### Scope Boundaries

**In scope.** The four blocking conditions; the MEDIUM sweep listed in R51–R57; the schematic-annotation cleanup; regeneration of the fab package and renders; the EasyEDA reconciliation pass.

**Deferred to follow-up work.**

- **The +5 V bulk relocation and THT→SMD conversion** stays with plan `2026-07-27-003` U13/U14, still gated on the Riverdi backlight current. Only the `+3V3` half (R57) is pulled forward, on the review's own reasoning that it is independent of that gate.
- **AW9523B decoupling C61/C62 100 nF → 1 µF.** Same-footprint 0603 value change, but it is a datasheet-typical-vs-datasheet-minimum argument with no measured droop behind it. Fold into the next schematic pass or resolve on the bench; it does not block fabrication.
- **I2C pull-up re-sizing (R5/R8).** Only bites at 400 kHz Fast-mode, and the firmware's configured SCL rate is not yet fixed. Bench measurement item, not a fab blocker.
- **Local fiducials near U11/U12.** Optional at 0.5 mm pitch; the board's 250 mm length is the only reason to consider it.
- **Repo hygiene: the ~2.9 MB of unreferenced JLCImport footprints from `a995349`.** Worth answering ("was a swap intended?") but changes no fabricated artifact.

**Out of scope (KTD25).** The U4 CH224K → CH221K downgrade. It is a real simplification — a 100 W/20 V PD trigger on a board that only consumes 5 V, with the legacy fast-charge paths wired inert — but the package differs (ESSOP-10 → SOT-23-6), so it needs a full KTD12 GUI sync *plus* re-placement and re-routing of a working power-entry block. That is a redesign of a subsystem the review found sound, inserted into a campaign whose whole point is to stop touching working copper.

### Dependencies and Assumptions

- **KTD12 holds and is the campaign's critical path.** Schematic → board reconciliation is GUI-only; nothing automates it (all three candidate routes were tested and failed on this board — `kicad-cli pcb import` means foreign format, the `pcbnew` API exposes no netlist updater, and the KiCad MCP's `sync_schematic_to_board` returns `success: true` while assigning zero pads). KiCad must be **restarted** before the sync, since it syncs from eeschema's cache rather than the file.
- **EasyEDA is authoritative for schematic; the KiCad copy holds the routed, DRC-clean, fab-ready artifact, and conversion is one-way and lossy at six documented points.** Both statements are true and they conflict for this campaign — see KTD21.
- **The PTC sizing depends on the Riverdi RVT70HSBNWN00 backlight current**, the same unmeasured number that has gated plan 003's U13/U14 since 2026-07-27. KTD23 states the assumption the plan proceeds under.
- **Bench operations are Kevin-initiated.** Every measurement and soak in this plan is staged, never fired.
- The AW9523B datasheet (AWINIC, Mar 2024 V2.4) is the source for the RSTN sequencing requirement, the internal 100 kΩ RSTN pull-down, and the input threshold the RC must clear. The review cites the first two directly; the third is an execution-time read.

### Open Questions

- **The AW9523B RSTN input threshold is not yet in hand.** The review quotes the timing requirement and the 100 kΩ internal pull-down but not V<sub>IH</sub>. The RC values in U25 are sized against a conservative 0.7 × VCC assumption and must be re-checked against the datasheet before parts are ordered.
- **Whether JLCPCB's plugged/tented via option can be applied per-via or only board-wide.** Determines whether R52's U1.93 fix is an order-form checkbox or a re-fan. Answer at order time.
- **Whether the review's estimated U12-refdes/C62 silkscreen overlap is real.** Explicitly the weakest finding in the report, derived from estimated text width because the tooling was wedged. Resolve with a rendered check in U28, not by re-deriving the estimate.
- **What U2 is actually for on this board, and therefore whether 32 MB is genuinely ample.** KTD24's capacity argument is built from the *firmware image's* current asset budget (~1.66 MB splash pack, ~324 KB fonts) — but that budget describes the embedded-flash architecture, and the panel-QSPI render path was deleted on 2026-07-21 for a bandwidth reason, not a capacity one. If U2 exists to hold assets for three panels or anything video-shaped, the headroom argument needs re-deriving from that intent rather than from today's image. Confirm before U24 commits the swap; it does not change the stock problem, only the size of the answer.

**Baseline convention for the DRC gates.** Each unit's "DRC delta zero" is measured against the board as that unit found it, not against `main` — U26 deliberately expects to introduce clearance violations from the via bump and then clear them, so a fixed campaign-wide baseline would either mask that or fail it spuriously. The Definition of Done's single campaign-level assertion is the end-to-end check: `main`'s board and the final board both report clean, with no violation surviving in between.

---

## Planning Contract

### Key Technical Decisions

**KTD21. KiCad is authoritative. EasyEDA is retired.** ~~The KiCad copy is the fab source for this spin; EasyEDA is updated in parallel as the record.~~ **Superseded 2026-07-31, mid-execution, by Kevin: "we do not need to maintain easyeda project any more im moved off of that."**

`kicad/board3/` is now the design, not a downstream copy. This removes the conflict the original KTD21 was written to manage — there is no upstream to reconcile against, no dual-authoring, and no re-import question. Every remaining unit edits KiCad directly.

Three consequences worth stating, because they change what "done" means:

- **R58 is retired**, not deferred (see Requirements). The review's own caveat that its electrical findings covered "the KiCad copy only" is moot: that copy *is* the design, so the findings stand on their own rather than awaiting confirmation from a source that no longer exists.
- **`kicad/README.md` and CLAUDE.md are now wrong** where they say EasyEDA stays authoritative and conversion is one-way. U29 rewrites both.
- **KTD12 is unaffected.** The GUI-only schematic→board sync is a constraint of KiCad's own eeschema/pcbnew seam, not of EasyEDA. Retiring EasyEDA automates nothing about it.

The `EasyEDA/` directory and its `.eprj2` stay in the repo as history. The uncommitted `.eprj2` modification in the working tree predates this decision and is left alone.

**KTD22. RSTN gets an RC with a discharge diode, not a supervisor and not an MCU GPIO.** Three options were live. A **reset supervisor** ×2 is the most rigorous — a real threshold detector, correct brownout behaviour by construction — but it adds two ICs and two more parts to source, place, and route in a campaign whose thesis is minimal disturbance. **Driving RSTN from a freed PD pin** is the most elegant (zero new parts; the chip's internal 100 kΩ pull-down holds RSTN low at POR while the MCU's GPIOs are still high-Z, which is exactly the required behaviour). Be precise about why it loses, because the obvious reason is wrong: no option here restores a passive current limit on the LEDs — KTD17 spent that and none of these three give it back. All three only guarantee the expander's POR completes so its safe default is actually reached. The difference is *what the guarantee depends on*. The RC's guarantee is a time constant; the GPIO's guarantee is that the MCU boots, does not hang before de-asserting, and holds the pin correctly through every brownout the expander also sees. That makes the last passive layer under the telltales contingent on firmware and on two devices' reset domains agreeing — a coupling worth six passives to avoid. The **RC plus a Schottky from RSTN back to `/+5V`** is the datasheet-canonical answer: the resistor and cap set the power-on delay, and the diode discharges the cap when the rail collapses, which is what makes it survive the brownout-and-restore cycle a plain RC does not. Six passives across two ICs, all 0603, all in part classes already on this board. The plain-RC-without-diode variant is explicitly rejected — on a fast brownout the cap holds charge, RSTN never goes low, and the fix silently does not fire in the exact scenario the CRITICAL was raised for.

**KTD23. The PTC is sized now against a stated worst case, not held for the backlight measurement.** Holding it would park a confirmed HIGH behind a number that has already blocked other work for four days.

**The assumed load, stated so it can be falsified:** one 7" RVT70H plus two 5" RVT50H backlights at full duty, taken at 500 mA and 300 mA each respectively as the unmeasured placeholder, plus the H755, three EVE panels' logic, the QSPI flash, the FRAM, two AW9523Bs with eight telltales lit, and two CAN transceivers — call the logic side 400 mA. That is **~1.5 A worst case, ~1.1 A typical**. Every one of those backlight figures is an assumption; the logic side is bounded by parts whose datasheets are known.

Against that, a 2 A hold / 4 A trip 1812 part (`C960026`, BSMD1812-200-30V, ~20 mΩ initial, 174 k stock) derates to roughly 1.4 A hold at 60 °C ambient — under the 1.5 A worst case, which is the honest reading: it is sized for typical draw with headroom, not for every backlight at full duty in a hot cabin simultaneously. Its ~20 mΩ costs about 30 mV at 1.5 A, negligible against the shared-ground IR drop this project has already been bitten by. If the measured backlight current puts steady-state draw above ~1.3 A, the stop condition fires and the part moves up a size before order. The measurement is bench debt in U30 either way, because a PTC sized against an assumption is a protection element whose trip point nobody has confirmed.

**KTD24. U2 moves to the same-land-pattern 256 Mbit part rather than gambling on four units.** The review recommended qualifying a pin-compatible alternative "different W25Q512JV package/reel". Live re-verification today shows there is no such thing: at 512 Mbit, `C7389628` is still 4, `C2986165` (the other WSON-8-EP 6×8) is 3, and every other variant is 0 stock or a different package — the only healthy-stock 512 Mbit is `C2962011` in SOIC-16-300mil, which is a footprint change and a full GUI sync. One package step down solves it outright: **`C97522`, W25Q256JVEIQ, WSON-8-EP(6×8), 23,522 in stock, $4.37** — same manufacturer, same series, same land pattern, same 2.7–3.6 V / 133 MHz / SPI envelope, cheaper than the incumbent. Capacity is a non-issue: the entire current asset budget is the ~1.66 MB splash pack plus ~324 KB of fonts, against 32 MB. Because the land pattern is identical this is the U10 precedent exactly — supplier metadata plus a `Value` update, **no GUI sync** — and it converts a sourcing blocker into a sourcing surplus. Keeping the 512 and re-checking at order time stays available as the do-nothing alternative, but it accepts a one-customer-away stall on a single-instance required part.

**KTD25. The CH224K stays.** See Scope Boundaries. Retire the question, do not carry it as an open item into the fab decision.

**KTD26. Every footprint fix lands in the library *and* the placed board instances, in the same unit.** KiCad embeds a copy of each footprint into the `.kicad_pcb`, so a library-only fix changes nothing that gets fabricated, and an instance-only fix regresses the moment anyone re-links from the library. Fixing both also makes the U27 sync **order-independent**: whether or not Kevin ticks "replace footprints with those from the library", the result is correct. That property is why this unit runs before the sync rather than after.

### High-Level Technical Design

The campaign's shape is set by one constraint: the GUI sync is a manual, human-gated, once-per-campaign step. Everything is arranged around crossing it exactly once.

```mermaid
flowchart TD
  subgraph NOSYNC1["No sync needed — run first"]
    U23["U23 · Footprint library + placed instances<br/>courtyard · silk polarity · EP paste windows"]
    U24["U24 · U2 flash requalification<br/>same land pattern, metadata + Value only"]
  end

  U25["U25 · Schematic edits, batched<br/>RSTN RC+diode ×2 · PTC · C67 · +3V3 bulk · stale text"]
  U26["U26 · Board geometry, pre-sync<br/>via 0.6/0.3 → 0.7/0.35 · U1.93 · edge nudges"]

  SYNC{{"KEVIN · GUI<br/>restart KiCad, then<br/>Update PCB from Schematic<br/>re-link by reference"}}

  U27["U27 · Place and route the new parts<br/>6 RC passives · PTC · verify DRC delta"]
  U28["U28 · Rules and spec hygiene<br/>(stackup) block · CAN2 decision · silk clearance"]
  U29["U29 · Fab package · docs · EasyEDA reconciliation"]
  U30["U30 · Bench verification debt — Kevin fires"]

  U23 --> U25
  U24 --> U25
  U25 --> SYNC
  U26 --> SYNC
  SYNC --> U27
  U27 --> U28
  U28 --> U29
  U29 -.->|post-fab| U30

  style SYNC fill:#F9F1DD,stroke:#B27A14,stroke-width:2px
  style U30 stroke-dasharray: 5 5
```

Two orderings in that graph are load-bearing and neither is obvious:

**U26 runs before the sync, not after.** The via default changes from 0.6/0.3 to 0.7/0.35 mm. If the sweep ran after U27, the new copper laid for the RC networks and the PTC would be placed at the old size and then need a second sweep. Setting the default first means U27's routing is born at the new size.

**U23 runs before the sync, not after.** Per KTD26 — fixing library and instances together makes the sync's footprint-replacement checkbox a non-decision.

The RSTN network per IC, in the abstract (values are directional; the resistor is sized against the datasheet V<sub>IH</sub> at execution, and must stay well below the internal 100 kΩ pull-down so RSTN actually reaches a valid high):

```
  /+5V ──┬──────────────[ R ]──────┬────── RSTN (pin 23)
         │                          │
         └────────|◀|───────────────┘        Schottky: discharges C when the rail
              (discharge path)               collapses, so a brownout re-arms the delay
                                             │
                                            === C
                                             │
                                            GND

  ~100 kΩ internal pull-down at RSTN holds the pin low until C charges.
  Directional only — not an implementation specification.
```

---

## Implementation Units

### U23. Footprint library and placed instances — courtyard, polarity, paste windows

**Goal:** Close the three DFA blockers in one pass, in both the library and the embedded board copies, so the sync that follows cannot regress or contradict them.

**Requirements:** R47, R48, R49.

**Dependencies:** None. Run first.

**Files:**
- `kicad/board3/JLCImport.pretty/AW9523BTQR.kicad_mod`
- `kicad/board3/JLCImport.pretty/HL-A-3528H203BC-S1-13HL.kicad_mod`
- `kicad/board3/JLCImport.pretty/HL-A-3528S35FC-S1-13HL.kicad_mod`
- `kicad/board3/ProPrj_New-easyedapro.pretty/WSON-8_L8.0-W6.0-P1.27-TL-EP.kicad_mod`
- `kicad/board3/ProPrj_New Project_2026-07-15_23-14-34_2026-07-27.kicad_pcb` (embedded instances: U11, U12, U2, LED4, LED6, LED7)

**Approach:** Three independent edits, one unit because they share a verification pass and a blast radius of zero nets.

*Courtyard.* The AW9523BTQR footprint carries only `F.Cu`, `F.Fab`, and `F.SilkS` geometry — no courtyard at all. Add an `F.CrtYd` rectangle sized to the 4 × 4 mm body plus standard QFN margin (~4.3 × 4.3 mm), matching the stroke convention the other footprints in this library already use (0.05 mm). Then re-check U12 against LED6, whose bodies the review reconstructed as ~0.4–0.55 mm apart — a real clearance question that no tool has ever actually evaluated.

*Polarity.* Both affected LED footprints already carry a cathode-corner triangle on `F.Fab` and two plain symmetric lines on `F.SilkS`. Mirror the existing `F.Fab` mark onto `F.SilkS`, matching the pattern the other four LED footprints on this board already use (they carry 6–19 `F.SilkS` elements against these three's 2 lines plus a hidden ref). Confirm the mark lands on the cathode side by checking against the pad the schematic drives, not by assuming pad 1.

*Paste windows.* Every exposed pad on this board prints a single unwindowed deposit — a whole-board grep for `solder_paste_margin` returns zero matches. Segment each into a grid: keep the pad on `F.Cu`/`F.Mask`, drop `F.Paste` from it, and add paste-only apertures forming ~50–70 % coverage (a 3 × 3 grid on the 2.8 × 2.8 mm QFN EP lands near 73 % at 0.8 mm squares; a 2 × 2 at 1.0 mm lands near 51 % — pick inside the band and state the computed percentage). The 5.2 × 4.65 mm WSON EP needs its own grid.

**Patterns to follow:** `kicad/board3/JLCImport.pretty/HL-A-3528U51GC-S1-13HL.kicad_mod` (LED1/LED2) is the in-repo example of a correct silk polarity mark. Any footprint in `kicad/board3/ProPrj_New-easyedapro.pretty/` carrying `F.CrtYd` shows the house stroke width.

**Execution note:** Edit the `.kicad_mod` files as text and the board instances via `pcbnew`. Nothing is deleted here, so the SWIG proxy-lifetime trap does not apply — but the one-board-per-process rule does.

**Test scenarios:**
- Covers R47. `check_courtyard_overlaps` run against U11 and U12 now evaluates real geometry — assert the footprint's courtyard element count is non-zero *before* trusting the pass. A clean result on zero geometry is the defect, not the fix.
- Covers R47. U12-vs-LED6 courtyard clearance is measured and stated as a number; if it is negative, the plan gains a placement nudge and the DRC delta gate applies to it.
- Covers R48. Each of LED4, LED6, LED7 has ≥1 asymmetric `F.SilkS` element, and it sits on the cathode side as determined from the net the schematic drives.
- Covers R48. The five previously-correct LED positions are unchanged — element counts identical to pre-edit.
- Covers R49. Every exposed pad on U11, U12, U2 has paste coverage in [50 %, 70 %], computed as aperture area over EP area and stated per part.
- Covers R49. No pad lost its `F.Cu` or `F.Mask` layer in the process; pad count per footprint is unchanged except for added paste-only apertures.
- Library and board instances agree: re-reading the placed footprint yields the same courtyard/silk/paste geometry as the library file.
- DRC delta is zero against the pre-edit board.

**Verification:** All three checks now test something, and both the library and the fabricated artifact carry the fix.

---

### U24. U2 flash — requalify, swap to the same land pattern, re-verify U1

**Goal:** Convert a 4-unit sourcing blocker into surplus without touching a net, a pad, or a position.

**Requirements:** R50.

**Dependencies:** None (parallel with U23).

**Files:**
- `kicad/board3/ProPrj_New Project_2026-07-15_23-14-34_2026-07-27.kicad_sch`
- `kicad/board3/ProPrj_New Project_2026-07-15_23-14-34_2026-07-27.kicad_pcb` (U2 instance `Value` only)
- `kicad/board3/JLCImport.kicad_sym`, `kicad/board3/JLCImport.pretty/` (via `kicad_lcsc.py add`)

**Approach:** Per KTD24, the target is `C97522` (W25Q256JVEIQ, WSON-8-EP 6×8, 23,522 stock). Import it with `python tools/kicad_lcsc.py add C97522` so supplier metadata lands in `Supplier Part` — never a hand-placed symbol, and never left in the `LCSC` property the JLCImport plugin writes, which the BOM builder does not read.

**The pinout check is the gate, not a formality.** Winbond's W25Q series is pin-compatible across capacities within a package, but "series convention" is not evidence. Pull the pinout for both `C7389628` and `C97522` and compare pin-for-pin including the exposed pad's net before changing anything. If they differ, stop — the fallback is the SOIC-16 part with a full footprint change and a GUI sync, which is a different plan.

Then update the schematic symbol's supplier/manufacturer/value fields and the board footprint's `Value` via `fp.SetValue(...)` + save. That last step is not cosmetic: `Value` prints on the Component Marking Layer, so leaving it stale means fabricating a board marked with a part that is not fitted (the U10 precedent, 2026-07-28 — DRC, net count, and footprint count all unchanged). Because the land pattern is identical there is no footprint change and no net change, so **no GUI sync** — verify that against KTD12's actual wording rather than taking it from this plan.

Re-verify U1 (`C730212`, last seen at 37) in the same pass and record the number with its date.

**Test scenarios:**
- Covers R50. `C97522` and `C7389628` pinouts match pin-for-pin, exposed pad included, evidenced by the retrieved pinout data rather than asserted.
- Covers R50. Live stock for the chosen U2 part and for U1 is re-queried and recorded with the query date in the plan's sign-off notes.
- The board's footprint reference for U2 is unchanged (`ProPrj_New-easyedapro:WSON-8_L8.0-W6.0-P1.27-TL-EP`), and its position, rotation, and pad-to-net assignments are byte-identical.
- `python tools/kicad_lcsc.py check` passes with no gap, and the LCSC code appears in `Supplier Part`, not only in `LCSC`.
- The generated JLCPCB BOM row for U2 carries the new code and the matching value label — the failure mode this guards is a part silently vanishing from the BOM.
- Firmware asset budget still fits: the splash pack plus fonts against 32 MB, stated as a number.
- DRC delta zero; footprint count and net count unchanged.

**Verification:** U2 is sourced to a part with four orders of magnitude more stock, on the same land pattern, with the pinout proven rather than presumed.

---

### U25. Schematic — RSTN networks, PTC, C67, +3V3 bulk, stale annotations

**Goal:** Land every schematic-side change in one batch, so the campaign crosses the manual sync gate exactly once.

**Requirements:** R45, R46, R51, R56, R57.

**Dependencies:** U24 — it edits the same `.kicad_sch`, and letting both units write it concurrently is how a value edit gets clobbered by a metadata edit. U23 is independent of this unit and can run in parallel; it is sequenced before the sync for KTD26's reason, not this one.

**Files:**
- `kicad/board3/ProPrj_New Project_2026-07-15_23-14-34_2026-07-27.kicad_sch`
- `kicad/board3/JLCImport.kicad_sym`, `kicad/board3/JLCImport.pretty/` (new parts)

**Approach:** Five edits, batched deliberately.

*RSTN (R45).* Per KTD22, an RC plus a Schottky discharge diode between `/+5V` and each IC's pin 23, breaking RSTN out of the `/+5V` net onto its own net per IC. Size R and C against the datasheet's RSTN V<sub>IH</sub> and the internal 100 kΩ pull-down — R must be far below 100 kΩ or RSTN never reaches a valid high, and RC must clear 100 µs with real margin. A 10 kΩ / 100 nF pair gives τ ≈ 1 ms and a ~4.55 V final level against the internal pull-down; treat those as the starting point to confirm, not the answer. Import all three part classes through `kicad_lcsc.py add`.

*PTC (R46).* Per KTD23, insert the resettable fuse between DC1 and the Q2/U6 ideal-diode path on `/+5V_BARREL`. Record the sizing arithmetic — assumed load, hold current, derated hold at 60 °C, series resistance and its voltage drop — in the schematic or the plan, not only in a commit message. A protection part whose trip point is unrecorded is the same defect class as an unenforced stackup.

*C67 (R51).* Three artifacts, two answers. The sibling group (C29/C30/C31/C48/C49/C66/C68) uses `C45783` at 22 µF/0805 while C67 points at `C19702` at 10 µF/0603 with a "22uF" label. The board footprint already says 10 µF and is 0603, so the sourced part and the physical land pattern agree and only the label is wrong — resolve toward 10 µF unless the circuit genuinely wanted 22 µF, in which case the part *and* footprint change and this becomes a sync item rather than a label fix.

*+3V3 bulk (R57).* C2 + C16 = 440 µF against the TPS563201's 20–68 µF D-CAP2 window — roughly 6.5× over, and for this topology more capacitance lowers crossover frequency and degrades phase margin, so "more is safer" is false. Bring the total inside the window by the least invasive route available (depopulating one and re-valuing the other, or a single in-window part). The +5 V half stays with plan 003's gated U13/U14.

*Annotations (R56).* Delete or mark SUPERSEDED: the `U10`/TBD62083 driver text, the `R25`–`R48` telltale-chain resistor table, the `CN4`/`CN5` SN65HVD230 breakout description (the board carries on-board TJA1051s), and the "J1: +5V IN (dedicated 5V/15A supply)" note — the last one only after the real supply spec is confirmed, since if 15 A is real the PTC sizing conversation changes rather than closes.

**Execution note:** Edit the KiCad `.kicad_sch` directly — it is the design now (KTD21, revised). Do not begin the sync in this unit. Because these are new symbols and new nets rather than property edits, prove connectivity by netlist export and ERC before handing to the sync; a wire stub that misses a pin by one grid step is an unconnected pin that no amount of later DRC will catch.

**Test scenarios:**
- Covers R45. Netlist export shows `U11` pin 23 and `U12` pin 23 on their own nets, each with exactly one resistor and one diode terminal, and no longer members of `/+5V`. This is the direct inverse of the review's netlist proof.
- Covers R45. The RC time constant is stated with the datasheet V<sub>IH</sub> it was computed against, and the resulting delay exceeds 100 µs with margin.
- Covers R45. The discharge diode's orientation is verified from the netlist — cathode toward `/+5V` — because a reversed diode turns the fix into a permanent RSTN clamp.
- Covers R46. Netlist shows the PTC in series between DC1 and Q2/U6 on `/+5V_BARREL`, not bridged across it.
- Covers R46. The sizing record states assumed load, derated hold current at 60 °C, and the series voltage drop at that load.
- Covers R51. C67's `Value`, its `Supplier Part`, and the board footprint's value all agree, and the JLCPCB BOM row reflects it.
- Covers R57. Total `+3V3` bulk is ≤68 µF and ≥20 µF, stated as a number against the datasheet table.
- Covers R56. Grep for `U10`, `TBD62083`, `SN65HVD230`, `5V/15A`, and the `R25`–`R48` designators in the schematic returns only text explicitly marked superseded, or nothing.
- All new parts pass `kicad_lcsc.py check` with supplier metadata and 3D models.
- The `/BTN1`–`/BTN4` nets and every telltale net are unchanged — a diff against the pre-edit netlist proves this unit touched only what it meant to.

**Verification:** Every schematic-side fix is in, the netlist proves each one at the pin level, and the board has not been touched yet.

---

### U26. Board geometry, pre-sync — via margin, via-in-pad, edge clearance

**Goal:** Give the whole board real annular-ring margin and clear the edge-clearance and via-in-pad residuals, before any new copper is laid.

**Requirements:** R52, R53.

**Dependencies:** U23 (footprint geometry settled first, since edge-clearance measurement uses courtyards).

**Files:**
- `kicad/board3/ProPrj_New Project_2026-07-15_23-14-34_2026-07-27.kicad_pcb`
- `tools/kicad_rules.json` (default netclass via dimensions)

**Approach:** Roughly 198 of 199 vias sit within 0.0025 mm of JLCPCB's 0.15 mm absolute annular-ring floor — 98 at 0.6/0.3 and 100 at 0.61/0.305 (the U7 thermal batch) — which passes DRC with literally zero registration margin against a fab whose own guidance recommends 0.20 mm. Raise the default to 0.7/0.35 mm (0.175 mm ring), keeping the 0.35 mm drill comfortably above the 0.3 mm cost floor recorded in `tools/kicad_rules.json`.

**This bump is not free and the plan must treat it as a real change.** Growing every via's diameter by 0.1 mm adds 0.05 mm of copper radius on 198 vias on a board routed at 0.1016 mm clearance with 0.254 mm tracks. New clearance violations are the expected outcome in tight areas, not a surprise — the QFN escape mouths and the telltale restack are the likely sites. Sweep, re-run DRC, and resolve each new violation individually; if any cannot clear without moving copper, the stop condition fires and that via keeps its old size with a recorded exception, exactly as U1.93's 0.2 mm drill already does.

For U1.93 (R52): prefer JLCPCB's plugged/tented via-in-pad option if it can be specified for this order — an unplugged 0.2 mm barrel in a small pad wicks solder off a live MCU I/O during reflow, and KiCad's DRC cannot see it at all. If the option is board-wide-only and unwanted, re-fan the BTN1 escape.

For edge clearance (R53): P1 and P2 sit ~0.195 mm from the bottom edge and DC1 ~0.224 mm from the left/bottom — all inside typical ±0.1–0.2 mm depaneling tolerance, where a routing deviation clips a connector flange. Nudge each inward to ≥0.5 mm. USBC1's courtyard overhangs the left edge by ~0.37 mm while its real pads stay >3 mm clear; nudge or record the edge-launch exception, and say which.

**Execution note:** Read every board fact through `pcbnew`, never regex — this project has produced three separate wrong conclusions from parsing `.kicad_pcb` as text, including "the board has no tracks" against 2,487 of them. When checking what a nudge disturbs, clip segments against the query window (Liang-Barsky); do not filter by endpoint containment, which hid a full-width Inner1 river twice in one session.

**Test scenarios:**
- Covers R52. Minimum annular ring across all vias is ≥0.175 mm, measured from the board rather than assumed from the rule.
- Covers R52. DRC after the sweep has zero new violations against the pre-sweep baseline; any via that kept its old size carries a recorded reason.
- Covers R52. U1.93 is either plugged by a stated fab option or no longer has a via inside the pad — a pad audit confirms which.
- Covers R53. P1, P2, and DC1 courtyard-to-`Edge.Cuts` clearance is ≥0.5 mm, each stated.
- Covers R53. USBC1 is nudged clear or the exception is written down where a future reviewer will find it.
- `kicad_measure --against` shows only the intended nets changed by the connector nudges, and airwires remain 0.
- Zone fills are refreshed before any post-nudge measurement — an unrefilled zone measures the old copper.

**Verification:** Every via has registration margin, no connector sits inside depaneling tolerance, and the via-in-pad residual is resolved or explicitly plugged.

---

### U27. Sync gate, then place and route the new parts

**Goal:** Get the RSTN networks and the PTC onto copper, cleanly, in one pass through the manual gate.

**Requirements:** R45, R46.

**Dependencies:** U25 and U26 both complete. **This unit opens with a Kevin-in-the-GUI step and cannot start without it.**

**Files:** `kicad/board3/ProPrj_New Project_2026-07-15_23-14-34_2026-07-27.kicad_pcb`

**Approach:** The gate first: **restart KiCad**, then Update PCB from Schematic with re-link-by-reference ticked. The restart is not optional — KiCad syncs from eeschema's cache rather than the file, and an out-of-editor schematic edit without a restart silently reports no changes. Per KTD26, U23 already fixed both library and instances, so the footprint-replacement option is safe either way.

Then place: the six RSTN passives go adjacent to their respective ICs — U11 at approximately (85, 95), U12 at (227, 100) — with the cap nearest the pin, since a decoupling-style network sited 5 mm out is the review's separate complaint about C61/C62 and there is no reason to repeat it. The PTC goes between DC1 and Q2/U6 in the power-entry corner; it is an 1812 part and needs the room.

Then route. Two traps this board has already paid for apply directly. **Search every copper layer before placing any via** — the thrice-paid lesson. And route the most boxed-in pad first so fanouts nest: at the QFN mouths, the last of several nets sharing one escape always loses, and a mouth between a pad column and a wall fits exactly two 0.254 mm tracks. Exact point-segment and segment-segment math from raw endpoints is the clearance oracle here; `GetEffectiveShape().Collide()` under-covers segment midpoints and misreports vias on inner layers, and `tools/kicad_verify.py` is the only judge.

Note that `/+5V` daisy-chains *through* the telltale pads — the topology that forced U11's telltale swap to be reverted. Any new `/+5V` tap for the RSTN networks joins a chain, not an independent stub.

**Test scenarios:**
- Covers R45, R46. All new parts are placed, and airwires are 0 — every RSTN and PTC pad is connected.
- Covers R45. Board-level connectivity confirms each RSTN net reaches exactly its IC's pin 23, its resistor, its diode, and its cap — derived from a `pcbnew` connectivity graph, not from the schematic netlist alone.
- Covers R46. The PTC is in series in the copper, not shorted across by a leftover `/+5V_BARREL` segment from before the insert.
- DRC delta is zero against the post-U26 baseline, at all severities.
- No via lands inside an SMD pad — the pad audit gate, since this is the defect class that survived both DRC and the measurement harness once already.
- Existing telltale, button, SPI, and CAN nets are unchanged; `kicad_measure --against` shows only the new nets and the intended `/+5V`/`/+5V_BARREL` edits.
- Zones refilled and re-measured after routing completes.

**Verification:** The CRITICAL and the protection HIGH are on copper, the board is DRC-clean, and nothing else moved.

---

### U28. Rules and spec hygiene — stackup, CAN target, silk clearance

**Goal:** Stop the remaining specs from resting on assumptions nothing enforces.

**Requirements:** R54, R55.

**Dependencies:** U27.

**Files:**
- `kicad/board3/ProPrj_New Project_2026-07-15_23-14-34_2026-07-27.kicad_pcb` (`(stackup)` block)
- `kicad/board3/ProPrj_New Project_2026-07-15_23-14-34_2026-07-27.kicad_pro` (`min_silk_clearance`)
- `tools/kicad_rules.json` (CAN impedance target)

**Approach:** *Stackup (R54).* The board carries `(general (thickness 1.6))` and no `(stackup)` node at all, so every impedance number in `tools/kicad_rules.json` rests on an assumed JLC04161H-7628 template — currently correct, verified live, and enforced by nothing. Write the block explicitly: 4-layer, 1.6 mm, 1 oz outer, 7628 prepreg 0.2104 mm, 1.065 mm core. Confirm the same template is selected on the order form; a written block that disagrees with the order is worse than none.

*CAN (R55).* CAN2's tightest approach is ~0.406 mm centre-to-centre (~0.15 mm edge gap), which is USB's 90 Ω coupling, not CAN's 120 Ω target; CAN1's legs are ~1.08 mm apart and uncoupled for most of their run. Per the default recorded at plan time, **retire the 120 Ω target** rather than re-route: at 1 Mbps the repo's own analysis argues coupling is not load-bearing given the symmetry and skew already handled, and the two pairs currently disagree with the spec in opposite directions. Retiring means deleting the target from `tools/kicad_rules.json` *with the reasoning written in its place* — an unmet spec sitting next to a design that does something else is the failure this closes, and a silently deleted spec recreates it.

*Silk clearance (LOW, folded in).* `min_silk_clearance` is 0.0, which makes silk-over-pad structurally unable to fail — the same shape as the missing courtyard. Set it to JLCPCB's 0.15 mm and re-run DRC. This also settles the review's weakest finding, the estimated U12-refdes/C62 overlap, with a measurement instead of an estimate.

**Test scenarios:**
- Covers R54. The `.kicad_pcb` contains a `(stackup)` block whose layer count, thickness, copper weight, and dielectric match the JLCPCB template named on the order form.
- Covers R55. `tools/kicad_rules.json` and the routed geometry agree — either CAN2's gap meets the stated target, or no unmet target remains and the reasoning is recorded at the point of deletion.
- Silk clearance is 0.15 mm and DRC re-run reports zero silk-over-pad violations, or each one is listed and resolved.
- The U12-refdes/C62 question is answered from a rendered or measured check, and the answer is written down either way.
- DRC delta against U27's board is zero except for silk findings the new rule newly makes visible.

**Verification:** No spec in the repo is both unmet and unretired, and no check is structurally incapable of failing.

---

### U29. Fab package, docs, and EasyEDA reconciliation

**Goal:** Produce the artifact that gets ordered, and prove the authoritative source agrees with it.

**Requirements:** R58, plus the documentation trail for every decision above.

**Dependencies:** U28.

**Files:**
- `fab/` (regenerated), `kicad/board3/renders/`
- `CLAUDE.md`, `kicad/README.md`
- `docs/plans/2026-07-27-003-feat-telltale-driver-and-rail-decoupling-plan.md` (R57 supersession note on the +3V3 half)
- `docs/plans/2026-07-28-001-feat-i2c-peripheral-consolidation-plan.md` (close the deferred POR question)

**Approach:** Regenerate the fab package with `tools/kicad_fab.py` **launched under KiCad's own interpreter** (`C:/Program Files/KiCad/10.0/bin/python.exe`). It has no self-reexec: under a bare `python` it silently skips gerber renaming and the rotation audit and still reports a written package, just a degraded one whose layers are named `Top Layer.gbr`. Empty `fab/gerbers/` first so stale layers cannot survive into the zip.

Then the reconciliation (R58). The entire review ran against the KiCad copy because the EasyEDA bridge was down and the desktop app was not running. Start the app, toggle the bridge extension, and run `easyeda_semantic_erc_validate`, `easyeda_power_tree_analyze`, and an operating-point pass. Compare the EasyEDA netlist against the KiCad one at the pin level for the nets this campaign touched — the RSTN nets, `/+5V`, `/+5V_BARREL`, `/+3V3` — and record any disagreement as a finding rather than reconciling it silently. Per KTD21 this is the check that earns the one-spin exception; skipping it turns the exception into a fork.

Documentation: CLAUDE.md gains the RSTN sequencing requirement and the PTC as durable hardware truths, plus the KTD21 exception and its expiry condition. Plan 003 gets a note that its `+3V3` half was pulled forward. Plan `2026-07-28-001`'s deferred POR question is closed with a pointer to KTD22 — it was raised at confidence 75 and has now been confirmed and fixed, and leaving it open would re-litigate it.

**Test scenarios:**
- Covers R58. EasyEDA ERC and power-tree run and their findings are recorded; the RSTN, `/+5V`, `/+5V_BARREL`, and `/+3V3` nets match between the two projects at the pin level.
- Fab package regenerates with correctly-named layers (`F_Cu.gbr`, not `Top Layer.gbr`) — the direct symptom of the degraded-interpreter run.
- The rotation audit runs and reports; BOM and CPL contain every part including all new ones, with U2's new code.
- `python tools/kicad_lcsc.py check` and `duplicates` both pass.
- Renders are refreshed and the CI render gate would pass.
- Every finding from the review's "Path to GO" list is either closed with a pointer to the unit that closed it, or explicitly deferred with a reason.

**Verification:** The fab package is complete and correctly named, the authoritative source agrees with what will be ordered, and the docs record why the exception was taken.

---
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

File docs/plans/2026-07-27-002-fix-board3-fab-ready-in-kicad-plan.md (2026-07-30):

---
title: Board3 Fab-Ready in KiCad - Plan
type: fix
date: 2026-07-27
topic: board3-fab-ready-kicad
artifact_contract: ce-unified-plan/v1
artifact_readiness: implementation-ready
product_contract_source: ce-plan-bootstrap
execution: code
origin: docs/plans/2026-07-27-001-chore-kicad-evaluation-plan.md
---

# Board3 Fab-Ready in KiCad - Plan

> **Successor note (2026-07-29):** the telltale/button architecture this
> plan's board carried was revised by the I2C consolidation plan
> ([2026-07-28-001](2026-07-28-001-feat-i2c-peripheral-consolidation-plan.md)):
> the DMOS driver, its eight series resistors, and the lamp home-runs are
> gone; two AW9523B expanders on I2C2 drive the telltales. This plan's
> fab-ready bar, gates, and toolchain remain the standing reference.
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

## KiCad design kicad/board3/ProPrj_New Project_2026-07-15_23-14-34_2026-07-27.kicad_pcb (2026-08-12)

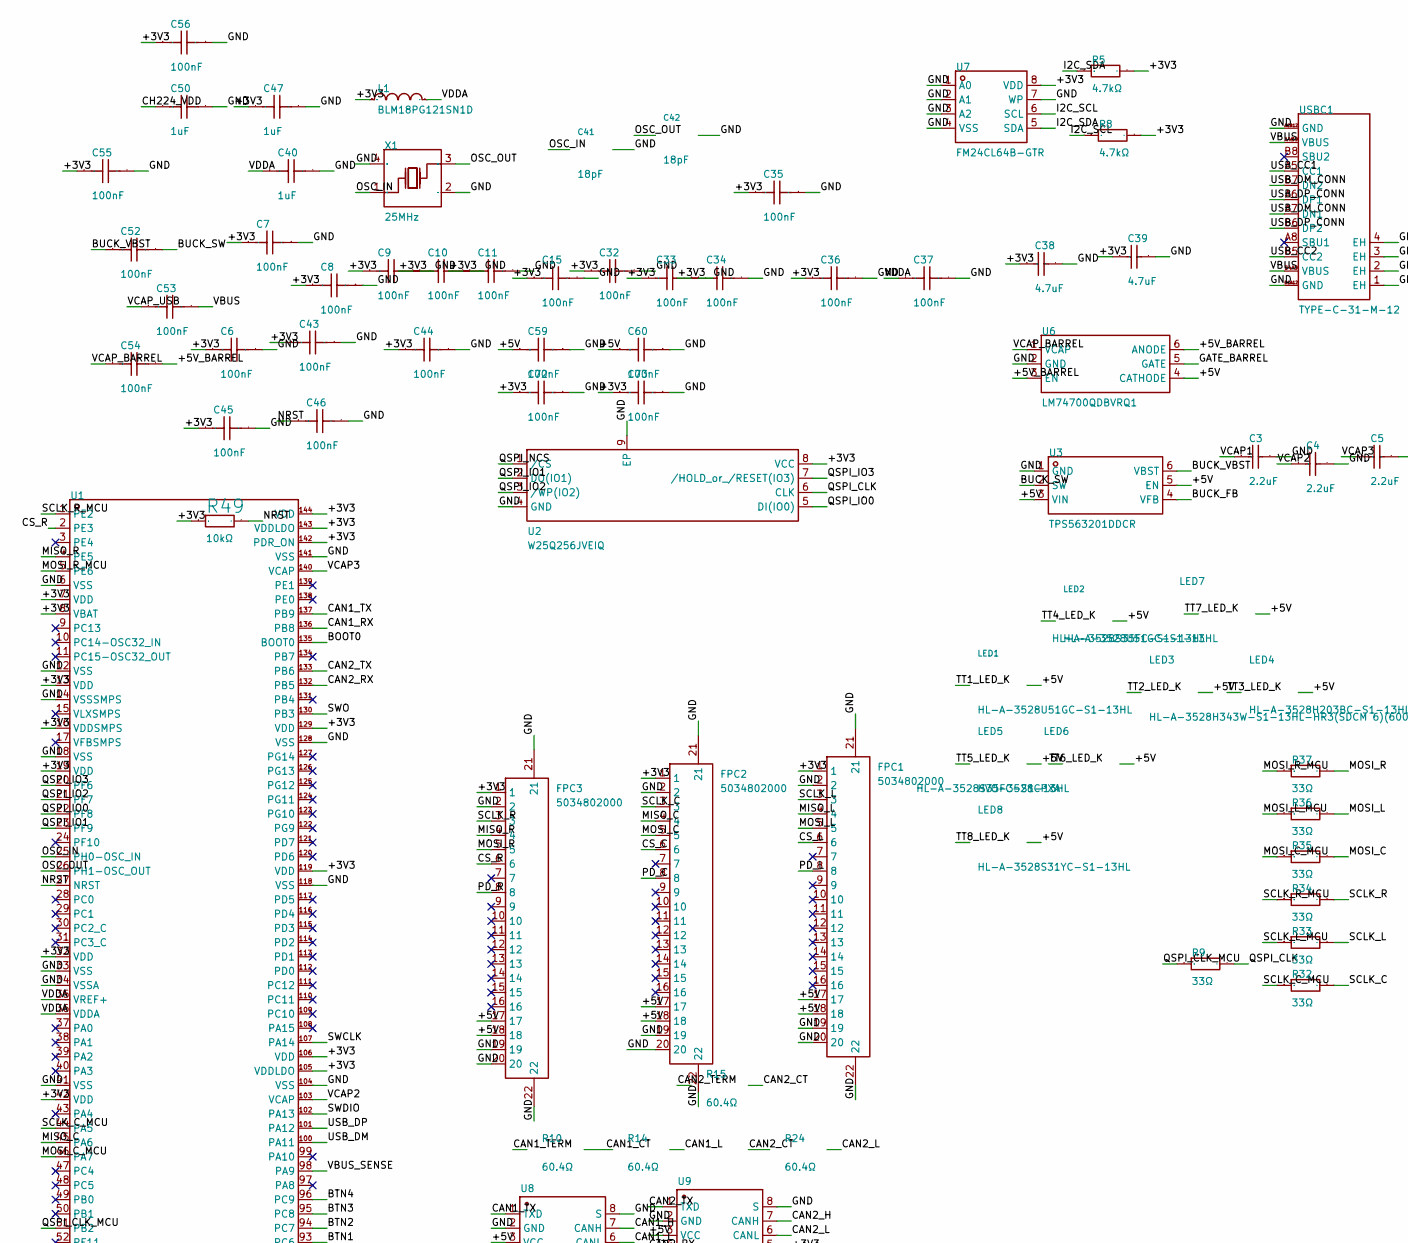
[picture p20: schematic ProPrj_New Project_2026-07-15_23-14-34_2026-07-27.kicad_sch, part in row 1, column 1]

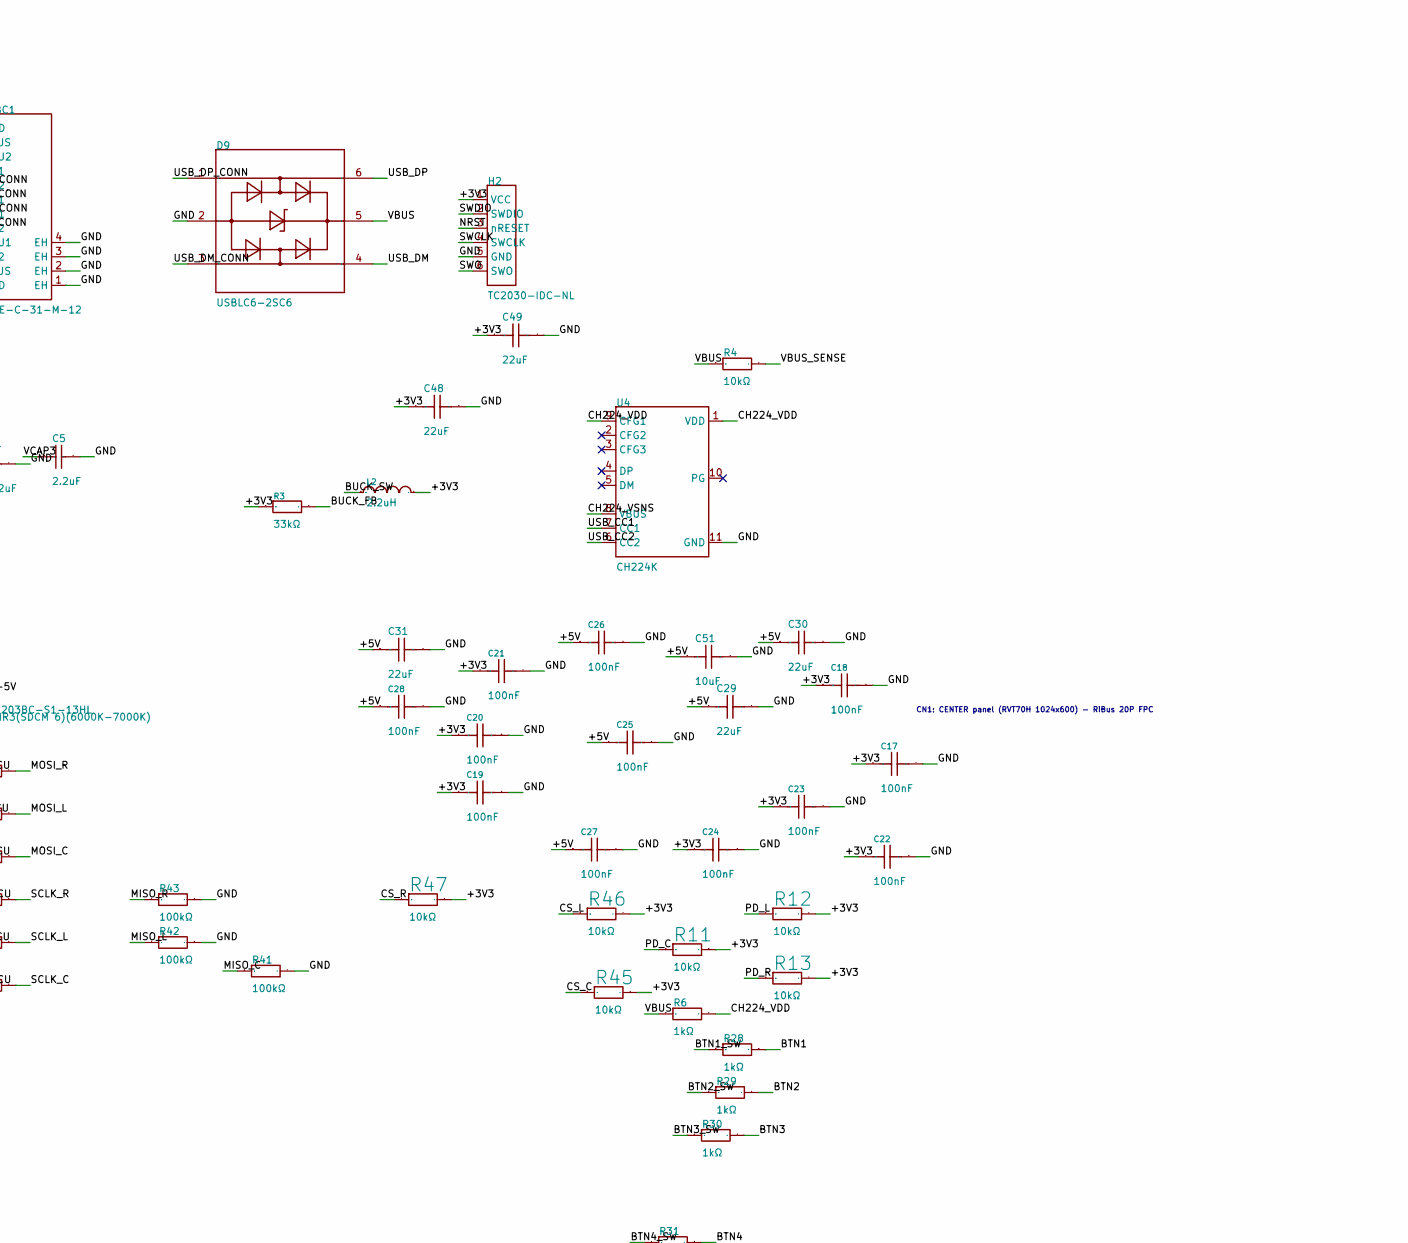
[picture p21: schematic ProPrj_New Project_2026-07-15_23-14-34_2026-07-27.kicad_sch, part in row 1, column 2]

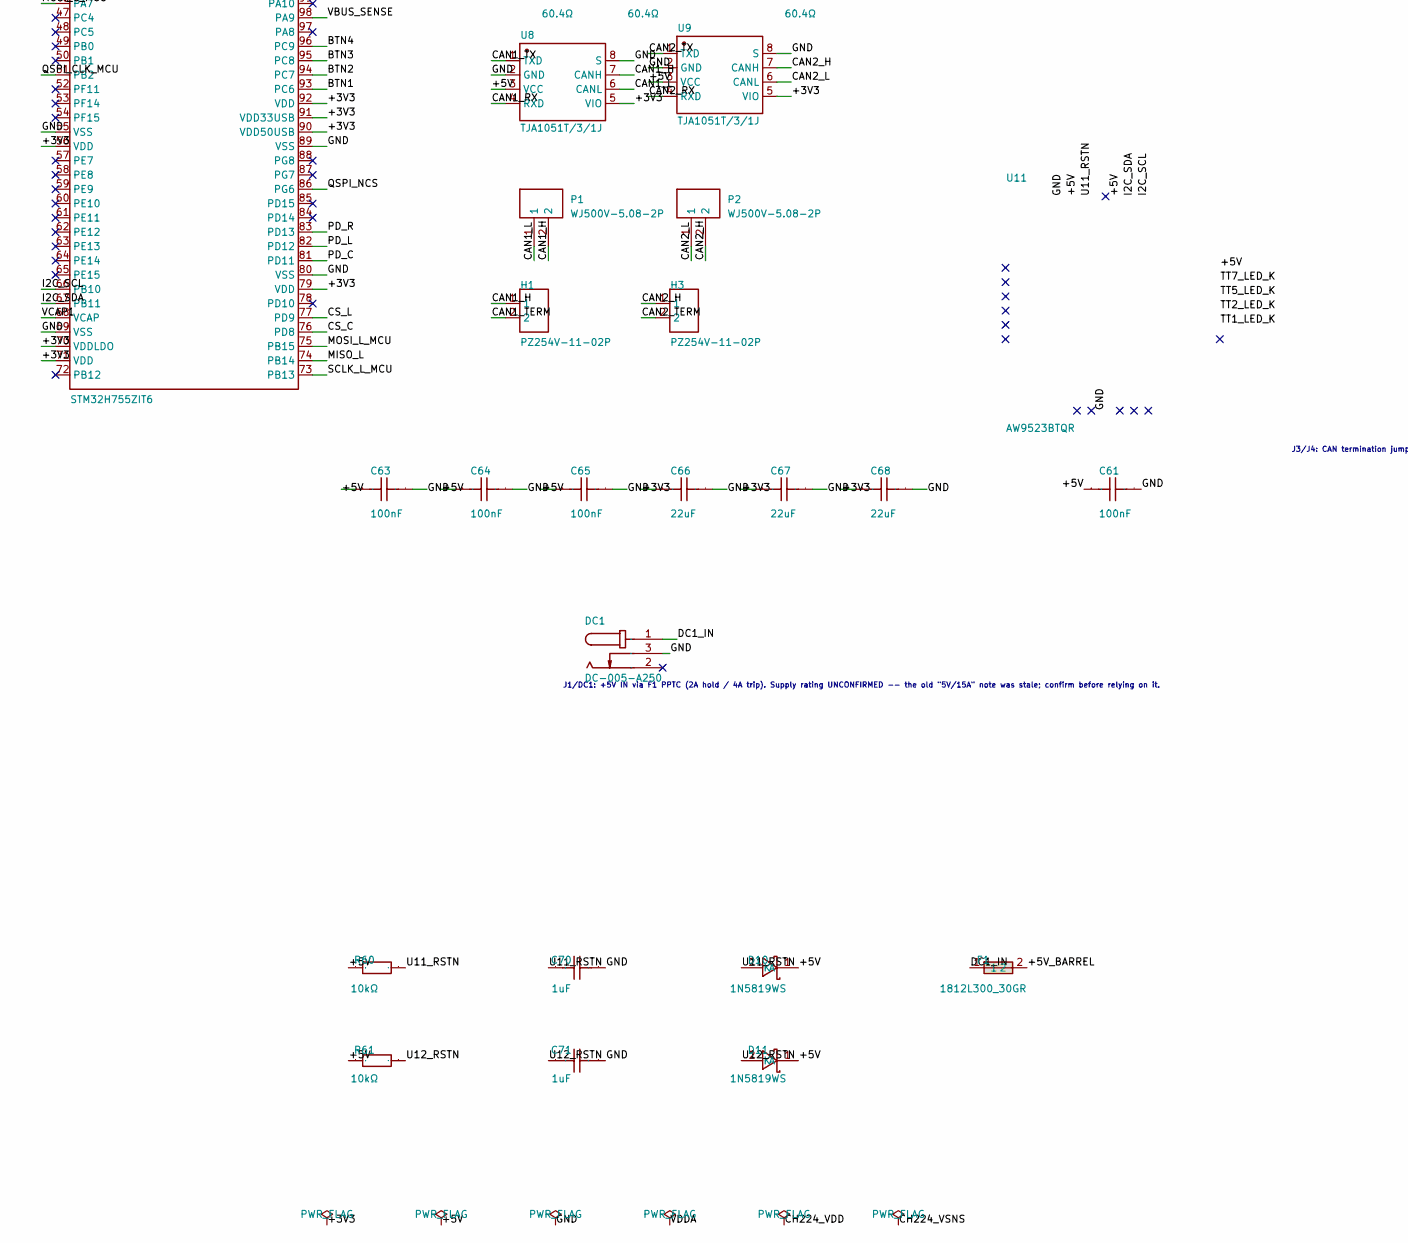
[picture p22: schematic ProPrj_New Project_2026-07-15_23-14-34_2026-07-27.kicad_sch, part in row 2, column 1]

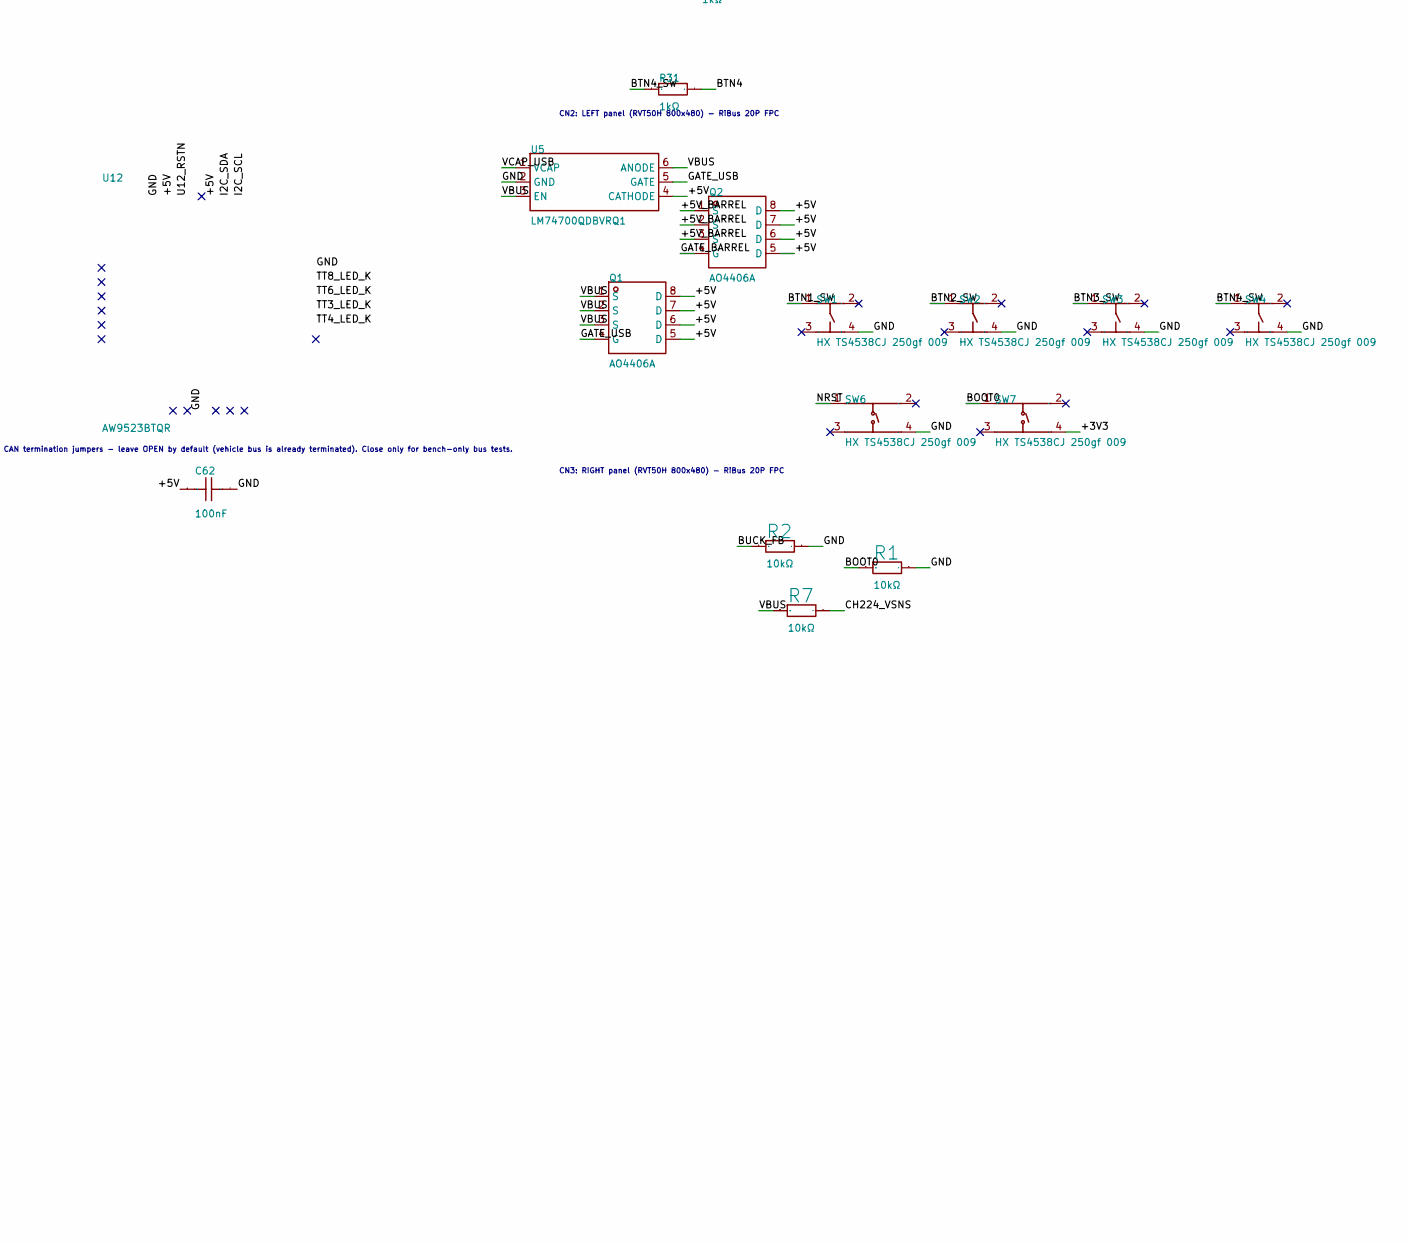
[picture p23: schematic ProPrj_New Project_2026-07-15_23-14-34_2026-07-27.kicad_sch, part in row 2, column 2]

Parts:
C3, C4, C5: 2.2uF; C0603; Manufacturer Part CL10A225KO8NNNC; JLCPCB Part Class Basic Part
C6, C17, C18, C19, C20, C21, C22, C23, C24, C25, C26, C27, C28, C35, C37, C43, C44, C45, C46, C52, C53, C54, C55, C56, C59, C60, C61, C62, C63, C64, C65, C72, C73: 100nF; C0603; Tolerance ±10%; Voltage Rating 50V; Manufacturer Part CC0603KRX7R9BB104; LCSC Part Name 100nF ±10% 50V
C7, C8, C9, C10, C11, C15, C32, C33, C34, C36: 100nF; C0603; Manufacturer Part CC0603KRX7R9BB104; JLCPCB Part Class Basic Part
C29, C30, C31, C66, C68: 22uF; C0805; Tolerance ±10%; Voltage Rating 25V; Manufacturer Part CL21A226MAQNNNE; LCSC Part Name 22uF ±20% 25V
C38, C39: 4.7uF; C0805; Manufacturer Part CL21A475KAQNNNE; JLCPCB Part Class Basic Part
C40, C70, C71: 1uF; C0603; Manufacturer Part CL10A105KB8NNNC; JLCPCB Part Class Basic Part
C41, C42: 18pF; C0603; Manufacturer Part CL10C180JB8NNNC; LCSC Part Name 18pF ±5% 50V
C47, C50: 1uF; C0603; Tolerance ±10%; Voltage Rating 50V; Manufacturer Part CL10A105KB8NNNC; LCSC Part Name 1uF ±10% 50V
C48, C49: 22uF; C0805; Tolerance ±20%; Voltage Rating 25V; Manufacturer Part CL21A226MAQNNNE; LCSC Part Name 22uF ±20% 25V
C51: 10uF; C0805; Tolerance ±10%; Voltage Rating 25V; Manufacturer Part CL21A106KAYNNNE; LCSC Part Name 10uF ±10% 25V
C67: 22uF; C0805; Tolerance ±10%; Voltage Rating 25V; Manufacturer Part CL21A226MAQNNNE; LCSC Part Name 10uF ±10% 10V
D9: USBLC6-2SC6; SOT-23-6_L2.9-W1.6-P0.95-LS2.8-BL; Clamping Voltage 17V; Voltage - Breakdown 6V; Manufacturer Part USBLC6-2SC6; LCSC Part Name 单向ESD
D10, D11: 1N5819WS; Manufacturer Part 1N5819WS; JLCPCB Part Class Basic Part
DC1: DC-005-A250; DC-IN-TH_DC-005-2; Manufacturer Part DC-005-A250; LCSC Part Name DC-005-5.5*2.5
F1: 1812L300_30GR; Manufacturer Part 1812L300/30GR; JLCPCB Part Class Extended Part
FPC1, FPC2, FPC3: 5034802000; FPC-SMD_5034802000; Current Rating (Max) 500mA; Rated Voltage (Max) 50V; Manufacturer Part 5034802000; LCSC Part Name 翻盖式 双侧触点/上下接 P数:20P 间距:0.5mm
H1, H3: PZ254V-11-02P; HDR-TH_2P-P2.54-V-M; Current Rating 3A; Voltage Rating (Max) 250V; Manufacturer Part PZ254V-11-02P; LCSC Part Name 1x2P 间距:2.54mm 方针 直插
H2: TC2030-IDC-NL; Tag-Connect_TC2030-IDC-NL_2x03_P1.27mm_Vertical
L1: BLM18PG121SN1D; L0603; Manufacturer Part BLM18PG121SN1D; JLCPCB Part Class Basic Part
L2: 2.2uH; IND-SMD_L4.0-W4.0_FNR40XXS; Current Rating 3.2A; Tolerance ±20%; Manufacturer Part FNR4030S2R2MT; LCSC Part Name 2.2uH ±20% 5.8A
LED1, LED2: HL-A-3528U51GC-S1-13HL; Voltage - Forward(Vf) 3.4V; Manufacturer Part HL-A-3528U51GC-S1-13HL; LCSC Part Name HL-A-3528U51GC-S1-13HL
LED3: HL-A-3528H343W-S1-13HL-HR3(SDCM 6)(6000K-7000K); HL-A-3528H343W-S1-13HL-HR3_SDCM_amp_lt_6_6000K-7000K; Voltage - Forward(Vf) 3.2V; Manufacturer Part HL-A-3528H343W-S1-13HL-HR3(SDCM 6)(6000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; LCSC Part Name HL-A-3528H343W-S1-13HL-HR3_SDCM_amp_lt_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
LED4: HL-A-3528H203BC-S1-13HL; Voltage - Forward(Vf) 3.4V; Manufacturer Part HL-A-3528H203BC-S1-13HL; LCSC Part Name HL-A-3528H203BC-S1-13HL
LED5: HVO-3528CPXA; Voltage - Forward(Vf) 2.2V; Manufacturer Part HVO-3528CPXA; LCSC Part Name HVO-3528CPXA
LED6, LED7: HL-A-3528S35FC-S1-13HL; Voltage - Forward(Vf) 2.4V; Manufacturer Part HL-A-3528S35FC-S1-13HL; LCSC Part Name HL-A-3528S35FC-S1-13HL
LED8: HL-A-3528S31YC-S1-13HL; Voltage - Forward(Vf) 2.4V; Manufacturer Part HL-A-3528S31YC-S1-13HL; LCSC Part Name HL-A-3528S31YC-S1-13HL
P1, P2: WJ500V-5.08-2P; CONN-TH_2P-P5.00_WJ500V-5.08-2P; Current Rating 18A; Voltage Rating (Max) 250V; Manufacturer Part WJ500V-5.08-2P; LCSC Part Name 1x2P 5.08mm 直插 排数:1 每排P数:2
Q1, Q2: AO4406A; SOP-8_L5.0-W3.8-P1.27-LS6.0-BL; Manufacturer Part AO4406A; LCSC Part Name 1个N沟道 耐压:30V 电流:12A
R1, R2, R4, R7, R11, R12, R13, R45, R46, R47, R49: 10kΩ; R0603; Tolerance ±1%; Voltage-Supply(Max) 75V; Manufacturer Part 0603WAF1002T5E; LCSC Part Name 厚膜电阻 10kΩ ±1% 100mW
R3: 33kΩ; R0603; Tolerance ±1%; Voltage-Supply(Max) 75V; Manufacturer Part 0603WAF3302T5E; LCSC Part Name 33kΩ ±1% 100mW 厚膜电阻
R5, R8: 4.7kΩ; R0603; Tolerance ±1%; Voltage-Supply(Max) 75V; Manufacturer Part 0603WAF4701T5E; LCSC Part Name 4.7kΩ ±1% 100mW 厚膜电阻
R6, R28, R29, R30, R31: 1kΩ; R0603; Tolerance ±1%; Voltage-Supply(Max) 75V; Manufacturer Part 0603WAF1001T5E; LCSC Part Name 1kΩ ±1% 100mW 厚膜电阻
R9, R32, R33, R34, R35, R36, R37: 33Ω; R0603; Tolerance ±1%; Voltage-Supply(Max) 75V; Manufacturer Part 0603WAF330JT5E; LCSC Part Name 33Ω ±1% 100mW 厚膜电阻
R10, R14, R15, R24: 60.4Ω; ERJP06F60R4V; Tolerance ±1%; Voltage-Supply(Max) 75V; Manufacturer Part ERJP06F60R4V; LCSC Part Name ERJP06F60R4V
R41, R42, R43: 100kΩ; R0603; Tolerance ±1%; Voltage-Supply(Max) 75V; Manufacturer Part 0603WAF1003T5E; LCSC Part Name 100kΩ ±1% 100mW 厚膜电阻
R60, R61: 10kΩ; R0603; Manufacturer Part 0603WAF1002T5E; JLCPCB Part Class Basic Part
SW1, SW2, SW3, SW4, SW6, SW7: HX TS4538CJ 250gf 009; SW-TH_4P-L4.5-W4.5-P3.00-LS5.0; Manufacturer Part HX TS4538CJ 250gf 009; JLCPCB Part Class Extended Part
U1: STM32H755ZIT6; LQFP-144_L20.0-W20.0-P0.50-LS22.0-BL; Manufacturer Part STM32H755ZIT6; JLCPCB Part Class Extended Part
U2: W25Q256JVEIQ; WSON-8_L8.0-W6.0-P1.27-TL-EP; Manufacturer Part W25Q256JVEIQ; JLCPCB Part Class Extended Part
U3: TPS563201DDCR; SOT-23-6_L2.9-W1.6-P0.95-LS2.8-BR; Manufacturer Part TPS563201DDCR; JLCPCB Part Class Extended Part
U4: CH224K; ESSOP-10_L4.9-W3.9-P1.0-LS6.0-TL-EP; Output Voltage 5V；20V；15V；12V；9V; Voltage - Supply 4V~30V; Manufacturer Part CH224K; LCSC Part Name USBPD等多快充协议受电芯片CH224
U5, U6: LM74700QDBVRQ1; SOT-23-6_L2.9-W1.6-P0.95-LS2.8-BL; Manufacturer Part LM74700QDBVRQ1; LCSC Part Name 低IQ电池反向保护理想二极管控制器
U7: FM24CL64B-GTR; SOIC-8_L4.9-W3.9-P1.27-LS6.0-BL; Voltage - Supply 2.7V~3.65V; Manufacturer Part FM24CL64B-GTR; LCSC Part Name FM24CL64B-GTR
U8, U9: TJA1051T/3/1J; SOIC-8_L4.9-W3.9-P1.27-LS6.0-BL; Supply Voltage 4.5V~5.5V; Manufacturer Part TJA1051T/3/1J; LCSC Part Name TJA1051T/3/1J
U11, U12: AW9523BTQR; Manufacturer Part AW9523BTQR; LCSC Part Name AW9523BTQR
USBC1: TYPE-C-31-M-12; USB-C_SMD-TYPE-C-31-M-12_1; Current Rating-Power 5A; Voltage Rating 20V; Manufacturer Part TYPE-C-31-M-12; LCSC Part Name Type-C 母 卧贴
X1: 25MHz; CRYSTAL-SMD_4P-L3.2-W2.5-BL; Manufacturer Part X322525MOB4SI; JLCPCB Part Class Basic Part

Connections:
/+3V3: C6.1, C7.1, C8.1, C9.1, C10.1, C11.1, C15.1, C17.1, C18.1, C19.1, C20.1, C21.1, C22.1, C23.1, C24.1, C32.1, C33.1, C34.1, C35.1, C36.1, C38.1, C39.1, C43.1, C44.1, C45.1, C47.1, C48.1, C49.1, C55.1, C56.1, C66.1, C67.1, C68.1, C72.1, C73.1, FPC1.1, FPC2.1, FPC3.1, H2.1 (VCC), L1.1, L2.2, R3.1, R5.2, R8.2, R11.2, R12.2, R13.2, R45.2, R46.2, R47.2, R49.1, SW7.4 (D), U1.7 (VDD), U1.8 (VBAT), U1.13 (VDD), U1.16 (VDDSMPS), U1.19 (VDD), U1.32 (VDD), U1.42 (VDD), U1.56 (VDD), U1.70 (VDDLDO), U1.71 (VDD), U1.79 (VDD), U1.90 (VDD50USB), U1.91 (VDD33USB), U1.92 (VDD), U1.105 (VDDLDO), U1.106 (VDD), U1.119 (VDD), U1.129 (VDD), U1.142 (PDR_ON), U1.143 (VDDLDO), U1.144 (VDD), U2.8 (VCC), U7.8 (VDD), U8.5 (VIO), U9.5 (VIO)
/+5V: C25.1, C26.1, C27.1, C28.1, C29.1, C30.1, C31.1, C51.1, C59.1, C60.1, C61.1, C62.1, C63.1, C64.1, C65.1, D10.1 (K), D11.1 (K), FPC1.17, FPC1.18, FPC2.17, FPC2.18, FPC3.17, FPC3.18, LED1.2 (A), LED2.2 (A), LED3.2 (A), LED4.2 (+), LED5.2 (A), LED6.2 (A), LED7.2 (A), LED8.2 (+), Q1.5 (D), Q1.6 (D), Q1.7 (D), Q1.8 (D), Q2.5 (D), Q2.6 (D), Q2.7 (D), Q2.8 (D), R60.1, R61.1, U3.3 (VIN), U3.5 (EN), U5.4 (CATHODE), U6.4 (CATHODE), U8.3 (VCC), U9.3 (VCC), U11.18 (AD0), U11.21 (VCC), U11.24 (AD1), U12.21 (VCC), U12.24 (AD1)
/+5V_BARREL: C54.2, F1.2, Q2.1 (S), Q2.2 (S), Q2.3 (S), U6.3 (EN), U6.6 (ANODE)
/BOOT0: R1.1, SW7.1 (A), U1.135 (BOOT0)
/BTN1: R28.2, U1.93 (PC6)
/BTN1_SW: R28.1, SW1.1
/BTN2: R29.2, U1.94 (PC7)
/BTN2_SW: R29.1, SW2.1
/BTN3: R30.2, U1.95 (PC8)
/BTN3_SW: R30.1, SW3.1
/BTN4: R31.2, U1.96 (PC9)
/BTN4_SW: R31.1, SW4.1
/BUCK_FB: R2.1, R3.2, U3.4 (VFB)
/BUCK_SW: C52.2, L2.1, U3.2 (SW)
/BUCK_VBST: C52.1, U3.6 (VBST)
/CAN1_CT: R10.2, R14.1
/CAN1_H: H1.1, P1.2, U8.7 (CANH)
/CAN1_L: P1.1, R14.2, U8.6 (CANL)
/CAN1_RX: U1.136 (PB8), U8.4 (RXD)
/CAN1_TERM: H1.2, R10.1
/CAN1_TX: U1.137 (PB9), U8.1 (TXD)
/CAN2_CT: R15.2, R24.1
/CAN2_H: H3.1, P2.2, U9.7 (CANH)
/CAN2_L: P2.1, R24.2, U9.6 (CANL)
/CAN2_RX: U1.132 (PB5), U9.4 (RXD)
/CAN2_TERM: H3.2, R15.1
/CAN2_TX: U1.133 (PB6), U9.1 (TXD)
/CH224_VDD: C50.1, R6.2, U4.1 (VDD), U4.9 (CFG1)
/CH224_VSNS: R7.2, U4.8 (VBUS)
/CS_C: FPC2.6, R45.1, U1.76 (PD8)
/CS_L: FPC1.6, R46.1, U1.77 (PD9)
/CS_R: FPC3.6, R47.1, U1.2 (PE3)
/DC1_IN: DC1.1, F1.1
/GATE_BARREL: Q2.4 (G), U6.5 (GATE)
/GATE_USB: Q1.4 (G), U5.5 (GATE)
/GND: C3.2, C4.2, C5.2, C6.2, C7.2, C8.2, C9.2, C10.2, C11.2, C15.2, C17.2, C18.2, C19.2, C20.2, C21.2, C22.2, C23.2, C24.2, C25.2, C26.2, C27.2, C28.2, C29.2, C30.2, C31.2, C32.2, C33.2, C34.2, C35.2, C36.2, C37.2, C38.2, C39.2, C40.2, C41.2, C42.2, C43.2, C44.2, C45.2, C46.2, C47.2, C48.2, C49.2, C50.2, C51.2, C55.2, C56.2, C59.2, C60.2, C61.2, C62.2, C63.2, C64.2, C65.2, C66.2, C67.2, C68.2, C70.2, C71.2, C72.2, C73.2, D9.2, DC1.3, FPC1.2, FPC1.19, FPC1.20, FPC1.21, FPC1.22, FPC2.2, FPC2.19, FPC2.20, FPC2.21, FPC2.22, FPC3.2, FPC3.19, FPC3.20, FPC3.21, FPC3.22, H2.5 (GND), R1.2, R2.2, R41.2, R42.2, R43.2, SW1.4, SW2.4, SW3.4, SW4.4, SW6.4 (D), U1.6 (VSS), U1.12 (VSS), U1.14 (VSSSMPS), U1.18 (VSS), U1.33 (VSS), U1.34 (VSSA), U1.41 (VSS), U1.55 (VSS), U1.69 (VSS), U1.80 (VSS), U1.89 (VSS), U1.104 (VSS), U1.118 (VSS), U1.128 (VSS), U1.141 (VSS), U2.4 (GND), U2.9 (EP), U3.1 (GND), U4.11 (GND), U5.2 (GND), U6.2 (GND), U7.1 (A0), U7.2 (A1), U7.3 (A2), U7.4 (VSS), U7.7 (WP), U8.2 (GND), U8.8 (S), U9.2 (GND), U9.8 (S), U11.9 (GND), U11.25 (GND), U12.9 (GND), U12.18 (AD0), U12.25 (GND), USBC1.1 (EH), USBC1.2 (EH), USBC1.3 (EH), USBC1.4 (EH), USBC1.A1B12 (GND), USBC1.B1A12 (GND), X1.2 (GND), X1.4 (GND); also elsewhere on the board
/I2C_SCL: R8.1, U1.66 (PB10), U7.6 (SCL), U11.19 (SCL), U12.19 (SCL)
/I2C_SDA: R5.1, U1.67 (PB11), U7.5 (SDA), U11.20 (SDA), U12.20 (SDA)
/MISO_C: FPC2.4, R41.1, U1.45 (PA6)
/MISO_L: FPC1.4, R42.1, U1.74 (PB14)
/MISO_R: FPC3.4, R43.1, U1.4 (PE5)
/MOSI_C: FPC2.5, R35.2
/MOSI_C_MCU: R35.1, U1.46 (PA7)
/MOSI_L: FPC1.5, R36.2
/MOSI_L_MCU: R36.1, U1.75 (PB15)
/MOSI_R: FPC3.5, R37.2
/MOSI_R_MCU: R37.1, U1.5 (PE6)
/NRST: C46.1, H2.3 (nRESET), R49.2, SW6.1 (A), U1.27 (NRST)
/OSC_IN: C41.1, U1.25 (PH0-OSC_IN), X1.1 (OSC1)
/OSC_OUT: C42.1, U1.26 (PH1-OSC_OUT), X1.3 (OSC2)
/PD_C: FPC2.8, R11.1, U1.81 (PD11)
/PD_L: FPC1.8, R12.1, U1.82 (PD12)
/PD_R: FPC3.8, R13.1, U1.83 (PD13)
/QSPI_CLK: R9.2, U2.6 (CLK)
/QSPI_CLK_MCU: R9.1, U1.51 (PB2)
/QSPI_IO0: U1.22 (PF8), U2.5 (DI(IO0))
/QSPI_IO1: U1.23 (PF9), U2.2 (DO(IO1))
/QSPI_IO2: U1.21 (PF7), U2.3 (/WP(IO2))
/QSPI_IO3: U1.20 (PF6), U2.7 (/HOLD_or_/RESET(IO3))
/QSPI_NCS: U1.86 (PG6), U2.1 (/CS)
/SCLK_C: FPC2.3, R32.2
/SCLK_C_MCU: R32.1, U1.44 (PA5)
/SCLK_L: FPC1.3, R33.2
/SCLK_L_MCU: R33.1, U1.73 (PB13)
/SCLK_R: FPC3.3, R34.2
/SCLK_R_MCU: R34.1, U1.1 (PE2)
/SWCLK: H2.4 (SWCLK), U1.107 (PA14)
/SWDIO: H2.2 (SWDIO), U1.102 (PA13)
/SWO: H2.6 (SWO), U1.130 (PB3)
/TT1_LED_K: LED1.1 (C), U11.14 (P1_4)
/TT2_LED_K: LED3.1 (C), U11.15 (P1_5)
/TT3_LED_K: LED4.1 (-), U12.15 (P1_5)
/TT4_LED_K: LED2.1 (C), U12.14 (P1_4)
/TT5_LED_K: LED5.1 (K), U11.16 (P1_6)
/TT6_LED_K: LED6.1 (K), U12.16 (P1_6)
/TT7_LED_K: LED7.1 (K), U11.17 (P1_7)
/TT8_LED_K: LED8.1 (-), U12.17 (P1_7)
/U11_RSTN: C70.1, D10.2 (A), R60.2, U11.23 (RSTN)
/U12_RSTN: C71.1, D11.2 (A), R61.2, U12.23 (RSTN)
/USB_CC1: U4.7 (CC1), USBC1.A5 (CC1)
/USB_CC2: U4.6 (CC2), USBC1.B5 (CC2)
/USB_DM: D9.4, U1.100 (PA11)
/USB_DM_CONN: D9.3, USBC1.A7 (DN1), USBC1.B7 (DN2)
/USB_DP: D9.6, U1.101 (PA12)
/USB_DP_CONN: D9.1, USBC1.A6 (DP1), USBC1.B6 (DP2)
/VBUS: C53.2, D9.5, Q1.1 (S), Q1.2 (S), Q1.3 (S), R4.1, R6.1, R7.1, U5.3 (EN), U5.6 (ANODE), USBC1.A4B9 (VBUS), USBC1.B4A9 (VBUS)
/VBUS_SENSE: R4.2, U1.98 (PA9)
/VCAP1: C3.1, U1.68 (VCAP)
/VCAP2: C4.1, U1.103 (VCAP)
/VCAP3: C5.1, U1.140 (VCAP)
/VCAP_BARREL: C54.1, U6.1 (VCAP)
/VCAP_USB: C53.1, U5.1 (VCAP)
/VDDA: C37.1, C40.1, L1.2, U1.35 (VREF+), U1.36 (VDDA)

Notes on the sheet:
J1/DC1: +5V IN via F1 PPTC (2A hold / 4A trip). Supply rating UNCONFIRMED -- the old "5V/15A" note was stale; confirm before relying on it.
CN2: LEFT panel (RVT50H 800x480) - RiBus 20P FPC
CN3: RIGHT panel (RVT50H 800x480) - RiBus 20P FPC
CN1: CENTER panel (RVT70H 1024x600) - RiBus 20P FPC
J3/J4: CAN termination jumpers - leave OPEN by default (vehicle bus is already terminated). Close only for bench-only bus tests.

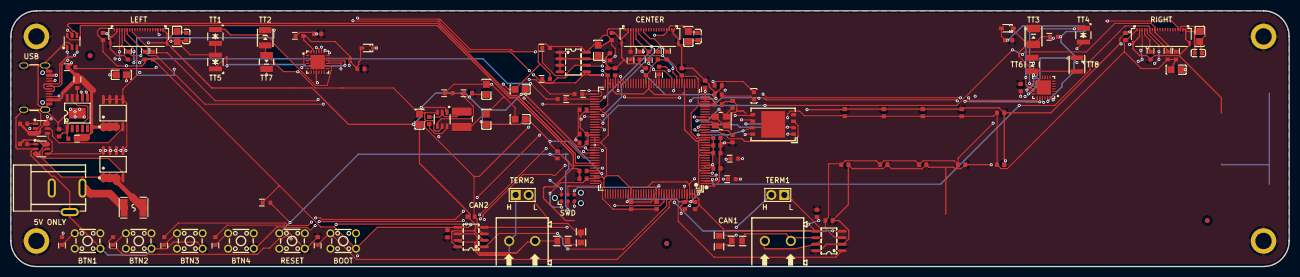
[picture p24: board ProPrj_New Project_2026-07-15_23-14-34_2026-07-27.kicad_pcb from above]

Board: 4 copper layers, 250.0 x 50.0 mm, 150 parts (0 on the bottom side), 93 nets.

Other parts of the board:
FID1, FID2, FID3: Fiducial_1mm_Mask2mm
MP1: Pad_e672
MP2: Pad_e675
MP3: Pad_e673
MP4: Pad_e674

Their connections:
/GND: MP1.1, MP2.1, MP3.1, MP4.1; also elsewhere on the board

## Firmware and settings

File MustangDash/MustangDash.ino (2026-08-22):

/*
 * MustangDash - Riverdi triple-panel EVE4 dash on STM32
 *
 * Displays: center SM-RVT70HSBNWN00 (7.0" 1024x600) + left/right
 *           SM-RVT50HQBNWN00 (5.0" 800x480), all BT817 / EVE4, no touch
 * MCU     : STM32 (NUCLEO-F767ZI mule; H755 carrier)
 * Bus     : hardware SPI0 shared by all three (SCLK=13, MISO=12, MOSI=11)
 * Control : per-panel CS/PD from dash_panels.h -- center 14/17, left 15/20,
 *           right 16/21 (INT not connected -> polling only)
 *
 * Library : RudolphRiedel/FT800-FT813 (EmbeddedVideoEngine, v5.x) with the
 *           vendored multi-panel patch (EVE_select_panel); center profile
 *           EVE_RVT70H compiled, side timings carried at runtime
 *
 * What it does:
 *   1. waits for the serial monitor only when a USB host is present
 *      (usb_configuration != 0); a car boot spends at most the bounded
 *      500 ms enumeration window before display init, not the 2 s wait
 *   2. brings the EVE chip out of power-down, runs EVE_init(), reads REG_ID
 *      (a healthy BT817 returns 0x7C) and reports both on Serial
 *   3. inflates the dash fonts into RAM_G (dash_fonts.h) -- all with the
 *      backlight held dark; the panel's QSPI flash is never touched
 *      (2026-07-21 MCU-direct rewrite)
 *   4. plays the 2000 ms animated splash (assets/splash/README.md spec,
 *      timing in splash_timeline.h; theme picked in splash_config.h),
 *      staging the theme's ASTC bitmaps from the firmware-embedded pack
 *      (splash_flash.h) MCU flash -> RAM_G with per-asset readback
 *      spot-checks, rendering from RAM_G (see splash_render.h for why),
 *      lighting the backlight only after the first frame is on screen
 *   5. crossfades ~400 ms into the dash -- TRACK or STREET view fed by the
 *      built-in simulator (dash_sim.h) with serial overrides (dash_serial.h),
 *      alarm takeover on critical conditions, EEPROM-persisted odometer --
 *      the standing display, redrawn continuously from loop()
 *
 * Serial is 115200 8N1. Boot prints a diagnostic banner; after boot the
 * firmware emits nothing except one `ok ...` / `err ...` ack per received
 * command line (see dash_serial.h for the protocol; /dash skill wraps it).
 * One documented exception: `flashwipe really` prints a pre-erase warning
 * line before its ack, because the erase then blocks silently for minutes.
 *
 * Rendering lives in sibling single-TU headers: dash_draw.h (shared
 * primitives), dash_render.h (center TRACK/STREET/alarm), engine_render.h
 * (left 5" ENGINE screen), timing_render.h (right 5" TIMING/ROAD screen),
 * and splash_render.h (RAM_G staging + splash + crossfade).
 * This file keeps setup/loop and the glue: panel selection, EVE frame
 * plumbing, cluster brightness, fonts, serial pump, odometer EEPROM, and
 * the shared state every header reads.
 *
 * Note: every function below is declared before it is used. PlatformIO does
 * its own .ino prototype generation, so this is belt-and-braces now, but it
 * costs nothing and keeps the file readable top-to-bottom.
 */

#include <Arduino.h>
#include <SPI.h>
#include "EVE.h"
#include "splash_config.h"
#include "splash_timeline.h"
#include "splash_flash.h" /* after EVE.h so its guarded EVE_ASTC_* defer to the library */
#include "dash_data.h"
#include "dash_math.h"
#include "dash_layout.h"
#include "dash_sim.h"
#include "dash_serial.h"
#include "dash_odo.h"
#include "dash_button.h" /* trip/mode button gesture state machine (host-tested); pin + polarity live below */
#include "dash_fonts.h"
#include "dash_panels.h" /* per-panel pins + timings (host-tested); mapped to EVE_panel_t in setup() */
#include "dash_telltales.h" /* 8-lamp warning mask (host-tested); pins + lamp test live below */
#include "dash_ttsweep.h" /* boot/bench telltale sweep timeline (host-tested); clock + trigger live below */
#include "dash_turnsignal.h" /* turn-signal stalk state + flasher (host-tested); pins + clock live below */
#include "dash_calibration.h" /* per-position telltale dim codes (host-tested, plan 2026-07-28-001 U21) */
#include "dash_can_ford.h" /* Ford 0x270-set decoder (pure, host-tested; plan 2026-08-15-001) -- needs dash_data.h above */
#include "dash_can.h" /* FDCAN bring-up (U7) + the Ford-frame RX drain (plan 2026-08-15-001 U6); stubs where absent */

/* telltale sweep clock: pending=true plays the show on the first live lamp
 * frame after boot (setup()'s ALL-on bulb check holds through the splash,
 * then the chase runs as the dash fades in); the serial `tt sweep` command
 * restarts it any time. The timeline itself is dash_ttsweep.h. */
static bool g_ttsweep_pending = true;
static uint32_t g_ttsweep_start = 0U;

#include <Wire.h> /* FM24CL64B I2C FRAM odometer backend (migration plan U6) */

/* Volatile so the compiler cannot fold the table access down to the one
 * compiled theme -- all three theme rows must stay live (plan requirement
 * R5; the flash pack always carries all three asset sets anyway). */
static volatile uint8_t g_theme = SPLASH_THEME;

/* ---- dash state ---- */

/* Fonts occupy RAM_G from address 0 (~285 KB decoded; dash_fonts.h footer
 * has the exact figure). The splash stages the active theme's assets just
 * above them at boot (~281 KB, center panel only; splash_render.h has the
 * rationale) -- together ~566 KB of the 1 MB. */
struct DashFontLoaded
{
    uint32_t metrics_addr; /* 148-byte block, passed to CMD_SETFONT2 (same layout on every panel's RAM_G) */
    uint8_t ok_mask;       /* bit per panel; a clear bit -> ROM font 31 fallback on that panel only */
};

static DashFontLoaded g_fonts[DASH_FONT_COUNT];
static uint32_t g_ramg_fonts_end = 0UL; /* first free RAM_G byte above the fonts (splash staging base) */
static DashState g_dash;
static DashSimState g_sim;
static DashOdo g_odo;
/* Lap-crossing delta override for the TRACK LAP TIME readout. The state
 * machine is pure (dash_math.h) and host-tested; all that lives here is the
 * once-per-frame tick that feeds it the published channels plus the
 * simulator's sticky per-lap taint. */
static DashLapFlash g_lap_flash;
/* Ford CAN dialect freshness state (plan 2026-08-15-001 U6). Channel values
 * and ownership live in g_dash (can_owned); this holds only per-message
 * last-seen bookkeeping. Static zero-init IS its boot contract ({0}, like
 * dash_state_init). */
static DashCanFord g_can_ford;

/* void* shims adapting the pure Ford decoder to dash_can.h's dialect table.
 * The seam keeps dash_can.h dialect-blind; a second dialect (RaceCapture)
 * registers the same way -- its own state struct, its own pair of shims. */
static bool can_ford_decode_shim(void *state, uint32_t id, uint8_t dlc,
                                 const uint8_t *bytes, uint32_t now_ms,
                                 DashState *s)
{
    return dash_can_ford_decode((DashCanFord *) state, id, dlc, bytes, now_ms, s);
}
static void can_ford_expire_shim(void *state, uint32_t now_ms,
                                 bool car_semantics, DashState *s)
{
    dash_can_ford_expire((DashCanFord *) state, now_ms, car_semantics, s);
}

/* ---- panel plumbing (three BT817s on one shared SPI bus, KTD1/KTD9) ---- */
static EVE_panel_t g_eve_panels[DASH_PANEL_COUNT]; /* library form of DASH_PANELS, filled in setup() */

#if defined(EVE_PANEL_HAS_BUS)
#if defined(DASH_BOARD_NUCLEO_F767)
/* NUCLEO-F767ZI three-panel mule: three genuinely dedicated SPI peripherals
 * on pins clear of the board's fixed functions -- Ethernet RMII steals
 * SPI1's default MOSI (PA7) and SPI2's default SCK (PB13), hence the
 * alternates. Panels attach via FFC breakouts; backlights on external 5V.
 * Constructor order: MOSI, MISO, SCLK. */
static SPIClass g_spi_center(PB5, PA6, PA5);  /* SPI1: MOSI on PB5 (PA7 is RMII) */
static SPIClass g_spi_left(PB15, PC2, PB10);  /* SPI2: SCK on PB10, MISO on PC2 (PB13/PB14 taken) */
static SPIClass g_spi_right(PE6, PE5, PE2);   /* SPI4 */
static SPIClass *const DASH_SPI_BUSES[DASH_PANEL_COUNT] = { &g_spi_center, &g_spi_left, &g_spi_right };
static const uint8_t DASH_CS_PINS[DASH_PANEL_COUNT] = { PF13, PE9, PE11 };
static const uint8_t DASH_PD_PINS[DASH_PANEL_COUNT] = { PF14, PE13, PF15 };
#elif defined(DASH_BOARD_RIVERDI_F469)
/* Riverdi STM32 Evaluation Board (STM32F469II): ONE RiBUS connector on SPI2
 * -- center panel only; the sides are physically absent and retire at boot
 * (R9), so all three descriptors share the one bus and the side CS/PD pins
 * are harmless spares. Pin map from riverdi-eve host_layer/stm32f4:
 * CS PB12, PD PH6, INT PH7 (unused -- we poll). */
static SPIClass g_spi_center(PB15, PB14, PB13); /* SPI2: MOSI, MISO, SCLK */
static SPIClass *const DASH_SPI_BUSES[DASH_PANEL_COUNT] = { &g_spi_center, &g_spi_center, &g_spi_center };
static const uint8_t DASH_CS_PINS[DASH_PANEL_COUNT] = { PB12, PC6, PC7 }; /* sides: spare GPIOs */
static const uint8_t DASH_PD_PINS[DASH_PANEL_COUNT] = { PH6, PC8, PC9 };
#else
/* STM32 carrier (migration plan U5): one dedicated SPI peripheral per panel,
 * indexed by DashPanelDesc.bus_index. Pin sets are compile-valid LQFP-100
 * defaults for the WeAct H743 mule; the carrier schematic (plan U2) owns the
 * final assignment. Constructor order: MOSI, MISO, SCLK. */
static SPIClass g_spi_center(PA7, PA6, PA5); /* SPI1 -- review fix: the variant's
    default `SPI` object IS SPI2 on PB13/14/15, i.e. the same bus as the left
    panel; an explicit SPI1 instance keeps all three buses genuinely disjoint */
static SPIClass g_spi_left(PB15, PB14, PB13); /* SPI2 */
static SPIClass g_spi_right(PE6, PE5, PE2);   /* SPI4 */
static SPIClass *const DASH_SPI_BUSES[DASH_PANEL_COUNT] = { &g_spi_center, &g_spi_left, &g_spi_right };

/* Review fix: dash_panels.h's CS/PD values are canonical digital numbers; on the
 * STM32 variant those same numbers land on USB DP, the telltale port, and the
 * uSD pins. The descriptor table stays host-pure (canonical data); the
 * STM32 build remaps the roles here, clear of USB (PA11/12), lamps (PD0-7),
 * FDCAN (PB5/6/8/9), I2C2 (PB10/11), K1 (PC13), and the SPI pins above.
 * The carrier schematic now owns the assignment (docs/hardware/
 * board3-h755-pin-map.md): right CS moved PD10 -> PE3 at layout (U18,
 * 2026-07-28) so the net escapes the east edge beside its own SPI bus
 * instead of crossing the whole package. Lamps left the MCU entirely in
 * the I2C revision (plan 2026-07-28-001): PD0-PD7 are freed, the
 * telltales ride two AW9523B expanders on I2C2. */
static const uint8_t DASH_CS_PINS[DASH_PANEL_COUNT] = { PD8, PD9, PE3 };
static const uint8_t DASH_PD_PINS[DASH_PANEL_COUNT] = { PD11, PD12, PD13 };
#endif
#endif
static bool g_panel_ok[DASH_PANEL_COUNT];          /* init succeeded; a dead panel stays dark, never blocks the others (R9) */
static uint8_t g_active_panel = DASH_PANEL_CENTER; /* which panel the EVE library is currently routed at */
static uint8_t g_dash_brightness = 0U;             /* ONE cluster brightness (R12); set to BL_STEADY at boot_complete */
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
void loop(void)
{
    /* The live pipeline (KTD8): serial -> CAN decode -> sim -> odometer ->
     * alarm -> frame. Runs even when every panel is dead so the bench control
     * surface survives -- only the render step is gated. */
    pump_serial();

    const uint32_t now = millis();
    const uint32_t dt = now - g_loop_last_ms;
    g_loop_last_ms = now;

    /* CAN decode before the sim step (plan 2026-08-15-001 KTD5): accepted
     * frames claim channels via can_owned, so the sim yields to CAN-fresh
     * data on this same frame; the expiry pass then applies the bench/car
     * staleness semantics (KTD6) before the sim gets its turn. `now` is
     * fresh from just after pump_serial, so frame timestamps and dt share
     * one clock reading. */
    dash_can_rx_drain(now, &g_dash);
    dash_can_expire_all(now, DASH_CAN_CAR_SEMANTICS, &g_dash);

    dash_sim_step(&g_sim, &g_dash, dt); /* honors sim_frozen + overrides */

    /* Straight after the sim step, so a lap that closed on THIS step is seen
     * on the frame that renders it. g_sim.last_lap_tainted is the taint of the
     * lap now sitting in LAST -- lap_tainted itself has already been cleared
     * for the new lap by the time we get here, which is the whole reason the
     * sticky copy exists. */
    dash_lap_flash_update(&g_lap_flash, &g_dash, now, g_sim.last_lap_tainted);

    if (dash_ch_valid(&g_dash, DASH_CH_SPEED))
    {
        dash_odo_advance(&g_odo, g_dash.ch.speed_mph, dt);
    }
    if (dash_odo_should_write(&g_odo))
    {
        odo_eeprom_write();
        dash_odo_mark_written(&g_odo);
    }

#if defined(DASH_TURN_BUTTONS)
    /* Turn-signal stalk (BTN2/BTN4). Same debounce contract as the trip
     * button -- a press toggles its side, the other side cancels. The
     * flasher's lit positions are written into tt_signals, the same field a
     * CAN body-signal producer will own: this clears only the two blinker
     * bits, so it never disturbs another signal. */
    {
        const bool l_down = (DASH_SWITCH_TRIP_PRESSED == digitalRead(DASH_TURN_L_PIN));
        const bool r_down = (DASH_SWITCH_TRIP_PRESSED == digitalRead(DASH_TURN_R_PIN));
        if (DASH_BTN_EVENT_SHORT == dash_button_step(&g_turn_l_btn, l_down, now))
        {
            dash_turn_press(&g_turn, DASH_TURN_LEFT, now);
        }
        if (DASH_BTN_EVENT_SHORT == dash_button_step(&g_turn_r_btn, r_down, now))
        {
            dash_turn_press(&g_turn, DASH_TURN_RIGHT, now);
        }
        g_dash.tt_signals = (uint8_t) ((g_dash.tt_signals & ~DASH_TURN_LAMP_BITS)
                                       | dash_turn_mask(&g_turn, now));
    }
#endif

    /* telltales track the live state every frame (U6); the mask is pure
     * logic (dash_telltales.h), only the pin writes live here */
    {
        uint8_t lamp_mask = dash_telltale_mask(&g_dash);
        /* sweep overlay: OR, never mask (same rule as tt_forced) -- an
         * alarm lamp cannot blink off mid-show. Armed at boot; re-armed by
         * the serial `tt sweep` command. */
        if (g_ttsweep_pending)
        {
            g_ttsweep_pending = false;
            g_ttsweep_start = now;
        }
        if (!dash_ttsweep_done(now - g_ttsweep_start))
        {
            lamp_mask |= dash_ttsweep_mask(now - g_ttsweep_start);
        }
        uint8_t first_live = 0U;
#if defined(DASH_BOARD_NUCLEO_F767)
        /* TEMPORARY bench boot show (2026-07-21): the three onboard LEDs
         * hold all-on (continuing setup()'s lamp test through the splash),
         * then roll one-at-a-time green->blue->red every 750 ms until 10 s
         * after boot, then join live telltale duty. Remove together with
         * the onboard-LED pin mapping when real telltale hardware lands. */
        if (now < 10000UL)
        {
            first_live = 3U;
            if (now < 2500UL)
            {
                for (uint8_t l = 0U; l < 3U; l++)
                {
                    digitalWrite(DASH_LAMP_PINS[l], HIGH);
                }
            }
            else
            {
                const uint8_t step = (uint8_t)(((now - 2500UL) / 750UL) % 3U);
                for (uint8_t l = 0U; l < 3U; l++)
                {
                    digitalWrite(DASH_LAMP_PINS[l], (l == step) ? HIGH : LOW);
                }
            }
        }
#endif
        for (uint8_t l = first_live; l < DASH_TT_COUNT; l++)
        {
            dash_lamp_set(l, 0U != ((lamp_mask >> l) & 1U));
        }
    }

    /* Trip/mode button (U11). One button, two gestures -- short press (< 1 s,
     * on release) swaps TRACK/STREET, long press (held >= 1 s) resets the
     * trip. The debounce that a review finding put here is intact and now
     * lives in dash_button.h: nothing fires until the raw level has been
     * stable for > 30 ms, so a single EMI glitch on a car harness cannot
     * zero the trip, and exactly one event fires per press. The polarity
     * comparison stays here, where the board-specific macros are; the state
     * machine only ever sees a normalized bool. */
    {
        const bool down = (DASH_SWITCH_TRIP_PRESSED == digitalRead(DASH_SWITCH_TRIP_PIN));
        switch (dash_button_step(&g_trip_btn, down, now))
        {
            case DASH_BTN_EVENT_SHORT:
                /* Same single assignment the serial `mode track|street`
                 * command makes (dash_serial.h DASH_CMD_MODE) -- mode is a
                 * plain DashState field, nothing else keys off the change. */
                g_dash.mode = (DASH_MODE_TRACK == g_dash.mode) ? DASH_MODE_STREET
                                                               : DASH_MODE_TRACK;
                break;
            case DASH_BTN_EVENT_LONG:
                dash_odo_trip_reset(&g_odo);
                odo_eeprom_write();
                dash_odo_mark_written(&g_odo);
                break;
            case DASH_BTN_EVENT_NONE:
            default:
                break;
        }
    }

    /* Sequential per-panel render (KTD8): center first (mode or alarm
     * takeover), then both sides (mode content only -- R4). Dead panels are
     * skipped inside the helpers (R9). */
    const bool any_ok = g_panel_ok[DASH_PANEL_CENTER] || g_panel_ok[DASH_PANEL_LEFT]
                     || g_panel_ok[DASH_PANEL_RIGHT];
    if (any_ok)
    {
        if (dash_select_panel(DASH_PANEL_CENTER))
        {
            dash_frame(now);
        }
        dash_sides_frame(255U, nullptr, 0U, COLOR_BG);
        g_fps_frames++;
    }

    /* fps accounting for the status ack: frames completed per full second.
     * The window keeps rolling even with every panel retired so fps decays
     * to 0 instead of freezing at the last healthy second -- a frozen 60
     * masked a retired cluster on the bench (review-of-review finding). */
    if ((now - g_fps_window_ms) >= 1000UL)
    {
        g_fps = g_fps_frames;
        g_fps_frames = 0U;
        g_fps_window_ms = now;
    }
}

/* Write the backlight PWM duty (0..128 is the full range on EVE). */
void set_backlight(uint8_t duty)
{
    EVE_memWrite8(REG_PWM_DUTY, duty);
}

/* Open a new display list: clear color/stencil/tag to the given background. */
void eve_frame_begin(uint32_t clear_rgb)
{
    EVE_cmd_dl(CMD_DLSTART);
    EVE_cmd_dl(DL_CLEAR_COLOR_RGB | clear_rgb);
    EVE_cmd_dl(DL_CLEAR | CLR_COL | CLR_STN | CLR_TAG);
}

/* Close the display list, swap it in, and wait for the co-processor.
 * EVE_busy() detects and auto-recovers coprocessor faults but the recovery
 * is silent inside EVE_execute_cmd(); spinning here instead lets us count
 * recoveries so `status` can surface faults=N (review finding).
 *
 * The wait is BOUNDED (review finding, R9): a panel that dies after boot
 * (FFC loose at speed, wedged chip) never reads REG_CMDB_SPACE == 0xffc
 * again, and an unbounded spin here would freeze all three panels plus
 * the serial pump and odometer writes. A healthy frame drains in < 17 ms;
 * on timeout the panel is retired (g_panel_ok false -> dark, skipped by
 * dash_select_panel) and `status` shows it as eve=-- for diagnosis. */
static const uint32_t EVE_FRAME_DRAIN_TIMEOUT_MS = 250UL;
void eve_frame_end(void)
{
    EVE_cmd_dl(DL_DISPLAY);
    EVE_cmd_dl(CMD_SWAP);
    const uint32_t t0 = millis();
    for (;;)
    {
        const uint8_t st = EVE_busy();
        if (E_OK == st)
        {
            break;
        }
        if (EVE_FAULT_RECOVERED == st)
        {
            g_eve_faults[g_active_panel]++;
        }
        if ((millis() - t0) > EVE_FRAME_DRAIN_TIMEOUT_MS)
        {
            g_panel_ok[g_active_panel] = false;
            g_eve_retired[g_active_panel]++;
            break;
        }
    }
}
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

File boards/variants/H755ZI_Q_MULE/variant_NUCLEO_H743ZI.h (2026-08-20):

/*
 *******************************************************************************
 * Copyright (c) 2021, STMicroelectronics
 * All rights reserved.
 *
 * This software component is licensed by ST under BSD 3-Clause license,
 * the "License"; You may not use this file except in compliance with the
 * License. You may obtain a copy of the License at:
 *                        opensource.org/licenses/BSD-3-Clause
 *
 *******************************************************************************
 */
#pragma once

/*----------------------------------------------------------------------------
 *        STM32 pins number
 *----------------------------------------------------------------------------*/
#ifdef ARDUINO_NUCLEO_H743ZI2
  #define PB7                     0  // USART_A_RX
  #define PB6                     1  // USART_A_TX
  #define PG14                    2
  #define PE13                    3  // TIMER_A_PWM3
  #define PE14                    4
  #define PE11                    5  // TIMER_A_PWM2
  #define PE9                     6  // TIMER_A_PWM1
  #define PG12                    7
  #define PF3                     PIN_A19
  #define PD15                    9  // TIMER_B_PWM2
  #define PD14                    10 // SPI_A_CS/ TIM_B_PWM3
  #define PB5                     11 // SPI_A_MOSI/ PA7 if SB33 ON and SB35 OFF
  #define PA6                     PIN_A20 // SPI_A_MISO
  #define PA5                     PIN_A21 // SPI_A_SCK
  #define PB9                     14 // I2C_A_SDA
  #define PB8                     15 // I2C_A_SCL
  #define PC6                     16 // I2S_A_MCK
  #define PB15                    17 // I2S_A_SD
  #define PB13                    18 // I2S_A_CK / RMII TXD1 - JP6 ON (default)
  #define PB12                    19 // I2S_A_WS
  #define PA15                    20 // I2S_B_WS
  #define PC7                     21 // I2S_B_MCK
  // 22 is PB5                   (11)
  #define PB3                     23 // I2S_B_CK/SPI_B_SCK - SWO
  #define PA4                     PIN_A22 // SPI_B_NSS
  #define PB4                     25 // SPI_B_MISO
  #define PG6                     26 // QSPI_CS
  #define PB2                     27 // QSPI_CLK
  #define PD13                    28 // QSPI_BK1_IO3
  #define PD12                    29 // QSPI_BK1_IO1
  #define PD11                    30 // QSPI_BK1_IO0
  #define PE2                     31 // SAI_A_MCLK/QSPI_BK1_IO2
  #define PA0                     PIN_A23 // TIMER_C_PWM1
  #define PB0                     PIN_A24 // TIMER_D_PWM1 - LD1 LED_GREEN
  #define PE0                     34 // TIMER_B_ETR
  #define PB11                    35 // TIMER_C_PWM3
  #define PB10                    36 // TIMER_C_PWM2
  #define PE15                    37 // TIMER_A_BKIN1
  #define PE6                     38
  #define PE12                    39 // TIMER_A_PWM3N
  #define PE10                    40 // TIMER_A_PWM2N
  #define PE7                     41 // TIMER_A_ETR
  #define PE8                     42 // TIMER_A_PWM1N
  #define PC8                     43 // SDMMC1_D0
  #define PC9                     44 // SDMMC1_D1/I2S_A_CKIN
  #define PC10                    45 // SDMMC1_D2
  #define PC11                    46 // SDMMC1_D3
  #define PC12                    47 // SDMMC1_CK
  #define PD2                     48 // SDMMC1_CMD
  #define PG2                     49
  #define PG3                     50
  #define PD7                     51 // USART_B_SCLK
  #define PD6                     52 // USART_B_RX
  #define PD5                     53 // USART_B_TX
  #define PD4                     54 // USART_B_RTS
  #define PD3                     55 // USART_B_CTS
  // 56 is PE2                   (31)
  #define PE4                     57 // SAI_A_FS
  #define PE5                     58 // SAI_A_SCK
  // 59 is PE6                   (38)
  #define PE3                     60 // SAI_B_SD
  #define PF8                     PIN_A25 // SAI_B_SCK
  #define PF7                     PIN_A26 // SAI_B_MCLK
  #define PF9                     PIN_A27 // SAI_B_FS
  #define PG1                     64
  #define PG0                     65
  #define PD1                     66 // CAN_TX
  #define PD0                     67 // CAN_RX
  #define PF0                     68 // I2C_B_SDA
  #define PF1                     69 // I2C_B_SCL
  #define PF2                     70 // I2C_B_SMBA
  // 71 is PE9                   (6)
  // 72 is PB2                   (27)
  #define PA3                     PIN_A0
  #define PC0                     PIN_A1
  #define PC3_C                   PIN_A2
  #define PB1                     PIN_A3
  #define PC2_C                   PIN_A4
  #define PF10                    PIN_A5
  #define PF4                     PIN_A6
  #define PF5                     PIN_A7
  #define PF6                     PIN_A8
  #define PF11                    PIN_A9
  #define PA1                     PIN_A10 // RMII Reference Clock - SB57 ON (default)
  #define PA2                     PIN_A11 // RMII MDIO - SB72 ON (default)
  #define PA7                     PIN_A12 // RMII RX Data Valid - SB31 ON (default)
  #define PA8                     86
  #define PA9                     87
  #define PA10                    88
  #define PA11                    89
  #define PA12                    90
  #define PA13                    91
  #define PA14                    92
  #define PB14                    93  // LD3 LED_RED
  #define PC1                     PIN_A13
  #define PC4                     PIN_A14 // RMII RXD0 - SB36 ON (default)
  #define PC5                     PIN_A15 // RMII RXD1 - SB29 ON (default)
  #define PC13                    97
  #define PC14                    98
  #define PC15                    99  // USER_BTN
  #define PD8                     100
  #define PD9                     101
  #define PD10                    102 // Serial Tx
  #define PE1                     103 // Serial Rx
  #define PF12                    PIN_A16
  #define PF13                    PIN_A17 // LD2 LED_BLUE
  #define PF14                    PIN_A18
  #define PF15                    107
  #define PG4                     108
  #define PG5                     109
  #define PG7                     110
  #define PG8                     111
  #define PG9                     112
  #define PG10                    113
  #define PG11                    114 // RMII TX Enable - SB27 ON (default)
  #define PG13                    115 // RXII TXD0 - SB30 ON (default)
  #define PG15                    116
  #define PH0                     117
  #define PH1                     118
#else /* ARDUINO_NUCLEO_H743ZI */
  #define PG9                     0   // USART_A_RX
  #define PG14                    1   // USART_A_TX
  #define PF15                    2
  #define PE13                    3   // TIMER_A_PWM3
  #define PF14                    PIN_A16
  #define PE11                    5   // TIMER_A_PWM2
  #define PE9                     6   // TIMER_A_PWM1
  #define PF13                    PIN_A17
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

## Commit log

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2026-07-09 fix(review): apply code-review findings
    - platform.txt: ship the ctags shim inside the platform ({runtime.platform.path}/tools-bin)
    instead of a hardcoded /root path (flagged by 3 reviewers)
    - boards.txt: drop --specs=nano.specs to match PJRC's full-newlib link
    (silent fidelity gap vs real Teensyduino builds)
    - compile.sh: install the tracked platform files + shim into the sketchbook
    before every build, so the committed files are what the build exercises
    - README: add the profile-mismatch row to the troubleshooting table; correct
    backlight duty (128 = 100%, not ~50%) and sweep period (~2.2 s)
    - MustangDash.ino: fix the same two comment inaccuracies
    - BUILD.md: reproduce block now nam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
    [MustangDash.ino]
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2026-07-10 Steady backlight, 10 kHz PWM, and the galloping pony logo
    Replace the first-light demo with the dash face: a stylized galloping pony
    silhouette (480x300 PNG embedded in flash, decoded on-chip by the BT817's
    CMD_LOADIMAGE into RAM_G as tintable ARGB4), a red/white/blue tri-bar
    accent drawn with EVE_RECTS, and the MUSTANG wordmark in ROM font 31.
    Backlight is now steady at 100% (pulse demo removed; loop() is empty) and
    the PWM frequency rises 4 kHz -> 10 kHz: the library profile's 4 kHz
    default was audible as a driver whine on this bench, and the panel's own
    datasheet recommends 10-100 kHz (REG_PWM_HZ caps at 10000). The invariant
    test now pins 10 kHz.
    tools/pony.py is the logo source: a ske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
    [MustangDash.ino]
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2026-07-10 feat(splash): animated boot splash, crossfade to pony screen, instant-on boot (U4+U5)
    Plays the 2000 ms Claude Design splash on power-up: half-res background
    scaled 2x bilinear (BITMAP_SIZE_H/_LAYOUT_H for the >511 px window),
    bars/blocks slide in, emblem pops in an overshoot-safe 220 px window,
    wordmark+year rise, accent line sweeps open behind a scissor, checkered
    theme adds edge strips. Then a 400 ms COLOR_A crossfade into the
    unchanged pony screen. Backlight stays dark until the first splash frame
    is swapped in, so the decode window never flashes a lit blank panel.
    All three themes ship in flash via a descriptor table indexed through a
    volatile theme id (defeats dead-code elimination; d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
    [MustangDash.ino]
2026-07-10 refactor(splash): apply simplification-review findings
    - unify bar/word pixel rounding in one half-away-from-zero helper
    (removes the silent negative-x asymmetry between the two bar helpers)
    - deduplicate the DLSTART/CLEAR ... DISPLAY/SWAP frame bracket into
    eve_frame_begin()/eve_frame_end() (three call sites)
    - drop the redundant theme_is_checkered bool copy; use min() for the
    timeline clamps; use real fabsf() in the host test
    - pin the six spec layout constants with cross-consistency static
    asserts (emblem pivot and both accent-line centerings on x=512)
    - read each asset PNG once in the converter (was open + re-read)
    Behavior preserved: 5/5 host tests, converter output byte-identi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
    [MustangDash.ino]
2026-07-10 fix(review): apply code-review findings
    - gate the checkered bottom strip wraparound copy on starting on-screen:
    past EVE_HSIZE the x*16 value overflows VERTEX2F 15-bit signed field
    and painted the strip on the left mid-slide, defeating the spec
    slide-in (adversarial finding, validator-confirmed arithmetic)
    - pin the SPLASH_THEME_* value <-> THEMES[] row-order coupling with a
    compile-time static_assert at the coupling site (testing finding)
    - honest boot comments: a no-host boot exits the enumeration window at
    its 500 ms timeout, not immediately (correctness finding)
    - label the RAM_G headroom comment as the checkered worst case
    (~160 KiB; blue/red leave ~197 KiB) (maintainabilit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
    [MustangDash.ino]
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2026-07-10 fix(review): apply code-review and simplification findings
    P0 font metric blocks declared EVE_L2 (17) while glyph data is L4-packed;
    EVE_L4 is 2 (EVE.h:190). Converter fixed, headers regenerated, test now
    pins 2 with the library constant cited. Serial-only bench verification
    masked this - visual check on the panel required.
    P1 odometer EEPROM record -> two-slot ping-pong with sequence counter
    (v2, 19 bytes); a torn write now costs 0.1 mi, never the lifetime count
    (validator-confirmed per-byte non-atomic emulation writes).
    P2 flash provisioning writes the header-bearing chunk LAST so a power-cut
    run fails verification and re-provisions instead of passing forever.
    P2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
    [MustangDash.ino, dash_math.h]
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2026-07-10 fix(review): end DA macro scope at dash_render.h; note render headers in CLAUDE.md
    [dash_render.h]
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2026-07-10 fix(review): bounded frame drain (R9), sign-safe rounding, dark-boot PWM, mask UB guard
    Multi-agent review of the side-panels branch (9 reviewers + independent
    validators); all six validated findings fixed:
    - P0: eve_frame_end()'s EVE_busy() wait is now bounded (250 ms vs a
    <17 ms healthy drain); on timeout the panel is retired via g_panel_ok
    so a panel dying after boot degrades to dark per R9 instead of
    freezing all three panels, the serial pump, and odometer writes
    (flagged independently by the reliability and adversarial reviewers)
    - P1: draw_round_rect(x,y,w,h,r) hoisted into dash_draw.h; draw_pill is
    its r=h/2 special case and engine_round_rect is deleted
    - P2: dash_fmt_value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
    [MustangDash.ino, dash_math.h]
2026-07-10 fix(spi): run clock to bench-verified 8 MHz - 24 MHz fails signal integrity
    First hardware run of the branch (center panel only, sides unwired).
    At DASH_SPI_RUN_HZ = 24 MHz the bus fails both directions on this bench
    wiring: EVE_init_flash() returned 0x01 (splash skipped), all 9 font
    inflates failed GETPTR verification twice (ROM font 31 fallback), the
    panel showed solid white, and corrupted REG_CMDB_SPACE reads dragged
    fps to 25 with faults=0 -- the corruption never matched the fault
    signature, so nothing tripped.
    At 8 MHz the same firmware is fully healthy: flash E_OK + CRC-current
    assets, splash 110 frames / 2000 ms, fonts clean, DL 409/648, 60 fps,
    zero faults, odometer persisted across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
    [MustangDash.ino]
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2026-07-11 feat(diag): per-panel retirement counters + honest fps in status
    Two observability gaps found the hard way during today's bench
    diagnosis (a retired panel reported a frozen fps=60 for minutes,
    masking every failure):
    - g_eve_retired[panel]: counts bounded-drain timeouts that retired a
    panel at runtime; surfaced in the status ack as retired=c,l,r next
    to faults. A wedge with faults=0 and a wedge with a fault storm are
    different diseases -- the counters now distinguish them.
    - fps decays to 0 when nothing renders: the fps window keeps rolling
    when every panel is dead instead of latching the last healthy
    second. frames only count when a panel actually rendered.
    These counters carrie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
    [MustangDash.ino]
2026-07-11 feat(diag): live center-panel register probe in status (creg=id,pclk,pwm)
    Reads REG_ID / REG_PCLK / REG_PWM_DUTY off the center panel on every
    status ack, bypassing the liveness gate so a retired panel can still be
    interrogated: a post-reset BT817 shows pclk=0 + pwm=32 with id still
    0x7C, distinguishing "chip reset itself" (power/PD event) from "wedged
    with config intact" (coprocessor stall). Built for the 2026-07-10 bench
    forensics; cheap enough to keep.
    [MustangDash.ino]
2026-07-11 fix(splash): render from RAM_G-staged assets, not flash streaming
    The center module's flash render-streaming path is damaged (2026-07-10
    bench forensics: long ASTC 4x4 bursts garble while command-path reads
    stay byte-perfect -- emblem/wordmark/strip invisible, backgrounds fine).
    The splash now stages the active theme's assets flash->RAM_G once at
    boot via CMD_FLASHREAD (the healthy path) and renders from RAM_G, with
    a 16-byte spot-check per asset against the embedded pack and a per-
    asset flash-source fallback if staging cannot run.
    Budget (bench-verified): fonts 284,752 B + one theme 280,432 B staged
    to top 565,184 -- 483 KB RAM_G headroom. Splash 122 frames / 2000 ms,
    boot unchanged at ~3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
    [MustangDash.ino, splash_render.h]
2026-07-11 feat(sim): lap-synced driving cycle with hysteretic gearbox
    TRACK mode no longer ramps to a pegged 204 mph / 6200 rpm cruise: the
    sim now drives a 10-segment circuit keyed off lap position (straights,
    brake zones, corners), chasing each segment's target speed with power-
    limited acceleration and race braking. The gearbox follows wheel speed
    with hysteresis (up over 7400, down when a lower gear lands under
    6900), and rpm always derives from speed THROUGH the current gear --
    so ~100 mph reads ~3900 rpm in 5th on the back straight and ~6300 rpm
    in 3rd out of the chute. Throttle/brake channels come straight from
    the chase state (full throttle on straights, 80-90% brake into
    corners). Per-visit t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
    [dash_sim.h]
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2026-07-21 docs(solutions): flash render-streaming is bandwidth-bound, not a bad module
    The 2026-07-10 splash change (1cd6255) moved from flash-direct rendering to
    flash->RAM_G staging, and attributed the failure to one center module whose
    render-streaming path was damaged. That framing was wrong: it is a per-frame
    bandwidth ceiling every module has.
    Established 2026-07-20/21 through EVE Screen Editor over the Riverdi eval
    board's FTDI bridge -- a toolchain independent of the Teensy firmware:
    - 7" RVT70H, REG_FLASH_STATUS=3 (FULL), REG_FLASH_SIZE=64: the full-screen
    1024x600 ASTC 8x8 background (153,600 B/frame) tears from flash.
    CMD_FLASHFAST does not help; the controller is already at full spee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
    [splash_render.h]
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2026-07-21 feat(stm32): U4 - h743 build env + portable storage seam + STM32 multi-panel mirror
    pio env:h743 (WeAct MiniSTM32H743VITX board def = the same STM32H743VIT6 as
    the planned carrier, so the $15 devkit doubles as a firmware mule). Builds
    clean at 773,792 B flash of 2 MB -- empirically pinning KTD1's 2 MB floor.
    - MustangDash.ino: avr/eeprom + usb_configuration gated to Teensy; odometer
    glue now calls odo_storage_read/write -- a seam with unique names because
    both .ino->cpp converters hoist generated prototypes above target guards
    (redefining the avr names collided on Teensy). STM32 branch is a RAM
    shadow placeholder until U6's FRAM backend.
    - splash_render.h: min() call sites cast to u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
    [MustangDash.ino, splash_render.h]
2026-07-21 feat(stm32): U5 - per-panel dedicated SPI via bus-carrying panel descriptors
    Each DashPanelDesc gains bus_index (0/1/2 by role, host-tested distinct);
    the STM32 EVE_panel_t carries the SPIClass* itself (void* for the C side)
    under a new EVE_PANEL_HAS_BUS marker. EVE_cpp_wrapper and the STM32 buffer
    transfer resolve the selected panel's bus with the global SPI as fallback,
    so single-panel and Teensy behavior are untouched -- Teensy's shared-bus
    descriptor has no bus field and compiles the identity path.
    .ino glue: SPI2/SPI4 instances on WeAct-mule-valid LQFP-100 pins (final
    pins belong to the U2 schematic), per-bus init at 8 MHz and independent
    run-clock raise -- point-to-point links make pe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
    [MustangDash.ino, test_dash_panels.c]
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2026-07-21 feat(stm32): U7 - dual FDCAN bring-up to loopback with cantest command
    Raw STM32duino HAL (HAL_FDCAN_MODULE_ENABLED), no external CAN library:
    both peripherals classic CAN 2.0 at 500 kbps (prescaler 10, 16 tq/bit,
    ~87.5% sample point, assuming the 80 MHz kernel clock -- U8 bench verifies
    the measured bit rate and corrects if the RCC tree differs). Non-overlapping
    message RAM slices, accept-all filters to FIFO0.
    cantest: one frame bus 1 -> bus 2 with the buses wire-jumpered; proves
    silicon, both transceivers, connectors, and termination in one serial
    command. Bounded 100 ms poll -- a silent bus acks err, never hangs. Init is
    logged, never fatal: the dash must not depend on CAN, mirroring the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
    [MustangDash.ino]
2026-07-21 fix(review): STM32 pin collisions, FRAM fault paths, float printf, cantest hardening
    Multi-agent review findings applied (8 reviewers, run 20260721-133532):
    - P0: STM32 CS/PD remap -- dash_panels.h's raw Teensy numbers landed on
    USB DP, the telltale port, and uSD pins on the H743 variant; the roles
    now remap to PD8-PD13 under EVE_PANEL_HAS_BUS (descriptor stays
    host-pure, banner prints effective pins). Center panel gets an explicit
    SPI1 instance -- the variant's default SPI object IS SPI2, silently
    sharing the left panel's bus.
    - P0: a transient FRAM short-read zero-started the odometer and then let
    cadence writes clobber both surviving slots; reads now memset first,
    verify th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
    [MustangDash.ino]
2026-07-21 feat(stm32): riverdi_f469 env - dash firmware on the Riverdi eval board's own STM32
    The Riverdi STM32 Evaluation Board carries an STM32F469II wired to its one
    RiBUS connector; with jumpers P9-P8 the panel belongs to that MCU. This env
    runs the full dash firmware on it -- the first hardware where the splash
    can actually animate, months before the custom carrier exists.
    - boards/riverdi_f469.json: custom manifest (PlatformIO's disco_f469ni
    doesn't list arduino support; the generic F469II variant does). Vendored
    variant folder boards/variants/F469II_RIVERDI with a named shim header
    (the builder force-includes variant_<BOARD>.h) and the size-templated
    STM32duino ldscript (the F469I vari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
    [MustangDash.ino]
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2026-07-21 feat(stm32): nucleo_f767 env - three-panel mule on the NUCLEO-F767ZI
    Kevin already owns this board; it turns out to be the best rehearsal
    hardware available: Cortex-M7 like the H743 target, 2 MB flash, six SPI
    peripherals, and an onboard ST-LINK that also programs the Riverdi eval
    board (CN4 jumpers off, SWD to P10).
    Three dedicated buses on pins clear of the Nucleo's fixed functions --
    Ethernet RMII steals SPI1's default MOSI (PA7) and SPI2's default SCK
    (PB13), hence SPI1 MOSI=PB5, SPI2 SCK=PB10/MISO=PC2. Serial rides the
    ST-LINK VCP (USART3), so no USB CDC flags. bxCAN not FDCAN -> dash_can.h
    stubs; FRAM on Wire (PB8/PB9) when a breakout is attached. Panels connect
    via FFC/ZIF breakouts;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
    [MustangDash.ino]
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2026-07-22 feat(splash): MCU-direct RAM_G staging; delete EVE-flash provisioning; guarded flashwipe
    Splash assets now stage from the firmware-embedded pack straight into
    RAM_G at boot (bulk SPI writes + 16-byte readback spot-check per asset;
    a failed check skips the asset -- no fallback). Deleted: provisioning,
    pack-header/CRC verification, the flash-source render arm, RAM_G scratch
    constants, and the boot-time EVE_init_flash() probe. Boot never touches
    the panel's QSPI flash; pack format and layout tests unchanged.
    New guarded serial command 'flashwipe really' full-chip-erases the
    center panel's retired flash (obsolete ESE image, sector 0 included);
    bare verb or wrong argument errs without erasing. H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
    [MustangDash.ino, splash_render.h]
2026-07-22 feat(f767): drive first three telltales on Nucleo onboard LEDs (temporary)
    Bench-visibility aid: lamps 0-2 map to LD1/LD2/LD3 (PB0/PB7/PB14) on the
    NUCLEO-F767ZI build only, so the boot lamp-test and live alarm states show
    on the board before external telltale hardware exists. Trip switch rides
    the blue USER button (PC13). Marked temporary; revert when real lamps land.
    [MustangDash.ino]
2026-07-22 fix(review): emblem skip guard, flashwipe fault-checked ack, doc drift
    Applies the /ce-code-review findings on the MCU-direct splash commits:
    draw_splash_emblem now honors the unstaged-asset skip (address 0 is font
    data, not a drawable); flashwipe clears the coprocessor fault latch before
    the erase and acks err instead of ok when a fault silently aborted it;
    stale provisioning-era comments rewritten (.ino header, splash_render.h
    banner and crossfade notes); the flashwipe warning line is documented as
    the serial contract's one exception (CLAUDE.md + /dash skill, which also
    gains the flashwipe row); help-text test now pins the flashwipe verb.
    Host suite 13/13; teensy41 + nucleo_f767 build clea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
    [MustangDash.ino, splash_render.h]
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2026-07-22 fix(f767): USER button B1 is active-HIGH - per-board trip-switch polarity
    Review finding on the LED commits: the Nucleo-144's B1 connects PC13 to
    VDD when pressed with an external board pull-down, so the inherited
    active-LOW + INPUT_PULLUP logic could never register a press and parked
    the idle pin at an indeterminate level. Per-board DASH_SWITCH_TRIP_PINMODE
    and DASH_SWITCH_TRIP_PRESSED now carry the electrical contract; Teensy and
    WeAct keep active-LOW pull-up unchanged.
    [MustangDash.ino]
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2026-07-22 feat(dash): black carbon base layer under STREET mode (bench-approved)
    New bg_street pack asset (8x8 ASTC, 150 KB -- gauge-covered, weave hides
    blocks) staged to RAM_G with the theme and drawn as the STREET frame's
    base layer; TRACK keeps the flat COLOR_BG. RAM_G peak ~840 KB of 1 MiB.
    Bench-found bug fixed en route: CMD_SETBITMAP configures the CURRENTLY
    SELECTED bitmap handle, and issuing it right after font registration
    hijacked the last font's handle -- every glyph on that font rendered as
    scrambled ASTC blocks. The base layer now draws on scratch handle 15 and
    restores handle 0.
    [dash_render.h, splash_render.h]
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2026-07-22 fix(review): address PR #6 automated review findings
    - odo_storage_write: a failed FRAM write now lands the record in the RAM
    shadow and logs, instead of silently dropping it while flipping the
    backend (undercut the trip-reset persistence guarantee)
    - pump_serial: trim trailing CR/blanks before dispatch so CRLF terminals
    reach the raw whole-line commands (cantest); parser-side commands
    already tolerated the \r
    - SPI raise banner: print the requested clock as %.2f MHz (13500000 no
    longer truncates to "13 MHz") and note the prescaler rounds down
    - splash_render.h + CLAUDE.md: refresh stale RAM_G/flash numbers for the
    4x4 blue/red era (theme ~741 KB, peak ~1,026 KB, F767 image 1.81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
    [MustangDash.ino, splash_render.h]
2026-07-22 feat(sim): distance-based HPR lap with physical acceleration model
    U1: lap position integrates road speed; lap closes on SIM_TRACK_LAP_FT
    (13464) rather than a fixed 62 s clock. lap_ms becomes a pure timer.
    Lap 1 is the out-lap: it populates last_ms but is excluded from best_ms.
    U2: traction/power/drag model replaces the linear accel-fade chase.
    511 whp measured in Denver, 2900 lb, 1.05 g traction. Tire corrected
    26.0 -> 25.44 in for 315/30R18.
    U3: 16-segment distance-keyed HPR table with lookahead braking. Corner
    limits constrain the segment entry boundary; is_corner_limit flags
    segments 0 and 9 as non-limits for U4. Gear selection is emergent.
    Corner jitter moved from per-visit to per-l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
    [dash_sim.h]
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2026-07-22 feat(sim): per-corner turn angles and driver skill calibration (U4)
    Best lap 1:46.45 -> 2:01.60 at SIM_DRIVER_SKILL = 0.86, inside the
    plan's 0.82-0.95 guardrail and in the 2:00-2:05 window.
    U4 assumed driver skill was the only knob tuned against lap time. It
    was not. Two upstream problems dominated it:
    1. Arc radius was derived from the driver's *scaled* speed, so lowering
    skill shrank the corner -- arc goes as v^2, arc time as v, and the
    corner literally got shorter as the driver got slower. Radius now
    comes from the authored limit, unscaled and unjittered, so a slower
    driver spends longer in the same fixed length of tarmac.
    2. U10's single circuit-wide 90 deg arc treated a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
    [dash_sim.h]
2026-07-22 feat(button): short press swaps mode, long press resets trip (U11)
    The Nucleo USER button B1 (PC13) was already the trip-reset switch.
    Rather than displace it, the two actions split by gesture: short press
    (<1 s, fires on release) toggles TRACK/STREET; hold >=1 s resets the
    trip. The frequent bench action gets the cheap gesture, and zeroing the
    trip odometer now takes a deliberate hold.
    Gesture logic extracted to dash_button.h as a pure header per the repo
    convention, so the timing is host-testable without hardware -- which
    matters because bench verification is Kevin's to initiate, not ours.
    The 30 ms debounce survives verbatim, including its rationale: a single
    EMI glitch on a car harness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
    [MustangDash.ino]
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2026-07-22 feat(sim): range-sweep fixture and dead-front on mode switch (U7)
    'circuit hpr|sweep' selects the fixture -- a sibling of 'mode', not of
    'sim': both name which of two behaviors is running, where 'sim on|off'
    only says whether the simulator runs at all. Folding it into 'sim'
    would make 'sim off' then 'sim sweep' ambiguous about freezing.
    SWEEP ramps 0 -> 200 -> 0 mph at 4 mph/s. The binding constraint is the
    top of the dial: 6th engages at ~188 mph and owns only 12 mph of ramp.
    Measured dwell is 10-27 s per gear, all six readable on the bench.
    rpm still derives from speed through the real gearbox, so the fixture
    exercises the drivetrain math rather than a parallel path.
    Also fixes a pre-exi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
    [MustangDash.ino, dash_sim.h]
2026-07-22 feat(sim): 20-minute session cycle, split thermal model, real fuel burn (U8, U9)
    U8: coolant and oil shared one 90 s tau, so both pinned within five
    minutes of boot and never moved again -- the temp gauges were dead for
    15 of every 20 bench minutes. Split to 120 s (thermostat-governed,
    settles by minute 10) and 600 s (no thermostat, far more mass). Oil
    moves +35.7 F between minutes 10 and 15 where coolant moves 0.8, and
    crosses above coolant around minute 16.
    Sessions run 20 minutes and end on the first lap completion at or after
    the mark -- never mid-lap, since a mid-lap reset would snap the car out
    of a corner. best_ms and last_ms reset with the session: zeroing
    lap_count alone would let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
    [dash_math.h, dash_sim.h]
2026-07-22 feat(sim): SWEEP reaches redline; realistic track oil temperature
    SWEEP: the tach could never enter its red zone in any mode. The
    gearbox upshifts at 7400 and rpm clamps at 7600, so published rpm
    peaked at 7399.4 -- but red needs >7600 and the 15th shift LED needs
    8000. R12 says the fixture exists to exercise redline and the shift
    ladder; neither was reachable. SWEEP now holds a gear to 8000, the
    same class of exemption KTD7 already grants it from the corner table.
    Ladder 13/15 -> 15/15, red zone lit 5.7 s per cycle. The driving model
    is untouched: TRACK verified bit-identical over 25 sim-minutes, every
    lap landing on the same step, IEEE-754 hex equal.
    Oil: the target was capped at 208 F no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
    [dash_math.h, dash_sim.h]
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2026-07-22 fix(review): session dead-front, tainted laps, fuel refill, unfailable tests
    Applied verified findings from a five-reviewer code review.
    Session rollover left the previous session's LAST/BEST/PRED valid on
    screen through the whole new out-lap. dash_ch_set is one-way and
    dash_sim_session_reset only zeroed the lap book, so the channels never
    dropped. dash_sim_dead_front_lap existed for exactly this -- its
    comment cites 'a live best-lap time from a session that ended minutes
    ago' -- but was only reachable on the STREET/SWEEP path.
    A lap driven under a forced SPEED was adopted as BEST and as the DELTA
    reference. Measured: 'set speed 200' produced a 45900 ms lap against an
    honest 121600, and th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
    [dash_sim.h]
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
